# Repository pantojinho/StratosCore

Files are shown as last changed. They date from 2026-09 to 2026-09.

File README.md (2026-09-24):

# StratosCore

StratosCore is an open-source portable field, aviation, meteorological, navigation and radio computer based on the **ESP32-S3-WROOM-1-N16R8**.

## Current status

**Astra has assumed full technical leadership of Rev A (2026-09-24).** Astra owns engineering closure, candidate refinement, review and integration; Claude, Hermes, Sol and other AI agents execute bounded delegated tasks. See [Astra project control and agent handover](docs/ASTRA_PROJECT_CONTROL.md) for current responsibilities, received evidence and next actions. Final baseline implementation and manufacturing remain gated.

| Complete | In progress | Externally blocked |
| --- | --- | --- |
| Product baseline and licensing | Validate prepared three-line display support and GNSS passive RF proposals | Display controlled power/FPC drawing, C1 samples and connector confirmation |
| MAX-M10S decision and independently reviewed footprint geometry | Close complete 2S charger/protection/VBUS application | Qualified electrical/battery review and fault tests |
| Two removable 21700 cells in 2S decision | Accept exact cells/holder and state estimation; prove the 8 h primary-use target | RF performance and runtime measurements need prototypes |
| ESP32 compute sheet and GPIO allocation | Sensor CAD, LoRa/ADS-B RF, stackup and mechanical dummy | Final factory stack confirmation |
| Exact candidates for RP2040 support, microSD, audio, USB-C, expansion, buttons, rails and RF interconnects | Assembler approvals, mechanical fit, off-state review and application tests | Independent final schematic/layout and bring-up review |
| Manufacturer-derived dimensions for W25Q, TPD, ICM/MMC/BMP, ABM8, U.FL and DM3 electrical/mechanical envelope | RF return paths, enclosure access and prototype qualification | PCBA assembler stencil/mask confirmation |
| KiCad hierarchy; latest ERC: zero violations | Orderable BOM and manufacturing inputs | |
| ADS-B host models: 24 tests passing | UART/PIO/DMA implementation and sustained-link bench proof | |

The **reviewed baseline** (`hardware/`) has no finished schematic, PCB layout, prototype or manufacturing package yet. A complete **comparison candidate** (schematic + routed PCB + 3D with the display) now exists in [`candidates/claude-oneshot-revA/`](candidates/claude-oneshot-revA/README.md) — see [below](#claude-one-shot-candidate-schematic--pcb--3d). It is **not for manufacture** and does not close any gate. Do not order boards from the current repository. See [project status](docs/PROJECT_STATUS.md) for the complete gate list.

## Claude one-shot candidate (schematic + PCB + 3D)

Generated 2026-09-23 at the owner's request, for side-by-side comparison with the Astra pass. Status at a glance:

| Item | Status |
| --- | --- |
| Schematic | Complete: root + 11 sheets, every Rev A block; unverified values are literally `TBD` |
| PCB | 60 x 84 mm, 4 layers, 277 parts, routed; **11 connections left for manual finish** (2 LoRa RF stubs, SHT40 SDA/3V3, 1 decoupling cap, 6 GND pour fragments) |
| Checks (KiCad 10.0.6) | ERC 1 reviewed error; DRC 1 reviewed error (ESP32 antenna-clearance courtyard); schematic <-> PCB parity 0 |
| 3D | Board with display, 2S 21700 cells and holder; printed two-part enclosure concept |
| Blocking gates | O05 battery safety (qualified human review), display controlled drawing/samples, LoRa matching values, ADS-B threshold, assembler approvals |
| Findings for the baseline | 2 footprint blockers (MMC5983MA, BMP581 pad centres), 2 wrong packages (TXU0202, TPS259474L), connector orientation and GPIO gaps — see [ISSUES.md](candidates/claude-oneshot-revA/docs/ISSUES.md) |

| Front (display) | Back (2S 21700 cells) | Printed enclosure concept |
| --- | --- | --- |
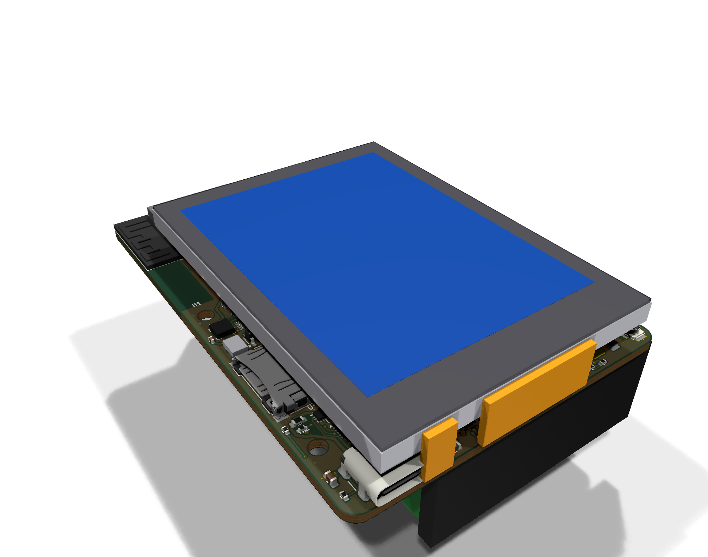
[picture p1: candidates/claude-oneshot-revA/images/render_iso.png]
3D front
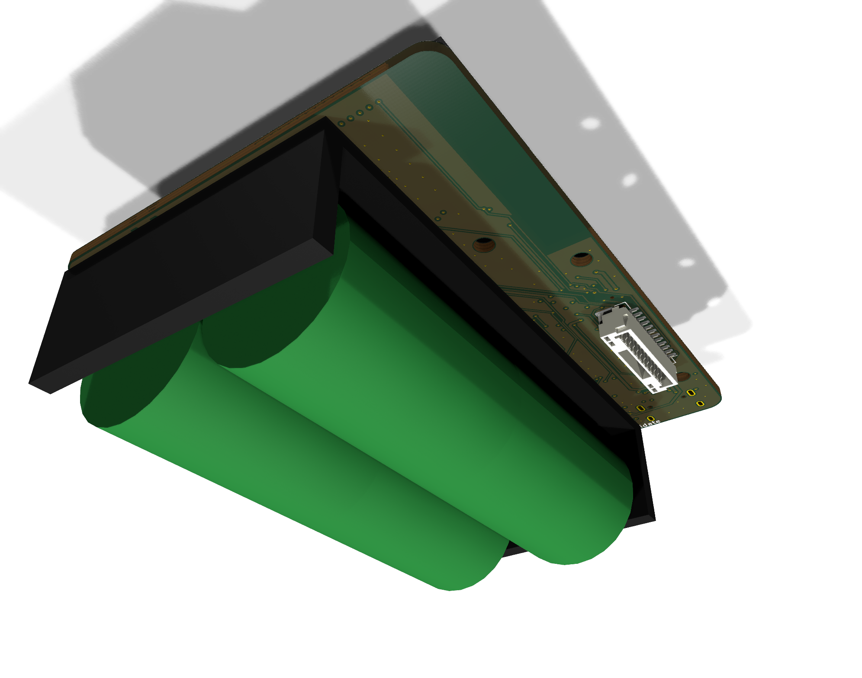
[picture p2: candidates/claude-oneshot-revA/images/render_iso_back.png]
3D back
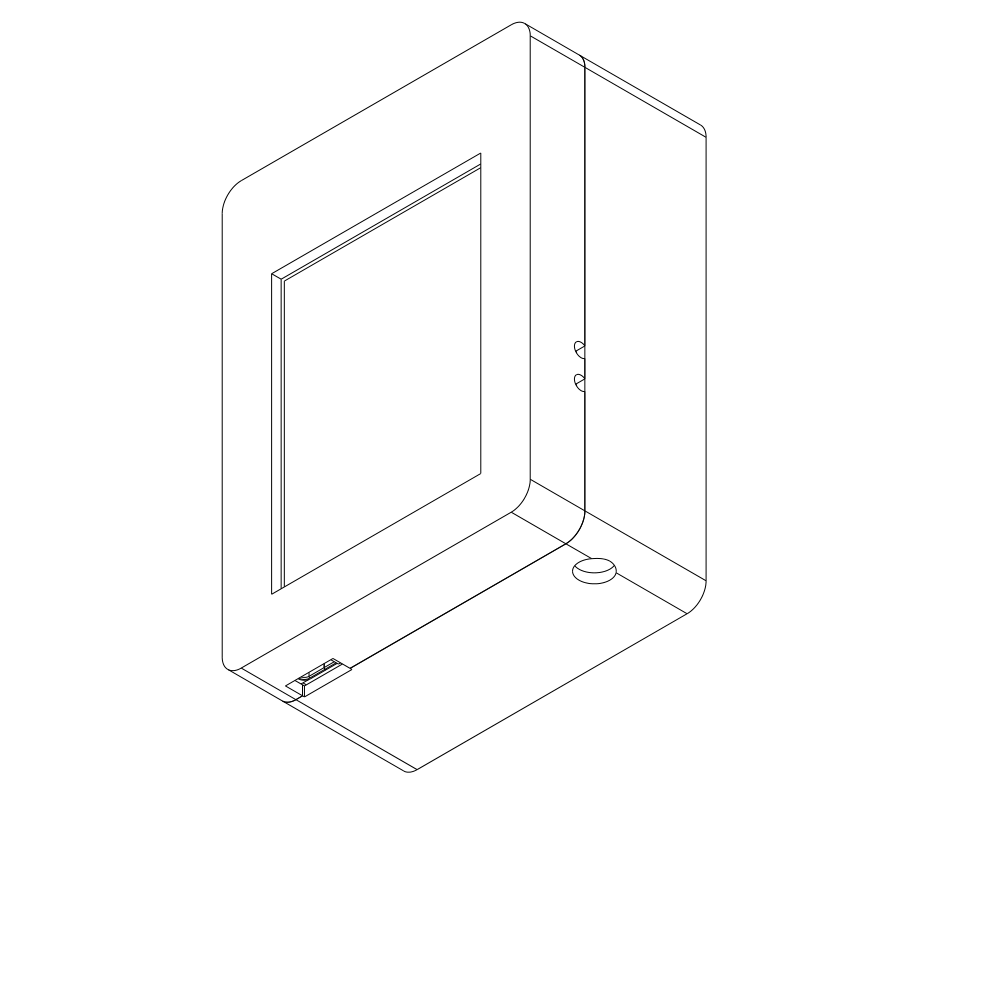
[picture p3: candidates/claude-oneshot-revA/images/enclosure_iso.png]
Enclosure
|  |  |  |

| PCB top (display removed) | PCB bottom | Copper (F/In2/B) |
| --- | --- | --- |
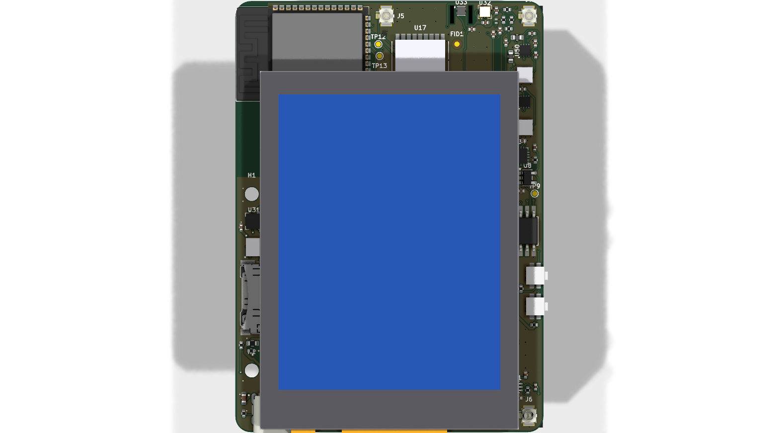
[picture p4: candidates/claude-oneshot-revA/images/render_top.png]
Top
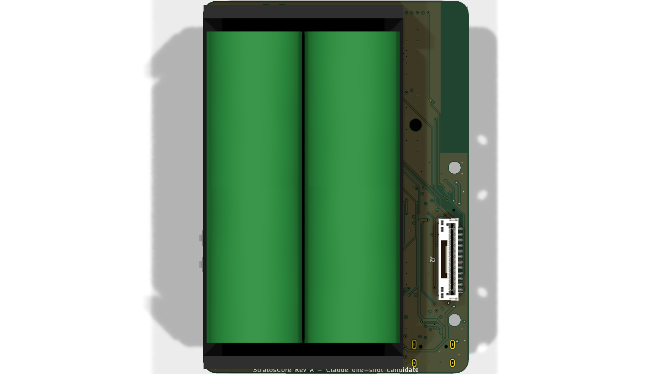
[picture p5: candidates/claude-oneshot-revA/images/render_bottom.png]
Bottom
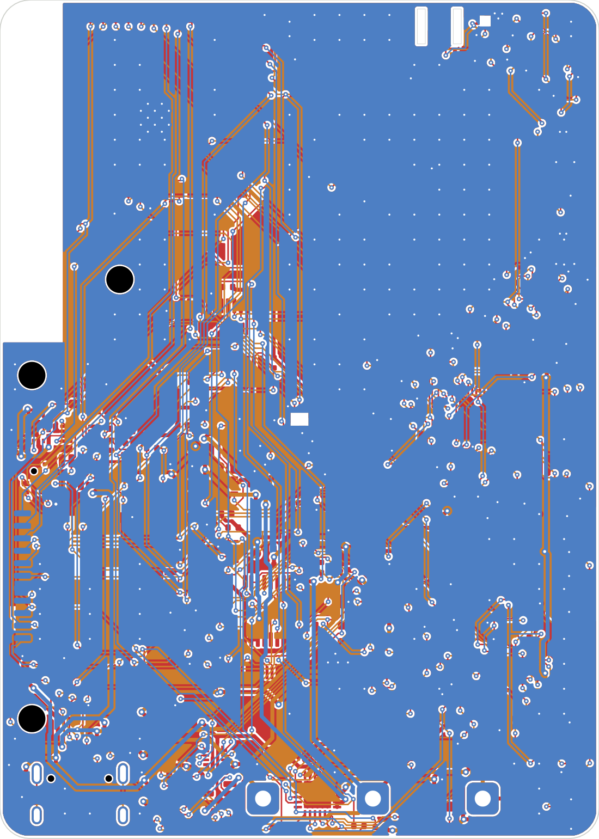
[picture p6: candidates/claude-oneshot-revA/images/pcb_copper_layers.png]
Copper
|  |  |  |

Schematic sheets (click to enlarge; full vector PDF: [schematic.pdf](candidates/claude-oneshot-revA/docs/schematic.pdf)):

| | | |
| --- | --- | --- |
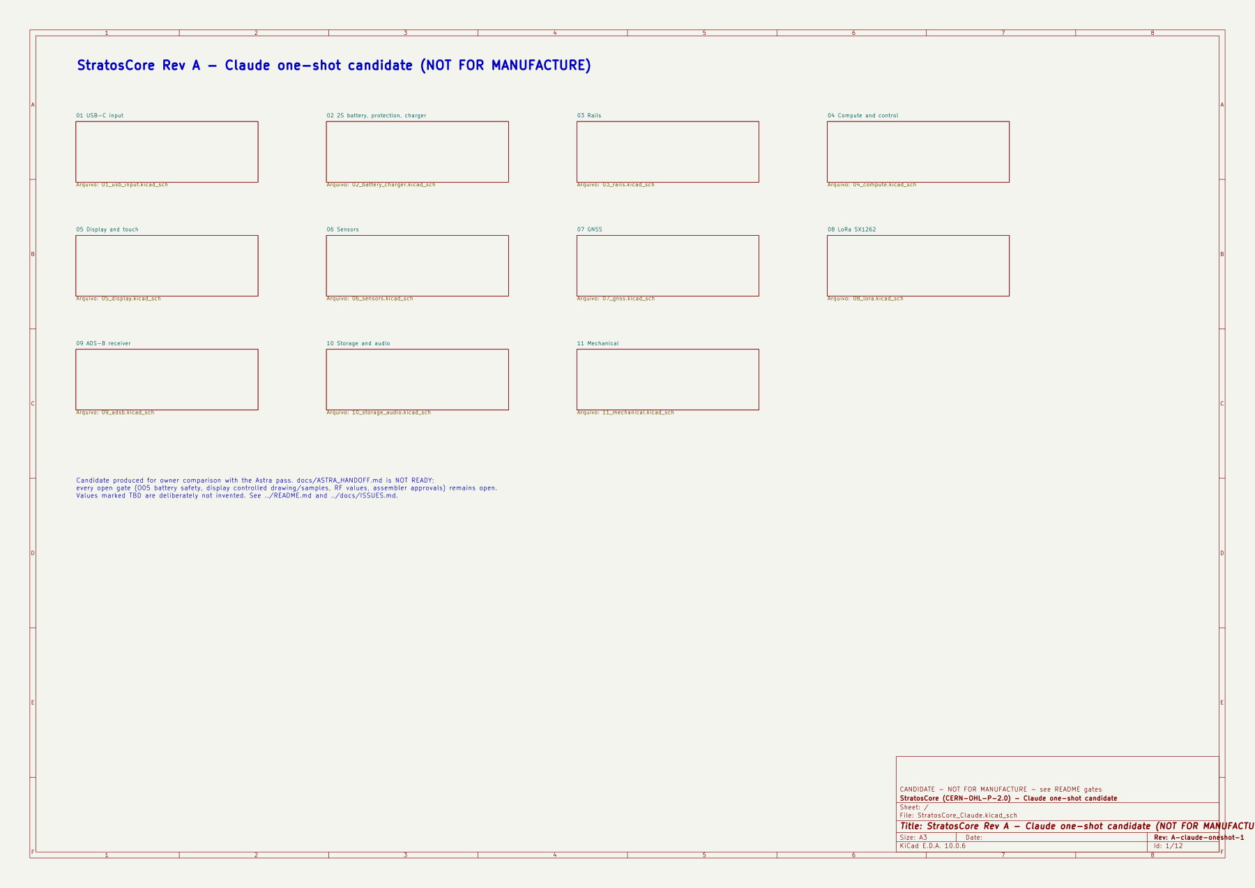
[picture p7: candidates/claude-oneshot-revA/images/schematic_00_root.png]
Root
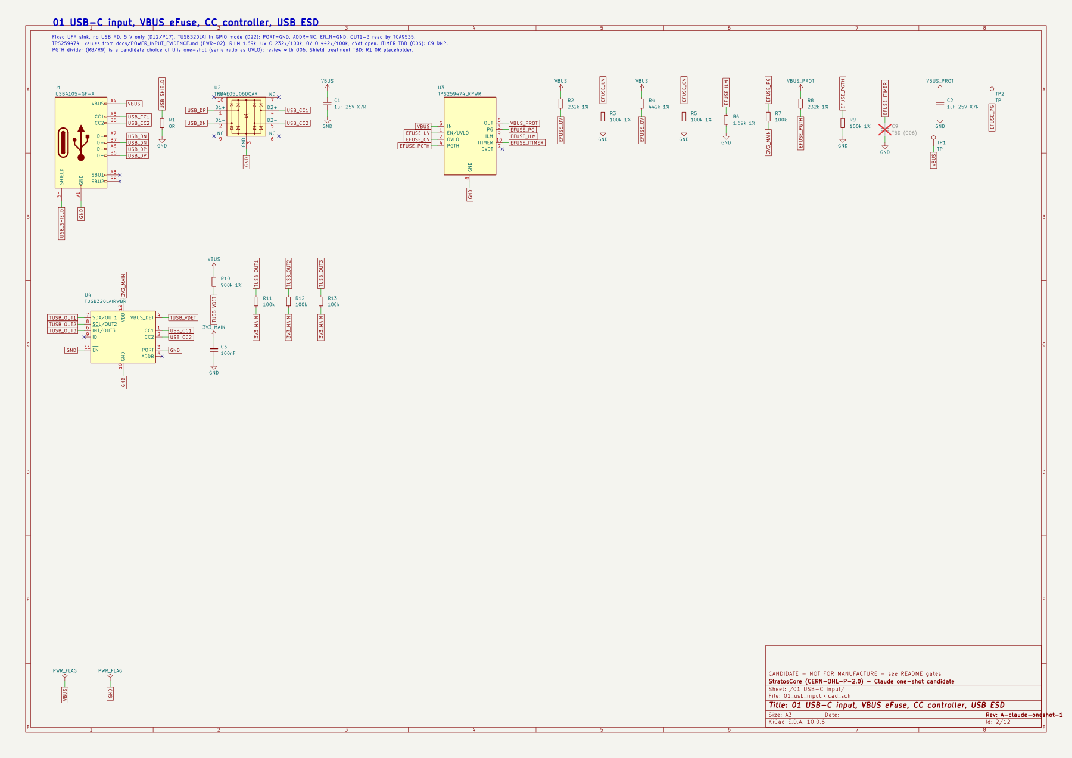
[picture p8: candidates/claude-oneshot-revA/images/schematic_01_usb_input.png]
USB-C
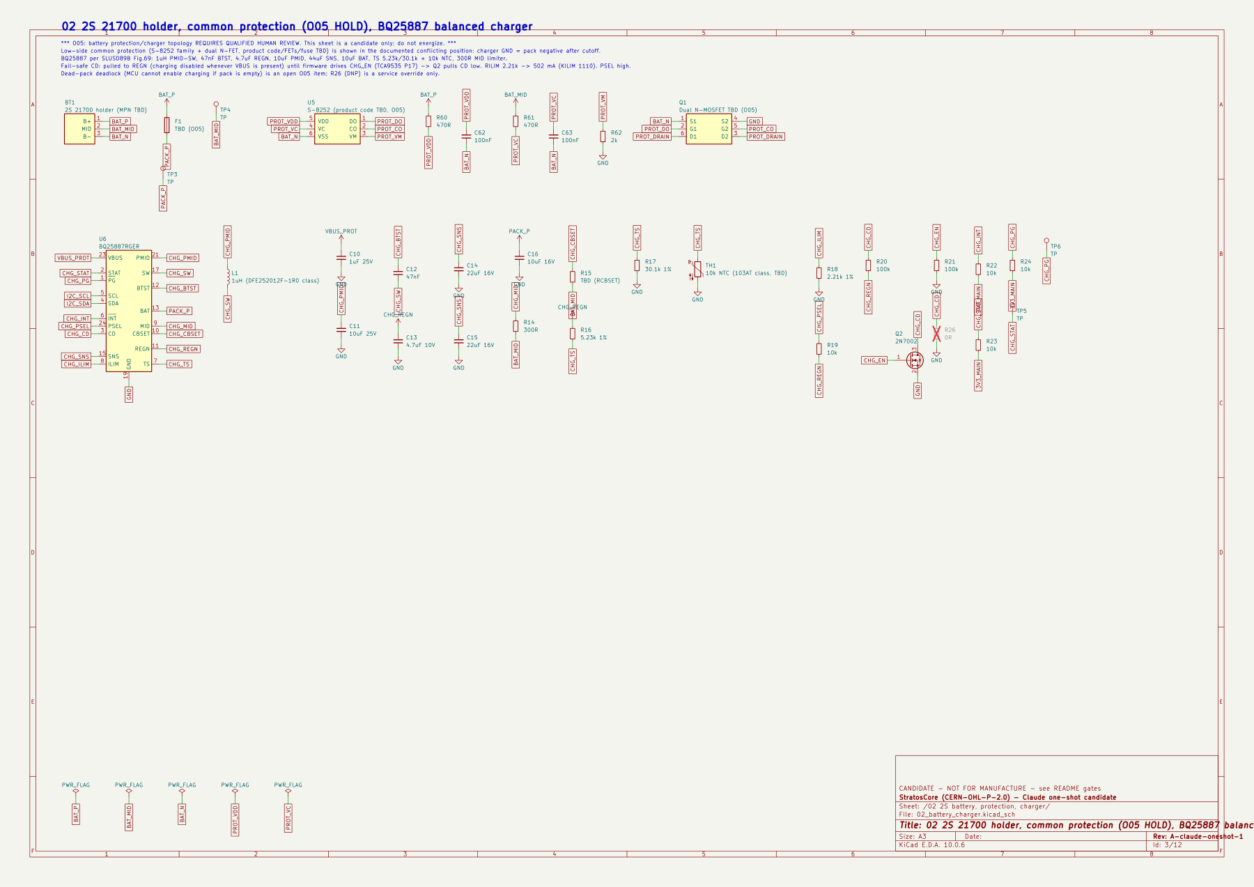
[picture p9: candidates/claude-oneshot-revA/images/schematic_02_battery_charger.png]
Battery
|  Root |  01 USB-C input |  02 2S battery/charger |
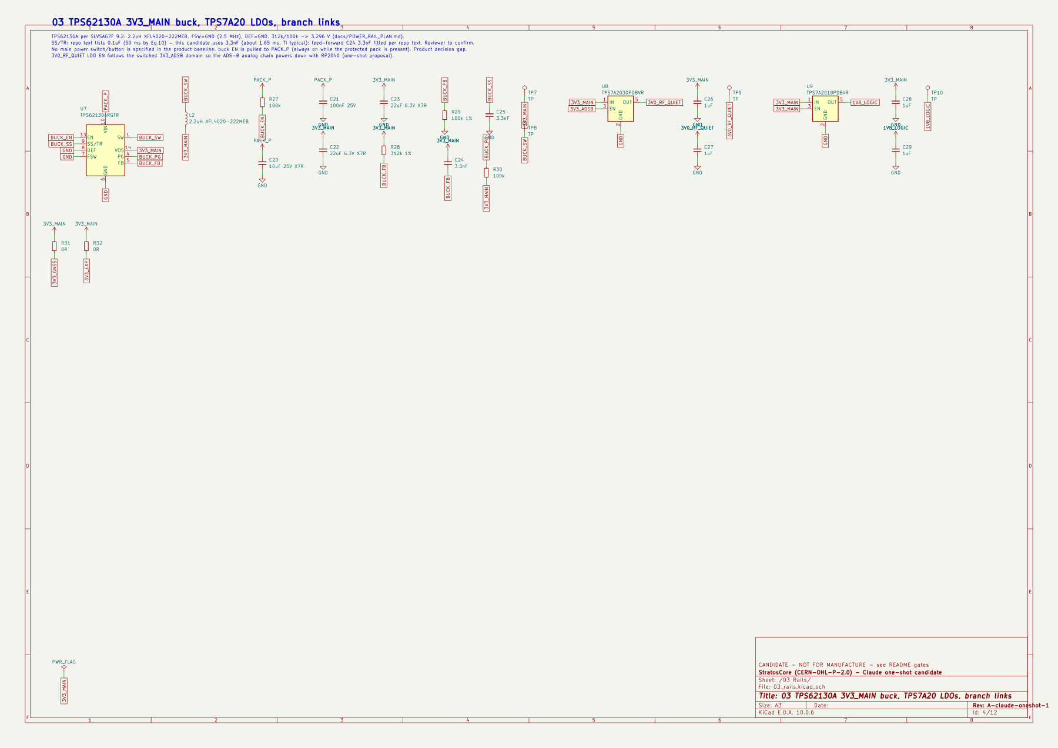
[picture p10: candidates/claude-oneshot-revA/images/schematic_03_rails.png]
Rails
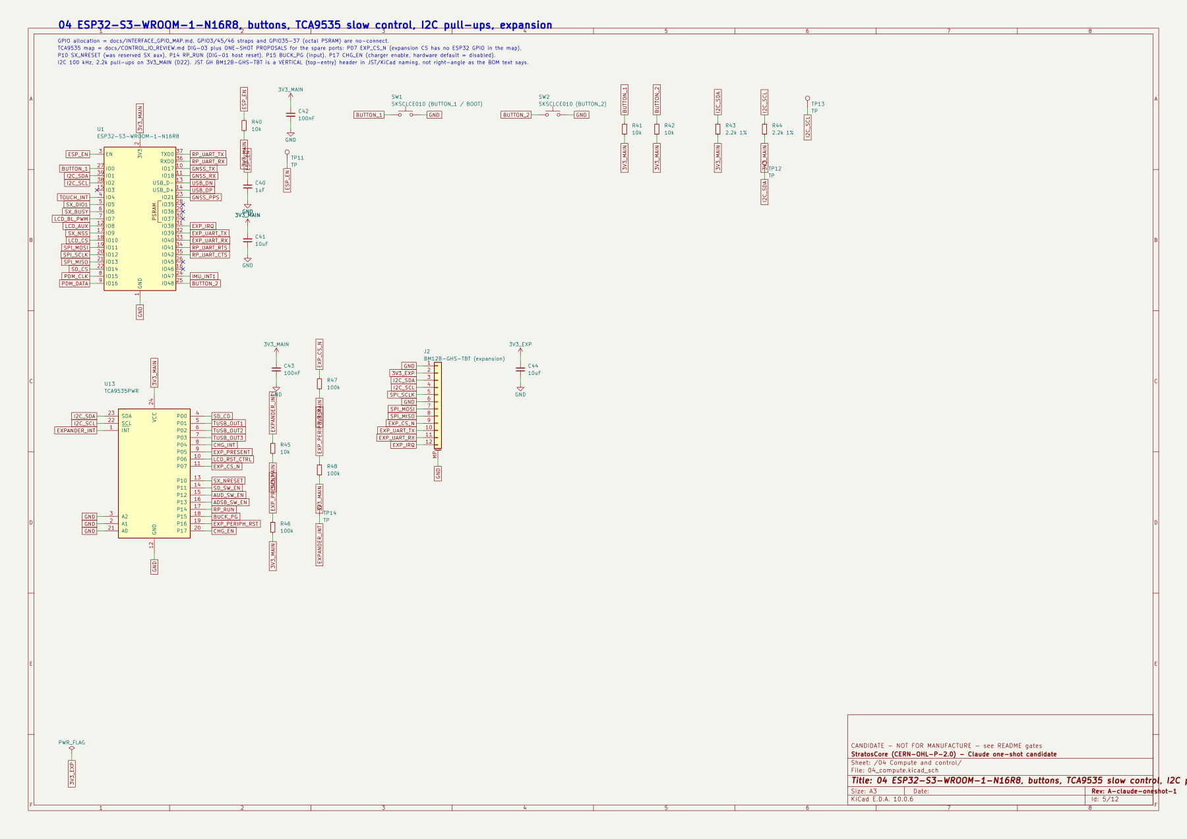
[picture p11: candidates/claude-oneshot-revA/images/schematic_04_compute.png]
Compute
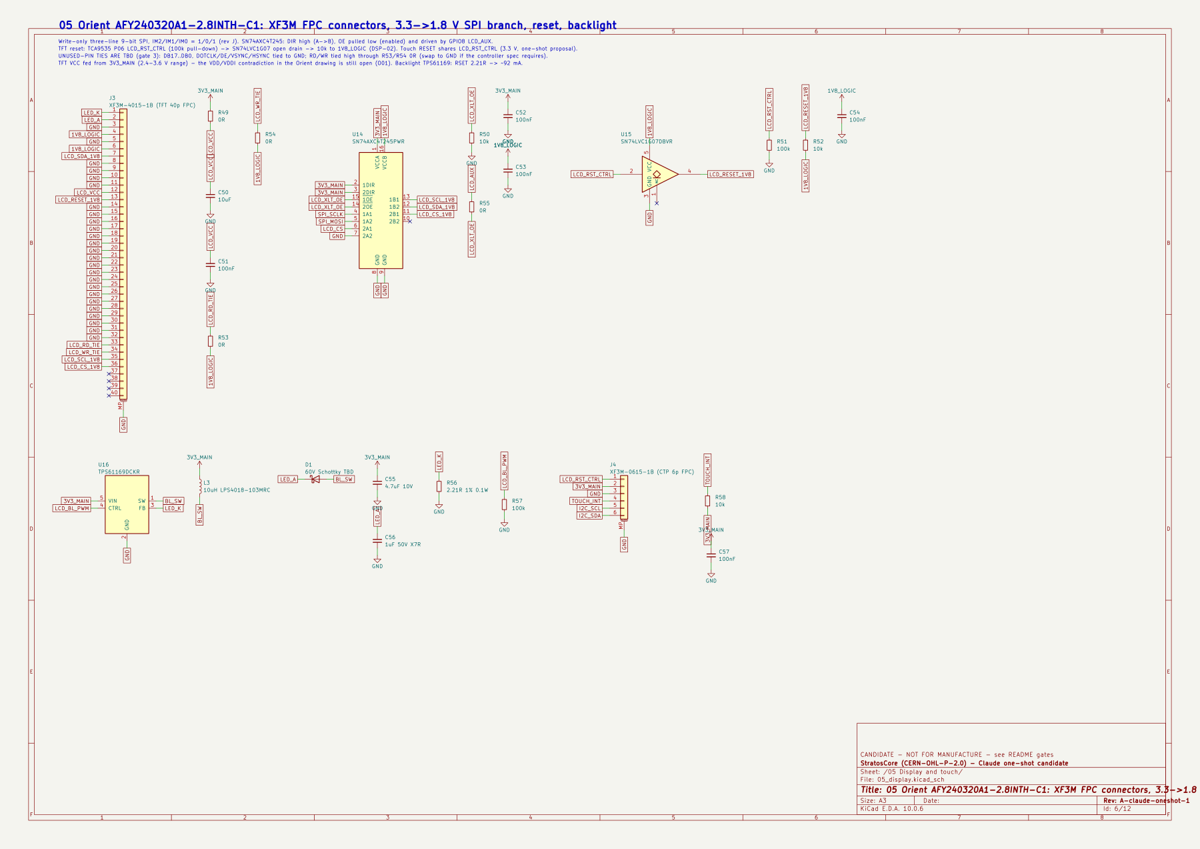
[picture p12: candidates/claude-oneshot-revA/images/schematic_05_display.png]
Display
|  03 Rails |  04 ESP32 / control |  05 Display / touch |
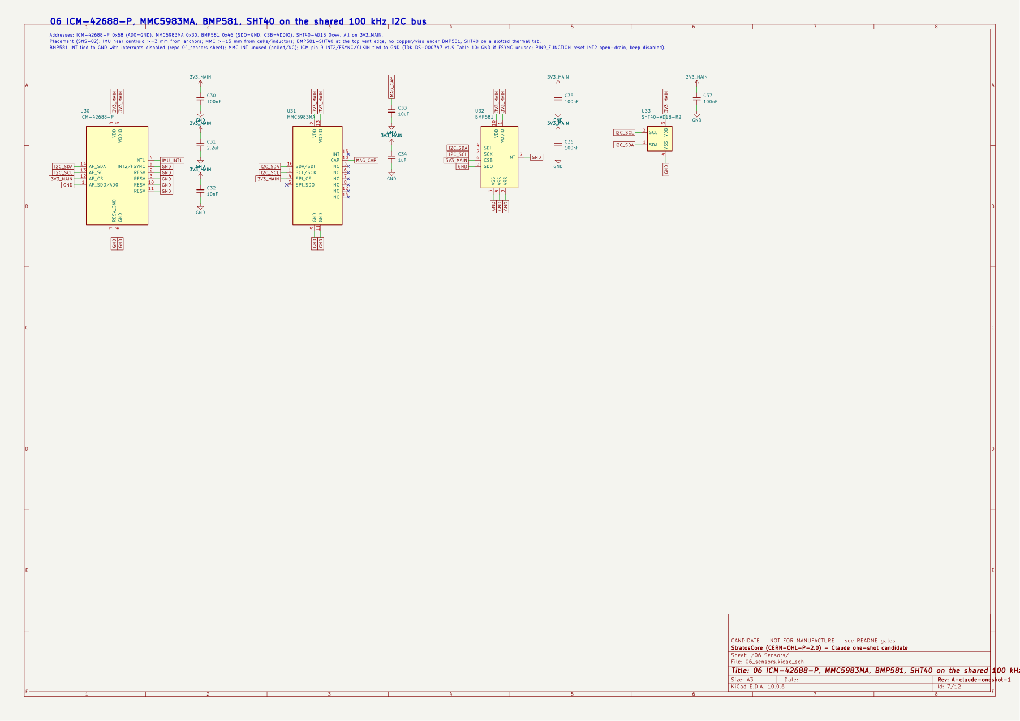
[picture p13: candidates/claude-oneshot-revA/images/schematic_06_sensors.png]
Sensors
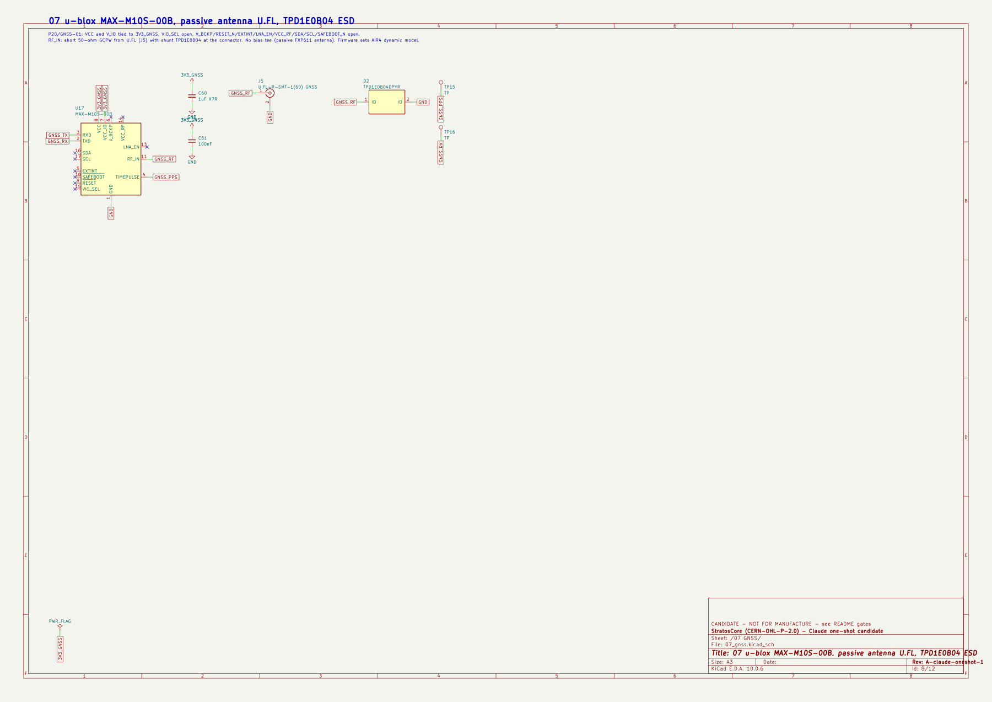
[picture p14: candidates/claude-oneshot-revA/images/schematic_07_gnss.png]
GNSS
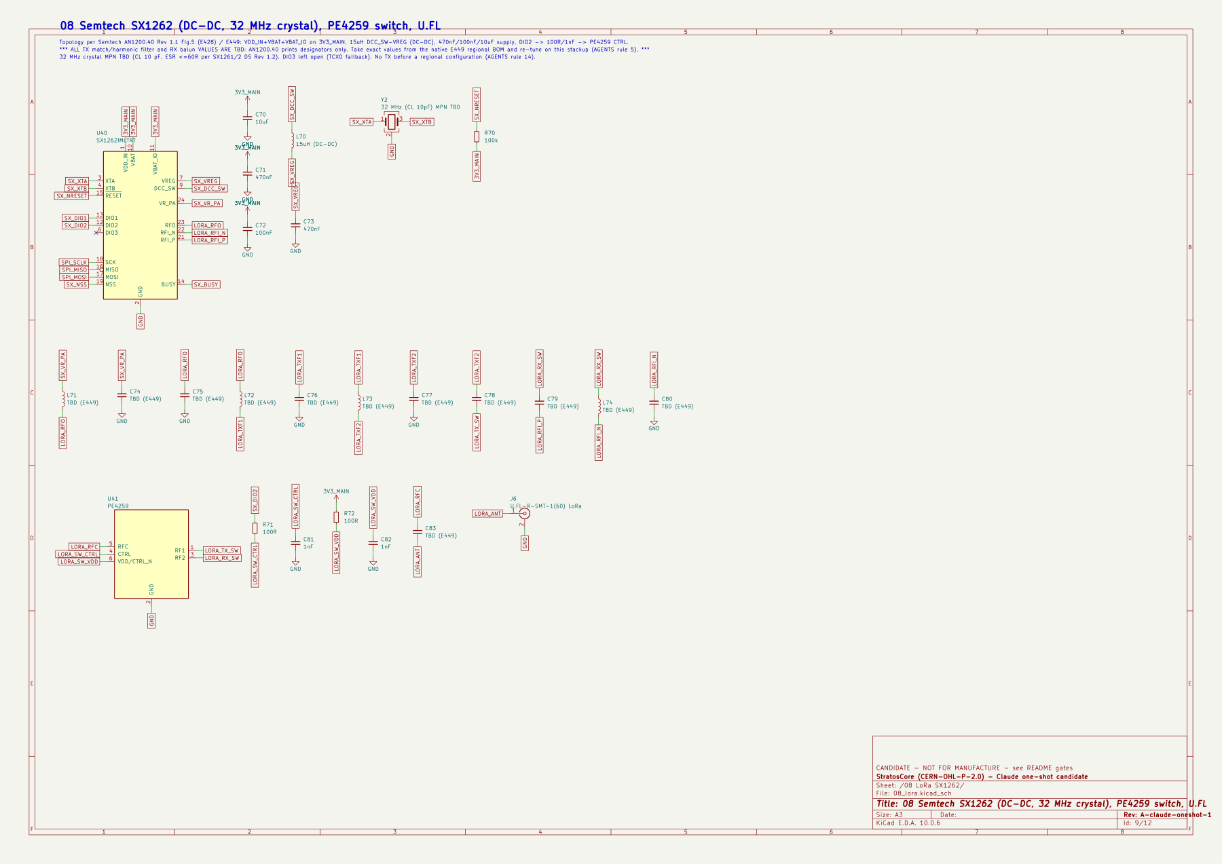
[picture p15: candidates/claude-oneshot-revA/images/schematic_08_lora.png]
LoRa
|  06 Sensors |  07 GNSS |  08 LoRa |
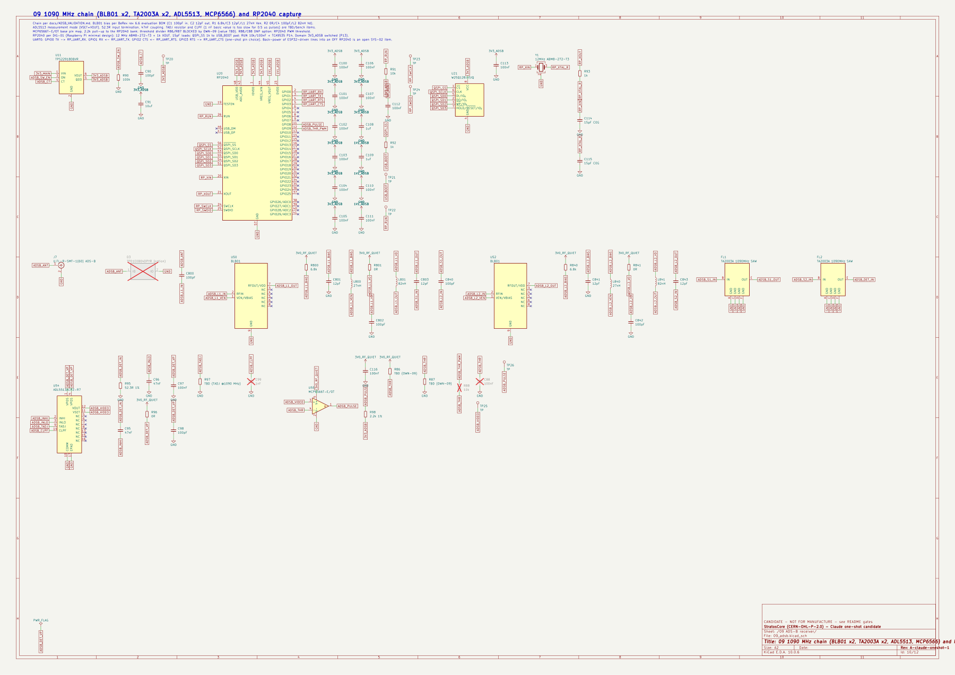
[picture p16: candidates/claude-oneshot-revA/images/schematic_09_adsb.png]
ADS-B
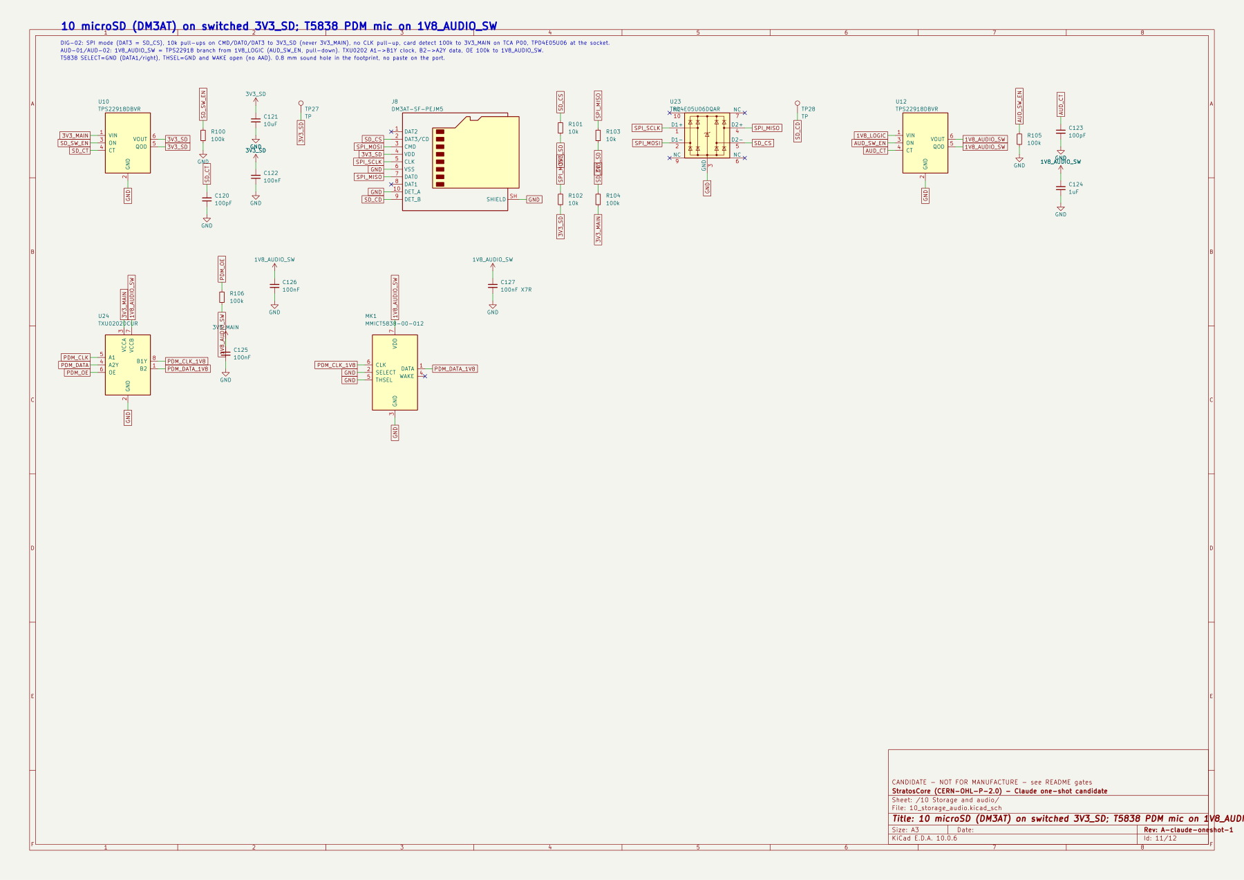
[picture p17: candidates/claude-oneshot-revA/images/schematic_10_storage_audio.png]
Storage
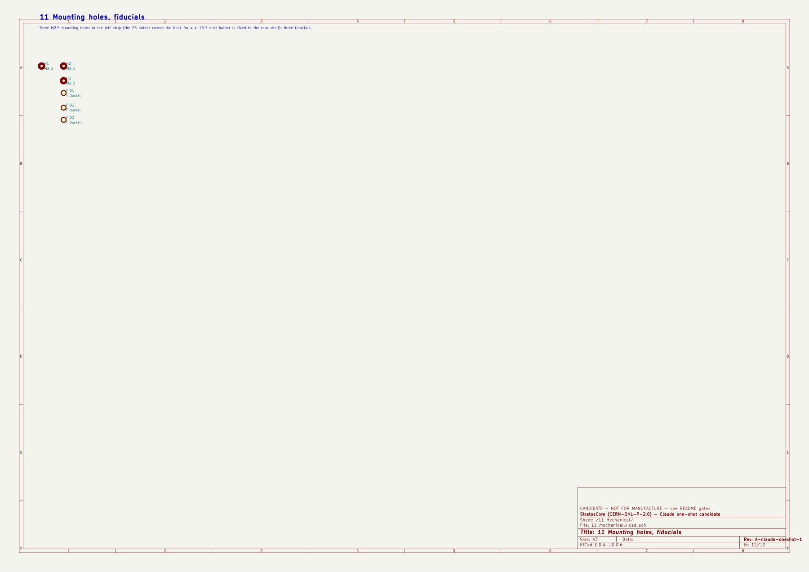
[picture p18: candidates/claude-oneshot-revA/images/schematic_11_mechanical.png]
Mech
|  09 ADS-B / RP2040 |  10 microSD / audio |  11 Mechanical |

### Open it in KiCad

1. Download the repository (GitHub **Code -> Download ZIP**, or `git clone`) and install **KiCad 10** (the project uses the KiCad 10 library variables).
2. Open [`candidates/claude-oneshot-revA/kicad/StratosCore_Claude.kicad_pro`](candidates/claude-oneshot-revA/kicad/). Project symbols, footprints and 3D models are local to that folder (`libs/`), so no library setup is needed.
3. Schematic: open the root sheet and double-click a sheet box. PCB: open the board and press **Alt+3** for the 3D viewer (the display and the cells appear in 3D).
4. STEP files for FreeCAD, Fusion or any other CAD are in [`candidates/claude-oneshot-revA/outputs/StratosCore_Claude_3D_STEP.zip`](candidates/claude-oneshot-revA/outputs/StratosCore_Claude_3D_STEP.zip): the board with its display and cells, the full assembly with the enclosure, and the two enclosure parts.

| Folder | What to open |
| --- | --- |
| `candidates/claude-oneshot-revA/kicad/` | KiCad project (`.kicad_pro`, root and sheet `.kicad_sch`, `.kicad_pcb`, local libraries) |
| `candidates/claude-oneshot-revA/docs/` | `schematic.pdf`, `ISSUES.md` (findings and open gates) |
| `candidates/claude-oneshot-revA/outputs/` | STEP zip, renders, layer PDF, BOM, DRC summary, netlist |
| `candidates/claude-oneshot-revA/mech/` | Enclosure STEP parts |
| `candidates/claude-oneshot-revA/images/` | The images above |
| `candidates/claude-oneshot-revA/tools/` | Scripts that regenerate everything |

The owner set a five-unit target of at most BRL 200 per assembled PCB **including display/touch**, excluding locally bought cells and enclosure, freight and taxes. This is a hobby prototype for desk, car and protected but unpressurized aircraft-cabin use, with experimental drone, model-aircraft, balloon, ultralight, hang-glider and paramotor applications to assess separately. About 10,000 ft is the realistic altitude case; 30,000 ft is exploratory, not a guaranteed barometric limit. The BMP581 remains an indicative backup sensor, and the 8 h minimum target on two 21700 cells remains. The five boards will be programmed and tested locally through USB-C. Cost, runtime and flight performance are not yet verified.

## Rev A baseline

| Block | Baseline |
| --- | --- |
| Compute | ESP32-S3-WROOM-1-N16R8; 16 MB Flash, 8 MB PSRAM; Wi-Fi/BLE and module PCB antenna |
| User interface | 2.8-inch IPS 320 x 240 with capacitive touch; portrait/landscape; two physical buttons |
| GNSS | u-blox MAX-M10S-00B, selected for documented airborne modes to 80 km |
| Motion/environment | ICM-42688-P, MMC5983MA, BMP581 and SHT40-AD1B-R2 |
| LoRa | SX1262 directly integrated, 915 MHz class hardware, SPI and PCB U.FL; regional TX configuration required |
| ADS-B | Independent 1090 MHz receive chain with RP2040 timing processor |
| Logging/audio | Mandatory microSD and provision for an optional digital MEMS microphone |
| Power | USB-C target; two removable matched 21700 cells in 2S; one balanced charger and common protection direction |
| Expansion | 3V3, GND, I2C, SPI with separate CS, UART and GPIO/IRQ |
| Construction | Four-layer PCB; 84 x 60 mm planning outline; approximately 88 x 64 x 37 mm printed enclosure starting envelope |

Potential uses include flight/vario instruments, traffic visualization, balloon experiments, weather stations, trackers, LoRa/MeshCore experiments and portable logging. This experimental platform is not a certified aviation instrument, collision-avoidance system or cockpit voice recorder.

## Start here

1. [Project status: completed work and remaining gates](docs/PROJECT_STATUS.md)
2. [Astra-led engineering workboard](docs/PRE_ASTRA_WORKBOARD.md)
3. [Multi-agent swarm protocol and master prompt](docs/SWARM_PROTOCOL.md)
4. [Engineering documentation index](docs/README.md)
5. [Locked decisions and accepted proposals](docs/DECISIONS.md)
6. [Open engineering questions](docs/OPEN_QUESTIONS.md)

[Astra final KiCad handoff](docs/ASTRA_HANDOFF.md) is intentionally marked **NOT READY**. It is not the current work queue.

## Repository layout

```text
StratosCore/
|-- AGENTS.md          Engineering and review rules
|-- README.md          Public project status and entry points
|-- docs/              Status, decisions and subsystem specifications
|-- bom/               Preliminary planning BOM; not orderable yet
|-- hardware/          KiCad project and primary-source index
|-- candidates/        Out-of-baseline design candidates (Claude one-shot: schematic, PCB, 3D)
|-- mechanical/        Enclosure and fit-study workspace
|-- manufacturing/     Release and production-test placeholders
|-- firmware/          Hardware-interface fixtures and future firmware
|-- references/        Read-only research and reuse/license records
`-- LICENSES/          Official license texts and scope
```

## Manufacturing path

The target is four-layer PCB fabrication and automated assembly at JLCPCB or a comparable Chinese PCBA supplier. Release requires an independently reviewed schematic and layout, clean ERC/DRC, confirmed stackup, exact orderable BOM, CPL, Gerbers/drill files, assembly drawings and a programming/production-test procedure. The owner must explicitly accept the manufacturing release before ordering.

## Licensing

Original hardware, mechanical designs and hardware engineering documentation use **CERN-OHL-P-2.0**. Original firmware and its software documentation use **MIT**. See [license scope and provenance](LICENSES/README.md). Third-party work retains its own terms.

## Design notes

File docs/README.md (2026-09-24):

# Engineering documentation index

Start with [project status](PROJECT_STATUS.md). It is the concise source for what is complete, what remains and who owns each next action. [Astra project control](ASTRA_PROJECT_CONTROL.md) records Astra's active leadership, delegated agent roles and the received handover. [Decisions](DECISIONS.md) is the change-controlled baseline. [Astra handoff](ASTRA_HANDOFF.md) is reserved for final frozen-baseline KiCad execution and must not be executed while it says **NOT READY**.

Latest independent evidence: [Astra's September 24 agent review](ASTRA_AGENT_REVIEW_2026_09_24.md), including fresh ERC/DRC and corrections to unsupported handover claims.

## Control and current status

| Document | Purpose |
| --- | --- |
| [Footprint corrections](FOOTPRINT_CORRECTIONS_2026_09_23.md) | Corrected sensor/DCU geometry, rejected local drafts and reproducible clearance checks |
| [Claude candidate independent review](CLAUDE_CANDIDATE_INDEPENDENT_REVIEW.md) | Fresh KiCad triage, original findings and correction context |
| [Astra candidate refinement prompt](ASTRA_CANDIDATE_REFINEMENT_PROMPT.md) | Guide Astra's ongoing Claude PCB candidate refinement; fix evidenced issues and return unresolved engineering gates |
| [Project status](PROJECT_STATUS.md) | Current phase, completed work, remaining gates and ordered next work |
| [Astra-led engineering workboard](PRE_ASTRA_WORKBOARD.md) | Task IDs, dependencies, owners, parallel waves and objective closure evidence |
| [Swarm protocol](SWARM_PROTOCOL.md) | Multi-agent branches, file ownership, status, review, integration and master prompt |
| [Decision register](DECISIONS.md) | Locked requirements, accepted/rejected proposals and owner decisions |
| [Open questions](OPEN_QUESTIONS.md) | Closure evidence for every unresolved engineering item |
| [Historical 30,000 ft barometer comparison](BAROMETER_30K_PROPOSAL.md) | Rejected P27 replacement and dated alternative comparison; BMP581 remains locked |
| [BMP581 validation plan](BMP581_VALIDATION_PLAN.md) | Indicative pressure/vario data contract and pre-/post-PCBA test boundary |
| [BOM baseline gap audit](BOM_BASELINE_GAP_AUDIT.md) | Exact MPN, quantity, footprint, fit/DNP and sourcing gaps before Astra |
| [Product requirements](PRODUCT_REQUIREMENTS.md) | Verifiable Rev A behavior and operating profiles |
| [Astra final handoff](ASTRA_HANDOFF.md) | Final KiCad execution checklist; currently gated |
| [Astra execution prompt](ASTRA_EXECUTION_PROMPT.md) | Frozen-manifest template and final KiCad execution prompt; currently NOT READY |
| [CAD tooling review](CAD_TOOLING_REVIEW.md) | Optional Hermes/KiCad automation, verification limits and reproducibility |
| [Validation record](FOUNDATION_CHECKS.md) | Checks already run and their limited meaning |
| [Readiness audit log](AUDIT_LOG.md) | Audit-loop baseline, rounds, active blockers and the vigil procedure |

## System and interfaces

| Document | Purpose |
| --- | --- |
| [System architecture](SYSTEM_ARCHITECTURE.md) | MCU ownership, buses, timing, storage and power domains |
| [Block diagram](BLOCK_DIAGRAM.md) | Visual functional interconnect |
| [GPIO and interface map](INTERFACE_GPIO_MAP.md) | ESP32 allocation, I2C addresses and shared-SPI contract |
| [Electrical compatibility matrix](ELECTRICAL_COMPATIBILITY_MATRIX.md) | Rail, voltage, address, boot-state and back-power closure map |
| [I2C bus budget](I2C_BUS_BUDGET.md) | Shared-bus capacitance, pull-up window and per-device transcription worksheet |
| [Concurrency contract](CONCURRENCY_CONTRACT.md) | Shared SPI, UART, PDM and interrupt resource arithmetic and remaining timing gates |
| [Audio-domain review](AUDIO_DOMAIN_REVIEW.md) | Preferred separate switched-audio rail and exact application work still needed |
| [Power input evidence](POWER_INPUT_EVIDENCE.md) | USB eFuse and 2S charger datasheet facts feeding O05/O06 |
| [Expansion interface](EXPANSION_INTERFACE.md) | External I2C/SPI/UART/GPIO requirements |

## Hardware subsystems

| Area | Primary documents |
| --- | --- |
| Components and sourcing | [Component evidence](COMPONENT_EVIDENCE.md), [datasheet index](../hardware/datasheets/README.md), [preliminary BOM](../bom/preliminary_bom.csv) |
| Digital support | [RP2040 flash/clock and microSD review](DIGITAL_SUPPORT_REVIEW.md), [digital footprint review](FOOTPRINT_REVIEWS_DIGITAL.md), [buttons and slow-control I/O](CONTROL_IO_REVIEW.md) |
| Display | [Display requirements](DISPLAY_REQUIREMENTS.md) |
| GNSS | [GNSS architecture](GNSS_ARCHITECTURE.md) |
| Sensors and GNSS CAD | [Sensor architecture](SENSOR_ARCHITECTURE.md), [sensor/GNSS/RF footprint review](FOOTPRINT_REVIEWS_SENSORS_GNSS.md) |
| Audio | [Digital microphone architecture](AUDIO_ARCHITECTURE.md) |
| Power and wired connectors | [Accepted options](POWER_ARCHITECTURE_OPTIONS.md), [2S review](POWER_ARCHITECTURE_REVIEW.md), [rail plan](POWER_RAIL_PLAN.md), [USB-C/expansion connectors](CONNECTOR_ARCHITECTURE.md), [power budget](POWER_BUDGET.md) |
| RF | [RF architecture](RF_ARCHITECTURE.md), [RF connector selection](RF_CONNECTOR_SELECTION.md), [ADS-B architecture](ADSB_ARCHITECTURE.md), [ADS-B validation](ADSB_VALIDATION.md) |
| PCB and mechanics | [Stackup](PCB_STACKUP.md), [mechanical requirements](MECHANICAL_REQUIREMENTS.md), [mechanical/RF floorplan](MECHANICAL_RF_FLOORPLAN.md) |

## Production

| Document | Purpose |
| --- | --- |
| [Manufacturing strategy](MANUFACTURING_STRATEGY.md) | Chinese PCBA target, sourcing rules and release gates |
| [Production-test plan](../manufacturing/test/README.md) | Qualification and factory screening plan |
| [KiCad workspace](../hardware/kicad/README.md) | Current hierarchy, holds and ERC command |
| [Reuse register](../references/REUSE_REGISTER.md) | Source, license and modification tracking |

The documents are separated by engineering responsibility so evidence is reviewable without turning the root README into a design specification. Do not duplicate changing pinouts, thresholds or part status in several summaries; link to the subsystem source and update [project status](PROJECT_STATUS.md).

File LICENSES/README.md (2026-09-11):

# License scope and provenance

Copyright (c) 2026 StratosCore contributors, for their original contributions. Each contributor retains ownership of their work.

| Material | License |
| --- | --- |
| Original hardware, mechanical designs, hardware BOM and manufacturing/engineering documents, including `docs/` | [CERN-OHL-P-2.0](CERN-OHL-P-2.0.txt) |
| Original firmware, bring-up software and software documentation under `firmware/` | [MIT](MIT.txt) |
| Original repository guidance and research notes (`README.md`, `AGENTS.md`, `references/`, configuration files) | MIT, except quoted/external material under its own terms |
| External datasheets, code, CAD, artwork or reused circuits | Their own documented licenses; never overridden by this table |

Hardware source location: [StratosCore repository](https://github.com/pantojinho/StratosCore). The current KiCad files contain architecture partitions only, and the current Python code is a host-side ADS-B timing fixture rather than target firmware. New source files should carry the relevant SPDX identifier and applicable contributor/third-party notices.

## Official text retrieval

Retrieved 2026-09-11 UTC:

- CERN-OHL-P-2.0 text downloaded unchanged from the [official OHWR-hosted CERN text](https://gitlab.com/ohwr/project/cernohl/-/wikis/uploads/3eff4154d05e7a0459f3ddbf0674cae4/cern_ohl_p_v2.txt), linked through [CERN's license site](https://cern-ohl.web.cern.ch/). SHA-256 of included file: `6e471d647db50527d0c75ee5f1a55a74012ab177c73282bef0bdc7f6562b7ded`.
- MIT text retrieved from [SPDX license-list-data](https://raw.githubusercontent.com/spdx/license-list-data/main/text/MIT.txt), checked against the [Open Source Initiative MIT text](https://opensource.org/license/mit). Only the year and copyright-holder placeholders were replaced with `2026` and `StratosCore contributors`. SHA-256 of included file: `8555f6ab52774220736620fbbb887768b7720de2048a4706d8619f41dadfaa8d`.

No license prose was invented or combined into a new license. This scope document explains project organization; it does not modify the official texts. See [reuse register](../references/REUSE_REGISTER.md) for unapproved/conditional reuse, notably ADSBee GPL and avBadge hardware.

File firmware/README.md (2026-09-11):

# Firmware foundation

Original firmware will use MIT. No code has been imported and no build/toolchain is configured. ESP-IDF/FreeRTOS is a proposal; MeshCore port and dependency compatibility require review before selection.

- [ESP32 responsibilities](esp32/README.md)
- [RP2040 ADS-B responsibilities](rp2040_adsb/README.md)
- [Bring-up sequence](bringup/README.md)

Keep drivers, board configuration, time/data model and services separate. Do not copy legacy pins. Use bounded queues, validity/age, explicit errors and independent watchdog recovery. Avoid embedding regional RF assumptions in universal defaults.

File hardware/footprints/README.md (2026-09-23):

# Project footprint candidates

These KiCad footprint files are review candidates, not a manufacturing release.

Each file must have an exact ordering code, controlling manufacturer drawing, recorded source lineage and independent pad-by-pad review before it is used in the final PCB. See [digital/storage reviews](../../docs/FOOTPRINT_REVIEWS_DIGITAL.md) and [sensor/GNSS/RF reviews](../../docs/FOOTPRINT_REVIEWS_SENSORS_GNSS.md).

The MAX-M10S-00B, ICM-42688-P, W25Q128JVSIQ and TPD1E0B04DPYR candidates retain their dated dimensional reviews. MMC5983MA and BMP581 were corrected on 2026-09-23 after real land-spacing defects invalidated the earlier review claims; see [corrections and rejected drafts](../../docs/FOOTPRINT_CORRECTIONS_2026_09_23.md). The corrected U.FL-R-SMT-1(60) copper/paste/board-cut-out rule and Abracon ABM8-272-T3 land geometry also completed independent dimensional reviews. Every mask/paste strategy remains subject to its recorded assembler gate. The BMP581 also carries Bosch's full no-mask opening and a conservative central no-trace/no-via rule area; final layout review must keep unnecessary routing out from under the complete body.

**2026-09-22 (DIG-04):** eight support-part candidates added from the official KiCad 10 standard library (SOT-23-5/-6, SC-70-5, VSSOP-8, TSSOP-24, X2QFN-12, VQFN-HR-10, VQFN-16 EP) covering TPS7A20, TPS22918, TPS61169, TXU0202, TCA9535, TUSB320LAI, TPS259474L and TPS62130A. All 17 project footprints parse and export in KiCad 10.0.6. Provenance and the remaining exact-MPN comparison gate are recorded in [FOOTPRINT_REVIEWS_DIGITAL.md](../../docs/FOOTPRINT_REVIEWS_DIGITAL.md). USB4105, BM12B, SKSCLCE010, ST1633I connector and T5838 acoustic land remain footprint-open with their controlling documents recorded.

**2026-09-23:** use the new exact-DCU TXU0202 candidate only after its recorded review/process gates. The old DGS TXU0202 and RPU TPS259474L files are rejected for those MPNs. Do not integrate the uncommitted 6.4 mm-body TCA9535, swapped-axis DCU or straight-pad RPW drafts; the linked correction note explains each error. Run [the critical-land check](../validation/check_critical_lands.py) to verify source coordinates and detect pairwise copper overlap.

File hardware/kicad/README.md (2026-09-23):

# KiCad engineering workspace

`StratosCore.kicad_sch` is the top-level architecture sheet. Its eight child sheets partition reviewed work and keep unresolved gates visible. `01_compute.kicad_sch` contains the reviewed ESP32-S3-WROOM-1-N16R8 entry, EN pull-up/reset capacitor, local 3V3 decoupling and the global nets defined in `INTERFACE_GPIO_MAP.md`. `04_sensors.kicad_sch` contains a reviewed subset: MMC5983MA and BMP581 pin maps use clearly marked logical carriers with no assigned footprints, while SHT40-AD1B-R2 uses the exact KiCad symbol and manufacturer-derived footprint. Manufacturer-derived sensor candidates exist outside the project library. The MMC5983MA/BMP581 spacing errors invalidated their historical dimensional-pass claims and were corrected on 2026-09-23; see [correction evidence](../../docs/FOOTPRINT_CORRECTIONS_2026_09_23.md). Assembler mask/paste and final layout reviews remain. Other sheets still contain architecture notes rather than finished circuits. Add symbols and connections only when exact manufacturer documents and accepted decisions support them.

Current holds:

- display connector/footprint: P21 support candidates are documented; controlled Orient drawing/SPI evidence, independent CAD, samples and translated-interface/backlight tests remain;
- GNSS: MAX-M10S-00B accepted and P20 provides a preferred passive application; a manufacturer-derived footprint candidate now includes the u-blox T-paste recommendation, while independent CAD/assembler review, RF/PDN review, fit, calculated RF path and tests remain;
- power: owner accepted two removable 21700 cells in 2S with one balanced charger; regulator candidates are documented, while qualified battery/electrical review, exact holder, common protection, VBUS/power path and complete application remain;
- ICM-42688-P physical CAD: dimensional second pass complete; obtain assembler mask/paste approval and verify the under-body no-copper rule in final layout;
- MMC5983MA/BMP581 physical CAD: corrected land centers and source pin maps checked; independent review of the revised candidates remains open; obtain assembler mask/paste approval and final magnetic/pressure-port/full under-body routing review before assignment;
- ADS-B: S-parameter simulation and conducted prototype measurements.

Use KiCad 10 for new edits. Run ERC from the repository root after every schematic change:

```powershell
& 'C:\Program Files\KiCad\10.0\bin\kicad-cli.exe' sch erc --exit-code-violations --output hardware\kicad\reports\erc-architecture.rpt hardware\kicad\StratosCore.kicad_sch
```

KiCad 10.0.6 reported zero errors and zero warnings on 2026-09-11 for the hierarchy, compute sheet and reviewed sensor subset. The two project-stage changes from the standard ERC profile are `isolated_pin_label` and `single_global_label`: both remain temporarily ignored because several architecture nets still have one endpoint. Restore both diagnostics to `warning` as peer sheets gain their matching endpoints; the standard KiCad ignores remain listed in the report. The result proves connectivity consistency within the present scope; it does not qualify the circuits that remain gated. Retain reviewed reports under `hardware/kicad/reports/`. No baseline PCB exists yet; the separate Claude comparison candidate is described in the project status. Current preparation should leave Astra an evidence-complete execution list so its work is concentrated on KiCad entry, placement/routing and ERC/DRC rather than component research.

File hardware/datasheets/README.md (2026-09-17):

# Primary technical source index

Research last updated: 2026-09-17. This folder contains an index only, not redistributed manufacturer PDFs. Product pages identify primary resources but do not replace a verified exact-part pinout/package drawing before CAD. Recheck revisions at design freeze.

| Part or preferred candidate | Primary source / reviewed evidence | Remaining verification |
| --- | --- | --- |
| ESP32-S3-WROOM-1-N16R8 | [Espressif module datasheet](https://documentation.espressif.com/esp32-s3-wroom-1_wroom-1u_datasheet_en.html), v1.8 page | Exact module drawing, antenna keepout, N16R8 memory/GPIO restrictions |
| SX1262 | [Semtech device and reference library](https://www.semtech.com/products/wireless-rf/lora-connect/sx1262) | Download/review current full datasheet and selected 915 MHz RF reference revision before schematic |
| ATGM332D-5NR32 | [Full user manual](https://datasheet.lcsc.com/lcsc/2206231830_ZHONGKEWEI-ATGM332D-5NR32_C3037611.pdf), 18 pages | Historical comparison; 18 km altitude limit caused the accepted MAX-M10S replacement |
| ICM-42688-P | [TDK DS-000347 v1.9](https://d17t6iyxenbwp1.cloudfront.net/s3fs-public/2026-06/DS-000347%20ICM-42688-P%20v1.9.pdf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) and [AN-000393 v2.4](https://d17t6iyxenbwp1.cloudfront.net/s3fs-public/2026-06/AN-000393%20TDK%20InvenSense%20IMU%20PCB%20Design%20and%20MEMS%20Assembly%20Guidelines%20v2.4.pdf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) | Current pin table, application circuit, package and LGA land/mask/stencil guidance reviewed; manufacturer-derived candidate passed an independent dimensional second pass; obtain assembler mask/paste approval, complete final layout review and recheck supply risk |
| MMC5983MA | [MEMSIC Rev A, formal release 2019-04-03](https://www.memsic.com/Public/Uploads/uploadfile/files/20220119/MMC5983MADatasheetRevA.pdf), page 20 visually reviewed 2026-09-15 | I2C/supply/package and manufacturer-land footprint reviewed; parse/audit/independent dimensional pass complete; assembler process, SET/RESET, placement and calibrated-heading checks remain |
| BMP581 | [Bosch BST-BMP581-DS004-13 Rev 1.13, April 2025](https://www.bosch-sensortec.com/media/boschsensortec/downloads/datasheets/bst-bmp581-ds004.pdf), Figures 29/30/32 visually reviewed 2026-09-15 | I2C ties, supplies, pressure range, fast-ramp resistors and manufacturer-land footprint reviewed; parse/audit/independent dimensional pass complete; assembler process, full under-body routing, vent/reflow and settings remain |
| SHT40-AD1B-R2 | [Sensirion SHT4x v7.3, June 2026](https://sensirion.com/media/documents/33FD6951/6A7C10A0/HT_DS_Datasheet_SHT4x_V7.3.pdf) | Exact 0x44 suffix selected; preserve no-copper center area and validate edge/vent thermal behavior |
| RP2040 | [Raspberry Pi datasheet](https://datasheets.raspberrypi.com/rp2040/rp2040-datasheet.pdf), build 2025-02-20 | Boot flash/clock/support, PIO budget, supply and SWD/programming design |
| W25Q128JVSIQ | [Winbond W25Q128JV Rev M](https://www.winbond.com/resource-files/W25Q128JV%20RevM%2012242024%20Plus.pdf), [Winbond AN0000009 Rev 2.1](https://www.winbond.com/resource-files/AN0000009%20SpiFlash%20PCB%20Layout%20Guideline%20v2.1%2006122020.pdf), and [Raspberry Pi hardware design guide](https://datasheets.raspberrypi.com/rp2040/hardware-design-with-rp2040.pdf), reviewed through 2026-09-17 | Exact SOIC-8 208-mil copper/stencil candidate corrected from manufacturer data; assembler mask/courtyard approval, status-register defaults and boot behavior remain |
| ABM8-272-T3 | [Abracon exact drawing 456603 Rev B](https://abracon.com/datasheets/ABM8-272-T3.pdf), [official ABM8 series land drawing](https://abracon.com/Resonators/ABM8.pdf) revised 2020-07-29, and [Raspberry Pi hardware design guide](https://datasheets.raspberrypi.com/rp2040/hardware-design-with-rp2040.pdf), reviewed through 2026-09-15 | Exact manufacturer land independently reviewed and corrected; assembler mask/paste approval plus startup, drive and timebase tests remain |
| DM3AT-SF-PEJM5 | [Hirose exact product page](https://www.hirose.com/product/p/CL0609-0031-0-00), drawing `0000947170 / EDC-325165-00-00` Rev 4 (2026-08-01), and [DM3 catalog](https://www.hirose.com/en/product/document?documentid=D49662_en&documenttype=Catalog&lang=en&series=DM3), reviewed through 2026-09-15 | Electrical lands/pin map and operational card envelope reviewed; rectangular shell land confirmed; validate assembler paste, enclosure access, ESD and power-fail behavior |
| Display candidate AFY240320A1-2.8INTH-C1 | [Exact Orient specification revision J, 2021-07-20](https://www.orientdisplay.com/wp-content/uploads/2021/11/AFY240320A1-2.8INTH-C1.pdf) and [exact product page](https://orientdisplay.com/products/2-8-sunlight-readable-ips-240x320-900-nits-with-capacitive-touch-panel-rgb-mcu-spi-interface-new-ctp-ic/); reviewed through 2026-09-17 | Three-line `101`/four-line `110` straps and <=15.15 MHz serial write verified. TFT logic is 1.8 V; touch publishes ambiguous `0x70`; backlight is 5.8-6.4 V/100 mA. Controlled TFT-power/FPC/address clarification, CAD and two samples still gate release |
| XF3M-4015-1B / XF3M-0615-1B | [Omron XF3M/XF2M catalog G146-E1-05](https://components.omron.com/us-en/system/files/2025-03/datasheet_pdf/G146-E1.pdf), reviewed 2026-09-17 | Exact 0.30 x 1.30 mm signal and 1.50 x 2.20 mm hold-down lands documented. Controlled Orient tail tolerances, sample engagement/retention and independent footprints remain |
| SN74AXC4T245PWR / SN74LVC1G07DBVR | [TI SN74AXC4T245 Rev B](https://www.ti.com/lit/ds/symlink/sn74axc4t245.pdf) and [SN74LVC1G07 Rev AG](https://www.ti.com/lit/ds/symlink/sn74lvc1g07.pdf), reviewed 2026-09-17 | Preferred fixed A-to-B three-line TFT branch and open-drain reset translators; exact pulls, sequence, off-state and sample behavior remain |
| TPS61169DCKR | [TI TPS61169 Rev B](https://www.ti.com/lit/ds/symlink/tps61169.pdf) and [EVM guide SNVU455](https://www.ti.com/lit/pdf/snvu455), reviewed 2026-09-17 | Preferred backlight boost from 3V3_MAIN; LPS4018-103MRC/passive starting point documented. Exact 60 V-class Schottky plus sample fault/EMI/thermal tests remain |
| MAX-M10S-00B | [Data sheet UBX-20035208 R08, 2026-01-30](https://content.u-blox.com/sites/default/files/MAX-M10S_DataSheet_UBX-20035208.pdf), [integration manual UBX-20053088 R05, 2026-04-28](https://content.u-blox.com/sites/default/files/MAX-M10S_IntegrationManual_UBX-20053088.pdf), and [SPG 5.10 interface description UBX-21035062 R03](https://content.u-blox.com/sites/default/files/u-blox-M10-SPG-5.10_InterfaceDescription_UBX-21035062.pdf); reviewed 2026-09-13: data-sheet sections 3-6/9, manual sections 3.2-3.4/4.1-4.4/appendices B-C | Ordering code/type, 18-pin map, supply/backup/reset, UART/PPS, RF input, package and manufacturer land/paste pattern reviewed. P20 proposes tied always-on 3.3 V, no backup/reset/EXTINT and a passive no-bias RF path; RF/PDN review, 50-ohm calculation, assembler paste approval and AIR4 verification remain |
| FXP611.07.0092C | [Taoglas exact specification SPE-13-8-010-G](https://www.taoglas.com/datasheets/FXP611.07.0092C.pdf), reviewed 2026-09-14 | P20 passive GNSS L1 antenna candidate: 1559-1610 MHz, 38 x 37 x 0.15 mm, 92 mm cable, I-PEX MHF I/U.FL-compatible plug. Reserve 40 x 40 mm plus at least 10 mm to metal/main ground; verify the actual 3D-printed enclosure and coexistence |
| U.FL-R-SMT-1(60) | Hirose exact drawing `0001257918 / EDC-302540-60-80` and [exact-product U.FL catalog](https://www.hirose.com/en/product/document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), reviewed 2026-09-15 | Exact copper, metal mask and board-cut-out restriction independently reviewed/corrected; assembler process, cable mating/tool access, RF layout and the 30-cycle service limit remain |
| TPD1E0B04DPYR | [TI data sheet Rev C, June 2025](https://www.ti.com/lit/ds/symlink/tpd1e0b04.pdf), package drawing 4224561/C pages 23-25 reviewed 2026-09-17 | P20 GNSS feed ESD candidate; corrected SMD copper/mask/paste geometry completed dimensional comparison and parses/exports in KiCad. Obtain assembler SMD-mask approval, use TI's S-parameter model and VNA-check the full path |
| BQ25185DLHR | [TI data sheet Rev B](https://www.ti.com/lit/ds/symlink/bq25185.pdf) | Historical rejected P08 comparison only |
| LTC4415IDHC#PBF | [ADI data sheet](https://www.analog.com/media/en/technical-documentation/data-sheets/4415fa.pdf) | Historical rejected P08 comparison only |
| BQ25887RGER | [TI product page and Rev B data sheet](https://www.ti.com/product/BQ25887) plus [BQ25887EVM-001 guide SLUUC12](https://www.ti.com/lit/ug/sluuc12/sluuc12.pdf), reviewed through 2026-09-17 | Preferred 2S charger candidate; no power path and autonomous charging after POR. Close fail-safe CD gating, protection-ground/cutoff topology, charge-under-load termination, exact passives/layout and qualified review |
| BQ25792RQMR | [TI Rev C data sheet](https://www.ti.com/lit/ds/symlink/bq25792.pdf) | NVDC power-path comparison only; no integrated per-cell balancing, so not currently preferred |
| BQ77307RGRR | [TI production data](https://www.ti.com/lit/ds/symlink/bq77307.pdf) | Common-protection candidate; prove safe 2S connections, settings at every reset, sense/FET/NTC design and host-independent fault behavior |
| S-8252 family | [ABLIC revision 4.0](https://www.ablic.com/en/doc/datasheet/battery_protection/S8252_E.pdf) | Autonomous 2S protection candidate; exact suffix waits for accepted cell, thresholds, delays and zero-volt-charge policy |
| INR-21700-M50A | [Molicel manufacturer sheet V1-80097](https://www.molicel.com/wp-content/uploads/INR21700M50A-V1-80097.pdf), reviewed 2026-09-17 | First cell sample candidate: 20 A continuous and 25 mOhm typical DC impedance increase holder/fuse fault requirements. Validate sourcing, matched-pair service, cold runtime, fit and reviewer limits before lock |
| TUSB320LAIRWBR / TPS259474LRPWR | [TI TUSB320LAI Rev D](https://www.ti.com/product/TUSB320LAI) and [TI TPS25947](https://www.ti.com/product/TPS25947), reviewed 2026-09-17 | Fixed-UFP CC at 0x47 plus first VBUS eFuse candidate; close USB default-current policy, PSEL fail-safe, ILIM/OVLO/dVdt/ITIMER/discharge, thermal, footprints and sourcing |
| TPS62130ARGTR / TPS7A2030PDBVR / TPS7A2018PDBVR / TPS22918DBVR | [TI TPS62130A](https://www.ti.com/product/TPS62130A), [TPS7A20](https://www.ti.com/product/TPS7A20) and [TPS22918](https://www.ti.com/product/TPS22918), reviewed 2026-09-14 | Preferred main buck, quiet 3.0 V, logic 1.8 V and load-switch candidates; calculate exact loads/passives and verify sequencing, transient, thermal, EMI and back-power behavior |
| MMICT5838-00-012 / TXU0202DCUR | [TDK T5838 DS-000383 v1.1](https://invensense.tdk.com/wp-content/uploads/2023/06/DS-000383-T5838-Datasheet-v1.1.pdf) and [TI TXU0202 Rev A](https://www.ti.com/product/TXU0202), reviewed 2026-09-14 | Preferred 1.8 V PDM microphone and opposite-direction translator; independent CAD, OE sequence, acoustic port and audio/RF tests remain |
| USB4105-GF-A / TPD4E05U06DQARG4 | [GCT USB4105 product page/drawing](https://gct.co/connector/usb4105) and [TI TPD4E05U06 exact part](https://www.ti.com/product/TPD4E05U06/part-details/TPD4E05U06DQARG4), reviewed 2026-09-14 | Preferred USB-C receptacle and four-signal ESD candidate; independent CAD, USB layout/stackup and attach/enumeration tests remain. VBUS protection is still open |
| BM12B-GHS-TBT / GHR-12V-S / SSHL-002T-P0.2 | [JST GH series product index](https://www.jst-mfg.com/product/index.php?lang=2&series=105), reviewed 2026-09-14 | Preferred expansion header, housing and contact candidates; independently review drawings, wire/current limit, cable orientation, ESD/hot-plug/back-power and enclosure fit |
| SKSCLCE010 / TCA9535PWR | [Alps Alpine switch page/drawing](https://tech.alpsalpine.com/e/products/detail/SKSCLCE010/) and [TI TCA9535 Rev E](https://www.ti.com/lit/gpn/tca9535), reviewed 2026-09-14 | Preferred side buttons and slow I/O expander; independent CAD, enclosure actuation, GPIO0 recovery, external safe-state pulls and power-sequence tests remain |
| U.FL-R-SMT-1(60) / CAB.721 | [Hirose exact product](https://www.hirose.com/en/product/p/CL0331-0472-2-60) and [Taoglas CAB.721 Rev E](https://www.taoglas.com/datasheets/CAB.721.pdf), reviewed 2026-09-14 | Preferred internal RF receptacle and ADS-B/optional-LoRa SMA bulkhead cable; RF/CAD review, enclosure fit, stackup/loss/match and VNA/coexistence tests remain |
| ADS-B candidates | [BLB01](https://documents.berex.com/BLB01-V6.6.pdf), [TA2003A](https://www.taisaw.com/assets/PDF/TA2003A%20_Rev.1.0_.pdf), [ADL5513](https://www.analog.com/media/en/technical-documentation/data-sheets/adl5513.pdf), [MCP6566](https://ww1.microchip.com/downloads/aemDocuments/documents/MSLD/ProductDocuments/DataSheets/MCP6566-6R-6U-7-9-1.8V-Low-Power-Open-Drain-Output-Comparator-DS20002143G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) | Exact orderable suffixes, RF simulation and conducted prototype results |

The exact 2S protector/FET/fuse/holder, USB VBUS protection, state estimator, LoRa RF support and several ADS-B/RF suffixes remain open. For each future local download record title, source URL, revision/date, relevant sections, SHA-256 and permission to redistribute. Supplier IDs remain TBD until independently matched to the full MPN.

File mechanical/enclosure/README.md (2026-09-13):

# Enclosure placeholder

Future editable CAD and exports belong here after verified cell/holder, panel and connector drawings are available. Support the accepted display plus two removable 21700 cells, two controls, service access, sensor vents and antenna strain relief. See [mechanical requirements](../../docs/MECHANICAL_REQUIREMENTS.md). No fit-validated geometry exists.

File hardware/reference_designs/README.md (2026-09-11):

# Reference design index

Use [Semtech SX1262 reference designs](https://www.semtech.com/products/wireless-rf/lora-connect/sx1262), [Espressif hardware guidance](https://documentation.espressif.com/esp-hardware-design-guidelines/en/latest/esp32s3/index.html), [RP2040 hardware design guide](https://datasheets.raspberrypi.com/rp2040/hardware-design-with-rp2040.pdf), and the manufacturer resources linked in [power options](../../docs/POWER_ARCHITECTURE_OPTIONS.md).

Links are starting points. Before reuse, record exact revision, matched variant, license/terms, source files and modifications in [reuse register](../../references/REUSE_REGISTER.md). Do not vendor copyrighted reference files without checking redistribution terms. No circuit/layout assets have been copied.

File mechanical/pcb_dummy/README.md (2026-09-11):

# PCB dummy placeholder

Reserve later verified outline/component-envelope models for fit studies. The approximately 80 x 60 mm target is not a finished PCB boundary. Do not invent panel/FPC or cell-holder geometry. No STEP/STL/dummy is generated during the foundation phase.

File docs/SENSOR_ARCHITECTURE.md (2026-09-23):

# Sensor architecture

Locked set: **ICM-42688-P**, **MMC5983MA**, **BMP581**, **SHT40**. BME688 gas/VOC sensing is excluded from baseline. Revised D29 keeps BMP581 for indicative backup pressure/altitude/vario at the realistic ~10,000 ft use case; [P27](BAROMETER_30K_PROPOSAL.md) was rejected and is historical only. Sensor package temperatures are not substitutes for ambient SHT40 measurement.

| Sensor | Function | Interface plan | Primary source |
| --- | --- | --- | --- |
| ICM-42688-P | Accelerometer + gyro | I2C at 0x68 plus INT1; pin/application entry released; manufacturer-derived footprint passed dimensional second pass and awaits assembler/final-layout review | [TDK DS-000347 v1.9](https://d17t6iyxenbwp1.cloudfront.net/s3fs-public/2026-06/DS-000347%20ICM-42688-P%20v1.9.pdf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) |
| MMC5983MA | Three-axis magnetic field and calibrated heading input | I2C at 0x30; polled in Rev A; logical pin carrier entered; land centers corrected 2026-09-23; new independent review plus assembler/magnetic placement gates remain | [MEMSIC datasheet Rev A](https://www.memsic.com/Public/Uploads/uploadfile/files/20220119/MMC5983MADatasheetRevA.pdf) |
| BMP581 | Pressure, barometric altitude and variometer input | I2C at 0x46; polled in Rev A; logical pin carrier entered; manufacturer-derived footprint parses/audits and passed an independent dimensional review; assembler/full under-body routing/vent gates remain | [Bosch BST-BMP581-DS004-13](https://www.bosch-sensortec.com/media/boschsensortec/downloads/datasheets/bst-bmp581-ds004.pdf) |
| SHT40-AD1B-R2 | Ambient temperature/humidity | I2C at 0x44; exact symbol/footprint entered; heater normally disabled during ambient measurements | [Sensirion SHT4x datasheet v7.3](https://sensirion.com/media/documents/33FD6951/6A7C10A0/HT_DS_Datasheet_SHT4x_V7.3.pdf) |

Do not assign final I2C addresses until strap states and exact ordering codes are verified; touch, PMIC, fuel gauge and expansion devices must be included in the address/capacitance audit. Choose bus speed for the slowest participating device and actual loading. Add timeout/recovery for a peripheral holding the bus low. Review IRQ/wake requirements before exhausting GPIOs.

The reviewed schematic subset implements MMC5983MA with its 10 µF CAP capacitor and 1 µF VDD decoupling, BMP581 with 100 nF on each rail, and SHT40-AD1B-R2 with 100 nF decoupling. BMP581 VDD is 1.71–3.6 V and VDDIO is 1.08–3.6 V. Bosch DS004-13 Figure 28 requires 10 Ω in VDD and 100 Ω in VDDIO if either rail rises in less than 10 µs; the schematic keeps selectable positions until the rail ramps are measured. Shared I2C pull-ups remain assigned to the interfaces sheet.

ICM-42688-P DS-000347 v1.9 confirms AD0 low for 0x68, AP_CS tied to VDDIO for I2C, pin 7 tied to ground, and INT2/FSYNC/CLKIN grounded when unused. Its application circuit requires 0.1 µF plus 2.2 µF at VDD and 10 nF at VDDIO. AN-000393 v2.4 says the LGA PCB lands follow the package terminals, recommends clearing solder mask under the body where the board process permits it, gives a 0.1 mm per-pad opening expansion as the fallback, and specifies a 90% stencil-opening-to-land ratio. The project candidate interprets the latter as 90% area while preserving aspect ratio; the assembler must approve the final mask and paste. The similar generic KiCad LGA footprint has larger pads and is not accepted for this device.

The MMC5983MA Rev A page-20 land pattern is now transcribed exactly for copper. Its 1:1 mask/paste is a project process starting point because that datasheet gives no mask, aperture or stencil rule. BMP581 DS004-13 Figure 32 is transcribed with 0.300 x 0.325 mm lands, the 2.200 mm full no-mask opening and a central four-layer routing keepout. Its 1:1 paste is likewise provisional. Both candidates had center-versus-edge dimension errors; these were repaired on 2026-09-23 as recorded in [the correction evidence](FOOTPRINT_CORRECTIONS_2026_09_23.md). Revised-file independent review and assembler/process approval must precede schematic footprint assignment; final BMP routing review must also keep unnecessary traces and all vias out from under the complete body.

## Mechanical and thermal integration

Place SHT40 near an air exchange path and away from charger, regulators, ESP32, display backlight and warm cells. Evaluate slots or a narrow thermal neck around its PCB island while preserving mechanical strength and appropriate electrical return paths. Venting and environmental protection affect response; avoid coating or contaminating sensing openings. Follow manufacturer handling/reflow rules.

Give BMP581 a static-pressure vent protected from direct airflow, moisture and enclosure pressure transients. Do not use a fully sealed box as an assumed atmospheric pressure source. Microphone acoustic vent and pressure vent may have incompatible membrane/response needs.

Place ICM-42688-P on mechanically stable PCB area, not the flexible thermal island. Document body axes and transform to display coordinates in firmware. Keep MMC5983MA away from ferromagnetic fasteners, both cell cans, the 2S charger/buck inductors and current loops; test heading bias across pack state, charging and radio activity.

## Processing and acceptance

Record raw calibrated vectors, sample rates, timestamps, temperature and calibration version. Characterize gyro bias, acceleration scale/alignment, hard/soft-iron magnetic errors and tilt compensation. Distinguish magnetic heading from true heading; magnetic declination requires a defined source and valid position/time. An IMU does not provide reliable absolute yaw alone.

Vario processing needs pressure-noise/filter/group-delay characterization and a documented reference-pressure model. Specify altitude datum and out-of-range policy. **Revised 2026-09-22 mission check:** the [NWS standard-atmosphere table](https://www.weather.gov/media/zhu/ZHU_Training_Page/Met_Tutorials/Meteorological_Techniques.pdf) lists about **696.8 hPa at 10,000 ft**, comfortably inside the [BMP581 DS004-13](https://www.bosch-sensortec.com/media/boschsensortec/downloads/datasheets/bst-bmp581-ds004.pdf) specified 300–1250 hPa pressure range in that reference atmosphere. This is a range comparison, not a demonstrated accuracy, temperature or installation qualification. At 30,000 ft the cited [NWS/WMO example](https://www.weather.gov/media/epz/mesonet/CWOP-WMO8.pdf) is about 300.9 hPa, only 0.9 hPa above the sensor floor; no barometric performance is guaranteed there. D29 now treats BMP581 readings as indicative backup, and P27 is rejected. The vented sensor may track outside pressure in an unpressurized cabin, while board temperature depends on installation. Define pressure-port environment, temperature and invalid/out-of-range display/logging behavior before performance claims. Balloon ascent may exceed the specified range; do not extrapolate altitude. Evaluate SHT40 heating bias in enclosed FLIGHT and USB-charging states against an external reference.

Before board integration: read device IDs/status, verify axes with controlled rotations, check steady pressure and temperature, interrupt timing, sensor-failure recovery and power-cycle behavior. No calibration or performance figures are claimed by this foundation.

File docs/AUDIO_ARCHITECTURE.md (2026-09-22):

# Digital microphone architecture

Status: pre-schematic candidate reviewed 2026-09-14. Audio remains an optional fitted function in Rev A; disabling or later marking it DNP requires a recorded decision.

## Proposed parts and interface

Use TDK InvenSense `MMICT5838-00-012` as the first microphone candidate. Manufacturer data sheet DS-000383 revision 1.1 identifies a bottom-port PDM microphone in a 3.5 x 2.65 x 0.98 mm surface-mount package, with 1.62-1.98 V supply, -40 to 85 °C range, 68 dBA high-quality SNR, 133 dB SPL acoustic overload point and high-quality clock range of 2.0-3.7 MHz. DigiKey displayed 73,381 pieces in stock on 2026-09-14; recheck lifecycle and PCBA supply before freeze.

The ESP32 GPIO map already reserves `PDM_CLK` and `PDM_DATA`, so PDM closes the interface with two signals. Because the microphone is a 1.8 V device, use TI `TXU0202DCUR` as the first translation candidate: one fixed-direction channel carries clock from 3.3 V to 1.8 V and the opposite channel carries PDM data from 1.8 V to 3.3 V. TI specifies independent 1.1-5.5 V rails, opposite channel directions, up to 200 Mbps, partial-power-down isolation and VSSOP-8. Tie output enable to a reviewed rail-valid/reset policy so neither side back-powers an off domain.

The integrator's preferred reconciliation is to feed microphone VDD and the translator's low-voltage side from a distinct `1V8_AUDIO_SW` branch behind the candidate TPS22918 load switch. Its input is the shared, always-on `1V8_LOGIC` LDO output, which continues feeding the display. This is a net/domain proposal, not a frozen switch application: CT, output capacitance, QOD and ramp/voltage-drop review remain open in [the audio-domain review](AUDIO_DOMAIN_REVIEW.md). Place the manufacturer's required local bypass at the microphone and keep digital clock routing away from GNSS/RF inputs and the magnetometer. Confirm that sharing the upstream 1.8 V regulator does not couple visible or acoustic noise.

## Mechanical and validation gates

- The microphone is bottom-port. The PCB needs the exact manufacturer acoustic-hole/land pattern, copper and solder-mask keepout, and no solder paste over the port.
- The enclosure needs a short sealed acoustic path that does not expose the microphone to direct condensation. Gasket/compression details remain mechanical inputs.
- Validate 3.3-to-1.8 V clock and 1.8-to-3.3 V data levels, PDM duty/frequency, startup, sleep, off-state leakage and recovery after rail switching.
- Record a synchronized audio fixture with known tone/SPL, check sample rate, clipping, noise floor, missing blocks and timestamp mapping to system monotonic time.
- Measure RF self-interference during Wi-Fi, LoRa TX and ADS-B operation. Audio may be disabled in low-power profiles.

Primary evidence: [TDK T5838 product family](https://www.invensense.tdk.com/en-us/microphone), [T5838 DS-000383 revision 1.1](https://invensense.tdk.com/wp-content/uploads/2023/06/DS-000383-T5838-Datasheet-v1.1.pdf), [TI TXU0202 product page and revision-A data sheet](https://www.ti.com/product/TXU0202), and [DigiKey MMICT5838-00-012 snapshot](https://www.digikey.com/en/products/detail/tdk-invensense/MMICT5838-00-012/16903860).

## Disposition

The microphone and translator are preferred engineering candidates, not footprint releases. Final acceptance requires exact manufacturer CAD comparison, enclosure/acoustic decision, sourcing and board-level audio/RF tests.

## Audio circuit specification (AUD-01 closure, 2026-09-22)

Facts below were re-verified in the retrieved primary documents this session: TDK `DS-000383` rev 1.1 (retrieved via the Mouser-hosted copy of the identical vendor file after invensense.tdk.com returned HTML) and TI `TXU0202` data sheet (retrieved from ti.com).

### Microphone application (T5838, DS-000383 v1.1)

- **Supply:** VDD 1.62-1.98 V on proposed `1V8_AUDIO_SW` after the load switch; **100 nF local bypass at the mic pad plus 1 uF at the translator low side** (manufacturer bypass requirement class; final capacitance and ramp reviewed before capture).
- **Current inventory (feeds the PWR-04 `1V8_LOGIC` allowance):** high-quality mode supply current **310 uA typical / 340 uA maximum** at 2.4 MHz clock (DS section 6.1); low-power mode 120/140 uA at 768 kHz; sleep states 20-137 uA class. The microphone does **not** threaten the 25 mA `1V8_LOGIC` allowance; translator static is in the uA class (TXU0202 6 uA max control class).
- **Clock:** high-quality mode requires **2.0-3.7 MHz** (DS mode table); `PDM_CLK` (GPIO15) drives it through the translator at a firmware-selectable 2.048/3.072/3.2544 MHz-class rate; low-power 400-800 kHz and turbo 4.2-4.8 MHz windows exist but are not the Rev A default. CLK duty 50% class per DS.
- **PCB acoustic requirement (DS section 9):** land pattern is **1:1 with the package pads**; **no solder paste over the PCB sound hole**; PCB hole **0.5-1.0 mm diameter recommended** (never smaller than the 0.375 mm mic port); align the package port with the PCB hole. These are DIG-04 footprint constraints verbatim.
- **Acoustic path/enclosure (mechanical boundary, MECH-02/03):** short sealed path to an enclosure opening; gasket/compression and condensation exclusion remain the recorded mechanical inputs. No SPL/condensation claim is made here.

### Translator application (TXU0202, VSSOP-8)

- **Pin map (DS section 6, pin functions):** VCCA = port A supply, VCCB = port B supply, GND; A1/A2Y and B1/B2Y are the two fixed-direction channel pairs (one A->B, one B->A; orientation pinned at capture per the signal directions below); **OE pin 6: low = all outputs high-impedance, high (to VCCA or VCCB) = enabled**.
- **Signal assignment:** channel 1 A->B: `PDM_CLK` 3.3 V side -> 1.8 V mic clock; channel 2 B->A: mic PDM data 1.8 V -> `PDM_DATA` 3.3 V side. VCCA = `3V3_MAIN` on the 3.3 V channels' reference, proposed VCCB = `1V8_AUDIO_SW` on the mic side (A/B naming fixed to this assignment at schematic capture; the DS allows either rail on either port within 1.1-5.5 V).
- **OE policy (AUD-01 rail-valid proposal, reconciled):** OE (pin 6) pulled up to proposed `1V8_AUDIO_SW` through 100 kohm, no pulldown: the channels enable only when the switched microphone rail is present. TXU0202 Ioff/partial-power-down isolation makes outputs high-Z when either rail is absent. The actual OE/supply ramps and ESP32 pin behavior still require circuit-level review; do not infer that a host output driving an unpowered input is harmless without checking the exact TXU specification.
- **Off-state/recovery test row (board stage):** toggle the audio load switch so `1V8_AUDIO_SW` falls while upstream `1V8_LOGIC` and the TFT stay powered. Verify translator output isolation, PDM recovery, no latch-up and no `PDM_CLK`/`PDM_DATA` disturbance on the 3.3 V side while off. The historical `AUD_SW_EN_N` name becomes `AUD_SW_EN` for active-high TPS22918 control at capture.
- **Routing constraints:** keep `PDM_CLK`/`PDM_DATA` short and away from GNSS RF_IN, the MMC5983MA magnetometer area and the SX1262 switch node, per the standing architecture note; series termination not required at the short board lengths (translator drive and mic load only); revisit only if post-layout length exceeds ~50 mm.

### AUD-01 closure boundary

Delivered: pin-complete translator application, mic supply/clock/acoustic constraints, OE rail-valid policy, current inputs to PWR-04, routing constraints, and the off-state/recovery test row. **Deliberately open:** DIG-04 footprints (T5838 port-avoidance land, TXU0202 VSSOP-8) from the manufacturer CAD; enclosure acoustic path (MECH-02/03); post-PCBA audio/RF measurements; sourcing recheck at purchase.

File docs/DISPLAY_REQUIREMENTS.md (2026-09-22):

# Display interface specification

Locked product target: **2.8-inch IPS LCD, 320 x 240 in landscape or 240 x 320 in portrait, capacitive touch and both orientations**. Orient Display `AFY240320A1-2.8INTH-C1` remains the selected sample candidate; the exact part is not locked until sample and sourcing review.

Status: the exact manufacturer specification and candidate support circuit are now documented. The revision-J mode table verifies three-line, nine-bit SPI at `IM2/IM1/IM0 = 1/0/1` and four-line, eight-bit SPI at `1/1/0`; Rev A provisionally prefers the unambiguous three-line write-only path. Aratas/Omron `XF3M-4015-1B` and `XF3M-0615-1B`, TI `SN74AXC4T245PWR` plus `SN74LVC1G07DBVR`, and TI `TPS61169DCKR` are preferred candidates, not frozen parts. Connector footprints and schematic entry remain gated by the controlled-drawing power/FPC ambiguities, independent CAD review and labeled samples.

## Controlled sources

Reviewed through 2026-09-17:

- [Orient AFY240320A1-2.8INTH-C1 specification](https://www.orientdisplay.com/wp-content/uploads/2021/11/AFY240320A1-2.8INTH-C1.pdf), revision J dated 2021-07-20; sections 1-10 and drawing page 5.
- [Orient product page](https://orientdisplay.com/products/2-8-sunlight-readable-ips-240x320-900-nits-with-capacitive-touch-panel-rgb-mcu-spi-interface-new-ctp-ic/), exact SKU.
- [Omron XF3M/XF2M catalog](https://components.omron.com/us-en/system/files/2025-03/datasheet_pdf/G146-E1.pdf), catalog G146-E1-05 dated 2025-03; exact 0.5 mm dual-contact connector family and recommended FPC geometry.
- [TI SN74AXC4T245 data sheet](https://www.ti.com/lit/ds/symlink/sn74axc4t245.pdf), SCES877B revised 2024-04; and [TI SN74LVC1G07 data sheet](https://www.ti.com/lit/ds/symlink/sn74lvc1g07.pdf), SCES296AG revised 2025-10.
- [TI TPS61169 data sheet](https://www.ti.com/lit/ds/symlink/tps61169.pdf), SNVSA40B revised 2024-06.
- [TI TPS61169EVM guide](https://www.ti.com/lit/pdf/snvu455), SNVU455, for the manufacturer evaluation topology.
- [DigiKey exact-part listing](https://www.digikey.com/en/products/detail/orient-display/AFY240320A1-2-8INTH-C1/22531939), checked 2026-09-14 for dated price/availability only.
- DigiKey dated sourcing pages: [XF3M-4015-1B](https://www.digikey.com/en/products/detail/omron-electronics-inc-emc-div/XF3M-4015-1B/4331809), [XF3M-0615-1B](https://www.digikey.com/en/products/detail/aratas-formerly-omron-components/XF3M-0615-1B/4840775), [SN74AXC4T245PWR](https://www.digikey.com/en/products/detail/texas-instruments/SN74AXC4T245PWR/10060449), [SN74LVC1G07DBVR](https://www.digikey.com/en/products/detail/texas-instruments/SN74LVC1G07DBVR/377455) and [TPS61169DCKR](https://www.digikey.com/en/products/detail/texas-instruments/TPS61169DCKR/5048578).

The specification identifies ST7789VI or compatible for the TFT and ST1633I for touch. A compatible-controller substitution by the display manufacturer could change initialization or behavior without changing the module MPN; incoming inspection and sample identification remain required.

## Verified module data

| Item | Manufacturer specification |
| --- | --- |
| Module / active area | 50.45 x 69.90 x 4.22 mm; active area 43.20 x 57.60 mm; 28.1 g |
| Optical | IPS, normally black, transmissive, anti-glare, 900 cd/m2 typical, 600 cd/m2 minimum |
| Environment | -20 to +70 °C operation; -30 to +80 °C storage; no condensation |
| TFT supply | 2.4-3.6 V, 2.8 V typical; 9 mA typical in the published condition |
| TFT logic | VDDIO specified at 1.8 V; VIH >= 0.7 x VDDIO |
| Touch supply | 2.8-3.6 V, 3.3 V typical; 16.1 mA typical, 24 mA maximum |
| Touch I/O | 1.6-3.6 V; module specification publishes I2C value `0x70` without stating whether it is seven-bit or an eight-bit write byte; top-left coordinate origin |
| Backlight | Specification states 5.8-6.4 V, 100 mA typical, 125 mA absolute maximum and 0.60 W typical; it describes five LEDs in parallel |
| Power | 0.625 W module figure in the general table; backlight dominates and must be measured at the selected brightness |

The 1.8 V TFT logic requirement is incompatible with direct 3.3 V ESP32 drive. The SPI path needs a reviewed 3.3-to-1.8 V translation strategy and appropriate 1.8 V rail. Touch can use 3.3 V supply/I/O within the published range, subject to the separate ST1633I specification and sample confirmation.

The backlight description combines a 5.8-6.4 V forward range with a five-parallel-LED statement. Treat LEDA/LEDK as one two-terminal 100 mA load; do not infer the number of dies within each published LED element. Measure voltage/current and polarity on each labeled sample before committing the driver current.

## Exact module interfaces

The TFT interface table defines a 40-contact FPC:

| Pins | Names | Verified function / Rev A handling |
| --- | --- | --- |
| 1, 2 | LEDK, LEDA | Backlight cathode/anode; use reviewed current driver |
| 3, 14 | GND | Ground |
| 4-6 | IM0, IM1, IM2 | Revision-J straps: three-line, nine-bit SPI = `IM2/IM1/IM0 1/0/1`; four-line, eight-bit SPI = `1/1/0`. Rev A provisionally uses three-line `101` because its command/data bit is carried in-band |
| 7 | SDA | SPI data input |
| 8-11 | DOTCLK, DE, VSYNC, HSYNC | RGB signals; unused in the selected SPI mode only after the exact mode table defines required ties |
| 12 | VCC | TFT supply |
| 13 | RESET | TFT reset |
| 15-32 | DB17-DB0 | Parallel/RGB data bus; unused-pin treatment follows the exact selected SPI mode and controller specification |
| 33, 34 | RD, WR | Mode-dependent inputs. Four-line timing names `D/CX` without mapping it to an FPC contact; pin 34 is only labeled `WR`, so four-line remains blocked |
| 35 | RS | Serial-interface clock in the module table |
| 36 | CS | Active-low chip select |
| 37-40 | XR, YD, XL, YU | Marked NC for this capacitive-touch variant |

The capacitive-touch interface is a separate six-contact FPC:

| Pin | Name | Function |
| ---: | --- | --- |
| 1 | RESET | Active-low reset |
| 2 | VDD | Touch supply |
| 3 | GND | Ground |
| 4 | INT | State-change interrupt |
| 5 | SCL | I2C clock |
| 6 | SDA | I2C data |

## FPC geometry and connector candidates

The official specification is revision J, but its embedded page-5 external-dimensions title block says revision G and its latest visible internal drawing entry is G dated 2021-01-19. The revision record says J dated 2021-07-20 updated page 5. This mismatch prevents treating the raster drawing as a controlled release; request a current native/controlled drawing from Orient before footprint freeze.

Values transcribed from page 5:

| Tail | Contacts | Pitch/span | Contact / terminal geometry | Thickness | Candidate consequence |
| --- | ---: | --- | --- | --- | --- |
| TFT | 40 | 0.50 mm; `0.5 x (40-1) = 19.50 +/- 0.05 mm` | Contact width `0.35 +/- 0.05 mm`; tail width `20.50 +/- 0.20 mm`; exposed-contact length `3.50 +/- 0.30 mm`; end setback `0.50 +/- 0.10 mm` | `0.30 +/- 0.03 mm` | Pitch, nominal tail width and thickness match `XF3M-4015-1B`; sample insertion and contact engagement still required |
| CTP | 6 | 0.50 mm; `0.5 x (6-1) = 2.50 +/- 0.05 mm` | Contact width `0.35 +/- 0.05 mm`; exposed-contact length `3.50 +/- 0.30 mm`; end setback `0.50 +/- 0.10 mm`; one nearby `4.70 +/- 0.50 mm` callout is not unambiguously attributable to the terminal width in the raster drawing | `0.30 +/- 0.03 mm` | Pitch and thickness match `XF3M-0615-1B`; exact tip width and insertion clearance require Orient confirmation/sample measurement |

The drawing explicitly identifies a contact side for the TFT tail, but the CTP tail contact-side callout is not independently clear. Preferred connector candidates are therefore the dual-sided-contact, 0.5 mm-pitch, 0.30 mm FPC/FFC Aratas/Omron `XF3M-4015-1B` and `XF3M-0615-1B`. The current manufacturer catalog lists both exact pin counts, right-angle rotary backlock construction, 2.0 mm installed height, 0.5 A rating, gold-flash contacts, 20 mating cycles and -30 to +85 degC operation. Dual contacts remove the electrical top/bottom-contact ambiguity, but they do not prove tip width, stiffener, insertion depth, actuator access or strain-relief fit.

The Omron recommended FPC drawing calls for at least 3.5 mm in the terminal region, while the Orient nominal exposed length is 3.50 mm with a -0.30 mm tolerance. Resolve that tolerance boundary with Orient before connector release. Secure both tails against vibration and reserve actuator-operating space as required by the connector manufacturer.

The exact Omron recommended board lands are available for later controlled CAD: signal lands are `0.30 x 1.30 mm` on `0.50 mm` pitch and hold-down lands are `1.50 x 2.20 mm`. For the 40-pin part, catalog dimensions A/B/C/D/E/F/G are `19.50/23.10/24.10/20.55/20.50/21.50/25.10 mm`; for the six-pin part they are `2.50/6.10/7.10/3.55/3.50/4.50/8.10 mm`. These values close manufacturer-land availability, but do not override the unresolved Orient tail tolerance or authorize a footprint yet.

Do not create or assign either connector footprint until the exact manufacturer land pattern is independently overlaid, the controlled Orient drawing is obtained or its ambiguity is dispositioned, and two labeled display samples pass insertion/retention/continuity checks.

## TFT logic translation proposal

Use a display-only branch; the shared 3.3 V SPI trunk to microSD and SX1262 remains unshifted.

- Preferred bus translator: TI `SN74AXC4T245PWR`, TSSOP-16. Connect pin 1 VCCA to `3V3_MAIN`, pin 16 VCCB to `1V8_LOGIC`, and hold both direction inputs (pins 2 and 3) high for A-to-B. Use channels pins 4-to-13, 5-to-12 and 6-to-11 for SCLK, SDA and CS. Give unused A4 pin 7 a defined level if B4 pin 10 is unused.
- The approved DSP-02 application below uses **10 kohm pull-downs on both OE inputs** (OE high tri-states this exact AXC device). The earlier pull-up proposal was superseded. Place one local bypass capacitor at each supply pin pair and keep translated traces short; validate startup and shutdown with the exact display samples.
- Preferred reset translator: TI `SN74LVC1G07DBVR`: pin 2 input from the 3.3 V reset control, pin 3 ground, pin 4 open-drain TFT reset, pin 5 `1V8_LOGIC`, pin 1 NC. An input pull-down holds reset asserted at boot and an output pull-up to `1V8_LOGIC` prevents a 3.3 V high level at the TFT reset pin.
- The AXC device supports either rail from 0.65 to 3.6 V, Ioff partial-power-down protection, VCC isolation and supply sequencing in either order. The LVC buffer supports 1.65-5.5 V operation, overvoltage-tolerant input and Ioff. These properties reduce back-power risk but do not replace a measured rail/reset sequence.

The module labels SDA as I/O. The fixed direction above intentionally provides write-only display traffic. In the preferred three-line mode, the ninth serial bit carries command/data state, so the unexplained four-line `D/CX` contact is avoided. The published 66 ns minimum serial write cycle limits the panel clock to about 15.15 MHz. If register/pixel readback is required, the design must add controlled turnaround and prove there is no bus contention. Four-line SPI remains blocked until Orient maps `D/CX` to an exact FPC contact.

Revision J still contains a supply-domain contradiction: timing/sequencing pages refer to separate `VDDI` and `VDD`, the DC table names `VDDIO = 1.8 V`, and the FPC exposes only one TFT `VCC` contact. Obtain a controlled electrical clarification before freezing TFT power, even though the serial strap table itself is now readable.

`1V8_LOGIC` is supplied by the already proposed `TPS7A2018PDBVR`; this display work does not replace that regulator. The rail load calculation remains open because Orient does not publish a VDDIO current maximum.

## Backlight driver proposal

Preferred candidate: TI `TPS61169DCKR`, an active SC70-5 boost WLED driver with 2.7-5.5 V input, 38 V output capability, 204 mV feedback reference, 1.2 MHz switching, soft start, open-LED protection, UVLO, PWM control and thermal protection. Feed it from `3V3_MAIN`, never directly from the 6.0-8.4 V protected 2S bus.

Application starting point from the TI topology:

1. `3V3_MAIN` through a 10 uH `LPS4018-103MRC` candidate to SW. The older `-103ML` suffix is not the current ordering code. A pessimistic 2.7 V input/6.62 V output calculation gives roughly 0.44-0.46 A peak; final saturation current, DCR, temperature and sourcing remain gated.
2. Use a Schottky from SW to LEDA. The EVM's 40 V `NSR0240V2T1G` leaves only 1 V above the published 39 V maximum OVP corner, so select an exact 60 V-class part with adequate repetitive peak current before freeze.
3. Place at least 1 uF ceramic at VIN; 4.7 uF local bulk is a reasonable prototype start. Use 1-4.7 uF **effective** output capacitance with a 50 V rating because an open LED can raise the node toward the 36-39 V OVP range. Connect LEDK to FB and place RSET from FB to ground at the IC.
4. Start with `RSET = 2.21 ohm, 1%, at least 0.1 W`, which gives about 92.3 mA at the typical 204 mV reference. Using 188-220 mV and resistor tolerance gives approximately 84.2-100.5 mA. Verify sample current, luminance and temperature before freeze.
5. Drive CTRL from `LCD_BL_PWM`; the IC already has a 300 kOhm internal pull-down, while an external pull-down may reinforce reset behavior. TI recommends 5-100 kHz PWM; use 20 kHz as the initial bring-up setting.

At 0.60 W output, estimated input current from 3.3 V is about 202 mA at TI's 90% peak efficiency or 214 mA at an 85% planning efficiency. Reserve at least 250 mA of `3V3_MAIN` peak budget pending measured efficiency and transient data. Because the panel's minimum 5.8 V LED forward voltage exceeds the 3.3 V driver input, the TPS61169 shutdown-path condition for keeping the LEDs off is met on paper; verify leakage on both samples.

Keep the SW/inductor/diode loop short, place CIN/COUT and RSET at the IC, separate signal and power return until the IC ground point, and locate the boost stage away from GNSS, LoRa, ADS-B, the magnetometer and their antennas. Measure conducted/radiated noise at full brightness and PWM corners. Open LED, LED short, CTRL stuck high/low and hot-enclosure tests remain mandatory.

## Host and sequencing plan

SPI remains the selected first interface because it fits the GPIO budget. Rev A provisionally uses write-only three-line, nine-bit SPI with `IM2/IM1/IM0 = 1/0/1` and a panel clock no faster than 15 MHz. Sample validation, unused-pin ties and the TFT supply clarification remain gates. RGB or 8080 MCU mode requires a new documented GPIO/bandwidth decision.

Keep the TFT translator disabled and TFT reset asserted while `3V3_MAIN`, TFT VCC and `1V8_LOGIC` rise; release reset and then enable bus traffic only after the official timing is satisfied. Before shutting down a display rail, stop SPI traffic, disable the translator and assert reset. Touch RESET needs its own 3.3 V-safe implementation: revision J requires it low before power-on/off, held low for at least 5 ms after rails become valid, and asserted at least 100 us before power-off. Do not rely on an undefined expander default.

At RGB565, a full 320 x 240 frame is 153,600 bytes. Thirty full frames/s requires 4.608 MB/s, or 36.864 Mbit/s of payload before command overhead and bus gaps. Prefer partial updates and measure contention with microSD and SX1262 on the shared SPI host.

Firmware must separate panel driver, touch driver, orientation transform, backlight policy and UI. Test all four corners in both orientations, sleep/wake, display-off logging and brightness profiles.

## Display support circuit — exact values (DSP-02, 2026-09-22)

Facts re-verified in the retrieved TI documents this session: `SN74AXC4T245` SCES877B (April 2024) and `SN74LVC1G07` SCES296AG (October 2025). This section completes the DSP-02 engineering deliverable; **final acceptance remains gated by the controlled-drawing clarification (DSP-01/EXT-01) and two-sample validation as recorded in the release-gate list.**

### SN74AXC4T245PWR (TSSOP-16) — 3.3 V-to-1.8 V SPI branch

- **Pin-level assignment (SCES877B pin table):** VCCA pin 1 = `3V3_MAIN`; VCCB pin 16 = `1V8_LOGIC`; 1DIR pin 2 = high (tie to `3V3_MAIN`); 2DIR pin 3 = high (tie to `3V3_MAIN`); 1OE pin 15 = host-controlled enable net (see policy below); 2OE pin 14 = host-controlled enable net; ports: 1A1 pin 4 -> 1B1 pin 13 (SCLK), 1A2 pin 5 -> 1B2 pin 12 (SDA), 2A1 pin 6 -> 2B1 pin 11 (CS); 2A2 pin 7 is the unused A-side input and **must be tied to GND** per the TI rule that all unused inputs sit at VCC or GND (section 5.4 note) — its partner 2B2 pin 10 then idles and stays unconnected.
- **DIR polarity correction:** the previous proposal text said "hold both direction inputs high for A-to-B"; this is confirmed correct (DIR high = A->B, section 7.1) and is now pinned to the datasheet section.
- **OE polarity fact:** **OE high = outputs in tri-state** for this family (section 7.1: "When OE is set to high, both Ax and Bx pins are in the high-impedance state"). The safe power-up policy therefore is **10 kohm pull-downs from both OE pins to GND** — the branch wakes enabled, which is safe here because the display is write-only and reset-held; a host-enable option may raise OE later for a controlled bus release. This supersedes the earlier "pull each active-low OE to VCCA" phrasing in the proposal above (that phrasing belonged to a different device family convention and would have left the branch permanently disabled).
- **Static load:** ICCA <= 12 uA, ICCB <= 16 uA max at 3.6 V, IO = 0 (section 5) — inside the PWR-04 `1V8_LOGIC`/`3V3_MAIN` allowances; no inventory change.
- **Bypass:** 100 nF at VCCA pin 1 and at VCCB pin 16 (device class; already the recorded proposal).

### SN74LVC1G07DBVR (SOT-23-5) — open-drain display reset

- **Pin-level assignment (DBV):** pin 2 = input from the 3.3 V reset control (TCA9535 `LCD_RST_N` through the expander-side network); pin 3 = GND; pin 4 = open-drain output to TFT RESET with **10 kohm pull-up to `1V8_LOGIC`** (not `3V3_MAIN` — the reset pin is a 1.8 V-domain input); pin 5 = VCC = `1V8_LOGIC`; pin 1 = NC.
- **Polarity fact (TI SCES296AG Rev AG, section 7.4 function table):** input **low** makes the open-drain output **low** and asserts active-low TFT RESET; input **high** leaves the output high impedance and its 10 kohm display-side pull-up releases RESET. A **100 kohm input pull-down (3.3 V control domain)** therefore holds the display in reset while the expander is unconfigured. The expander must drive its control output high to release reset; verify its push-pull configuration and the TFT timing on samples.
- **Cross-reference to DIG-03:** expander P06 drives the LVC1G07 **input** in the `3V3_MAIN` domain, with a 100 kohm input pull-down; firmware must configure it push-pull high to release reset. The `1V8_LOGIC` pull-up is on the LVC1G07 **output** at the display connector. No rail-crossing pull exists. TI SCES296AG Rev AG section 7.4 confirms low input = low output, high input = open-drain high impedance.
- **IOL margin:** the LVC1G07 sinks 8 mA at 0.3 V class (section 6) against a 10 kohm/1.8 V pull-up demand of 0.18 mA — non-binding.
- **TFT RESET pin rule retained:** never add a capacitor from TFT RESET to ground (module rule); the reset waveform belongs to the display sample validation.

### Startup/shutdown sequence (values from the standing plan, now resistor-backed)

1. Rails rise: `3V3_MAIN` (buck soft-start) -> `1V8_LOGIC` tracks up. AXC OEs held low by pull-downs = branch **enabled** but the ESP32 has not clocked anything; LVC1G07 input pull-down asserts TFT RESET low through the sink path.
2. ESP32 boots and configures TCA9535 P06 as a push-pull high output; LVC1G07 input rises, its output becomes high impedance and the TFT-side pull-up releases RESET after the module's reset-low requirement is satisfied (>= 1 ms low per the module record; sample validation remains required).
3. SPI traffic begins at <= 15 MHz panel-clock bound; IM straps `101` selected on the FPC (hardware straps, not firmware).
4. Shutdown: stop SPI traffic -> drive P06 low to assert TFT RESET -> rails fall with the input pull-down maintaining RESET while the translator output is enabled. Touch reset timing (5 ms post-rails, 100 us pre-power-off) stays with the touch branch and its expander row.

### DSP-02 closure boundary

Delivered: pin-complete translator and reset applications with datasheet-pinned polarities and resistor values, static-load confirmation against PWR-04, corrected OE/DIR conventions, and the integrated startup/shutdown sequence. **Deliberately open (final acceptance):** controlled-drawing clarification and sample validation (DSP-01/EXT-01/release gates 1-2), unused-pin ties for the wider FPC (gate 3), backlight sample measurements (gate 4), and footprints (gate 6/DIG-04 deferral list).

## Sourcing snapshot and remaining gates

Checked 2026-09-14: the exact Orient store page listed 50 units at USD 35.36 each, USD 31.39 at 25-49 and USD 27.42 at 50+. DigiKey listed zero immediately available, one expected 2026-10-19, USD 31.55 at quantity one and an eight-week manufacturer lead time. DigiKey also listed 9,902 `XF3M-4015-1B` at USD 2.93 each, 975 `XF3M-0615-1B` at USD 1.23 cut-tape, 16,834 `SN74AXC4T245PWR` at USD 1.17, 165,134 `SN74LVC1G07DBVR` at USD 0.14 and 2,019 `TPS61169DCKR` at USD 1.18. These are dated prototype snapshots from an authorized distributor; recheck before purchase and confirm PCBA-factory availability separately.

Before connector or footprint freeze:

1. obtain a controlled/current Orient mechanical drawing that resolves the revision-J/revision-G mismatch and ambiguous CTP terminal width/contact side;
2. obtain at least two labeled C1 samples and confirm controller identification, both tail geometries, contact engagement, retention, continuity and bend/actuator clearances with the proposed XF3M connectors;
3. review the `SN74AXC4T245PWR` plus `SN74LVC1G07DBVR` circuit, exact 1.8 V/TFT/touch rails, resets and back-power behavior; validate the provisional write-only three-line `101` mode on both samples and select unused-pin ties;
4. prototype `TPS61169DCKR` from 3.3 V with the proposed 2.21 ohm limit; measure current, luminance, leakage, efficiency, temperature, PWM behavior, startup and open/short faults;
5. run address, touch, orientation, shared-bus, sleep/wake and RF-coexistence tests;
6. create connector and IC footprints only from exact manufacturer drawings and independently overlay/review them before release.

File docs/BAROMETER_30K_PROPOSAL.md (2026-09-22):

# Historical 30,000 ft barometer comparison (P27 rejected)

Status: **REJECTED BY OWNER 2026-09-22 — historical comparison only. BMP581 remains the locked D08 part. Do not change the KiCad schematic, BOM fitted line, footprint or pin map on the basis of this document.** The owner revised the realistic use altitude to about 10,000 ft, with 30,000 ft exploratory and barometric readings only indicative. The original proposal below is preserved to show why it was considered; its former requirement and approval gate are superseded by D25/D29.

## Trigger and comparison

The [NWS/WMO standard-atmosphere example](https://www.weather.gov/media/epz/mesonet/CWOP-WMO8.pdf) gives **300.9 hPa** at 30,000 ft. The locked [Bosch BMP581 DS004-13](https://www.bosch-sensortec.com/media/boschsensortec/downloads/datasheets/bst-bmp581-ds004.pdf), §2/Table 1, specifies **300–1250 hPa**: only **0.9 hPa (0.09 kPa)** of nominal pressure margin remains in that one reference atmosphere. Weather and static-port errors can consume it. The standard outside-air temperature is about **-44.5 C** ([NWS table](https://www.weather.gov/index.php/ama/conversions)), below BMP581's -40 C operating minimum; the board's actual temperature inside the cabin/enclosure is not yet known. Neither part below is thereby qualified for an unheated -44.5 C board.

| Option | Manufacturer evidence | Pressure margin at standard 30,000 ft | 2026-09-22 sourcing snapshot, five-piece implication |
| --- | --- | ---: | --- |
| Keep locked `BMP581` | Bosch DS004-13 §2/Table 1: 300–1250 hPa, -40 to +85 C operating | 0.9 hPa | [LCSC C5362283](https://www.lcsc.com/product-detail/C5362283.html): page showed USD 3.0604 at quantity 1 and positive indexed stock; five at single-unit price = USD 15.302 before assembly/shipping. [DigiKey](https://www.digikey.com/en/products/detail/bosch-sensortec/BMP581/16036134) showed USD 3.07 at quantity 1. Stock is volatile |
| **Propose `LPS22HBTR`** | [ST product page](https://www.st.com/content/st_com/en/products/mems-and-sensors/pressure-sensors/lps22hb.html): active, 260–1260 hPa, -40 to +85 C, I2C/SPI, 2 x 2 mm HLGA-10; [ST data sheet DocID027083 Rev 6](https://www.st.com/resource/en/datasheet/lps22hb.pdf), reviewed 2026-09-22, §§2–3, 6–7, 10 | 40.9 hPa | [LCSC C94049](https://www.lcsc.com/product-detail/C94049.html): page showed USD 3.1264 at quantity 1 and positive indexed stock; five at single-unit price = USD 15.632 before assembly/shipping. **USD 0.330 more for five sensors** versus the cited BMP581 snapshot. Indexed stock differed across page versions, so live cart/PCBA availability is TBD |
| Consider `LPS22DFTR` if available | [ST product page](https://www.st.com/en/mems-and-sensors/lps22df.html): active, 260–1260 hPa, -40 to +85 C, I2C/SPI; [ST data sheet](https://www.st.com/resource/en/datasheet/lps22df.pdf) | 40.9 hPa | [LCSC C3253714](https://www.lcsc.com/product-detail/pressure-sensors_st-lps22dftr_C3253714.html) and [DigiKey](https://www.digikey.com/en/products/detail/stmicroelectronics/LPS22DFTR/15520532) showed out of stock in reviewed results; five-unit availability is not demonstrated. Do not substitute it silently |

At the time of review, LPS22HBTR appeared to be a practical **alternative**, but the owner rejected the replacement. The cited prices are dated USD component snapshots, not a BRL five-PCBA quote or proof that D24's total target is feasible. Recheck BMP581 stock, assembly eligibility and price when placing the order.

## Historical impact if a future owner decision reopens replacement

- **Electrical:** ST Rev 6 §§3, 6–7 must supply a pin-by-pin application for 3.3 V VDD/VDD_IO, bypass, I2C selection, SA0 strap, reset/default and off-state behavior. The ST data sheet gives seven-bit I2C address `0x5C` (SA0 low) or `0x5D` (high); neither appears in the current [shared-bus map](INTERFACE_GPIO_MAP.md), but touch-address convention and bus-capacitance/off-state reviews remain open. Do not reuse the BMP581 schematic carrier, 0x46 address, fast-ramp resistor option or net names without review.
- **Firmware/interface:** device ID, register map, pressure conversion, ODR/filter/FIFO/interrupt options, pressure/temperature calibration and out-of-range handling change. Existing BMP581 driver assumptions cannot be reused. Keep the 100 kHz D22 bus policy and quantify vario noise/group delay for the accepted operating profile.
- **PCB/mechanical:** both devices are nominally 2 x 2 mm with 10 terminals, **not established as pin- or land-compatible**. Create a fresh ST-package-derived symbol and footprint from Rev 6 §10, independently compare land/pad/pin-1, obtain assembler mask/paste approval, then reassess vent, under-body routing, thermal island, footprint courtyard, placement and enclosure static-port response. The previous BMP581 footprint review cannot certify the replacement.
- **Temperature:** a 260 hPa pressure floor alone does not qualify operation if the board falls below -40 C. Define a guaranteed board temperature inside the aircraft/enclosure at the 30,000 ft pressure reference, or add a reviewed thermal design; review all other fitted components and the cells against the same envelope.

## Closed decision and future reopening gate

P27 is closed as rejected; no replacement task is pending for Astra. A future owner request to restore guaranteed 30,000 ft barometric coverage would require a new explicit decision, a current exact-part cost/availability comparison and the full electrical, firmware, CAD, vent, temperature and independent-review work listed above. No claimed 30,000 ft barometric performance is valid without bench pressure/thermal tests and built-board validation.

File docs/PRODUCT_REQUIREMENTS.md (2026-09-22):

# Product requirements

StratosCore Rev A is a compact experimental field computer. This document expresses targets; none is a measured performance claim. [DECISIONS.md](DECISIONS.md) controls component choices.

| ID | Requirement | Verification / completion evidence |
| --- | --- | --- |
| PR01 | Use ESP32-S3-WROOM-1-N16R8 with integrated PCB antenna | Exact module ordering code, datasheet, flash/PSRAM bring-up |
| PR02 | 2.8-inch IPS, 320 x 240, capacitive touch, both orientations | Vendor drawing, sample test, rotation/touch corner tests |
| PR03 | Two accessible physical buttons | Debounce, boot behavior, enclosure access in both orientations |
| PR04 | Integrated SX1262 SPI, 915 MHz hardware, U.FL | Semtech reference review, conducted RF and regional configuration tests |
| PR05 | MAX-M10S-00B UART multi-GNSS navigation suitable for balloon altitude | Cold/warm-start, airborne-mode, NMEA/UBX, constellation and 80 km boundary review/tests |
| PR06 | ICM-42688-P + MMC5983MA + BMP581 + SHT40 | Device identity, axes, calibration, pressure and thermal tests |
| PR07 | Core 1090 MHz ADS-B with RP2040 and dedicated frontend | Known frames, invalid-frame rejection, RF replay and coexistence tests |
| PR08 | Traffic model with ICAO, callsign, lat/lon, altitude, velocity, track/heading when available | Field validity, per-field age, CPR and ownship-relative display tests |
| PR09 | Mandatory microSD black-box-style data logging | Long-duration writes, removal/full-card errors, bounded queues, power interruption |
| PR10 | Digital MEMS microphone provision, optional synchronized logging | Audio timestamp mapping, throughput, clock drift, dropped-block flags |
| PR11 | USB-C charging, operation while charging, native data target | Source-current limits, role/orientation, brownout, thermal and fault tests |
| PR12 | Two removable matched 21700 cells in 2S with one balanced charger and common protection | Qualified battery review including mismatch, missing/reversed cell, removal, short, thermal and charge/discharge faults |
| PR13 | At least 8 h on the required two-cell 21700 pair in the primary portable operating profile | Profile, brightness, battery, temperature and radios documented in discharge test; engineering allowance is not measured runtime |
| PR14 | 3V3/GND + I2C + SPI/CS + UART + GPIO/IRQ expansion | Pin budget, voltage/current limits, connector and recovery tests |
| PR15 | Four-layer PCB, approximately 80 x 60 mm target footprint | Manufacturer stackup and mechanical fit review; final dimensions open |
| PR16 | Printed enclosure for display and two 21700 cells, approximately 37 mm starting thickness | Exact holder/panel/cable tolerances, printed dummy and sample fit |
| PR17 | Thermal and RF isolation | Temperature bias tests and receiver degradation during each aggressor state |
| PR18 | Open-source provenance and manufacturing readiness | License register; BOM/footprint audits; later ERC/DRC and assembly review |
| PR19 | Personal, non-commercial, open-community hobby prototype | Repository/license review and applicable operating-rule plan; no product-certification claim |
| PR20 | Initial five-unit batch targets an average cost no higher than BRL 200 per Chinese PCBA including display/touch; local cells/enclosure, freight and taxes excluded | Dated five-unit assembly and display quotes plus BOM reconciliation; do not delete locked features to meet the target without owner acceptance |
| PR21 | Hobby use on a desk, in a car or protected but unpressurized aircraft cabin; experimental drone, model-aircraft, balloon, ultralight, hang-glider and paramotor use needs an installation-specific review. Approximately 10,000 ft is the realistic operating case; 30,000 ft is exploratory. BMP581 barometric altitude/vario are indicative backup data | Bench-check pressure/vario and sensor validity at the realistic pressure case; retain the BMP581 specified operating limits and flag out-of-range readings. No 30,000 ft barometric guarantee or primary flight-instrument claim |
| PR22 | No mass target, rain/ingress qualification, conformal coating or special environmental protection for Rev A | Mechanical/process documents record the exclusion while preserving sensor, pressure, humidity and acoustic openings |
| PR23 | Program and test the initial five PCBAs locally through USB-C, with SWD recovery access | USB-C flash/recovery and local test procedure; factory does not inject firmware or credentials |

## Use profiles

| Profile | Display / wireless | Navigation and sensors | ADS-B / logging |
| --- | --- | --- | --- |
| BALLOON | Display mostly off; Wi-Fi off; BLE optional; periodic LoRa | GNSS and sensors active at profile-selected rates | ADS-B optional/off; periodic telemetry log; audio normally off |
| FLIGHT | Display active; Wi-Fi normally off; BLE/LoRa optional | GNSS, pressure/vario and motion active | ADS-B active; continuous event/telemetry logs; audio optional |
| DESKTOP | USB powered; display and Wi-Fi active | All sensors available | ADS-B optional; all logging services available |

The 8 h minimum runtime on two 21700 cells remains a target. About 10,000 ft is the realistic altitude case for protected, unpressurized use; 30,000 ft is an exploratory scenario without an altitude/vario guarantee. BMP581 remains fitted as an indicative secondary sensor. The pressure port must see representative static pressure, and firmware must flag out-of-range or uncalibrated readings. Actual board temperature, dynamics and the separate balloon/exposed-installation envelopes remain unspecified and require review before any corresponding performance claim. Mass and rain/ingress resistance are not design targets for Rev A. Sunlight brightness, ADS-B sensitivity/range and acceptable log loss remain open. [P27](BAROMETER_30K_PROPOSAL.md) is rejected historical comparison, not a part-selection gate.

## Data and behavior

Logs must be able to represent UTC/time validity, monotonic timestamp, GNSS fix/position/altitude, barometric altitude with reference pressure, pressure, ambient temperature/humidity, accelerometer, gyroscope, magnetic vector/derived heading, LoRa RX/TX, ADS-B contacts, battery state and system events. Include units, schema/firmware version, calibration ID and data validity. Do not replace missing readings with plausible zeroes.

Microphone logging is optional and experimental; it is not a certified cockpit voice recorder. ADS-B is receive-only, incomplete traffic information; no certified navigation or collision-avoidance claim. MeshCore companion, messaging, tracker and repeater are firmware objectives subject to porting and licensing, not working features.

## Current architecture acceptance

All requested paths exist, locked parts and proposals are explicit in the preliminary BOM, unknown supplier IDs remain TBD, diagrams are conceptual, references have license assessments and official license texts are present. [Project status](PROJECT_STATUS.md) lists ordered work; [Astra handoff](ASTRA_HANDOFF.md) is reserved for final KiCad execution. A valid gated KiCad hierarchy and host ADS-B timing fixture exist. No completed circuit, PCB routing or manufacturing release is included.

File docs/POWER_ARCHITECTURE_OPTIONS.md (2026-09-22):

# Power architecture options

**Status: option D was accepted by the owner on 2026-09-13 as the engineering direction.** The exact circuit is not frozen and may not be energized until a qualified electrical/battery reviewer accepts the schematic, protection thresholds and fault-test limits. See the concrete [power architecture review](POWER_ARCHITECTURE_REVIEW.md).

## Compared options

| Option | Energy/charge paths | Advantages | Issues and disposition |
| --- | --- | --- | --- |
| A: one managed 1S bay | Cell protection and reverse-insertion stage; 1S charger with separate system power path | Lowest part count | Does not meet the owner's two-cell requirement; rejected for Rev A |
| B: two independently managed 1S bays | Each bay has protection, temperature monitoring and a charger; reverse-blocked outputs feed an OR stage | Either bay can operate alone; prevents cell equalization | Rejected by owner as excessive complexity on 2026-09-13; retained as comparison evidence |
| C: two bays with mutually exclusive selection | Hardware interlocked battery selection; charger connects only to the selected bay | Potentially one 1S charger | Selection, charging and removal fault behavior remain complicated; rejected for Rev A |
| **D: managed 2S removable pair** | Two series cells with midpoint sensing, balancing, one 2S charger, common 2S protection and buck regulation | Meets two-cell/removable-holder requirement with one charger; lower system current for equal power | **Owner accepted direction.** Both cells are required; qualified safety review and fault tests remain mandatory |
| E: fixed matched 1S2P pack | Factory-assembled matched parallel pack, protection and pack connector | Simple 1S charging | Conflicts with the owner's removable-cell holder requirement; rejected for Rev A |

## Accepted 2S constraints

- Use two cells of the same approved model, capacity class, age and verified state; service them as a pair.
- The holder must expose pack negative, series midpoint and pack positive with a documented 2S connection. A marketplace photo or title does not establish its wiring or rating.
- A single charger must measure both cells and actively balance them, either internally or through a separately reviewed balancing function. TI `BQ25887` remains the preferred first candidate because it integrates both; it does not integrate a system power path.
- A common 2S discharge-protection path must cover pack overvoltage, per-cell undervoltage, overcurrent/short and temperature. The charger alone is not assumed to provide all discharge protection.
- Missing-cell, reversed-cell, mixed-state, hot insertion/removal and USB transitions require hardware-safe behavior. Firmware is monitoring and policy, not the only safety layer.
- The system must regulate from the approximately 6.0-8.4 V 2S pack range. Operation while charging is required by D21; safe charge-under-load termination, exact rails and shutdown thresholds remain engineering gates.

## Candidate references

| Function | Candidate / source | Relevance and limitation |
| --- | --- | --- |
| Balanced 2S USB-input charger | [TI BQ25887](https://www.ti.com/product/BQ25887), Rev B data sheet | 2S boost charger, I2C, per-cell ADC and integrated balancing; TI table 5 confirms no power path; it does not provide common discharge protection |
| NVDC charger alternative | [TI BQ25792](https://www.ti.com/product/BQ25792), Rev C data sheet | Adds batteryless/system power path but has no per-cell balancing; retain only if that product requirement is added |
| Common protection candidate | [TI BQ77307](https://www.ti.com/product/BQ77307), production data | Full 2S protection feature set, but low-volume host configuration and safe startup defaults require review |
| Autonomous protection family | [ABLIC S-8252](https://www.ablic.com/en/semicon/datasheets/power-management-ic/lithium-ion-battery-protection-ic/s-8252/) | Firmware-independent protection candidate, but its typical low-side cutoff conflicts with BQ25887 ground-referenced sensing/balancing; topology and exact suffix require qualified review |
| USB Type-C CC candidate | [TI TUSB320LAI](https://www.ti.com/product/TUSB320LAI), Rev D data sheet | Fixed UFP/sink current-class detection in GPIO mode per D22; no USB PD. The accepted default-current-only policy and remaining charge-enable gates are in [power input evidence](POWER_INPUT_EVIDENCE.md) |
| Previous independent 1S charger | [TI BQ25185](https://www.ti.com/product/BQ25185) | Historical P08 comparison only; no longer the Rev A direction |
| Previous source OR | [ADI LTC4415](https://www.analog.com/en/products/ltc4415.html) | Historical P08 comparison only; removed by the accepted 2S direction |

No exact 2S protection IC/FETs, fuse, holder, thermistor, fuel gauge, buck regulator, USB-C receptacle or input-protection circuit is assigned here. The TUSB320LAI is a CC-policy candidate only. Those parts and values require the selected cells, exact holder evidence, power-path choice and accepted fault-test limits.

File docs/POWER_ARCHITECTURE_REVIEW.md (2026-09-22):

# Power architecture engineering review

Status: **2S direction accepted by owner 2026-09-13; qualified electrical/battery review pending; circuit not frozen**.

## Accepted architecture direction

Use two removable, matched 21700 cells in series. Treat them as one service pair. One balanced 2S charger manages charging, while a separate common 2S protection path guards discharge and fault states. Downstream buck regulators power the system from the 2S pack.

```mermaid
flowchart LR
  USB[USB-C 5 V input and protection] --> CHG[Balanced 2S boost charger candidate]
  H[Documented 2S holder: B- / MID / B+] --> PROT[Common 2S protection and current cutoff]
  H --> CHG
  CHG --> H
  H --> SENSE[Per-cell voltage and NTC sensing]
  PROT --> PACK[Protected 2S bus, approximately 6.0-8.4 V]
  PACK --> BUCK[Reviewed buck rails]
  BUCK --> LOADS[Digital, sensors and switched RF domains]
```

This meets the owner's requirement for two removable cells and one charger/control solution. It does not permit direct parallel connection. Both cells are required for operation; removing either opens the series pack. Use cells of the same qualified model, capacity class, age and verified state, and replace them as a pair.

The [low-cost marketplace holder shown by the owner](https://pt.aliexpress.com/item/1005005491570611.html) is a mechanical sample candidate only. Its listing does not establish a manufacturer, ordering code, current rating, contact material, series wiring or midpoint terminal. Verify continuity with no cells installed, obtain dimensions, inspect polarity markings and contact retention, and reject any two-terminal parallel version. The PCB needs all three 2S nodes: pack negative, midpoint and pack positive.

## First charger candidate

TI `BQ25887RGER` is the first candidate for engineering review. TI data sheet SLUSD89B, revised November 2019 and reviewed 2026-09-13, documents a 2-cell boost-mode Li-ion charger for 3.9-6.2 V USB input, up to 2 A charge current, I2C control at the default seven-bit address `0x6B`, a 16-bit ADC, per-cell measurement, NTC input and automatic balancing up to 400 mA. It is a 24-pin 4 x 4 mm VQFN.

TI's device-comparison table explicitly marks the BQ25887 as **no power path**. The load therefore remains on the protected battery bus; USB does not create an independently regulated system rail and the design does not promise batteryless operation. This is compatible with the accepted requirement that both cells be installed, but charging while the system is operating, termination under load, cold-start with a deeply discharged pack and every USB transition require review and measurement. Do not assume the charger replaces common discharge protection.

### Mandatory charger/protection contradictions found 2026-09-17

These findings prevent schematic capture of Gate 2 until the exact topology is accepted by a qualified electrical/battery reviewer:

1. `BQ25887` can start autonomous charging after power-on. Its `CD` input has an internal 900 kOhm pull-down and the reset configuration includes 4.2 V/cell regulation, 1.5 A charge current, 150 mA termination, JEITA control and a 12 h safety timer. Firmware therefore cannot truthfully promise to inspect missing, reversed or mismatched removable cells *before* any charging unless fail-safe hardware holds `CD` high until validation. The exact gate, default state and recovery path remain open.
2. A conventional low-side `S-8252` cutoff does not combine trivially with the charger's ground-referenced BAT/MID sensing and balancing. Referencing the charger before the cutoff can bypass charge protection; referencing it after the cutoff adds switch-path voltage to cell sensing and can leave BAT/MID paths attached when pack negative opens. The reviewer must choose and prove a high-side or low-side architecture, FET placement, grounds, cutoff recovery and every charger connection before an S-8252 suffix is selected.
3. Charge termination while the system is operating is not proven. The conservative 1.935 W FLIGHT allowance draws about 0.23 A from an 8.4 V pack before conversion details, already above the charger's default 150 mA termination threshold. At a 500 mA USB input limit, little or no net charging may remain after system load. The product must explicitly decide whether charging while operating is required; the circuit and firmware must then prove termination or enforce an accepted charge-only state.

For planning only, 5 V at 3 A can provide at most about 1.67 A at 8.4 V using the BQ25887 data-sheet 93.4% efficiency example and before subtracting system load. This is an upper arithmetic bound, not a selected charge rate.

### 3.3 V I2C evidence

The BQ25887 data-sheet threshold table characterizes SDA/SCL with a 1.8 V pull-up rail, which previously left the proposed 3.3 V shared bus open. TI's own `BQ25887EVM-001` user guide `SLUUC12`, February 2019, closes the voltage-level question: Table 3 identifies an onboard 3.3 V LDO as the pull-up source for SDA, SCL, INT and the other open-drain/status pins, and JP12/JP13 use 10 kOhm pull-ups for SDA/SCL. The 3.3 V bus level is therefore supported by a manufacturer evaluation implementation and remains below the device's 6 V absolute maximum.

This evidence does not select the StratosCore pull-up resistance. The final shared-bus value must be calculated from the total device, trace, connector and expansion capacitance, the slowest permitted rise time and every participant's low-level sink limit. BQ25887 keeps its documented seven-bit address `0x6B`.

### Charger topology comparison refreshed 2026-09-14

| Candidate | What it resolves | Added consequence | Current disposition |
| --- | --- | --- | --- |
| `BQ25887RGER` | 5 V USB boost charging, per-cell ADC and automatic 2S balancing in one 4 x 4 mm device | No integrated power path or batteryless operation; system load can affect charge behavior; separate protection and downstream bucks remain | **Preferred engineering candidate** for the owner's simpler two-cell direction, pending the complete review |
| `BQ25792RQMR` | 3.6-24 V buck-boost charging and an NVDC power path that can run the system from USB with depleted/removed cells | No per-cell balancing; needs separate cell monitor/balancer/protection; 5 A capability and 29-pin 4 x 4 mm implementation add unnecessary scope if batteryless operation is not required | Keep only as an alternative if batteryless USB operation becomes a requirement |

On 2026-09-14 DigiKey displayed 848 `BQ25792RQMR` in stock at EUR 5.18 quantity one with a 12-week standard lead time. The earlier BQ25887 snapshot remains below. Prices use different regional storefronts and are comparison evidence only.

### Common-protection candidates

The charger is not the pack protector. Two candidate families were reviewed without selecting an exact protection circuit:

| Candidate | Evidence | Blocking issue before selection |
| --- | --- | --- |
| TI `BQ77307RGRR` | Active 2S-7S protector; per-cell over/undervoltage, charge/discharge overcurrent, short-circuit, external-NTC limits, open-wire detection and low-side charge/discharge FET drivers; 20-pin 3.5 x 3.5 mm VQFN | Low-volume parts require host-loaded settings after reset/shutdown unless TI supplies a production OTP configuration. A reviewer must prove safe startup defaults, 2S unused-pin connections, FET/sense design and behavior when the host is unavailable |
| ABLIC `S-8252` family | Autonomous six-pin 2S overcharge, overdischarge, discharge/charge overcurrent and short-circuit protection with external FETs | Low-side cutoff conflicts above must be resolved first. `S-8252AAO-M6T1U` is only a comparison point: its full-temperature undervoltage corner can fall below the M50A 2.5 V endpoint and its overvoltage corner approaches the BQ25887 4.2 V regulation. Exact suffix/FETs remain unselected |

DigiKey displayed 2,296 `BQ77307RGRR` at USD 1.95 quantity one on 2026-09-14. ABLIC lists S-8252 as a family with multiple factory configurations; exact authorized stock remains TBD. No S-8252 implementation is preferred until the charger-ground/cutoff conflict, cell limits and reviewer requirements are resolved.

Primary evidence: [BQ25887 Rev B](https://www.ti.com/lit/ds/symlink/bq25887.pdf), especially device comparison table 5 and sections 8.3/9/11; [BQ25887EVM-001 user guide SLUUC12](https://www.ti.com/lit/ug/sluuc12/sluuc12.pdf), especially Table 3 and the schematic; [BQ25792 Rev C](https://www.ti.com/lit/ds/symlink/bq25792.pdf), especially section 9.3.8; [BQ77307 production data](https://www.ti.com/lit/ds/symlink/bq77307.pdf), especially sections 7.3-7.5 and 8; and [ABLIC S-8252 revision 4.0](https://www.ablic.com/en/doc/datasheet/battery_protection/S8252_E.pdf). Distributor snapshots: [DigiKey BQ25792RQMR](https://www.digikey.com/en/products/detail/texas-instruments/BQ25792RQMR/13577777) and [DigiKey BQ77307RGRR](https://www.digikey.com/en/products/detail/texas-instruments/BQ77307RGRR/22119518).

## USB-C input policy candidate (historical I2C proposal, superseded by D22)

`TUSB320LAIRWBR` is the Type-C CC controller candidate for a fixed upstream-facing-port/sink implementation. TI data sheet SLLSEQ8D revision D, reviewed 2026-09-14, documents attach and source-current class without USB Power Delivery. The earlier I2C/`0x47` proposal below is historical: D22 selects GPIO mode, and [power input evidence](POWER_INPUT_EVIDENCE.md) plus the [GPIO map](INTERFACE_GPIO_MAP.md) own the current wiring and conservative default-current policy. The 12-pin RWB X2QFN is 1.6 x 1.6 mm.

The 500 mA BQ25887 hardware default is **not yet an approved USB policy**. The fail-safe design must hold charger `CD` high after reset and keep charging disabled until both the removable-cell validation and the applicable USB attach/enumeration/current rules permit charging. `PSEL` high provides the charger's lower input-current class after enable; firmware may raise `IINDPM` only to a reviewed value no greater than a valid detected advertisement and must disable charging again on detach, reset, invalid state or I2C failure. This controller manages CC only; USB D+/D- remain on the ESP32 native USB path through separately selected ESD protection. No USB PD or input above 5 V is proposed.

Candidate wiring is now bounded: `PORT` to ground fixes UFP mode, `ADDR` to ground selects `0x47`, VDD uses `3V3_MAIN` with 100 nF local bypass, and `VBUS_DET` senses VBUS through 900 kOhm. The controller must remain powered whenever the 3.3 V I2C pull-ups are active. Hardware must default `CD` high and `PSEL` high; only after valid cell checks and an accepted USB current state may software enable the charger, then lower `PSEL` and program `IINDPM` no higher than an accepted 1.5 A or 3 A advertisement. Whether USB 2.0 enumeration is required before any default-current charging remains an explicit review item.

The historical candidate added one I2C address and interrupt/status path; D22 removes that bus connection. `TPS259474LRPWR` is the VBUS eFuse candidate. The current input-path calculations, default-current-only policy and unresolved ITIMER/fault limits are recorded in [power input evidence](POWER_INPUT_EVIDENCE.md); do not implement the historical values in this section as a schematic instruction.

Primary evidence: [TI TUSB320LAI product page](https://www.ti.com/product/TUSB320LAI) and [revision-D data sheet](https://www.ti.com/lit/ds/symlink/tusb320lai.pdf), especially sections 7.2.1.2, 8.2.3 and the RWB package drawing; and [TI TPS25947 product page/data sheet](https://www.ti.com/product/TPS25947). TI lists `TUSB320LAIRWBR` as active; distributor price and factory-assembly availability must be rechecked when the connector and PCBA supplier are selected.

## Cell candidate for review

The exact 21700 model is still open. `Molicel INR-21700-M50A` is the first sample candidate because its official manufacturer sheet matches the 5.0 Ah, 3.6 V planning basis already used in the runtime calculation. The reviewed sheet `INR21700M50A-V1-80097` specifies 5,000 mAh typical/4,800 mAh minimum, 4.2 V charge, 2.5 V discharge limit, 2.5 A standard charge, **20 A continuous discharge**, 25 mOhm typical DC impedance, 0 to 45 °C charging, -30 to 45 °C discharging, 21.7 x 70.2 mm maximum and 68 g typical. It is an unprotected flat-top cell; board protection remains mandatory. Holder contacts, fuse, conductors and reverse-insertion controls must be sized for a deliberately much lower system limit while safely interrupting the cell's available fault energy.

An authorized US specialty distributor displayed the M50A at USD 2.80 sale price and USD 7.99 regular price per cell on 2026-09-14. Brazilian availability, dangerous-goods shipping and authenticity controls remain open. Source: [Molicel M50A manufacturer sheet](https://www.molicel.com/wp-content/uploads/INR21700M50A-V1-80097.pdf) and [authorized-distributor listing](https://liionwholesalecorp.shop/products/molicel-npe-inr-21700-m50a-15a-5000mah-flat-top-21700-battery-authorized-distributor).

This candidate does not set the charge rate or protection thresholds. Mission temperature, runtime at cold soak, holder contact geometry and cell provenance must be accepted before the cell becomes locked.

### Cost and availability comparison checked 2026-09-13

| Architecture/candidate | Prototype parts | Snapshot | Disposition |
| --- | --- | --- | --- |
| Rejected independent 1S P08 | 2x BQ25185 + LTC4415 before gauges/protection | Earlier review: about USD 4.56 for two chargers plus USD 10.89 ORing at quantity one | Rejected by owner as excessive complexity |
| Accepted 2S direction, first charger candidate | 1x BQ25887RGER/RGET before common protection/regulators | Mouser listed 7,531 RGER at USD 5.01; DigiKey listed 235 RGET at USD 6.62; LCSC listed no stock | Candidate is cheaper and smaller than P08; recheck at purchase |

Historical BQ25887 supply sources: [TI BQ25887 product page](https://www.ti.com/product/BQ25887), [Mouser BQ25887 search](https://www.mouser.com/c/ds/?q=BQ25887RGER), [DigiKey BQ25887RGET](https://www.digikey.com/en/products/detail/texas-instruments/BQ25887RGET/10270194), and [LCSC BQ25887RGET](https://www.lcsc.com/product-detail/Battery-Management_Texas-Instruments-BQ25887RGET_C2862617.html).
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

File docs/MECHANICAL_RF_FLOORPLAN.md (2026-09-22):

# Mechanical and RF floorplan study

Status: dimensional feasibility study, not production CAD. Review date: 2026-09-11 UTC.

## Envelope result

The exact 80 x 60 x 32 mm target is not feasible for the accepted two-cell unit with the reviewed dimensional-reference holder and all electronics.

| Item | Verified/planning envelope | Consequence |
| --- | --- | --- |
| Orient display candidate | 50.45 x 69.90 x 4.22 mm | Fits the front of an 84 x 60 mm board in portrait orientation |
| Molicel M50A cell | 21.7 mm diameter x 70.2 mm max | Two bare cells consume 43.4 mm width before separation and contacts |
| Keystone 1123 holder | approximately 82.2 x 45.1 mm; 17.27 mm holder height above PCB listed by distributor | Requires at least about 84 mm board/enclosure length |
| PCB | 1.6 mm candidate | Four-layer stackup; final tolerance open |
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

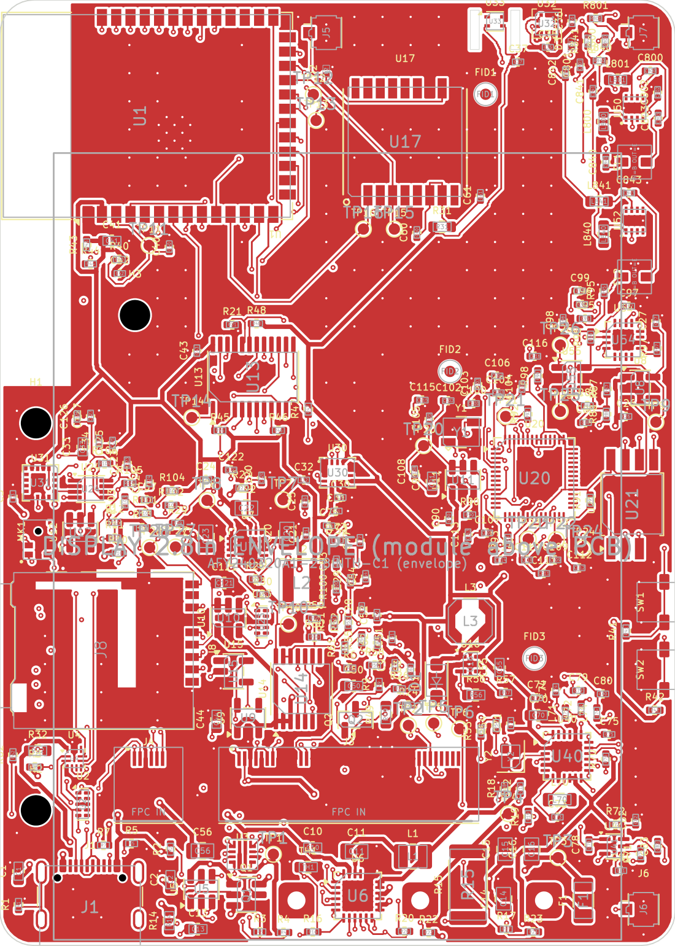
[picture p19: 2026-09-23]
candidates/claude-oneshot-revA/images/pcb_top_copper_silk.png

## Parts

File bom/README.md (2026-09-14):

# Preliminary BOM conventions

[preliminary_bom.csv](preliminary_bom.csv) is a functional planning list with the owner's exact 13 columns. Each locked component or mandatory generic block is represented; open selections are explicit. This is not an orderable or quantity-complete assembly BOM.

`Reference` values are logical block labels, **not assigned schematic reference designators**. `LOCKED` identifies the selected device; `PREFERRED CANDIDATE` identifies an engineering selection with explicit review/test gates; `REQUIRED - MPN TBD` identifies mandatory hardware without a chosen device; `OPEN` identifies a remaining architecture/support choice. The microphone remains required as a provision with optional operation; a later DNP needs a documented decision.

Manufacturer names for selected parts follow the primary source index. Supply ranges and packages remain TBD where a full electrical/package audit has not been completed. Dated distributor evidence populates selected supplier fields, but it is not an approved vendor list or a purchasing commitment. Assembly entries are targets, not a confirmation that a particular factory accepts the part.

Sources: [locked decisions](../docs/DECISIONS.md), [component evidence](../docs/COMPONENT_EVIDENCE.md), [manufacturer index](../hardware/datasheets/README.md), [documentation index](../docs/README.md), and [power candidates](../docs/POWER_ARCHITECTURE_OPTIONS.md). Future complete BOMs need quantities, actual reference designators and sourced ordering suffixes, without modifying this requested preliminary CSV schema casually.

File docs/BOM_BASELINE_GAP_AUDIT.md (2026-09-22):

# Pre-Astra engineering BOM gap audit

Audit date: 2026-09-22  
Scope: `bom/preliminary_bom.csv`, `bom/SOURCING_EVIDENCE.md`, `docs/ASTRA_HANDOFF.md`, and the exact-part/footprint records they cite. This is an audit and closure plan only. It does not select parts, declare DNPs, approve footprints, or change the planning BOM.

## Finding

The current CSV is a functional planning list, not an Astra-ready engineering parts baseline. It has 58 rows and no quantity column. Seven rows have `MPN=TBD`; `CELL_PROTECTION` also contains only competing families rather than an exact orderable code. Thirty-seven rows currently have `JLCPCB/LCSC Part Number=TBD` (recounted by CSV parser and corrected in O27; an older audit-log snapshot said 36). Packages are explicitly TBD for `MCU_MAIN`, `ADSB_MCU`, and the seven MPN-TBD rows; `CELL_HOLDER` has only an approximate envelope and `CELL_PROTECTION` has family-level package alternatives. `PASSIVES_DEBUG` is explicitly incomplete.

Sourcing evidence identifies six dated snapshot groups and 19 authorized-channel-only groups, but does not establish current five-unit PCBA pricing or assembler acceptance. A `TBD` supplier part-number field is a sourcing lookup gap; it is not evidence that the MPN itself is unresolved. Conversely, an exact MPN does not close package, footprint, factory-process, or assembly-status review.

## Exact-part and disposition gaps

| BOM reference(s) | Gap affecting the baseline | Owner and dependency for closure |
| --- | --- | --- |
| `LORA_RF_SUPPORT` | MPN, package, values/topology, quantity, footprint, and sourcing are open. The SX1262 manufacturer reference/revision and the chosen matching/filter/switch/clock support must be fixed from that evidence. | RF owner; depends on selected Semtech reference, accepted stackup inputs, and RF review. |
| `LORA_ANTENNA` | Required antenna has no MPN, package/mechanical definition, sourcing, or quantity. D06 locks U.FL but not the antenna. Regional transmit configuration remains a separate enablement requirement. | RF + mechanical owner; depends on radio topology, enclosure/keepout, and intended regional configuration. |
| `ADSB_ANTENNA` | Required receive antenna and connector/placement have no MPN, package/mechanical definition, sourcing, or quantity. | ADS-B RF + mechanical owner; depends on the independent 1090 MHz RF path, stackup, enclosure, and conducted-test plan. |
| `MICROSD_MEDIA` | Mandatory removable card has no exact MPN, capacity/endurance/qualification, package, sourcing, or quantity. | Storage/test owner; define supported card class and qualification, then source an orderable example. |
| `CELL_HOLDER` | Exact holder MPN/drawing and fit are open. The approximate 82 x 45 mm envelope does not establish cell polarity, B-/MID/B+ continuity, retention, removal behavior, or footprint/mechanical dimensions. | Power + mechanical owner and qualified battery reviewer; depends on D13/D26, cell evidence, protection/charger topology, fault cases, and fit dummy. |
| `CELL_PROTECTION` | “S-8252 family or BQ77307RGRR” is not a selected orderable device or resolved architecture. Package, exact configured suffix, FET/fuse/NTC implementation, quantity, CAD, and sourcing remain open; charger/protector ground and cutoff compatibility is explicitly unresolved. | Power owner + qualified electrical/battery reviewer; must close complete 2S protection and fault review before schematic commitment or prototype energizing. |
| `FUEL_GAUGE` | No MPN, package, measurement/interface plan, footprint, quantity, or sourcing. | Power/firmware interface owner; depends on selected protection topology, cell measurement needs, and documented state-estimation error limits. |
| `PASSIVES_DEBUG` | This aggregate row cannot serve as a baseline line item: exact values, packages, MPNs, references, quantities, footprints, sourcing, and test-pad/probe details are unspecified. It must be decomposed into circuit-derived BOM items after application circuits/networks and DFT are reconciled. | BOM integrator with each circuit owner; depends on reviewed schematic-block applications and O28/DFT access constraints. |
| `MCU_MAIN` | ESP32-S3-WROOM-1-N16R8 is locked, but package/land-pattern identity is `TBD`; the engineering baseline still needs its exact manufacturer package drawing/footprint assignment, planned quantity, and sourcing status. | Compute/CAD owner; use exact Espressif module drawing and independent footprint review. |
| `ADSB_MCU` | RP2040 is locked as the ADS-B baseline, but the CSV leaves package, supplier/source status, and footprint unspecified. The intended bare-device ordering code/package must be made explicit and matched to the boot/clock implementation. | ADS-B digital/CAD owner; depends on DIG-01 circuit and exact Raspberry Pi-supported package/orderable source evidence. |
| `LORA_RF_SUPPORT`, `CELL_PROTECTION`, `FUEL_GAUGE` | These are additional non-exact MPN cases even though only the first and last are literally `TBD`; do not count `CELL_PROTECTION` as resolved based on family alternatives. | Respective RF and power owners above. |

The baseline also lacks an explicit assembly disposition for all optional or conditional hardware. D11 is a microphone provision with optional synchronized audio; `MICROPHONE` and `AUDIO_LEVEL_TRANSLATOR` need an owner-approved FIT/DNP policy and quantity treatment, with O07's switched-domain conflict, acoustic land/port, and footprint gates resolved first. `LORA_SMA_PIGTAIL` and `ADSB_SMA_PIGTAIL` are optional enclosure alternatives and need explicit per-configuration quantities/DNP treatment. The display and touch rows describe two sample-dependent modules and should state whether the baseline quantities are prototype samples, one installed module each, or both. Any other deliberately unpopulated footprints need a recorded DNP reason and assembly/test impact; do not infer DNP from “optional,” “provision,” or a candidate status.

## Footprint and package review gaps

The 17 files under `hardware/footprints` are candidates; parse/export success is not approval. The footprint README identifies independent dimensional second passes for MAX-M10S-00B, ICM-42688-P, MMC5983MA, BMP581, W25Q128JVSIQ, TPD1E0B04DPYR, U.FL-R-SMT-1(60), and ABM8-272-T3. It records assembler/process gates for these candidates. DIG-04 added eight support footprints from the KiCad 10 library; their exact-MPN second pass is still open. Thus no listed candidate should be treated as generally released merely because a file exists.

The footprint README explicitly leaves `USB4105-GF-A`, `BM12B-GHS-TBT`, `SKSCLCE010`, `ST1633I`, and the `MMICT5838-00-012` acoustic land open. Additional exact-package/footprint work remains for the locked ESP32 module and RP2040, SX1262, display/FPC connector pair, display translators, display reset device, LoRa/ADS-B RF candidates and both antennas, microSD socket, ADS-B SAW/LNA/detector/comparator, USB signal ESD and microSD ESD, holder/protection/gauge/charger and the unenumerated passives/test pads. For each block, the baseline needs a specific footprint identity and provenance, exact-MPN-to-pad/package comparison, independent review, and any required assembler mask/paste/courtyard approval. Cable housings, antennas, cells, display modules, and enclosure parts need mechanical/source definitions and quantity/disposition even where they do not receive PCB footprints.

The 37 supplier-ID `TBD` rows are the exact CSV lines to reconcile against the register before the engineering baseline is frozen: `MCU_MAIN`, `DISPLAY_FPC`, `TOUCH_FPC`, `DISPLAY_LEVEL_TRANSLATOR`, `DISPLAY_RESET_TRANSLATOR`, `DISPLAY_BACKLIGHT_DRIVER`, `BUTTON_1`, `BUTTON_2`, `RADIO_LORA`, `LORA_RF_SUPPORT`, `LORA_UFL`, `LORA_ANTENNA`, `GNSS_UFL`, `ADSB_MCU`, `ADSB_BOOT_FLASH`, `ADSB_CLOCK`, `ADSB_ANTENNA`, `ADSB_UFL`, `MICROSD_SOCKET`, `MICROSD_MEDIA`, `MICROPHONE`, `AUDIO_LEVEL_TRANSLATOR`, `USB_C`, `USB_CC_CONTROLLER`, `USB_SIGNAL_ESD`, `MICROSD_SIGNAL_ESD`, `USB_VBUS_PROTECTION`, `CELL_PROTECTION`, `FUEL_GAUGE`, `MAIN_3V3_BUCK`, `QUIET_3V0_LDO`, `LOGIC_1V8_LDO`, `LOAD_SWITCHES`, `EXPANSION_CONNECTOR`, `EXPANSION_HOUSING`, `PASSIVES_DEBUG`, and `GPIO_EXPANDER`. The 19 channel-only groups in `SOURCING_EVIDENCE.md` may cover several rows or repeated instances; check every exact MPN and quantity, and do not treat a group-level channel pointer as a supplier SKU, live stock, quote, factory-library match, or order authorization. `N/A` is appropriate for manual/final-assembly parts but still requires an identified authorized/local procurement path and quantity.

## Quantity, fit/DNP, and costing gaps

There is no planned quantity field or normalized count in the 13-column CSV. Before Astra, each functional block needs an explicit planned quantity or range and configuration basis; after capture, the integrator reconciles those plans to annotated references and final captured quantities. Known multiplicities that must be carried into that reconciliation include two `CELL_PAIR` cells; two `SKSCLCE010` buttons; three `U.FL-R-SMT-1(60)` locations (`LORA_UFL`, `GNSS_UFL`, `ADSB_UFL`); two separate `TPD4E05U06DQARG4` arrays (`USB_SIGNAL_ESD`, `MICROSD_SIGNAL_ESD`); three `TPS22918DBVR` load switches per PWR-04; two `BLB01` and two `TA2003A` instances per ADS-B candidate topology; and two labeled display samples for the sample gate. These are stated in source notes/status and are planning counts, not a released order quantity. RF antenna and pigtail options, microSD media, battery holder/protection/gauge, and passives need their quantities/configurations resolved rather than guessed.

Cost closure must use a dated, named-channel comparison for the initial five-unit target and account for the owner's D24 scope: Chinese assembled PCB plus display/touch, excluding local cells, local enclosure, freight, and taxes. Current sourcing evidence has no complete five-unit quote or verified assembly allocation, and several expensive/risk items lack an LCSC/assembler match. Keep price and stock TBD until a dated quote or displayed listing is recorded; use the 30-day freshness policy in the sourcing register and recheck at purchase. Cost feasibility is an input to baseline review, not a reason to silently substitute a component.

## Closure sequence

1. **Disposition and system inputs — product owner/integrator.** Set the intended baseline configuration and FIT/DNP/optional rules, especially audio, both optional SMA pigtails, display samples versus installed modules, cards, and prototype quantity. Preserve locked requirements. Any proposed baseline change goes through the decision register and owner acceptance.
2. **Close exact MPN and topology — subsystem owners.** Resolve the seven TBD rows and the family-level `CELL_PROTECTION`; explicitly state packages for ESP32-S3 module and RP2040. Power work follows the qualified-review gate; ADS-B/LoRa antenna and support decisions follow their independent RF references and stackup; microSD follows the storage qualification; passives are derived from closed application circuits. Capture exact manufacturer documents and revisions, source URLs, dated review, package drawing and relevant sections.
3. **Build package/footprint evidence — CAD plus independent reviewers.** Assign or create a footprint from the exact ordering code's manufacturer drawing for every fitted PCB component. Complete the DIG-04 exact-MPN second pass, deferred connector/custom lands, all non-candidate packages, and documented assembler process approvals. Record passives and test pads from reviewed blocks/DFT. Keep non-PCB items in the parts baseline with mechanical definition instead of inventing footprints.
4. **Define planned quantities and factory disposition — BOM integrator with block owners.** Expand aggregate rows, count repeated instances, identify alternates as mutually exclusive configurations, and record planned quantity/range plus FIT/DNP and reason. Astra can then assign schematic references; after capture, reconcile annotated references and quantities back to this frozen plan.
5. **Close sourcing and cost evidence — sourcing/manufacturing owner.** Reconcile every exact MPN to authorized channel, exact supplier SKU when applicable, dated stock/price or explicit channel-only status, assembly type, factory library/machine/process acceptance, and five-unit quote/allocation. Record unknowns as TBD; the current supplier-ID count of 37 was verified and reconciled in O27.
6. **Freeze the engineering baseline — integrator and required reviewers.** Produce the reviewed parts baseline with exact fitted/DNP items, passive values/packages, planned quantities, footprint/provenance/review status and sourcing status. Verify that every BOM and handoff entry gate is backed by evidence; only then update the shared workboard/status/handoff and permit Astra entry. The final orderable BOM still follows schematic capture and independent review.

Dependencies: the sequencing intentionally puts product disposition before count freeze, exact parts before footprint approval, and circuit/DFT closure before passives and quantities. The 2S qualified safety review, display controlled drawings/samples, RF review, enclosure fit, assembler process approvals, and unresolved system-interface/OQ work remain upstream blockers where they affect part choice, connectivity, or routing. Astra must not be used to decide those items.

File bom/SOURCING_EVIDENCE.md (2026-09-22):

# Sourcing evidence register (BOM-02, 2026-09-22)

Purpose: consolidate the **dated** sourcing evidence already recorded in this repository per exact MPN, with the authorized-channel pointer for the purchase-time recheck. **No stock or price figure may be entered without a dated, named-channel snapshot; nothing here authorizes an order.** Automated live stock checks were attempted 2026-09-22 and are not reliable for this workflow: LCSC's public search is JavaScript-rendered (no data without a browser session), and the DigiKey/Mouser APIs require project API keys. The owner's purchase-time check therefore remains the authoritative step, per the standing repo rule that supplier IDs, prices and stock are never fabricated.

Evidence classes used below:

- **SNAPSHOT** — a dated stock/price observation already recorded in a repository document (channel and date named).
- **CHANNEL-ONLY** — authorized channel identified; no dated snapshot exists yet; check at purchase.
- **LOCAL** — owner purchases locally by project decision (cells, D26).

## Locked / preferred MPNs with recorded snapshots

| MPN | Role | Class | Last recorded snapshot (channel, date, source doc) | Purchase recheck |
| --- | --- | --- | --- | --- |
| `MAX-M10S-00B` | GNSS | SNAPSHOT | DigiKey/Mouser comparison reviewed 2026-09-11 in `COMPONENT_EVIDENCE.md`; about USD 9.60 above the rejected ATGM at prototype quantity but broader authorized stock | DigiKey/Mouser/u-blox distributor |
| `SX1262IMLTRT` | LoRa radio | CHANNEL-ONLY (ordering code confirmed 2026-09-14, D05) | none recorded | Mouser/DigiKey/LCSC |
| `BQ25887RGER` | 2S charger | SNAPSHOT | Mouser 7,531 @ USD 5.01; DigiKey 235 @ USD 6.62 (2026-09-13, `DECISIONS.md` P14 record); LCSC no stock same date | Mouser/DigiKey; LCSC was empty |
| `TPS62130ARGTR` | Main buck | CHANNEL-ONLY | none recorded | DigiKey/Mouser/LCSC |
| `TPS7A2030PDBVR` / `TPS7A2018PDBVR` | Quiet 3.0 V / 1.8 V LDOs | CHANNEL-ONLY | none recorded | DigiKey/Mouser/LCSC |
| `TPS22918DBVR` (x3) | Load switches | CHANNEL-ONLY | none recorded | DigiKey/Mouser/LCSC |
| `TPS61169DCKR` | Backlight boost | CHANNEL-ONLY | none recorded | DigiKey/Mouser/LCSC |
| `TPS259474LRPWR` | VBUS eFuse | CHANNEL-ONLY | none recorded (PWR-02 closed its application 2026-09-22) | DigiKey/Mouser/LCSC |
| `TUSB320LAIRWBR` | USB-C CC controller | CHANNEL-ONLY | none recorded (D22 GPIO-mode wiring closed 2026-09-22) | DigiKey/Mouser/LCSC |
| `TPD4E05U06DQARG4` | USB signal ESD | CHANNEL-ONLY | none recorded | DigiKey/Mouser/LCSC |
| `W25Q128JVSIQ` | RP2040 flash | SNAPSHOT | DigiKey 57,555 @ USD 4.21 qty 1 (2026-09-14, `DIGITAL_SUPPORT_REVIEW.md`) | DigiKey/Mouser |
| `ABM8-272-T3` | 12 MHz crystal | SNAPSHOT | DigiKey 29,393 @ USD 0.71 qty 1 (2026-09-14, `DIGITAL_SUPPORT_REVIEW.md`) | DigiKey/Mouser |
| `DM3AT-SF-PEJM5` | microSD socket | SNAPSHOT | DigiKey regional ~29,700 @ ~USD 5.20 qty 1 (2026-09-14, `DIGITAL_SUPPORT_REVIEW.md`) | DigiKey/Mouser |
| `MCP6566T-E/OT` | ADS-B comparator | CHANNEL-ONLY | none recorded (pin map frozen 2026-09-22, PR #142; /LT and R/U alternates share stock pools) | DigiKey/Mouser/LCSC |
| `BLB01` (x2) / `TA2003A` (x2) / `ADL5513ACPZ-R7` | ADS-B RF chain | CHANNEL-ONLY | none recorded (BeRex/TAI-SAW are narrower channels; ADI via DigiKey/Mouser) | BeRex/TAI-SAW distribution; ADI franchised distributors |
| `MMICT5838-00-012` | PDM microphone | SNAPSHOT | DigiKey 73,381 in stock (2026-09-14, `AUDIO_ARCHITECTURE.md`) | DigiKey |
| `TXU0202DCUR` | Level translator | CHANNEL-ONLY | none recorded | DigiKey/Mouser/LCSC |
| `USB4105-GF-A` | USB-C receptacle | CHANNEL-ONLY | none recorded (GCT direct + distis) | GCT/DigiKey/Mouser |
| `BM12B-GHS-TBT` / `GHR-12V-S` / `SSHL-002T-P0.2` | Expansion connector set | CHANNEL-ONLY | none recorded (JST direct + distis) | JST/DigiKey/Mouser |
| `SKSCLCE010` (x2) | Buttons | CHANNEL-ONLY | none recorded (Alps direct + distis; guide-boss `SKSCLDE010` alternate needs its own check) | Alps/DigiKey/Mouser |
| `TCA9535PWR` | I2C expander | CHANNEL-ONLY | none recorded | DigiKey/Mouser/LCSC |
| `TPD1E0B04DPYR` (GNSS feed; + SD/USB ESD arrays) | ESD | CHANNEL-ONLY | none recorded | DigiKey/Mouser/LCSC |
| `FXP611.07.0092C` + `U.FL-R-SMT-1(60)` | GNSS antenna + receptacle | CHANNEL-ONLY | none recorded (Taoglas/Hirose direct + distis) | Taoglas/Hirose/DigiKey |
| `CAB.721` | ADS-B/LoRa SMA pigtail | CHANNEL-ONLY | none recorded | Taoglas |
| `INR-21700-M50A` (matched pair) | Cells | **LOCAL** | Owner purchases locally (D26); Brazilian sourcing evidence remains an engineering input to PWR-01/O05 | local purchase + holder fit check |
| Display `AFY240320A1-2.8INTH-C1` + samples | Display | CHANNEL-ONLY | DigiKey exact-part listing checked 2026-09-14 for price/availability context (`DISPLAY_REQUIREMENTS.md`); two traceable samples are EXT-01 | DigiKey/Orient direct |

## Known TBD-MPN rows (BOM-01 territory, listed for completeness)

The seven `MPN=TBD` planning-BOM rows and the passives baseline remain BOM-01/BOM-03 work after subsystem closure; no sourcing claim is made for them here.

## Rules reaffirmed

1. Every purchase uses the exact ordering code above — suffixes are engineering choices (see MCP6566 pin-map record).
2. Stock/price figures older than 30 days are context, not availability promises; recheck at purchase.
3. New snapshots must carry channel, date and quantity/price exactly as displayed; screenshots or copied numbers without a channel/date do not enter the register.
4. LCSC (assembly house) sourcing is desirable for PCBA pricing but requires a browser-session check or the assembler's own BOM tool at order time.

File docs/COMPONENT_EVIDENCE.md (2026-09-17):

# Component evidence and sourcing review

Last updated: 2026-09-17. Prices and stock retain their dated snapshots and are not purchase commitments. Manufacturer documents control electrical and mechanical data; distributor pages are used only for orderability and dated availability.

## Display selection for validation

**Selected sample candidate:** Orient Display `AFY240320A1-2.8INTH-C1`.

The exact [Orient AFY240320A1-2.8INTH-C1 specification](https://www.orientdisplay.com/wp-content/uploads/2021/11/AFY240320A1-2.8INTH-C1.pdf), revision J dated 2021-07-20, was reviewed on 2026-09-14. It satisfies the locked 2.8-inch, 240 x 320 IPS and capacitive-touch requirement and identifies ST7789VI or compatible display control, ST1633I touch, RGB/MCU/SPI interfaces, 900 cd/m2 typical luminance and a 50.45 x 69.90 x 4.22 mm module envelope.

The exact document specifies a 40-contact TFT interface and a separate six-contact CTP interface. TFT VDDIO is 1.8 V, so ESP32 3.3 V signals cannot drive the display directly. P21 now proposes `XF3M-4015-1B`/`XF3M-0615-1B` connectors, `SN74AXC4T245PWR` plus `SN74LVC1G07DBVR` translation and `TPS61169DCKR` backlight drive from `3V3_MAIN`. Touch accepts a 3.3 V supply/I/O. Orient publishes I2C value `0x70` but does not state whether that is a seven-bit address or an eight-bit write byte; the convention remains sample/controller gated. All support parts remain candidates until the drawing, samples, independent CAD and prototype tests close.

Availability checked 2026-09-14: the Orient store page displayed 50 units at USD 35.36 each, USD 31.39 at 25-49 and USD 27.42 at 50+. The [DigiKey exact-part listing](https://www.digikey.com/en/products/detail/orient-display/AFY240320A1-2-8INTH-C1/22531939) displayed zero immediately available, one expected 2026-10-19, USD 31.55 at quantity one and an eight-week manufacturer lead time. Recheck before purchase.

Remaining gate before connector/footprint release:

1. Obtain a controlled Orient drawing that resolves the revision-J document/revision-G embedded drawing and terminal ambiguities.
2. Buy two labeled C1 samples and verify controller identity, FPC geometry, XF3M insertion/retention and continuity.
3. Independently review the proposed connectors, 1.8 V rail, AXC/LVC translators, reset sequence and TPS61169 circuit/footprints.
4. Confirm write-only three-line or four-line SPI, exact straps and unused-pin handling with Orient/sample evidence.
5. Measure backlight voltage/current, faults, PWM/EMI/temperature, sleep leakage, touch address, sunlight readability, orientation and shared-bus behavior.

See [display interface specification](DISPLAY_REQUIREMENTS.md) for the controlled pin tables and acceptance plan. The exact module document releases electrical planning but does not yet authorize connector footprints.

## GNSS finding and replacement proposal

The locked `ATGM332D-5NR32` is orderable as LCSC `C3037611`. LCSC listed 1,454 units and USD 1.8239 at quantity one, USD 1.5071 at quantity 100 and USD 1.4386 at quantity 1,000 on the review date.

The full 18-page manufacturer manual resolves the earlier constellation discrepancy: its technical table lists BDS, GPS, GLONASS, Galileo, QZSS and SBAS, 1 Hz default with 10 Hz maximum, NMEA0183, 2.7-3.6 V supply, less than 26 mA at 3.3 V, 15.9 x 12.1 x 2.4 mm and a maximum altitude of **18,000 m**. That altitude ceiling is below ordinary high-altitude balloon missions and conflicts with StratosCore's balloon use case. The exact part can remain suitable for ground, handheld and normal flight profiles, but cannot be the only Rev A navigation source if operation above 18 km is required.

### Accepted replacement: u-blox `MAX-M10S-00B`

| Required comparison | ATGM332D-5NR32 | MAX-M10S-00B | Impact |
| --- | --- | --- | --- |
| Reason | Locked low-cost choice; 18 km ceiling | Airborne modes rated to 80 km | Removes a mission-stopping balloon limitation |
| Supply, 2026-09-11 UTC | LCSC: 1,454 | DigiKey: 6,600; Mouser pages showed over 22,000 | Both available; u-blox has broader authorized distribution evidence |
| Unit price | LCSC USD 1.8239 at 1 | DigiKey USD 11.42 at 1, USD 9.32826 at 500 | About USD 9.60 higher at prototype quantity |
| Constellations/rate | Six systems listed; 1 Hz default, 10 Hz maximum | GPS, Galileo, GLONASS, BeiDou/QZSS; 3-10 Hz default and 10-20 Hz high-performance depending on constellation set | Firmware configuration changes; desired Galileo is explicit |
| Electrical | 2.7-3.6 V, under 26 mA at 3.3 V | 1.76-3.6 V, about 25 mW continuous tracking; UART and I2C | Lower typical GNSS power; new backup/antenna and startup review |
| PCB/mechanical | 15.9 x 12.1 x 2.4 mm | 9.7 x 10.1 x 2.5 mm, 18-pad LCC | New verified symbol/footprint; saves board area; not pin-compatible |
| Firmware | NMEA/commands for CASIC module | UBX configuration plus NMEA/UBX parsing | New driver and airborne dynamic-model configuration |

Primary sources for the accepted module were refreshed on 2026-09-13: [u-blox MAX-M10S data sheet UBX-20035208 R08, 2026-01-30](https://content.u-blox.com/sites/default/files/MAX-M10S_DataSheet_UBX-20035208.pdf), [u-blox integration manual UBX-20053088 R05, 2026-04-28](https://content.u-blox.com/sites/default/files/MAX-M10S_IntegrationManual_UBX-20053088.pdf), and [u-blox M10 SPG 5.10 interface description UBX-21035062 R03](https://content.u-blox.com/sites/default/files/u-blox-M10-SPG-5.10_InterfaceDescription_UBX-21035062.pdf). Historical ATGM evidence remains the [ATGM332D-5NR32 manual](https://datasheet.lcsc.com/lcsc/2206231830_ZHONGKEWEI-ATGM332D-5NR32_C3037611.pdf). Supply sources for the dated comparison were [LCSC C3037611](https://www.lcsc.com/product-detail/Satellite-Positioning-Modules_ZHONGKEWEI-ATGM332D-5NR32_C3037611.html) and [DigiKey MAX-M10S-00B](https://www.digikey.com/en/products/detail/u-blox/MAX-M10S-00B/15712906).

The project owner accepted this replacement on 2026-09-13. D07 is now locked to MAX-M10S-00B.

### MAX-M10S-00B application evidence reviewed 2026-09-13

- **Exact identity verified:** the ordering code is global professional-grade `MAX-M10S-00B`; data-sheet R08 applies to mass-production type number `MAX-M10S-00B-01` with ROM SPG 5.10 firmware. The `-01` type suffix is not a replacement ordering code.
- **Pin map verified:** 18 LCC contacts are GND, TXD, RXD, TIMEPULSE, EXTINT, V_BCKP, V_IO, VCC, RESET_N, GND, RF_IN, GND, LNA_EN, VCC_RF, VIO_SEL, SDA, SCL, and SAFEBOOT_N in pins 1 through 18 respectively. TIMEPULSE and SAFEBOOT_N are internally linked through 1 kOhm.
- **Supply facts verified:** VCC is 1.76-3.6 V; V_IO is 1.76-1.98 V with VIO_SEL grounded or 2.7-3.6 V with it open; V_BCKP is 1.65-3.6 V. Startup inrush can reach 100 mA, VCC series resistance must not exceed 0.2 ohm, and PIOs must not be driven when VCC/V_IO are off in hardware backup.
- **Interface facts verified:** UART has no hardware flow control and defaults to 9600 baud 8N1; Rev A maps module TXD to ESP32 GPIO18, RXD from GPIO17, and TIMEPULSE to GPIO21. I2C remains unused; if reconsidered, its default seven-bit address is 0x42 and it is Fast-mode peripheral-only with up to 20 ms clock stretching.
- **Reset/enable facts verified:** RESET_N has an internal pull-up, needs at least 1 ms low, must not have a capacitor to ground, and clears BBR/RTC/orbit data. There is no dedicated enable pin. EXTINT is a configurable wake/power-save input, not a supply enable.
- **RF facts verified:** RF_IN is internally DC blocked and 50 ohms. The module includes a Band 13 notch, LNA and SAW filter. Passive antennas need no additional RF front-end in the typical u-blox design; an active antenna requires a selected bias/supervisor implementation.
- **Footprint source verified:** data-sheet R08 Figure 4 controls the module package; integration-manual R05 Figure 30/Table 44 controls copper and solder-mask openings and Figure 31/Table 45 the recommended T-shaped paste. The recommended stencil is 150 micrometers. No generic KiCad footprint has been accepted.
- **Firmware constraint verified:** the module defaults to the portable dynamic model. Balloon operation must set and verify `CFG-NAVSPG-DYNMODEL=AIR4` (value 8) after cold start; fitting the module alone does not select its 80 km Airborne 4 g envelope.

The exact symbol map and manufacturer CAD source are released for project symbol/footprint construction. Circuit entry remains gated by acceptance of P20, the system 3.3 V PDN, calculated production-stackup impedance, and independent footprint review. See [GNSS architecture](GNSS_ARCHITECTURE.md).

### Proposed MAX-M10S application and passive RF package, P20

The simplest compatible Rev A arrangement is now the preferred P20 application for RF/PDN review: tie VCC and V_IO to the always-on-during-system-operation 3.3 V rail, leave VIO_SEL open, and leave V_BCKP, RESET_N, EXTINT, LNA_EN and VCC_RF open. The host UART starts at 9600 8N1, identifies the receiver, changes to 115200, verifies the configuration and sets `AIR4` on every cold start. TIMEPULSE remains the 1 PPS input on ESP32 GPIO21, which must be high-impedance during receiver startup. This choice avoids an independent GNSS load switch, unpowered-UART backfeed case, backup-source lifetime path and destructive hardware-reset side effects. It accepts cold-start TTFF and continuous GNSS rail power whenever the product is on.

The proposed RF chain is passive Taoglas `FXP611.07.0092C` to Hirose `U.FL-R-SMT-1(60)`, then a short calculated 50-ohm trace with a shunt TI `TPD1E0B04DPYR` adjacent to the connector, ending at RF_IN. No DC bias, external LNA or external SAW filter is included. The antenna covers 1559-1610 MHz, is 38 x 37 x 0.15 mm with a 92 mm factory cable and I-PEX MHF I/U.FL-compatible plug, weighs 0.9 g and requires a 40 x 40 mm area plus at least 10 mm clearance from metal or the main device ground plane. Taoglas' 80% efficiency result used a 30 x 30 cm ABS test fixture; it is evidence of the part, not a predicted StratosCore result.

| Item | Dated availability/cost snapshot, 2026-09-14 | Electrical impact | Firmware impact | PCB/mechanical impact |
| --- | --- | --- | --- | --- |
| `MAX-M10S-00B` | [DigiKey/Findchips](https://www.findchips.com/search/MAX-m10S) showed about 6,431 units at USD 11.42 each | Tied 3.3 V VCC/V_IO; source must tolerate 100 mA startup and <=0.2 ohm series path | Replay/verify UART configuration and `AIR4`; qualify PPS validity | Independent 18-LCC footprint review remains |
| `FXP611.07.0092C` | [DigiKey](https://www.digikey.com/en/products/detail/taoglas-limited/FXP611-07-0092C/3945623) showed 2,666 units at USD 8.59 each; [Mouser](https://www.mouser.com/es/ProductDetail/Taoglas/FXP611.07.0092C) showed 919 at USD 9.16 | Passive 50-ohm load; no antenna supply or supervisor | No active-antenna control; monitor C/N0 and fix quality | Manual enclosure assembly; reserve 40 x 40 mm, 10 mm clearance, 92 mm cable and strain relief |
| `U.FL-R-SMT-1(60)` | [Mouser](https://www.mouser.com/en/ProductDetail/Hirose-Connector/U.FL-R-SMT-160) showed 35,073 units at USD 1.55 each; [DigiKey search](https://componentsearchengine.com/prices/U.FL-R-SMT-1%2860%29?manufacturer=Hirose) showed 24,719 at USD 1.22 | 50-ohm internal interconnect; no DC bias; 30 mating-cycle rating | None | Exact Hirose PCB/mask/no-trace geometry and cable-tool access require independent review |
| `TPD1E0B04DPYR` | [LCSC C1975594](https://www.lcsc.com/product-detail/ESD-and-Surge-Protection-TVS-ESD_Texas-Instruments-TPD1E0B04DPYR_C1975594.html) showed 5,105 units at USD 0.1895 each at quantity five; [Mouser](https://www.mouser.it/it/ProductDetail/Texas-Instruments/TPD1E0B04DPYR) showed 31,687 at EUR 0.525 each | 0.18 pF maximum shunt capacitance; +/-8 kV IEC contact rating; insertion/return loss must be modeled/measured | None | Corrected DPY SMD land parses/exports; obtain assembler mask-web approval, place beside U.FL with a very short ground and independently VNA-check the path |

The antenna alternative explicitly rejected for this proposal is a board-mounted ceramic patch such as u-blox manual R05's Taoglas `CGGBP.18.4.A.02` example. Its controlled Taoglas data uses a centered 70 x 70 mm symmetric ground plane, which does not fit the current 84 x 60 mm PCB plan without a new tuned integration. Active antennas add bias, short/open supervision and LNA-mode configuration; their added complexity is not justified until the passive flex candidate fails measured enclosure/coexistence tests.

P20 does not release schematic or footprint capture. Owner/RF acceptance, antenna fit, system-PDN review, calculated 50-ohm geometry, TI S-parameter analysis, VNA verification, independent CAD comparison and coexistence tests remain mandatory. Prices and stock are volatile and must be rechecked at purchase.

## Locked sensor audit

The four locked sensor families were checked against primary documents and current distributor listings. MMC5983MA, BMP581 and SHT40 have document evidence sufficient for gated schematic entry. TDK DS-000347 v1.9, dated 2024-11-12 and published by TDK on 2026-06-01, now directly confirms the ICM-42688-P pin table, application circuit and package dimensions. Its revision history records a pin-out figure update in v1.7, notch-filter/CLKDIV changes in v1.8 and removal of Raise to Wake/Sleep plus a reference update in v1.9; use the v1.9 axes drawing in firmware and CAD. The proposed common implementation is 3.3 V I2C at an initial 400 kHz bus rate, with a direct ESP32 interrupt only for the ICM-42688-P. BMP581 and MMC5983MA are scheduled/polled; SHT40 is sampled slowly at the board edge. This is proposal P13 and still requires thermal, magnetic, pressure-port and bus-loading measurements.

| Device | Exact electrical/package evidence | Supply snapshot, 2026-09-11 UTC | CAD consequence |
| --- | --- | --- | --- |
| `ICM-42688-P` | 1.71-3.6 V VDD/VDDIO; 14-LGA 2.5 x 3.0 x 0.91 mm; 0.5 mm pitch; I2C address 0x68 with AD0 low; WHO_AM_I 0x47; 1 MHz I2C maximum | DigiKey: zero stock, USD 4.91 at one and 45-week standard lead; recent LCSC `C1850418`: 336 and USD 19.2845 at one | Pin map/application entry released from v1.9. Use 0.1 µF + 2.2 µF on VDD and 10 nF on VDDIO; route INT1 directly. Manufacturer-derived footprint candidate uses the 0.475 x 0.25 mm nominal terminals and current AN-000393 mask/stencil rules and passed an independent dimensional second pass; obtain assembler mask/paste approval and complete final layout review; do not reuse the larger generic KiCad LGA pads. |
| `MMC5983MA` | 2.8-3.6 V; 16-LGA 3 x 3 x 1 mm; I2C/SPI; ±8 G and 18-bit output; I2C up to 400 kHz | DigiKey: 39,571 and USD 3.32 at one | Use I2C address 0x30 and keep the device away from cells, inductors and high-current loops. Verify SET/RESET behavior and calibration on hardware. |
| `BMP581` | VDD 1.71-3.6 V, VDDIO 1.08-3.6 V; 10-LGA 2 x 2 x 0.75 mm; 300-1250 hPa; I2C/SPI/I3C | DigiKey: 27,077 and USD 3.07 at one | Use I2C, tie CSB to VDDIO and all VSS pads to ground. If either rail ramps in under 10 µs, Bosch Figure 28 requires 10 Ω in series with VDD and 100 Ω with VDDIO. Ground unused INT only with the matching register configuration. |
| `SHT40-AD1B-R2` | Exact selected suffix; 1.08-3.6 V; four-pad DFN 1.5 x 1.5 x 0.5 mm; I2C address 0x44; ±1.8 %RH and ±0.2 °C typical accuracy class | DigiKey: 28,262 and USD 1.88 at one | Do not place copper or solder beneath the center die area. Put it at the vented board edge and use the heater only for controlled condensation recovery; data sheet maximum heater duty is below 10%. |

Primary sources: [TDK ICM-42688-P DS-000347 v1.9](https://d17t6iyxenbwp1.cloudfront.net/s3fs-public/2026-06/DS-000347%20ICM-42688-P%20v1.9.pdf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), dated 2024-11-12, and [AN-000393 v2.4](https://d17t6iyxenbwp1.cloudfront.net/s3fs-public/2026-06/AN-000393%20TDK%20InvenSense%20IMU%20PCB%20Design%20and%20MEMS%20Assembly%20Guidelines%20v2.4.pdf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), dated 2026-02-09, visually reviewed 2026-09-14; [MEMSIC MMC5983MA Rev A](https://www.memsic.com/Public/Uploads/uploadfile/files/20220119/MMC5983MADatasheetRevA.pdf); [Bosch BMP581](https://www.bosch-sensortec.com/media/boschsensortec/downloads/datasheets/bst-bmp581-ds004.pdf); and [Sensirion SHT4x v7.3](https://sensirion.com/media/documents/33FD6951/6A7C10A0/HT_DS_Datasheet_SHT4x_V7.3.pdf). Supply sources: [DigiKey ICM-42688-P](https://www.digikey.com/en/products/detail/tdk-invensense/ICM-42688-P/11679713), [LCSC C1850418](https://www.lcsc.com/product-detail/C1850418.html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), [DigiKey MMC5983MA](https://www.digikey.com/en/products/detail/memsic-inc/MMC5983MA/10452801), [DigiKey BMP581](https://www.digikey.com/en/products/detail/bosch-sensortec/BMP581/16036134), and [DigiKey SHT40-AD1B-R2](https://www.digikey.com/en/products/detail/sensirion-ag/SHT40-AD1B-R2/13532084).

ICM-42688-P availability is volatile and the two distributor snapshots disagree materially with older cached listings. No silent substitute is authorized. Recheck authorized stock immediately before prototype ordering; any alternate IMU requires the full replacement record defined in `AGENTS.md`.

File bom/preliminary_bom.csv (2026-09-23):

Functional Block | Reference | Manufacturer | MPN | Function | Interface | Voltage | Package | Preferred Supplier | JLCPCB/LCSC Part Number | Assembly Type | Status | Notes
Compute | MCU_MAIN | Espressif Systems | ESP32-S3-WROOM-1-N16R8 | Main processor; integrated Wi-Fi/BLE | USB; SPI; I2C; UART; I2S | TBD | TBD | TBD | TBD | SMT/PCBA target - verify | LOCKED | Includes 16 MB Flash; 8 MB PSRAM and PCB antenna. No bare SoC substitution.
User interface | DISPLAY | Orient Display | AFY240320A1-2.8INTH-C1 | 2.8-inch IPS LCD; 320 x 240 | Write-only 3-line 9-bit SPI candidate; RGB/MCU also supported | TFT 2.4-3.6 V typ 2.8 V; VDDIO 1.8 V; backlight 5.8-6.4 V at 100 mA typ | 50.45 x 69.90 x 4.22 mm module; 40-contact 0.5 mm FPC; XF3M-4015-1B candidate | DigiKey / Orient Display | N/A | Manual/final assembly target | SELECTED FOR SAMPLE - 3-LINE STRAPS VERIFIED / FOOTPRINT HOLD | ST7789VI or compatible; Rev-J 3-line strap IM2/IM1/IM0=101 and <=15 MHz provisional clock. Controlled TFT-power/FPC clarification, samples and independent CAD/test remain.
User interface | TOUCH | Orient Display / Sitronix | Integrated in AFY240320A1-2.8INTH-C1; ST1633I | Capacitive touchscreen/controller | I2C | Supply 2.8-3.6 V typ 3.3 V; I/O 1.6-3.6 V | Integrated CTP; separate 6-contact 0.5 mm FPC; XF3M-0615-1B candidate | DigiKey / Orient Display | N/A | Manual/final assembly target | SELECTED FOR SAMPLE - ELECTRICAL REVIEWED / FOOTPRINT HOLD | Orient publishes I2C value 0x70 without identifying seven-bit versus eight-bit-write convention; active-low reset/interrupt. Confirm controller, address and geometry on two samples.
User interface | DISPLAY_FPC | Aratas / Omron | XF3M-4015-1B | 40-contact TFT FPC connector | TFT parallel/serial contacts | Display-side signals up to 3.3 V; logic translation required | 0.5 mm pitch dual-contact right-angle backlock; 40 positions | DigiKey / authorized source | TBD | SMT/PCBA target - verify | PREFERRED CANDIDATE - LAND DOCUMENTED / SAMPLE HOLD | Omron lands documented; Orient tail tolerance, controlled drawing, sample insertion/retention and independent footprint remain.
User interface | TOUCH_FPC | Aratas / Omron | XF3M-0615-1B | 6-contact touch FPC connector | I2C; reset; interrupt; power | 3.3 V touch domain | 0.5 mm pitch dual-contact right-angle backlock; 6 positions | DigiKey / authorized source | TBD | SMT/PCBA target - verify | PREFERRED CANDIDATE - LAND DOCUMENTED / SAMPLE HOLD | Omron lands documented; ambiguous Orient CTP tip width/contact geometry, sample insertion/retention and independent footprint remain.
User interface | DISPLAY_LEVEL_TRANSLATOR | Texas Instruments | SN74AXC4T245PWR | Four-channel 3.3-to-1.8 V write-only TFT branch translation | SPI SCLK/MOSI/CS; one spare channel | 0.65-3.6 V dual supply; proposed 3.3 V to 1.8 V | TSSOP-16 PW | Authorized TI source | TBD | SMT/PCBA target - verify | PREFERRED CANDIDATE - THREE-LINE MODE / SEQUENCE REVIEW | Fixed A-to-B three-line proposal; both OE inputs default disabled. Validate <=15 MHz mode, rail sequence and samples.
User interface | DISPLAY_RESET_TRANSLATOR | Texas Instruments | SN74LVC1G07DBVR | Open-drain 3.3-to-1.8 V TFT reset translation | GPIO/reset | 1.65-5.5 V supply; 5.5 V tolerant input | SOT-23-5 DBV | Authorized TI source | TBD | SMT/PCBA target - verify | PREFERRED CANDIDATE - RESET REVIEW | Powered from 1V8_LOGIC with output pull-up; verify reset assertion through every rail state.
User interface | DISPLAY_BACKLIGHT_DRIVER | Texas Instruments | TPS61169DCKR | Boost constant-current LCD backlight driver | PWM enable/dimming | 2.7-5.5 V input from 3V3_MAIN; up to 38 V output | SC70-5 DCK | Authorized TI source | TBD | SMT/PCBA target - verify | PREFERRED CANDIDATE - PROTOTYPE REQUIRED | Initial 2.21 ohm >=0.1 W gives about 92.3 mA typical. Start with LPS4018-103MRC and 50 V output capacitor; PWR-04 (PR #157) confirmed the RSET value by TPS61169 Rev B (SNVSA40B) Eq. 2 arithmetic; exact 60 V-class Schottky and sample/fault tests remain.
User interface | BUTTON_1 | Alps Alpine | SKSCLCE010 | First physical side-push button; ESP32 recovery dual use | GPIO0 active low | 3.3 V logic | Side-push SMT; 3.5 x 3.55 x 1.25 mm | Authorized Alps Alpine source | TBD | SMT/PCBA target - verify | PREFERRED CANDIDATE - MECHANICAL / FOOTPRINT REVIEW | 1.6 N; 100,000 cycles. Verify enclosure plunger, debounce/ESD and intentional ROM-boot behavior.
User interface | BUTTON_2 | Alps Alpine | SKSCLCE010 | Second physical side-push button | GPIO48 active low | 3.3 V logic | Side-push SMT; 3.5 x 3.55 x 1.25 mm | Authorized Alps Alpine source | TBD | SMT/PCBA target - verify | PREFERRED CANDIDATE - MECHANICAL / FOOTPRINT REVIEW | Same part as button 1; verify enclosure actuation and no accidental loading.
LoRa | RADIO_LORA | Semtech | SX1262IMLTRT | 915 MHz class LoRa transceiver | SPI | 1.8-3.6 V; PA fed from VBAT per Rev 1.2 Section 5.1 | QFN-24; 4 x 4 mm | DigiKey / authorized Semtech source | TBD | SMT/PCBA target - verify | LOCKED - ORDERING CODE CONFIRMED 2026-09-14 | Direct PCB integration; no E220/E32; use Semtech RF reference; regional settings configurable. TX current per Rev 1.2 Table 3-6: 118 mA typical at +22 dBm (915 MHz), 90 mA at +20 dBm, 63 mA at +14 dBm; RX 4.2 mA DC-DC. DigiKey snapshot 2026-09-14: 37,715 units at USD 9.04, 8-week lead. Exact suffix for PCBA reel supply to be rechecked at order.
LoRa | LORA_RF_SUPPORT | TBD | TBD | Matching/filter/switch and RF clock support | RF; control | TBD | TBD | TBD | TBD | SMT/PCBA target - verify | OPEN | Select exact Semtech 915 MHz reference revision; values and topology TBD.
LoRa | LORA_UFL | Hirose Electric | U.FL-R-SMT-1(60) | Internal PCB RF receptacle | 50-ohm RF | Passive RF path | SMT U.FL; HRS CL0331-0472-2-60 | Mouser / authorized Hirose source | TBD | SMT/PCBA target - verify | PREFERRED CANDIDATE - CAD DIMENSIONS REVIEWED / RF-PROCESS GATED | Locked U.FL family. Exact drawing 0001257918 copper/metal-mask and board-cut-out rule reviewed; 30 mating cycles; assembler process, RF and tool access remain.
LoRa | LORA_SMA_PIGTAIL | Taoglas | CAB.721 | Optional U.FL to enclosure SMA female bulkhead cable | 50-ohm RF | Passive RF path | 100 mm 1.32 mm coax; right-angle U.FL to SMA female bulkhead | DigiKey / Mouser | N/A | Manual/final assembly target | PREFERRED OPTIONAL CANDIDATE - MECHANICAL / RF REVIEW | Use only when an external LoRa SMA is required; validate loss, bend, wall stack, torque and labeling.
LoRa | LORA_ANTENNA | TBD | TBD | 915 MHz class antenna | RF | TBD | TBD | TBD | TBD | Manual/final assembly target | REQUIRED - MPN TBD | Mechanical selection and regional operating configuration TBD.
GNSS | GNSS_PREVIOUS | Hangzhou Zhongke Microelectronics | ATGM332D-5NR32 | Superseded GNSS reference | UART; I2C listed | 2.7-3.6 V | 15.9 x 12.1 x 2.4 mm module | LCSC | C3037611 | Do not fit | REJECTED / SUPERSEDED | Owner accepted MAX-M10S-00B on 2026-09-13 because this module's 18,000 m limit conflicts with balloon use.
GNSS | GNSS_RX | u-blox | MAX-M10S-00B | Rev A high-altitude GNSS receiver | UART; 1 PPS | 1.76-3.6 V; P20 proposes tied always-on 3.3 V VCC/V_IO | 18-pad LCC; 9.7 x 10.1 x 2.5 mm | DigiKey / Mouser | N/A | SMT/PCBA target - verify | LOCKED - OWNER ACCEPTED / CAD DIMENSIONS REVIEWED | 80,000 m airborne modes. Manufacturer-derived copper/mask/T-paste footprint passed geometry audit and independent dimensional review; assembler paste approval remains. P20 proposes VIO_SEL open; V_BCKP/RESET_N/EXTINT/LNA_EN/VCC_RF open; UART GPIO17/18 and PPS GPIO21; RF/PDN review remains.
GNSS | GNSS_ANTENNA | Taoglas | FXP611.07.0092C | Passive internal GNSS L1 flex antenna with factory coax/plug | RF; passive; I-PEX MHF I / U.FL compatible | No DC bias | 38 x 37 x 0.15 mm flex; 40 x 40 x 0.2 mm required area; 92 mm cable | DigiKey / Mouser | N/A | Manual/final assembly target | PREFERRED CANDIDATE P20 - RF / FIT TEST | 1559-1610 MHz GPS/Galileo/GLONASS/BeiDou; at least 10 mm from metal/main ground. Published performance used a 30 x 30 cm ABS fixture; verify actual enclosure, cable relief and coexistence.
GNSS | GNSS_UFL | Hirose Electric | U.FL-R-SMT-1(60) | Internal board receptacle for the GNSS antenna cable | 50-ohm RF | No DC bias in P20 | SMT U.FL receptacle; HRS CL0331-0472-2-60 | DigiKey / Mouser | TBD | SMT/PCBA target - verify | PREFERRED CANDIDATE P20 - CAD DIMENSIONS REVIEWED / RF-PROCESS GATED | Exact drawing 0001257918 copper/metal-mask and board-cut-out rule independently reviewed; 30 mating cycles; validate assembler process, RF layout and tool/cable access.
GNSS | GNSS_ESD | Texas Instruments | TPD1E0B04DPYR | Shunt ESD protection at GNSS U.FL feed | RF to GND | 3.6 V working; passive RF line | DPY X1SON-2; 1.0 x 0.6 mm | LCSC / DigiKey / Mouser | C1975594 | SMT/PCBA target - verify | PREFERRED CANDIDATE P20 - MANUFACTURER FOOTPRINT CORRECTED / ASSEMBLER GATE | 0.18 pF maximum. TI SMD copper/mask/paste geometry corrected 2026-09-17; obtain assembler mask-web approval, place at connector, simulate and VNA-check 1559-1610 MHz.
Motion | IMU | TDK InvenSense | ICM-42688-P | Accelerometer and gyroscope | I2C; INT1 | 1.71-3.6 V VDD/VDDIO | 14-LGA; 2.5 x 3.0 x 0.91 mm; 0.5 mm pitch | LCSC / DigiKey | C1850418 | SMT/PCBA target - verify | LOCKED - CAD CANDIDATE / SUPPLY RISK | DS-000347 v1.9 and AN-000393 v2.4 reviewed. Manufacturer-derived candidate parses, audits and passed an independent dimensional second pass. Assembler mask/paste approval and stock recheck pending.
Motion | MAGNETOMETER | MEMSIC | MMC5983MA | Three-axis magnetic field | I2C | 2.8-3.6 V | 16-LGA; 3 x 3 x 1 mm | DigiKey | N/A | SMT/PCBA target - verify | LOCKED - LAND CENTERS CORRECTED; REVIEW / PROCESS OPEN | 2026-09-23: corrected mistaken center-versus-edge dimension; source top-view numbering rechecked and pairwise copper gaps pass at 0.200 mm. Previous dimensional-pass claims superseded. See FOOTPRINT_CORRECTIONS_2026_09_23.md; independent corrected-file and assembler/placement reviews remain open.
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

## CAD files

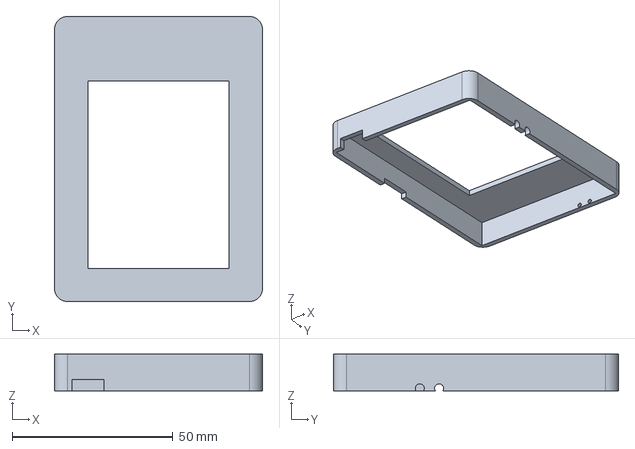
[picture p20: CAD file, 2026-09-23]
candidates/claude-oneshot-revA/mech/Enclosure_Front_Bezel.step
64.8 x 88.8 x 11.5 mm

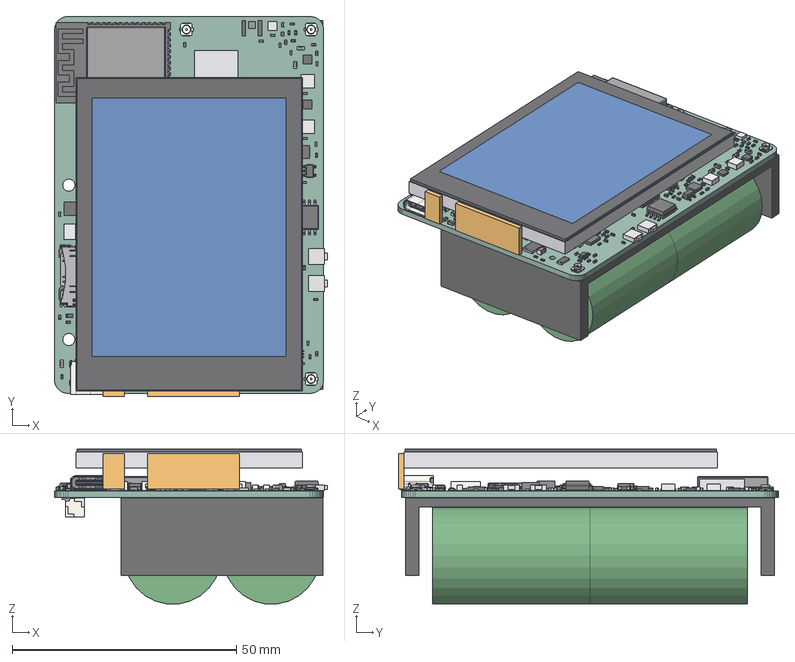
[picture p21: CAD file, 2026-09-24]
candidates/claude-oneshot-revA/outputs/StratosCore_Claude_board_2026-09-23.step
60.9 x 84.7 x 34.5 mm
C_0402_1005Metric x 81
C_0603_1608Metric x 12
R_0402_1005Metric x 72
SOT-23-6 x 5
SOT-23-5 x 4
C_0805_2012Metric x 8
L_0402_1005Metric x 4
VSSOP-8_2.3x2mm_P0.5mm
Crystal_SMD_3225-4Pin_3.2x2.5mm
L_1008_2520Metric
USON_10_25x10mm_Pitch05mm x 2
SOT-23
U.FL_Hirose_U.FL-R-SMT-1_Vertical x 3
L_0603_1608Metric x 4
WQFN-16-1EP_3x3mm_P0.5mm_EP1.68x1.68mm
L_0805_2012Metric
R_0603_1608Metric x 6
TSSOP-16_4.4x5mm_P0.65mm
QFN-24-1EP_4x4mm_Pitch0.5mm
ESP32-S3-WROOM-1
TSSOP-24_4.4x7.8mm_P0.65mm
housing x 2
lock x 2
LFCSP-16-1EP_3x3mm_P0.5mm_EP1.7x1.7mm
Crystal_SMD_2016-4Pin_2.0x1.6mm
SOIC-8_5.3x5.3mm_P1.27mm
R_2512_6332Metric
QFN-56-1EP_7x7mm_P0.4mm_EP3.2x3.2mm
SOT-363_SC-70-6
USB_C_Receptacle_16P_TopMnt_Horizontal_GCT_USB4105-xx-A
Texas_RGE0024H_VQFN-24-1EP_4x4mm_P0.5mm_EP2.7x2.7mm
microSD_HC_Hirose_DM3AT-SF-PEJM5
D_SOD_123F
frame
cover_glass
active_area
fpc40
fpc6
SOT-353_SC-70-5
Fuse_1206_3216Metric
holder
cells_M50A_envelope
JST_BM12B_GHS_TBT
StratosCore_Claude_PCB

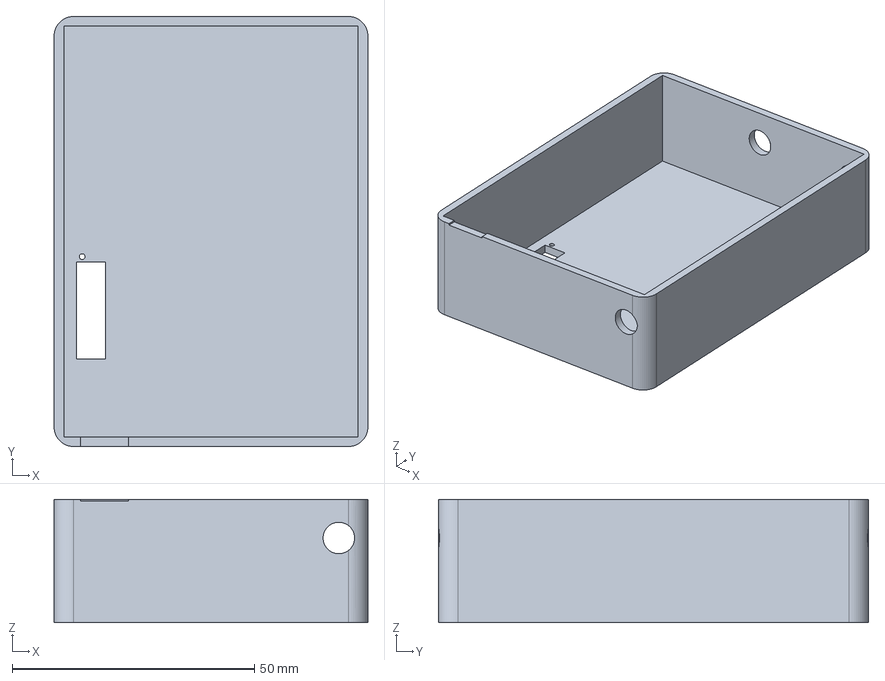
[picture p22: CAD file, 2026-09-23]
candidates/claude-oneshot-revA/mech/Enclosure_Back_Shell.step
64.8 x 88.8 x 25.5 mm

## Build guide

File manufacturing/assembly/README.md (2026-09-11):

# Assembly release placeholder

Future top/bottom assembly drawings, variant/DNP lists, panel requirements, sensor/microphone handling, cell/contact assembly and programming steps. No assembly release exists. Keep mechanical and RF antenna constraints visible in manufacturing documentation.

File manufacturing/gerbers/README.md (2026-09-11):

# Gerber release placeholder

No fabrication outputs. Populate only after approved schematic/layout, ERC/DRC, independent release review and visual inspection of all layers/drills. Include stackup, fabrication notes, revision and hashes. Current documents are not sufficient to order a board.

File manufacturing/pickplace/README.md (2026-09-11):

# Pick-and-place release placeholder

No centroid/CPL output. Later reconcile actual designators, population, side, coordinates, units, origin and rotations against assembly drawings and BOM. Confirm orientation of every polarized/asymmetric part with the assembler.

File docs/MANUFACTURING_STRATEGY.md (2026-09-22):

# Manufacturing strategy

Target four-layer PCB and automated assembly at JLCPCB or a comparable Chinese PCBA supplier, followed by shipment of assembled prototypes. The requested stack is conceptual: L1 components/signals, L2 ground, L3 power/signals, L4 signals/components. Manufacturer-approved dielectric/copper stack, board thickness, impedance tolerances and return paths must be established before layout.

The current priority is hardware readiness. Sol should close exact component evidence, compatibility, voltage/current domains, pin maps, application circuits, footprints, constraints and review gates. Astra should then execute the prepared work in KiCad: complete schematic entry, ERC, placement, routing and DRC. Manufacturing files are generated only after those reviews pass and the owner explicitly accepts the release.

## Sourcing

Use the exact locked MPNs and validated manufacturer package drawings. SHT40-AD1B-R2 is selected; generic names that still lack an ordering suffix remain explicitly TBD. Record supplier, region/currency, quantity, quotation date, stock, lead time, package/reel and assembly fees. No price, stock or LCSC ID is guessed. Multiple suppliers are preferable, but substitute MPNs require a decision proposal.

The [preliminary BOM](../bom/preliminary_bom.csv) is a functional planning list, not a purchasing or pick-and-place file. Before Astra, convert it into a frozen engineering parts baseline with every fitted/DNP item, passive value and rating, exact MPN/package, approved footprint, planned quantity range and sourcing status. Astra then creates the annotated reference-designator BOM and captured quantities. Reconcile that output into the final orderable BOM only after independent schematic review.

Validate PCBA handling of WROOM modules, small MEMS, microphone port, sensor contamination controls, SD socket and USB mechanical tabs. Do not blanket-clean, coat or apply paste over acoustic/pressure/humidity openings. Reserve board fiducials, tooling/panel features and test access after assembly-provider review. Ask the chosen manufacturer for current design/assembly rules rather than copying stale minimum dimensions.

## Release gates

1. Approved requirements, safe power topology and mechanical/RF floorplan; manufacturer datasheets and reuse terms recorded.
2. Schematic review: pinouts, voltage domains, boot/recovery, no unpowered backfeed, protection and complete BOM.
3. Placement/route review against approved stackup, RF references, sensor thermal/mechanical rules and enclosure fit.
4. ERC and DRC with tool version, settings, reports and signed exceptions; independent electrical/RF/power review.
5. Gerber/drill review, fabrication drawing, stackup/impedance note, orderable BOM, CPL consistency and rotations, assembly drawings, programming/test procedure, revision/hash and explicit release acceptance.

`manufacturing/gerbers`, `pickplace` and `assembly` are reserved areas, not ready-to-order deliverables. No manufacturing output is generated in this phase. See [test plan](../manufacturing/test/README.md).

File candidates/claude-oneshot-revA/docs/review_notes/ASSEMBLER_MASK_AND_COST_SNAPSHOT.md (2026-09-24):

# Assembler mask strategy and five-unit cost snapshot (evidence package)

**Astra review annotation, 2026-09-24:** [independent review](../../../../docs/ASTRA_AGENT_REVIEW_2026_09_24.md) reproduced the price arithmetic, not current prices/stock. The "absolute lower bound" and infeasibility wording below apply only to the listed channel-price scenarios, not every available supplier. PCB/assembly tariffs here are service charges, not import taxes. Mask and stencil acceptance remain open; later proxy decisions do not prove factory feasibility.

Status: **research evidence for human decisions only.** The assembler (JLCPCB or another house) and the project owner decide. This note does not change any footprint, KiCad file, root document, BOM or locked decision, and it authorizes no order.
Retrieval date for every web figure below: **2026-09-23** (web retrieval about 22:20 UTC unless stated). Prices, stock and fees change. Treat anything older than 30 days as context only (`bom/SOURCING_EVIDENCE.md` rule 2).
Scope: the Claude one-shot candidate (`candidates/claude-oneshot-revA`), 4 layers, 60 x 84 mm, 1.6 mm, candidate stack `JLC04161H-3313` (`docs/PCB_STACKUP.md`).

---

## A. LGA solder-mask strategy for U30 ICM-42688-P and U32 BMP581

### A.1 Manufacturer requirements (primary sources, re-read 2026-09-23)

| Part | Source | Requirement (paraphrased; section cited) |
| --- | --- | --- |
| ICM-42688-P | TDK AN-000393 **Revision 2.4, dated 2/9/2026**, [PDF](https://d17t6iyxenbwp1.cloudfront.net/s3fs-public/2026-06/AN-000393%20TDK%20InvenSense%20IMU%20PCB%20Design%20and%20MEMS%20Assembly%20Guidelines%20v2.4.pdf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) | §2.2: solder mask under the MEMS part is not recommended. If the board process cannot avoid it, mask under the part "will still work". Figure 1 gives the LGA land pattern. The repo transcription of Figure 1 (`FOOTPRINT_REVIEWS_SENSORS_GNSS.md`) is: land = terminal size, and the fallback per-pad mask adds 0.1 mm to each land dimension. §2.3: stencil opening-to-land ratio 90 %, stencil at least 100 µm, aspect ratio ≥ 1.5, area ratio ≥ 0.66. §3 (Figure 7): no traces, vias or copper pour directly under the IMU, and no via inside a pad outline. |
| BMP581 | Bosch **BST-BMP581-DS004-13, document revision 1.13**, [PDF](https://www.bosch-sensortec.com/media/boschsensortec/downloads/datasheets/bst-bmp581-ds004.pdf), §8.2 "Landing pattern" (p. 69) and Figure 32 | Land = footprint + 25 µm on each side. At least 200 µm between pads. No vias or traces under the BMP581. No solder mask under the sensor. Recommended horizontal mask clearance 20 µm on each side. §8.2 warns that mask or other material touching the sensor can degrade performance. |

Candidate geometry, read-only from `kicad/libs/SC.pretty`:
- **U30:** lands 0.475 x 0.25 mm at 0.5 mm pitch. The copper gap is 0.25 mm between row neighbours and 0.30 mm at the corners. Paste pads are 0.4506 x 0.2372 mm (90 % area). A 3.0 x 2.5 mm body-sized F.Mask opening is used, plus a pad margin of 0.05.
- **U32:** lands 0.325 x 0.30 mm at ±0.7625 mm. The copper gap is 0.20 mm. Paste is 1:1. A 2.2 x 2.2 mm body-sized F.Mask opening is used.

The candidate DRC currently reports **199+ `solder_mask_bridge`** items (`docs/REFINEMENT_2026_09_23.md` D1). Tracks for 3V3_MAIN, I2C and IMU_INT1, GND/I2C vias and GND pour lie inside those common openings. **This violates the no-trace/no-via rule of both manufacturers, independent of the mask choice.**

### A.2 JLCPCB published capabilities (retrieved 2026-09-23)

| Item | Published value / statement | Source |
| --- | --- | --- |
| Solder-mask expansion | "1:1". LDI equipment upgraded June 2025, so pad size and mask opening can be 1:1. Keep ≥ 0.09 mm between mask openings and neighbouring traces | [PCB capabilities](https://jlcpcb.com/capabilities/pcb-capabilities) (no page date shown) |
| Solder-mask bridge (dam) | 0.10 mm. With 1 oz copper, minimum pad spacing is 0.10 mm for green, red, yellow, blue and purple mask and 0.13 mm for black and white. With 2 oz it is 0.20 mm | same page |
| Mask ink | LPI. Dielectric constant 3.8, thickness ≥ 10 µm | same page |
| Pad-to-track clearance | 0.1 mm (0.09 mm locally for BGA pads). SMD pad-to-pad on different nets: 0.15 mm | same page |
| Plugged vias (mask-filled) | Must have no mask opening on either side and **≥ 0.35 mm clearance from other mask openings (e.g. pads)**. Diameter ≤ 0.5 mm | same page |
| Via covering options | Tented, Untented, Plugged, Epoxy-filled & capped, Copper-filled & capped. A tented via is covered with soldermask and gets no surface finish | [Via covering article](https://jlcpcb.com/help/article/pcb-via-covering) (last updated 2026-09-09). The instant quote defaulted a 4-layer board to **Plugged** (observed 2026-09-23) |
| SMD/SMSD mask handling | Without a remark, JLCPCB enlarges the mask clearance of SMD pads to NSMD style. To keep mask as drawn, add a PCB remark naming the parts and select "Confirm Production File" to inspect the processed Gerber | [How to order boards with solder-mask-defined pads](https://jlcpcb.com/help/article/how-to-order-boards-with-solder-mask-defined-pads) (last updated 2025-04-24) |
| PCBA stencil | Generated by JLCPCB SMT engineers from the pad layout, packages and industry guidelines. It is not shipped | [PCBA price guide](https://jlcpcb.com/help/article/pcb-assembly-price) (last updated 2026-09-09) |
| Stencil thickness (standalone stencil product) | Standard thicknesses at no extra cost: 0.10, 0.12, 0.15, 0.18 and 0.20 mm. Special thicknesses from 0.03 to 0.50 mm cost extra. Minimum aperture > 0.08 mm. Step stencil only with framework. By default, apertures for IC packages are adjusted to JLCPCB's "Opening Process Standard". A remark makes them follow the paste layer 1:1 | [Stencil capabilities](https://jlcpcb.com/capabilities/pcb-stencil-manufacturing) |
| PCBA service limits | **Economic:** single-sided placement, 0402 minimum, 0.4 mm minimum IC pitch, "standard stack-up only", reflow 255 ± 5 °C (not adjustable), X-ray only for certain parts. **Standard:** single or double-sided placement, **single-PCB size 70 x 70 mm minimum** (panel 70 x 70 to 250 x 250 mm), 0.35 mm pitch, reflow 240 ± 5 °C. LGA/QFN/BGA get X-ray automatically | [PCBA capabilities](https://jlcpcb.com/capabilities/pcb-assembly-capabilities) |
| Common no-mask opening under an LGA | **No published statement found** accepting or refusing a multi-pad mask window under a component. **TBD, ask the assembler.** | searched jlcpcb.com help and capabilities pages, 2026-09-23 |

### A.3 Compatibility check (arithmetic from the numbers above)

| Strategy | U30 ICM-42688-P | U32 BMP581 | Versus JLCPCB published limits |
| --- | --- | --- | --- |
| **S1: per-pad NSMD openings.** TDK fallback: +0.1 mm per land dimension (+0.05 mm per side). Bosch: 20 µm per side | Openings 0.575 x 0.35 mm. Dam 0.15 mm between row neighbours and 0.20 mm at the corners | Openings 0.365 x 0.34 mm. Dam 0.16 mm | Every dam is ≥ 0.10 mm (green/1 oz), and ≥ 0.13 mm for black or white mask. **Within the published capability.** Mask then lies under the body between lands. TDK accepts this. For Bosch it departs from the "no mask under the sensor" text, so it needs an owner/assembler decision. |
| **S1b: 1:1 openings (LDI)** | Dam 0.25 / 0.30 mm | Dam 0.20 mm | Within capability. It conflicts with TDK's +0.1 mm fallback and Bosch's 20 µm clearance, so it is not recommended. |
| **S2: common body-sized opening** (current candidate) | Allowed by TDK where the process permits | Matches Bosch "no mask under sensor" | JLCPCB has published no acceptance, so this is **undetermined**. It is only viable with **zero other-net copper, tracks, vias or pour inside the window**, and each window edge must be ≥ 0.09 mm from neighbouring traces. Any via within 0.35 mm of the window cannot be mask-plugged (tented or epoxy-filled instead). The window also defeats JLCPCB's default NSMD enlargement logic, so a remark and "Confirm Production File" are needed. |

Stencil check (AN-000393 area/aspect rules, computed from the candidate paste pads):
- **U30** (0.4506 x 0.2372 mm): at t = 0.10 mm the area ratio is 0.777 and the aspect ratio 2.37, which passes. At 0.12 mm the area ratio is 0.648 (**fails** ≥ 0.66). At 0.15 mm it is 0.518 (fails).
- **U32** (0.325 x 0.30 mm): at 0.10 mm the area ratio is 0.78, which passes. At 0.12 mm it is 0.65 (fails narrowly). At 0.15 mm it is 0.52 (fails).
- **Both LGAs therefore need 0.10 mm (or a step-down) at these apertures.** JLCPCB chooses the PCBA stencil thickness and does not publish it per order: **TBD, ask**.

### A.4 Recommendation (for owner/assembler decision)

1. **Primary candidate: S1 per-pad NSMD openings.**
   - U30: TDK fallback +0.1 mm.
   - U32: Bosch 20 µm per side.
   - Both give dams ≥ 0.15 mm, above JLCPCB's published 0.10 mm minimum. This is the only strategy whose feasibility rests on published JLCPCB numbers.
2. **S2 (common opening) needs written assembler acceptance before use.** Even then it requires escape routing that clears the whole body window: no tracks, vias or pour inside it, and vias ≥ 0.35 mm away if plugged. The candidate violates the no-trace/no-via requirement of both manufacturers today in any case (D1). That rework is needed under S1 too.
3. **Whichever mask option is chosen:**
   - Ask for a 0.10 mm stencil (or a step-down) at the LGAs.
   - Keep the paste layer 1:1 as drawn (remark).
   - Choose "Confirm Production File" to verify the processed mask and paste.
   - Prefer ENIG over HASL for the 0.25 mm lands. This is a process preference to confirm with the assembler, not a datasheet requirement.
4. **Service-tier constraint found:**
   - The candidate has SMD part J2 (and holder BT1) on the bottom. Economic PCBA is single-sided only.
   - The 60 mm board side is below Standard PCBA's 70 x 70 mm single-board minimum. Standard PCBA would need a panel or a design change.
   - The owner decides: move J2 to the top, hand-fit it, or panelize.

### A.5 Questions to send to the assembler (copy-ready)

1. Do you accept a **single solder-mask opening covering the whole body** of an LGA (ICM-42688-P 3.0 x 2.5 mm; BMP581 2.2 x 2.2 mm) with no mask between lands? Or will CAM restore per-pad dams? If you accept it, what minimum clearance do you require from the window edge to other-net copper and to vias?
2. If we use **per-pad NSMD openings** (ICM: land +0.05 mm per side; BMP581: land +0.02 mm per side, giving 0.15–0.16 mm dams), will you keep the openings exactly as drawn? Or does your CAM change them (1:1 LDI, NSMD enlargement)? What remark do you need?
3. Which **via covering** do you apply by default on 4-layer PCBA orders? Is a tented or epoxy-filled via acceptable 0.1–0.35 mm from an LGA mask opening?
4. What **stencil thickness** will your SMT engineers use for this board? Can you use 0.10 mm, or a local step-down at U30/U32? Will you keep our paste apertures (ICM 90 % area, 0.4506 x 0.2372 mm; BMP581 1:1, 0.325 x 0.30 mm) or apply your Opening Process Standard?
5. Is the **JLC04161H-3313** stack (with ±10 % impedance control) accepted under **Economic PCBA** ("standard stack-up only")? Or does it force Standard PCBA?
6. Board is 60 x 84 mm with one SMD connector (J2) and a battery holder (BT1) on the bottom. Which service applies: Economic with J2 hand-soldered, or Standard with a panel? What is the minimum panel you would accept?
7. For ICM-42688-P, MMC5983MA, BMP581, SHT40 and T5838 LGA/DFN parts: is Economic PCBA's fixed **255 ± 5 °C** reflow compatible with each part's J-STD-020 limit? (Owner checks each datasheet; assembler states the actual peak and time above liquidus.)
8. Do you recommend **ENIG** over lead-free HASL for 0.25 mm-wide LGA lands on this order?
9. Is X-ray automatically applied to all LGA/QFN/DFN/LFCSP parts here, and to the ESP32-S3-WROOM-1 bottom pad? What is the counted component quantity?

---

## B. Five-unit cost-feasibility snapshot (2026-09-23)

Target (D24): **≤ BRL 200 average per unit** for five units. The target includes the Chinese assembled PCB plus display/touch. It excludes local cells, the enclosure, freight and taxes.
Exchange rate: **BCB PTAX USD/BRL sell 5.1414 BRL per USD** (bid 5.1408), bulletin 2026-09-23 13:04 BRT. Source: [BCB Olinda PTAX API](https://olinda.bcb.gov.br/olinda/servico/PTAX/versao/v1/odata/CotacaoDolarDia(dataCotacao=@dataCotacao)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'09-23-2026'&$format=json). The target therefore equals **USD 38.90 per unit**.

### B.1 Bare PCB, JLCPCB instant quote (no Gerber uploaded; coupons, shipping and tax excluded)

Source: [cart.jlcpcb.com/quote](https://cart.jlcpcb.com/quote), observed 2026-09-23. Site currency is USD ("payments must be made in US dollars").

Base configuration: FR-4, 4 layers, 60 x 84 mm, qty 5, single PCB, 1.6 mm, green, 1 oz outer / 0.5 oz inner, flying-probe test.
- The candidate uses 0.2 mm drill / 0.40–0.45 mm vias (605 of 656), so the "0.2mm/(0.3/0.35mm)" via option is required. That option automatically adds FR-4 TG155 and 4-wire Kelvin test.

| Configuration observed | Line items (USD) | Total USD / 5 pcs |
| --- | --- | --- |
| HASL (leaded), plugged, no stack spec, 0.3 mm via default (not valid for this board) | "Special Offer" 8.00 | 8.00 |
| + 0.2 mm via option (required) | + TG155 3.43 + min-via 17.17 + 4-wire Kelvin 16.87 | 45.47 |
| + ENIG | + surface finish 17.20 | 62.67 |
| + stack `JLC04161H-3313` specified (stack table shown: 0.035 / 3313 0.0994 / 1.265 core / 3313 0.0994 / 0.035) | no change | 62.67 |
| + impedance control ±10 % | + 33.08, + Confirm Production File 1.05 | **96.80** |
| same, lead-free HASL instead of ENIG | surface finish 5.10 | **84.70** |

"Special Offer" is a promotional label. Whether it stays available for this order is **TBD**. Build time 3–4 days at USD 0.

### B.2 PCBA fees (JLCPCB published price guide, last updated 2026-09-09)

Source: [PCB Assembly price guide](https://jlcpcb.com/help/article/pcb-assembly-price). The PCBA quote itself requires Gerber/BOM/CPL upload, so the real quote is **TBD**. No manufacturing files exist and the candidate is not released.

| Fee | Economic | Standard | Basis used here |
| --- | --- | --- | --- |
| Setup | 8.18 | 25.56 single / 51.12 double | Economic |
| Stencil | 1.53 | 8.21 single / 16.42 double | Economic |
| Extended-part feeder loading | 3.07 per extended part | 1.53 per basic/extended part | ≥ 16 extended major lines (all B.3 ICs except W25Q C97521 "base", plus BLB01, TA2003A, ADL5513, display excluded). Full count **TBD** (passives not mapped): ≥ 49.12 |
| SMT joints | 0.0016/joint | same (≤ 50k) | 958 SMD pads/board from the candidate PCB x 5 = 4 790, so 7.66 |
| X-ray | 51–200 pcs: 0.49/pc | same | about 20 leadless parts per board: D2, U2, U23, U3, U4, U6, U7, U17, U20, U30–U33, U40, U50, U52, U54, MK1, FL1, FL2. x 5 = 100, so 49.00 (ESP32 module inclusion TBD) |
| Hand-soldering labor | 3.58/order + 0.0164/joint | same | J1 shell (4 THT) x 5, so 3.91. BT1 holder TBD |
| Fixtures, handling | n/a | fixtures 16.42 (1–29 pcs); handling ≥ 14.93 if applicable | not in Economic estimate |
| **Economic estimate** | | | **≥ USD 119.40 per order (≥ 23.88 per unit)**, derived from published tariffs. Not a quote |

### B.3 Major-IC and display prices (per-unit price at the break covering 5 boards)

JLCPCB column = JLCPCB parts-library assembly price. It was retrieved through the public library search endpoint that the parts page uses (`jlcpcb.com/api/overseas-pcb-order/v1/shoppingCart/smtGood/selectSmtComponentList`), with the part page at `https://jlcpcb.com/partdetail/<urlSuffix>`. LCSC column = [LCSC product page](https://www.lcsc.com/product-detail/C2040.html) pattern `https://www.lcsc.com/product-detail/<C#>.html`, values from LCSC's product-detail JSON with `currencySymbol "$"`. All USD.

| MPN (qty/board) | LCSC/JLC # | JLCPCB USD @1–9 (stock, library) | LCSC USD @1 (stock) | Other channel | Price used |
| --- | --- | --- | --- | --- | --- |
| ESP32-S3-WROOM-1-N16R8 (1) | C2913202 | 5.1407 (27 292, extended) | 5.1937 (6 615) | — | 5.1407 |
| RP2040 (1) | C2040 | 0.9891 (74 207, ext) | 0.9968 (68 558) | — | 0.9891 |
| SX1262IMLTRT (1) | C191341 | 3.1983 (2 454, ext) | 3.2219 (2 454) | — | 3.1983 |
| MAX-M10S-00B (1) | C4153167 | 10.7808 (775, ext) | 10.8604 (715) | — | 10.7808 |
| BQ25887RGER (1) | C2761614 | 5.0431 (779, ext) | 5.0804 (779) | — | 5.0431 |
| ICM-42688-P (1) | C1850418 | 19.45 (410, ext) | 19.6358 (**2**) | [DigiKey 11679713](https://www.digikey.com/en/products/detail/tdk-invensense/ICM-42688-P/11679713): 4.91 @1, **4.402 @5**, **stock 0**, 5 000 expected 2027-08-03 | 19.45 (in stock) / 4.402 (lower bound, not available) |
| MMC5983MA (1) | C404329 | 2.2629 (18 548, ext) | 2.2838 (18 548) | — | 2.2629 |
| BMP581 (1) | C5362283 | 2.7998 (1 876, ext) | 2.8286 (1 875) | — | 2.7998 |
| SHT40-AD1B-R2 (1) | C2909890 | 1.905 (22 013, ext) | LCSC detail returned no record | — | 1.905 |
| TPS62130ARGTR (1) | C337502 | 0.9241 (6 884, ext) | 0.9325 (6 884) | — | 0.9241 |
| TPS259474LRPWR (1) | C2864845 | 1.3438 (1 102, ext) | 1.3541 (1 102) | — | 1.3438 |
| TUSB320LAIRWBR (1) | C132554 | 1.3861 (3 812, ext) | 1.4004 (3 751) | — | 1.3861 |
| W25Q128JVSIQ (1) | C97521 | 2.5541 (45 948, **basic**) | 2.5782 (1 465) | alt C113767 ext 2.5086 | 2.5541 |
| TCA9535PWR (1) | C130204 | 1.3243 (14 671, ext) | 1.3365 (14 184) | — | 1.3243 |
| BLB01 (2) | C38893678 | 3.6961 (**0**) | no LCSC record | [DigiKey 17126531](https://www.digikey.com/en/products/detail/berex-corp/BLB01/17126531): **1.772 @10**, stock 3 389, CT | 2 x 1.772 = 3.544 (would need consignment/global sourcing, fee TBD) |
| TA2003A (2) | C5357397 (brand "TST") | placeholder, **stock 0** | no LCSC record | DigiKey: no result. Mouser: bot-protected, not retrieved | **TBD** |
| ADL5513ACPZ-R7 (1) | C579160 | 19.5297 (**0**) | 19.731 (**0**) | [DigiKey 2180444](https://www.digikey.com/en/products/detail/analog-devices-inc/ADL5513ACPZ-R7/2180444): 18.85 @1, **stock 0**, 1 500 expected 2026-12-30 | 18.85 (lower bound, not available) |
| Display AFY240320A1-2.8INTH-C1 (1, with CTP) | not in JLC/LCSC library | — | — | [DigiKey 22531939](https://www.digikey.com/en/products/detail/orient-display/AFY240320A1-2-8INTH-C1/22531939): **31.55 @1** (next break 10 @ 25.489), stock 46, 8-week lead. Orient direct price TBD | 31.55 |

Not researched (**TBD**, cost only adds):
- all passives;
- TPS7A2030/2018, TPS22918 x3, SN74AXC4T245, SN74LVC1G07, TPS61169, TXU0202, TPD4E05U06 x2, TPD1E0B04, PE4259, MCP6566, S-8252 (O05), Q1 (O05), Q2, D1, F1;
- Y1/Y2, L1–L3/L70, all RF passives (E449 values TBD), MK1 T5838;
- USB4105, J2 (plus housing), J3/J4 FPC, three U.FL connectors, DM3AT, 2 x SKSCLCE010;
- BT1 holder (MPN TBD), antennas, pigtails, microSD card;
- consignment/global-sourcing fees for zero-stock lines;
- the real PCBA quote.

### B.4 Arithmetic and verdict

| Line | USD / unit | BRL / unit @ 5.1414 |
| --- | --- | --- |
| 14 in-stock JLCPCB ICs above (ESP32 … TCA9535) | 59.10 | 303.87 |
| + BLB01 x2 (DigiKey) + ADL5513 (DigiKey, 0 stock) + display (DigiKey) = **as-available snapshot (LB1)** | 113.05 | 581.22 |
| **Absolute lower bound (LB2)**: LB1 with ICM-42688-P at DigiKey 4.402 (0 stock) | 98.00 | 503.85 |
| LB2 + PCB (62.67 / 84.70 / 96.80 per 5) + Economic PCBA estimate (≥ 23.88) | 134.41 / 138.82 / 141.24 | **691.07 / 713.72 / 726.16** |
| LB2 without the display and ADL5513 (sensitivity only) | 47.60 | 244.72 |
| D24 target | 38.90 | 200.00 |

**Verdict: INFEASIBLE as of the 2026-09-23 snapshot.**
- The retrieved lines alone come to at least **BRL 504 per unit**, about 2.5x the BRL 200 target. With the published PCB/PCBA tariffs added, the total is about BRL 691–726, about 3.5x.
- Every TBD line (TA2003A, passives, the remaining ICs, connectors, holder, sourcing fees, the real PCBA quote) can only add cost. The verdict therefore does not depend on them.
- It holds even when you:
  - use the cheapest price found in any channel, including channels with zero stock;
  - exclude the display and ADL5513 entirely (BRL 245 > 200).
- The display (BRL 162) plus the in-stock ICM-42688-P (BRL 100) already exceed the target.

What the owner may consider (not proposals, and nothing changed):
- revisit the D24 target or scope;
- request an actual JLCPCB/other-assembler quote to confirm magnitude;
- open AGENTS rule 2 replacement studies (dated cost, availability, electrical, firmware and PCB impact) for the largest contributors: display, ICM-42688-P, MAX-M10S-00B and the ADL5513/ADS-B chain.

**Locked parts must not be substituted without owner acceptance (D-register).**

### B.5 Method notes and limits

- JLCPCB and LCSC values are library list prices. JLCPCB zero-stock rows sometimes show a placeholder price (USD 0.0396). Those rows were ignored, and zero-stock prices are flagged.
- The LCSC search endpoint is blocked (HTTP 403). Only per-C-number detail lookups were used.
- DigiKey values were read from the rendered product pages in a browser on 2026-09-23.
- Mouser was not retrieved: its bot protection was not bypassed.
- The PCBA estimate applies published tariffs to counts derived from the candidate PCB (958 SMD pads per board, about 20 leadless parts, 16+ extended lines). It is an estimate, not a quote.

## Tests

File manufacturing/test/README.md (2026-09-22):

# Verification and production-test planning

No electrical tests have been executed. Before Astra placement, freeze the DFT coverage matrix: required nets, pad family and minimum dimensions, permitted face, fixture pitch, current limits, programming access, RF injection points, instrumentation and planned acceptance values. Astra assigns test-point references and coordinates during CAD execution. After placement/routing, review physical probe access and fixture feasibility; after PCBA, execute and record the electrical tests.

## DFT coverage matrix (DFT-01, frozen 2026-09-22)

Pre-placement freeze required by O28: every access point below exists in an accepted task deliverable (DIG-01/02/03, PWR-02/04, GNSS-01, AUD-01, PWR-02 USB input, P25 RF ports). **Astra assigns reference designators and coordinates; nothing here releases a footprint.** Pad family defaults: signal/test pads 1.0 x 0.6 mm SMD test pad (probe class >= 100 mil pitch fixture access), rail measure points 1.2 mm round pad with 0.3 ohm-class shunt resistor optional where current measurement needs it; all access **top face unless noted**; fixture target pitch 1.27 mm between access points (real fixturing feasibility is reviewed after layout, as O28 requires).

| # | Net / access | Type | Pad / face | Purpose and measured quantity | Acceptance basis |
| --: | --- | --- | --- | --- | --- |
| 1 | SWCLK + SWDIO (RP2040) | Programming/debug pads (Tag-Connect-class footprint, board edge) | per DIG-01 footprint; top | Full-image programming, checksum, reset-reason readback; 24 MHz max clock per datasheet | DIG-01 corner plan step 3 |
| 2 | RUN (RP2040 reset) | Test pad | 1.0 mm pad; top | Controlled reset cycling with flash-write quiesce verified | DIG-01 corner plan step 2 |
| 3 | USB_BOOT (RP2040 QSPI_SS strap) | Test pad | 1.0 mm pad; top | BOOTSEL entry via grounding while toggling RUN | DIG-01 corner plan step 4 |
| 4 | ESP32 UART0 console (GPIO43/44) + 3V3/GND | 4-pad programming strip, board edge | 1.27 mm pitch strip; top | Boot log, recovery without USB, serial/console access | GPIO map recovery contract |
| 5 | ESP32 native USB | Connector (no extra pads) | USB4105 at board edge | Firmware flash, console, enumeration tests | PWR-02 attach policy |
| 6 | GNSS_TX / GNSS_RX / GNSS_PPS | 3 test pads | 1.0 mm pads; top | UBX bring-up at 9600->115200, PPS qualification | GNSS-01 host interface plan |
| 7 | SD_CD + 3V3_SD measure point | 2 pads | 1.0 mm + 1.2 mm round; top | Card-detect state; switched-rail current for PWR-04/O13 | DIG-02 DFT hook |
| 8 | `3V3_MAIN` measure point | Rail pad pair (rail + GND) | 1.2 mm round; top | Simultaneous-peak verification against the PWR-04 envelope; droop scope point | PWR-04 measurement plan |
| 9 | `3V0_RF_QUIET` measure point | Rail pad pair | 1.2 mm round; top | ADS-B analog chain current (85 mA class) and noise supply check | PWR-04 LDO row |
| 10 | `1V8_LOGIC` measure point | Rail pad pair | 1.2 mm round; top | Display/audio 1.8 V load and sequencing check | PWR-04 LDO row |
| 11 | Protected 2S bus B+/B- measure points | Rail pad pair, **near battery holder** | 1.2 mm round; top | Pack voltage under charge/load; cell fault tests | POWER_INPUT_EVIDENCE O05 matrix |
| 12 | MID (2S midpoint via BQ25887 CBSET/MID path) | Test pad | 1.0 mm pad; top | Per-cell voltage split, balance verification | PWR-03/O05 review row |
| 13 | Charger input (eFuse output side) | Rail pad pair | 1.2 mm round; top | USB/charge input current verification vs 500 mA policy floor and 1.97 A breaker | PWR-02 network |
| 14 | RF conducted ports (GNSS U.FL, ADS-B SMA via CAB.721, optional LoRa SMA) | Existing antenna connectors - no added pads | connectors | Conducted TX/RX, sensitivity, spurious, coexistence per the RF validation plans | LORA-03/ADSB-03/GNSS-03 plans |
| 15 | RF injection: GNSS RF_IN and ADS-B input | Injected at the U.FL/SMA ports (no separate pads) | connectors | Blocker/coexistence injection (915 MHz into GNSS per the recorded -17 dBm immunity row) | GNSS-01/GNSS-03 |
| 16 | `AUD_SW_EN_N` domain + PDM_CLK/PDM_DATA | 2 test pads + rail pad | 1.0 mm pads; top | 1V8 domain toggle recovery; PDM levels/duty | AUD-01 recovery row |
| 17 | I2C SDA/SCL (shared bus) | 2 test pads | 1.0 mm pads; top | Rise-time/VOL post-PCBA validation of the 100 kHz window; stuck-bus recovery drill | SYS-01/I2C budget closure criterion 6 |

**Current limits for probing:** rail measure points sized for the PWR-04 envelope (3V3_MAIN worst ~1.4 A class: pad pair supports clamp-probe or shunt method; no measurement method that adds >0.1 ohm in the 3V3_MAIN path at load). Battery/charge paths (11/13) support the O05 fault-test instrumentation; the exact fault-matrix instrumentation remains with the qualified battery review.

**Deliberately not frozen here:** production screening limits (they need measured data), fixture pin-out wiring (post-layout), and any access to the 2S protection FET nodes (PWR-03/O05 territory - not invented here).

| Area | Planned evidence |
| --- | --- |
| Power and battery | Short/leakage, rails under transient load, USB/charge limits, either cell reversed/missing/removed, 2S mismatch/balance and thermal protection |
| Compute | Boot/recovery, exact Flash/PSRAM capacity, RP2040 programming/watchdog |
| Sensors/GNSS | IDs, axes, calibration sanity, pressure/temperature response, GNSS fix/UTC and antenna behavior |
| UI | Pixel/touch tests, orientation mapping, two buttons, dim/sleep/wake |
| Logging/audio | Sustained writes, bounded latency, full/removed card, reset/power-loss behavior, synchronized sample timestamps |
| LoRa | Conducted RF power/frequency and RX, BUSY/IRQ handling, regional configuration gating |
| ADS-B | Known-frame acceptance/rejection, capture timing, analog dynamic range, queue/host saturation and contact validity |
| Complete assembly | RF coexistence, thermal drift, both cell populations, long-duration FLIGHT/BALLOON/DESKTOP and measured runtime |

Separate design qualification from fast production screening. Production records should identify serial/board revision, BOM variant, firmware hash, fixture/instrument calibration and measured pass/fail limits. ERC/DRC are design checks, not substitutes for these measurements.

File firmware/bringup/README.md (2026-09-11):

# Future bring-up sequence

Planning only. No executable test or energization procedure is released. Battery energization depends on accepted safety review.

1. Inspect assembled board and shorts; validate approved power subsystem with current-limited source and defined rails/load limits.
2. Verify ESP32 recovery, flash/PSRAM and RP2040 SWD/boot flash independently.
3. Probe sensor IDs/interfaces and GNSS UART, then verify timestamps, axes and failure recovery.
4. Enable panel/backlight/touch and both buttons only with verified connector and power sequence; test rotations.
5. Exercise microSD bounded writes, full/removed card, reset recovery and synchronized audio if populated.
6. Test SX1262 conducted into suitable RF load under selected regional profile; check reset/BUSY/IRQ behavior.
7. Exercise ADS-B capture with known inputs and host backpressure; then RF coexistence and long-duration complete-profile tests.

Record board revision, BOM population, firmware hash, instruments/settings, expected limits and actual results. Never mark plans as passed tests.

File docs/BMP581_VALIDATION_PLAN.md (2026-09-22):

# BMP581 Indicative Pressure and Vario Validation Plan

Status: **PROPOSED TEST PLAN; no sensor or board measurements are claimed.** The locked BMP581 remains an indicative secondary pressure/altitude/vario sensor under D08, D25 and D29. This document defines the reviewable validation plan and sample validity contract; it does not establish measured performance or qualify the device as a flight instrument.

Reviewed: 2026-09-22.

## Source basis and operating envelope

Primary component source: Bosch Sensortec, [BMP581 datasheet BST-BMP581-DS004-13, revision 1.13, released April 2025](https://www.bosch-sensortec.com/media/boschsensortec/downloads/datasheets/bst-bmp581-ds004.pdf), reviewed 2026-09-22. Use the exact Bosch source for design decisions. Relevant sections are §2/Table 1 (pressure measurement range and pressure accuracy conditions), §2/Table 2 (temperature performance), §4.3 (power modes), §4.4 (measurement enable, oversampling and IIR filtering), §4.5 (data registers and shadowing), §4.7.2 (data-ready and pressure out-of-range interrupt sources), §6.2.5/Figure 28 (fast supply ramp application), and §10 (package drawing). The exact package and board application remain governed by the existing component evidence and CAD review.

For reference only, the U.S. National Weather Service [standard-atmosphere table](https://www.weather.gov/index.php/ama/conversions), reviewed 2026-09-22, lists approximately 697 hPa at 10,000 ft and 301 hPa at 30,000 ft. These are standard-atmosphere examples, not expected field pressure at a given geometric altitude: weather and local pressure reference change the relationship. The 10,000 ft example is within the BMP581 300–1250 hPa measurement range. The 30,000 ft example is only about 1 hPa above the 300 hPa lower limit, so it has essentially no margin for weather, port error or transient pressure excursions and is not a coverage claim.

Bosch specifies pressure measurement across 300–1250 hPa and pressure measurement over -40 to +85 °C. Its Table 1 gives typical absolute pressure accuracy of ±30 Pa across 300–1100 hPa and -5 to +65 °C; that typical figure is not a guaranteed maximum and does not apply outside its stated temperature conditions. The NWS standard-atmosphere temperature at 10,000 ft is about -4.8 °C, near the lower edge of the stated accuracy-temperature interval; this is outside-air reference temperature, not the unknown BMP581 board temperature. Board temperature, thermal gradients and pressure-port response therefore remain measured inputs to any performance claim. At 30,000 ft the standard outside-air temperature is about -44.5 °C, below the sensor operating minimum; exposed operation there is out of range even before considering pressure margin.

## Validation stages

### Before Astra / before PCBA

Close only design and software-contract items that can be established without a physical sensor:

- Confirm the selected sensor remains the locked BMP581, the existing manufacturer-derived application/footprint remains the candidate, and the 100 kHz shared I2C policy is used. Do not revise the part, schematic, footprint or pin map through this plan.
- Review the exact BOM ordering code, rail ramp behavior, bus address, I2C pull-ups, data-ready/status handling, pressure and temperature conversion, unit scaling, pressure validity bounds, stale-data handling, and logged calibration/reference metadata against the current Bosch datasheet and project interface documents.
- Add host-side tests using synthetic samples for range boundaries, startup/not-ready, sensor/status/bus faults, stale samples, missing reference pressure, conversion overflow, and positive/negative vario sign. These tests validate software behavior only; they do not validate the sensor, pressure path, accuracy, temperature response or board layout.
- Record the intended ODR, oversampling, IIR settings and effective vario window as configuration inputs. Select these from noise/response tradeoffs during bench work; do not assert an unmeasured noise floor or response time before PCBA.
- Keep assembler approval for lands/mask/paste, under-body no-route compliance, and the existing mechanical fit/routing reviews as separate release gates.

### After PCBA: pressure and vario bench characterization

Use at least one assembled board and a calibrated pressure reference or pressure controller with documented uncertainty and calibration status. A controlled chamber is needed to exercise the realistic 10,000 ft pressure case; do not infer it from an altitude calculator or a hand pump without a pressure reference. Proposed sequence:

1. Record board revision, sensor lot/marking, firmware/configuration, supply rails, chamber/reference model and calibration, reference uncertainty, ambient and BMP581-reported temperature, setup photographs, test date, and operator. Preserve raw timestamped pressure, temperature, status/validity flags and reference readings.
2. At ambient pressure, verify device identity, stable communication, data-ready behavior, pressure/temperature register handling, and repeatability after power cycles. Confirm timestamps and sample age are monotonic and faults become invalid samples instead of plausible numeric readings.
3. With pressure changed slowly, characterize ascending and descending steps from local ambient down through approximately 697 hPa (the NWS 10,000 ft standard-atmosphere example), then return to ambient. Include intermediate steps sufficient to reveal hysteresis, lag, jumps, or chamber/port leaks. Record actual reference pressure; use the 697 hPa point as a test point, not as a universal 10,000 ft mapping.
4. Compare BMP581 pressure to the calibrated reference over repeated stabilized points. Report error, repeatability, hysteresis, settling behavior, reference uncertainty and board temperature separately. Do not label a typical datasheet value as the acceptance limit. Any numeric project acceptance band remains TBD until reviewed against reference uncertainty, board temperature and intended indicative use.
5. At constant reference pressure, capture baseline noise and vario output at each candidate filter/window configuration. Then apply repeatable pressure ramps or steps in both directions; measure sign, noise, lag, overshoot and settling. Choose a documented configuration only after this data is reviewed. Keep vario marked indicative.
6. Repeat a smaller run after a full power cycle and, if practical, after a representative operating-temperature soak once a board-temperature range has been decided. Keep within the BMP581 specified operating temperature; do not use the chamber to imply qualification outside it.
7. Exercise invalid-data handling by disconnecting or faulting the sensor bus in a controlled bench setup, suppressing data-ready updates, forcing stale timestamps, and using validly obtained samples outside the configured reference/calibration state. Verify display/log status and recovery behavior. No environmental or pressure-limit abuse is needed to test firmware gating.

The optional 30,000 ft exploratory point is not part of the acceptance plan. If later explored, approximately 301 hPa is too close to Bosch's lower measurement limit for a useful operating guarantee; any sensor pressure below 300 hPa or temperature outside -40 to +85 °C must be reported out of range. Do not present a 30,000 ft reading as supported performance.

## Pressure path and temperature caveats

The sensor needs representative static pressure at the enclosure port. Follow the [mechanical/RF floorplan](MECHANICAL_RF_FLOORPLAN.md): the planned enclosure static vent is 1.0–2.0 mm, away from direct airflow; keep the BMP581 body free of routing/vias underneath and maintain the documented separation from switching heat sources. The actual port, board opening and enclosure response still require fit-dummy and assembled-board review. A moving vehicle or aircraft can create local dynamic pressure, suction, blockage and pressure lag; the bench test does not qualify those installations. The acoustic and pressure openings must remain separated per the floorplan.

BMP581 reported temperature is a sensor reading and must not be treated as outside-air temperature or proof of the whole board's temperature. Heat from the backlight, regulators, processor, charging and sunlight can bias the board environment. Measure local board temperature next to the sensor during characterization and describe the test mounting, airflow and nearby heat loads. Temperature-induced pressure shift, enclosure thermal gradients, solder drift, long-term drift and calibration effects must be reported as observed; no correction is assumed until evidenced.

## Proposed validity and data contract

This is a proposed interface contract for review and implementation. It gives downstream display/logging code the context needed to distinguish a usable pressure sample from an unqualified value.

| Field | Contract |
| --- | --- |
| `pressure_pa` | Unrounded absolute sensor pressure in pascals. Preserve the source resolution; display rounding is separate. Never substitute a standard-atmosphere pressure for a missing sensor reading. |
| `temperature_c` | BMP581-reported temperature in degrees Celsius, explicitly labeled as sensor temperature. |
| `sample_time` / `sample_age` | Monotonic acquisition time and derived age. A stale or missing update is invalid; the timeout is a firmware configuration to be set from the selected ODR and verified bench behavior. |
| `sensor_state` | At minimum: `valid`, `not_ready`, `bus_error`, `device_error`, `stale`, `pressure_out_of_range`, `temperature_out_of_range`, or `uncalibrated_reference`. Preserve the reason in logs. |
| `pressure_valid` | True only when communication and device status are healthy, a fresh data-ready sample has been acquired, pressure is within 300–1250 hPa inclusive, and reported sensor temperature is within -40 to +85 °C inclusive. A value at/beyond a boundary should be treated conservatively if rounding or sensor uncertainty makes its status ambiguous. |
| `altitude_m` | Optional calculated, indicative value. Must carry the reference pressure value/source and a mode: reference-calibrated pressure altitude or session-relative change. Without a valid explicit reference, do not label it absolute altitude or silently assume local sea-level pressure. |
| `vario_mps` | Optional indicative rate derived from fresh valid pressure samples using a documented filter/window. Positive means ascent, negative descent. Mark invalid during startup, stale data, pressure faults or filter reset; record filter/window and effective delay. |
| `calibration` | Record the reference pressure, source, timestamp and method used for any altitude zero/reference. A missing or expired reference invalidates absolute altitude, but need not invalidate fresh absolute pressure. |
| `quality` | Distinguish manufacturer-range validity from tested performance. In-range is not a claim of accuracy. Tag all BMP581 pressure/altitude/vario outputs as secondary and indicative; never use them as the sole safety or primary-flight indication. |

## Results record and closure

No tests are recorded as complete in this plan. After PCBA, add a dated result record with board/sensor identity, setup, reference uncertainty, raw-data path, plots or summaries, configuration, deviations, failures, reviewer and disposition. Do not edit this plan to imply a pass until the owner/reviewer has assessed the evidence. Keep any measured project limits clearly labeled as accepted limits, observed results or open TBD values, as appropriate.

Closure evidence for the sensor gate should include the reviewed firmware validity contract, assembler land-pattern approval, fit-dummy and routing/vent conformance, pressure/reference comparison near the 10,000 ft standard pressure, temperature notes, and vario noise/lag/sign results. Balloon or exposed-airframe use remains a separate installation and environment review.

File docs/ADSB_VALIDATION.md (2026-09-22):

# ADS-B frontend and RP2040 validation plan

Status: independent Rev A candidate; no ADSBee circuit or source code copied. Review date: 2026-09-11 UTC. Exact-part and bias evidence updated 2026-09-14.

## Candidate signal chain

`1090 MHz antenna -> ESD/bias option -> BLB01 LNA -> TA2003A SAW -> BLB01 LNA -> TA2003A SAW -> ADL5513 log detector -> MCP6566 comparator -> RP2040 PIO/DMA`

| Part | Evidence and role | Planning contribution |
| --- | --- | --- |
| BeRex `BLB01`, two | 500-1500 MHz internally matched 50-ohm GaAs E-pHEMT LNA in a DFN-8 2 x 2 mm package; datasheet V6.6 documents Id at Vd = 3.0 V as 22/27/32 mA (min/typ/max), gain 21/22.5 dB, NF 0.43/0.63 dB, and a 100 pF/12 pF/12 pF/100 pF 0603 evaluation BOM | About 34 dB gross gain and 0.162 W for two stages at the documented 27 mA typical current. The manufacturer evaluation circuit shows no discrete RF matching network, but bias, decoupling, layout and board-level S-parameter verification remain design work |
| TAI-SAW `TA2003A`, two | 1090 MHz SAW (datasheet Rev 1.0): Fc 1090 MHz, insertion loss 3.2/4.0 dB typical/maximum in 1087-1093 MHz, VSWR 2.4 maximum, stopband 45-62 dB typical across DC-970 MHz, 1046 MHz and 1150-1300 MHz regions | Up to 8 dB cascaded in-band loss; first-stage placement chosen to preserve noise figure while limiting blockers |
| ADI `ADL5513ACPZ-R7` | 1 MHz-4 GHz log detector, -70 dBm sensitivity, 20/21 ns pulse response, 31 mA | Better current product/cost evidence than AD8313; roughly 0.102 W at 3.3 V |
| Microchip `MCP6566` | 1.8-5.5 V open-drain comparator, 56 ns typical high-to-low delay at 1.8 V/100 mV overdrive, 4 MHz maximum toggle at 5.5 V; electrical characteristics table: IQ 60/100/130 uA typical/maximum | Adequate on paper for 0.5 us pulse positions; pull-up RC, delay spread and hysteresis need measurement |

MCP6566 ordering-code closure (DS20002143G Rev G, March 2020, Product Identification System page 47; reviewed 2026-09-17): `LT` = 5-lead SC70 (Microchip package drawing C04-2061-LT Rev E), `OT` = 5-lead SOT-23 (drawing C04-2091-OT Rev F), `E` = -40 to +125 °C; there is no "DBV" suffix (that is TI nomenclature). Preferred candidate **`MCP6566T-E/OT`** (SOT-23-5) for Rev A inspectability/rework, consistent with the flash-package philosophy; **`MCP6566T-E/LT`** (SC70-5) is the smaller alternative, and `MCP6566RT-E/OT` / `MCP6566UT-E/OT` are pin-map routing conveniences (same die, SOT-23 only). Final base-vs-R-vs-U choice is a layout routing input; distributor stock recheck at purchase. The open-drain output may be pulled above VDD (abs max VSS + 10.5 V, section 1.1 note 4), so the comparator can run from the 3.0 V ADS-B quiet rail with its output pulled directly to the RP2040 3.3 V bank — no level translator in the pulse path. Hysteresis is 1.0-5.0 mV internal; the pull-up value (starting point 1-10 kΩ) remains a bench measurement gate.

### Comparator pin-map variant and application network (ADSB-01, closed 2026-09-22)

**Pin-map variant resolution (verified fact, DS20002143G Rev G Table 3-1 page 13 + Product ID page 47; re-extracted from the PDF 2026-09-22):** the three SOT-23-5 variants are **not interchangeable pin maps**:

| Pin function | `MCP6566` base (SC70 and SOT-23 share numbering) | `MCP6566R` (SOT-23 only) | `MCP6566U` (SOT-23 only) |
| --- | --- | --- | --- |
| OUT | 1 | 1 | 4 |
| VIN- | 4 | 4 | 3 |
| VIN+ | 3 | 3 | 1 |
| VDD | 5 | 2 | 5 |
| VSS | 2 | 5 | 2 |

`R` mirrors the power pins relative to base; `U` rotates the analog/output pins as well. Marking codes (section 6.1): base `JYNN`, R `JZNN`, U `WLNN` on 5-lead SOT-23. **Rev A schematic pin assignment is frozen to the base `MCP6566T-E/OT` map: OUT=1, VIN-=4, VIN+=3, VDD=5, VSS=2.** R and U remain documented alternates; switching to one is a layout-time decision that must return through review with the footprint re-derived — it is not a drop-in socket equivalent.

**Application network (proposal, values labeled; ADSB-01 scope, threshold value excluded):**

- **Supply:** VDD (pin 5) on `3V0_RF_QUIET`; 100 nF local decoupling plus the rail's existing bulk (proposal). Rail load contribution: IQ 60/100/130 uA typ/max (DS section 1.0) — flagged to PWR-04.
- **Signal inputs:** VIN+ (pin 3) = ADL5513 VOUT video output; VIN- (pin 4) = threshold node from a resistor divider on `3V0_RF_QUIET` (log video is positive-going; the divider value is **TBD, blocked by OWN-09** — VTH = 3.0 x R2/(R1+R2), with the divider impedance kept <= ~10 kOhm class so the <=5 mV internal hysteresis is not swamped by divider noise; final R1/R2 freeze together with the OWN-09 target and the bench threshold sweep).
- **Output pull-up (calculation + proposal):** OUT (pin 1) pulled to the RP2040 3.3 V bank through **2.2 kOhm +/-1% preferred** (bench sweep window 1-10 kOhm retained). Basis: output node capacitance COUT 8 pF typical (DS section 1.0) + RP2040 GPIO capacitance TBD + ~5 pF trace allowance ~= 13-18 pF; rise to the ~2.31 V (0.7 x VDDIO) threshold is `t = -ln(1-0.7) x Rp x C ~= 1.204 x Rp x C`, giving ~48 ns at 2.2 k/18 pF — well inside a 500 ns half-symbol. Sink at VOL: 3.3 V / 2.2 k = 1.5 mA, within the 3 mA-tested VOL point (DS section 1.0: VOL <= 0.6 V at 3 mA/8 mA). Asserted dissipation 4.95 mW.
- **Delay budget (verified facts + boundary):** tPHL 56/80 ns typ/max at 1.8 V, 100 mV overdrive (DS section 1.0 AC table; a 3.0 V maximum is **not published** — bench-gated), plus ~48 ns rise, plus RP2040 input delay TBD: combined ~130 ns worst-recorded against the 500 ns half-symbol (~26%), before jitter. This is why the pulse-path delay distribution stays in the conducted-test plan below.
- **External hysteresis:** none proposed for Rev A until the bench shows internal 1.0-5.0 mV is insufficient; positive feedback on an open-drain output needs the pull-up node as the sense point and is recorded as an optional design note, not a committed part.

The two-stage arithmetic suggests the detector can see roughly -96 dBm at the antenna after a conservative 26 dB net gain. This is a screening estimate, not a receiver sensitivity claim. The 1090 MHz S-parameter check on the selected production stack remains a design and prototype RF review item, including the BLB01 bias network, decoupling, launches and interstage paths.

Primary sources: [BeRex BLB01 data sheet V6.6](https://documents.berex.com/BLB01-V6.6.pdf), [TAI-SAW TA2003A data sheet Rev 1.0](https://www.taisaw.com/assets/PDF/TA2003A%20_Rev.1.0_.pdf), [ADI ADL5513](https://www.analog.com/en/products/adl5513.html), and [Microchip MCP6566 data sheet DS20002143G](https://ww1.microchip.com/downloads/aemDocuments/documents/MSLD/ProductDocuments/DataSheets/MCP6566-6R-6U-7-9-1.8V-Low-Power-Open-Drain-Output-Comparator-DS20002143G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).

## Capture proof completed in repository

The clean-room host model in `firmware/rp2040_adsb/tools/validate_capture.py` generates an 8 MHz sampled pulse stream from a known valid 112-bit DF17 frame, finds the standard 8 us preamble, decodes pulse-position bits and checks the Mode S CRC polynomial. Its unit tests cover a valid frame, a corrupted frame and sample-level timing jitter.

The RP2040 UART transport behavior is tested on the host side: `firmware/rp2040_adsb/tools/framing.py` implements length-delimited records (SYNC/version/type/sequence/32-bit sample timestamp/length/payload/CRC16-CCITT) with 20 passing framing tests. They cover fixed payload shapes, 64-bit timestamp reconstruction across the sample-clock wrap, declared overflow plus sequence-gap detection, recovery after garbage/corrupt headers/CRC and a fragmented 200-contact stream. They do not model UART timing, PIO, DMA or sustained silicon throughput; those remain bench gates described in [the GPIO map](INTERFACE_GPIO_MAP.md).

RP2040 implementation target:

- sample/edge timing equivalent to at least 8 samples per microsecond, with PIO clock derived from the ABM8-272-T3 12 MHz reference and its PLL configuration;
- DMA ring with monotonic capture timestamps and explicit overrun counters, emitting OVERFLOW records per the framing contract;
- 56/112-bit length classification and parity status before host transfer;
- 921600 baud UART with RTS/CTS emitting the proven record format; resynchronize on any framing error without dropping the stream;
- no dependency on GPL ADSBee source. The pinned ADSBee design remains architectural research only.

## Prototype measurements required

1. Characterize each RF stage with VNA/spectrum analysis and the chosen JLC stack; verify the two BLB01 stages at the ADL5513 input stay below its compression under strong-blocker conditions.
2. Inject legal laboratory Mode S pulse fixtures through attenuation; sweep input level, threshold, temperature and supply.
3. Measure missed/false frames, pulse-width error, comparator delay distribution and recovery after strong blockers.
4. Stress with display refresh, SD writes, Wi-Fi and permitted LoRa transmissions; record blind intervals and RP2040 FIFO/DMA overflow (the host decoder exposes every declared drop).
5. Do not claim range or sensitivity until a conducted sensitivity curve and repeatable radiated comparison exist.

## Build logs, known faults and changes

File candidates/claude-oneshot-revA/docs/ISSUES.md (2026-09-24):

# Issues, findings and open gates — Claude one-shot candidate

Review updated: 2026-09-24. See [Astra's independent review](../../../docs/ASTRA_AGENT_REVIEW_2026_09_24.md) for fresh ERC/DRC, corrected claim dispositions and evidence limits. Scope: everything in `candidates/claude-oneshot-revA/`. Severity: **BLOCKER** (must close before any order or energizing), **MAJOR** (wrong or unverified item that changes copper/nets), **MINOR** (cleanup/verification).

This list is the most useful part of the package for the Astra comparison: an item here is either a defect found in the repository baseline, a choice this candidate had to make where the baseline is silent, or an open gate that no CAD pass can close.

## A. Defects found in the repository baseline (fix in `hardware/` / `docs/` independently of this candidate)

| # | Sev. | Finding | Evidence | Candidate handling |
| --- | --- | --- | --- | --- |
| A1 | MAJOR | `hardware/footprints/TI_DGS0010A_VSSOP-8_3x3mm_P0.65mm_TXU0202.kicad_mod` is the wrong package. `TXU0202DCUR` is the **DCU** VSSOP-8, 2.30 x 2.00 mm body, 0.5 mm pitch — not the 3 x 3 mm / 0.65 mm DGS/MSOP outline. | TI SCES942A (Nov 2021, rev Mar 2022) pin table and package summary | 2026-09-23: the generic KiCad land (1.25 x 0.35 mm at X +/-1.4) did not match TI's DCU0008A example (0.85 x 0.30 mm at X +/-1.55); replaced by `SC:TI_DCU0008A_VSSOP-8_2.3x2mm_P0.5mm_TXU0202` (copy of the corrected baseline). Assembler mask/paste review open |
| A2 | MAJOR | `hardware/footprints/TI_RPU0010A_VQFN-HR-10_2x2mm_TPS259474L.kicad_mod` is the wrong package. `TPS259474LRPWR` ships in **RPW0010A** (0.45 mm side pitch, L-shaped corner pads 1/4/7/10, 0.3 x 2.4 mm IN/OUT pads 5/6), not the RPU0010A (0.5 mm pitch) outline copied from TPS62912. | TI SLVSFC9C rev May 2026, package drawing 4225183/A 08/2019, pages 72-74 | 2026-09-23: copper re-checked against TI's vector drawing and matches; paste changed to TI's p.74 stencil (corner 93 %, centre pads split 82 %), fab body corrected to 2.0 mm. Assembler approval and independent review still required |
| A3 | MAJOR | `BM12B-GHS-TBT` is JST's **vertical (top-entry)** GH header (KiCad: `JST_GH_BM12B-GHS-TBT_1x12-1MP_P1.25mm_Vertical`). The BOM/connector docs call it "right-angle SMT"; the right-angle part is `SM12B-GHS-TB`. The orientation drives enclosure and floorplan. | JST GH naming; KiCad 10.0.6 library | Candidate keeps the documented MPN (vertical) and puts it on the **board back** (left strip beside the holder) so the cable exits the rear shell. Owner must pick MPN + orientation |
| A4 | MINOR | XF3M hold-down land size: the Omron catalog mirror's "PCB Dimensions (TOP VIEW)" gives F (inner) / G (outer) spans whose difference is 2 x 1.8 mm; repo text records 1.50 x 2.20 mm hold-down lands. | Omron G146-E1 (omronfs mirror), table + drawing; `docs/DISPLAY_REQUIREMENTS.md` | Footprint uses 1.8 x 2.2 mm derived from F/G; confirm against controlled G146-E1-05 |
| A5 | MAJOR | `EXP_CS` (expansion SPI chip select, CONNECTOR_ARCHITECTURE pin 9) has **no ESP32 GPIO** in `INTERFACE_GPIO_MAP.md`; every non-strap GPIO is already allocated. | GPIO map vs connector map | Candidate drives `EXP_CS_N` from TCA9535 P07 (slow, I2C-latency CS). Alternative: repurpose GPIO8 `LCD_AUX` |
| A6 | MAJOR | `SX1262 NRESET` is not allocated anywhere (GPIO map or DIG-03 port map). | Same | Candidate uses TCA9535 P10 (reserved "SX aux" port) with the existing 100 k pull-up (released by default) |
| A7 | MINOR | DIG-01 requires RP2040 `RUN` host control through the expander, but the DIG-03 port map has no RUN port. | DIGITAL_SUPPORT_REVIEW vs CONTROL_IO_REVIEW | Candidate uses spare P14 (`RP_RUN`) |
| A8 | MINOR | Touch-controller RESET needs its own 3.3 V-safe control (DISPLAY_REQUIREMENTS) but no port is left after A5-A7. | Same | Touch RESET shares `LCD_RST_CTRL` (P06, 100 k pull-down = reset asserted at power-up). Verify ST1633I timing on samples |
| A9 | MINOR | `TPS62130A` "0.1 uF SS/TR" in POWER_ARCHITECTURE_REVIEW gives ~50 ms soft start by TI Eq.10 (Css = tss x 2.5 uA / 1.25 V). TI 9.2 typical uses 3.3 nF. | TI SLVSAG7F section 9.2.2.2.2.3 | Candidate uses 3.3 nF (~1.65 ms); feed-forward 3.3 nF fitted per repo text; reviewer decides |
| A10 | MAJOR | No main power switch / power button exists in the product baseline. With BQ25887 (no power path) the buck is on whenever the protected pack is present; always-on loads (TUSB320LAI ~70 uA, expander, pull-ups, GNSS, LDOs) drain a stored unit. | PRODUCT_REQUIREMENTS / POWER_RAIL_PLAN | Buck EN pulled to PACK_P. Product decision required (switch, ship mode, protector power-down) |
| A11 | MINOR | T5838 data sheet rev 1.1 (cited in repo) could not be retrieved; rev 1.0 (same DS-000383) was used for the land pattern. | TDK site serves a JS shell to non-browser clients | Reconcile with rev 1.1/1.2 before release |
| A13 | **BLOCKER** | `hardware/footprints/MEMSIC_MMC5983MA_LGA-16_3x3mm_P0.5mm.kicad_mod` places pad centres at +/-1.05 mm. MEMSIC Rev A "LAND PATTERN" dimensions **2.550 mm centre-to-centre** (pad 0.45 x 0.30, pitch 0.5), i.e. +/-1.275 mm. With +/-1.05 the corner pads overlap by 0.075 mm: pin 16 (SDA) shorts pin 1 (SCL), 4 shorts 5, 8 shorts 9, 12 shorts 13. KiCad DRC reports `shorting_items`. The earlier "independent dimensional review" missed it. | MEMSIC MMC5983MA Rev A p.20 land pattern (rendered and measured 2026-09-23) | Candidate uses `SC:MEMSIC_MMC5983MA_LGA-16_3x3mm_P0.5mm_CORRECTED` (same pad numbering, centres +/-1.275); 2026-09-23: embedded copy equals the corrected baseline, pin 1 top-right per p.20 top view |
| A14 | **BLOCKER** | `hardware/footprints/Bosch_BMP581_LGA-10_2x2mm.kicad_mod` places all pad centres at +/-0.6 mm. Bosch Figure 32 dimensions **1.525 mm centre-to-centre** for both the 3-pad rows and the 2-pad sides (+/-0.7625 mm) and asks for >= 200 um between pads. The repo file leaves 0.0375 mm between corner pads 2/3 and 5/6 (DRC clearance error). | Bosch BST-BMP581-DS004-13 section 8.2, Figure 32 (bottom view) | Candidate uses `SC:Bosch_BMP581_LGA-10_2x2mm_CORRECTED` (centres +/-0.7625, 0.2 mm corner gap). Figure 32 is a bottom view; 2026-09-23: embedded copy equals the corrected baseline and its numbering is a 90-degree rotation of the Figure 23 top view (not mirrored) |
| A15 | MAJOR | The accepted 2S holder (82.2 x 45.1 mm) covers the whole board back for x >= 14.7 mm, so no mounting hole can exist on the right side of an 84 x 60 mm board, and any THT part (USB-C shell stakes, holes) in that band conflicts with the holder base. | Floorplan geometry + DRC `pth/npth_inside_courtyard` | Candidate keeps 3 M2.5 holes in the left strip, moves USB-C left (x 8 mm) and assumes the holder is fixed to the rear shell |
| A16 | MAJOR | With the ESP32-S3 antenna at the top edge (earlier plan), the right-aligned cell cans sit directly behind the antenna end. | 3D fit | Candidate rotates the module 90 deg: antenna at the LEFT edge (x 0.3-6.3 mm), >= 8 mm clear of the holder in plan view |
| A12 | MINOR | BMP581 `INT` is an output tied to GND per the repo sensor sheet. KiCad ERC flags output-to-ground (1 remaining ERC error). | `hardware/kicad/04_sensors.kicad_sch`, ERC report | 2026-09-23: confirmed against DS004-13 Table 28 note a / §6.2 (GND allowed and recommended if `INT_CONFIG.int_en` stays disabled; reset value 0). Kept; ERC error left visible, firmware must never enable INT |

## B. Open gates carried from the repository (NOT closed by this candidate)

| Gate | Status in candidate |
| --- | --- |
| **O05 battery safety (BLOCKER)** | Protection is the documented *conflicting* low-side S-8252-family + dual N-FET position; product code, FETs, fuse, NTC coupling, RCBSET, charge-under-load, dead-pack deadlock (fail-safe CD needs firmware to enable charging) all **TBD**. A qualified human reviewer must redesign/approve. Do not energize with cells. |
| O06 USB input | ITIMER capacitor DNP/TBD; PGTH divider is a candidate choice |
| O01/display (BLOCKER for footprint) | Controlled Orient drawing (rev J vs G), FPC tail lengths/exit positions, VCC vs VDDI domain, unused-pin ties (DB0-17, RGB sync, RD/WR) all TBD. FPC connector footprints are candidates from the Omron catalog; two labeled samples required |
| LoRa RF | Every TX match / harmonic filter / RX balun / DC-block value is **TBD** (AN1200.40 prints designators only). 32 MHz crystal MPN TBD. Topology only |
| ADS-B RF | Threshold divider blocked by OWN-09; ADL5513 TADJ value and CLPF (1 nF basic value is too slow for 0.5 us pulses) TBD; ADL5513 exposed-pad land (CP-16-22) unverified — KiCad `EP1.7x1.7` placeholder |
| GNSS | Assembler T-paste approval, RF/PDN review; GCPW geometry not implemented (autorouted 0.15 mm trace) |
| Stackup | JLC04161H-3313 candidate widths (0.133-0.15 mm 50 ohm) not solver-confirmed; RF nets use a 0.15 mm net class only |
| DFT (O28) | Test pads placed for rails, SWD, RUN, USB_BOOT, PPS, I2C, ADS-B video/pulse, charger status; coordinates are Astra/reviewer work |
| Mechanical | Holder MPN and tab positions are placeholders; enclosure is a concept with no tolerance stack; printed fit dummy required |

## C. Layout-level limitations of this one-shot

- **Open connections (2 after the 2026-09-23 GND stitch; was 5 after the refinement, 11 originally; see `outputs/drc_summary.txt`)**: SX1262 `LORA_RFO`/`LORA_RFI_P` (RF blocker, values/layout TBD by design). The GND connections at U2 pads 3/8, U3 pad 8 and U24 pad 2 listed below in D3 were closed the same day by a second pass — evidence and before/after DRC in [GND_STITCH_2026_09_23.md](GND_STITCH_2026_09_23.md). Residual: 10 clearance items at the U3 east rail (chord dips near the EFUSE_ILM via and the TP1 fill island; sub-50 µm margins, queued for the manual KiCad review pass). The SHT40 SDA, both 3V3_MAIN links, C57 and three GND fragments (U7 buck exposed pad, ICM pads 9-11, BMP581 SDO/C35) were connected. The September 24 report lists five disabled DRC check categories; full validation cannot be inferred from enabled checks alone.
- **LoRa RF block**: topology only. The TX match / harmonic filter / RX balun parts are placed as generic 0402 positions around the SX1262 with TBD values; the block must be re-placed and hand-routed from the native E449 layout on this stack before any value or performance statement.
- Placement follows the floorplan zones; ICs have fixed engineering positions, and small parts are placed by an anchor search (engineering anchor map for hot-loop/protection parts: eFuse/ESD/CC controller at USB-C, charger passives and CD FET at the BQ25887, backlight diode at the TPS61169, SD switch/ESD at the socket, ADS-B switch at the RP2040). Decoupling loops, the BQ25887/TPS62130A hot loops and the TPS61169 SW loop are **not** hand-optimised.
- Routing is Freerouting + an A* clean-up router. RF paths (GNSS, ADS-B chain, LoRa) and the USB pair have no dedicated GCPW/differential geometry; RF claims require hand re-routing on the solver-confirmed stack.
- The ESP32-S3 module's antenna rule area (x <= 6.3 mm) holds no copper. Correction 2026-09-23: the former DRC error was a 0.09 mm overlap between J5 and the module-**body** courtyard, not the antenna keepout; J5 moved +0.4 mm. The full 15 mm off-board clearance still depends on the enclosure.
- `In1.Cu` is a continuous GND plane; `In2.Cu` carries signals, a `3V3_MAIN` pour in the core/LoRa area and GND elsewhere; outer layers have GND pours with ~400 automatically placed stitching vias. Shield-can areas are not designed.
- The display is modelled as an envelope 5 mm above the PCB on a printed frame (assumption); FPC tail exits, lengths and fold radius are TBD from the controlled Orient drawing.
- Enclosure: two-part concept (front bezel 11.5 mm incl. display window, back shell 25.5 mm incl. 2S holder) = 37 mm total, matching the planning envelope; no tolerance stack, snap/screw design or battery door mechanism.

## D. Findings from the 2026-09-23 refinement (see [REFINEMENT_2026_09_23.md](REFINEMENT_2026_09_23.md))

| # | Sev. | Finding | Status |
| --- | --- | --- | --- |
| D1 | MAJOR | ICM-42688-P pin 9 INT2/FSYNC/CLKIN was a no-connect; TDK DS-000347 v1.9 Table 10 and `docs/SENSOR_ARCHITECTURE.md` require GND when FSYNC is unused | Fixed in schematic and board |
| D2 | MAJOR | U30/U32 carried an unreviewed `allow_soldermask_bridges` flag that hid 199+ mask-bridge findings, including other-net tracks/vias exposed inside the no-mask openings | Flag removed; findings visible; assembler mask decision and escape routing open |
| D3 | ~~BLOCKER~~ | GND of U2 (USB ESD), U3 pad 8 (eFuse) and U24 pad 2 (TXU0202) was not connected; U7 buck EP had one via | **Fixed 2026-09-23** by local re-layout ([GND_BUCK_RELAYOUT.md](review_notes/GND_BUCK_RELAYOUT.md)): GND vias at U2/U3/U24, In2 VBUS/B.Cu SDA/USB_DP re-routed, 4 EP vias at U7; GND is one copper group |
| D4 | MAJOR | BQ25887 BTST (C12, 17 mm) and REGN (C13, 16 mm) caps far from U6; TPS62130A inductor 5.9 mm with BUCK_SW on In2 and SD_CT on B.Cu under the IC (only one exposed-pad via fits) | Recorded; charger block stays under the O05 gate |
| D5 | MINOR | C57 (touch 3V3 decoupling) cannot sit at J4 because the J8 microSD card envelope covers the area; moved onto the nearest 3V3 feed instead | Placement at the touch connector remains a layout item |
| D6 | MAJOR | TPS62130A footprint was the generic KiCad QFN-16 (lands 0.775 x 0.25 at +/-1.4625, EP 1.75); TI SLVSAG7F p.41 RGT0016C gives 0.6 x 0.24 at +/-1.4, EP 1.68, EP paste 1.55 | **Fixed 2026-09-23** in the candidate (U7 = `SC:TI_RGT0016C_VQFN-16_3x3mm_EP1.68x1.68_TPS62130A`, [note](review_notes/TPS62130A_RGT_FOOTPRINT.md)); the baseline file in `hardware/footprints/` has the same defect and needs an owner-approved correction |
| D7 | MINOR | 274 silk references at 0.6 mm violated the board's 0.8 mm rule; KiCad reports only 199 items per type | 202 passive references moved to the assembly (Fab) layer, 75 kept at 0.8 mm |
| D8 | MAJOR | `08_lora` topology differs from the Semtech E449V01A native design (RX balun wiring, missing 2nd-harmonic trap C4, DC block position, antenna-side pi C9/L5/C10, L2, C2, C16; crystal vs TCXO) | Exact E449 values recorded in [SX1262_E449_REFERENCE_VALUES.md](review_notes/SX1262_E449_REFERENCE_VALUES.md); redraw the sheet to E449 topology, then layout on the chosen stack, simulation/VNA and conducted tests (AGENTS rule 5). Crystal vs TCXO is an owner decision |
| D9 | MAJOR | ESP32 antenna overlaps the display envelope projection (x 4.78-6.3, y 13.6-19.3) — violates `MECHANICAL_RF_FLOORPLAN.md`; FR-4 kept under the antenna against Espressif's "cut off the base board" guidance | Display/mechanical ENGINEERING_RETURN (needs the Orient drawing); see [ESP32 audit](review_notes/ESP32_USB_BUTTONS_AUDIT.md) |
| D10 | MINOR | USB-C J1 sits 0.3 mm inboard of GCT's PCB-edge line; enclosure wall (2.0 mm + 0.4 mm gap) exceeds GCT's 1.85 mm overmold clearance; buttons need printed plungers | Moving J1 was tried and reverted (collides with the D+/D- crossover and a B.Cu VBUS_PROT track); thin the wall locally to <= 1.2 mm and add plungers in the fit dummy |
| D11 | MAJOR | Cost snapshot: five-unit subtotal >= ~BRL 504/unit for priced parts only (BRL 691-726 with PCB+PCBA estimate) vs the BRL 200 target | Owner decision (D24); see [cost snapshot](review_notes/ASSEMBLER_MASK_AND_COST_SNAPSHOT.md) |
| D12 | MINOR | GPIO gaps A5-A8 | Evidence-backed options and recommendation in [GPIO_GAPS_A5_A8_PROPOSAL.md](review_notes/GPIO_GAPS_A5_A8_PROPOSAL.md); candidate choices recorded in [OWNER_DECISIONS_2026_09_24.md](OWNER_DECISIONS_2026_09_24.md); A5/A8 CAD edits and A6/A7 behavior/rail validation remain open |
| D13 | MINOR | Errata found in root docs (not edited here): `docs/RF_ARCHITECTURE.md` (L7 15 nH vs native 15 uH, C1 0.1 uF vs 47 nF, E428 is 4-layer, etc.), `docs/INTERFACE_GPIO_MAP.md` (GPIO46 "input-only"), `docs/CONTROL_IO_REVIEW.md` (TCA9535 has no RESET pin) | For the integrator to correct in the baseline docs |

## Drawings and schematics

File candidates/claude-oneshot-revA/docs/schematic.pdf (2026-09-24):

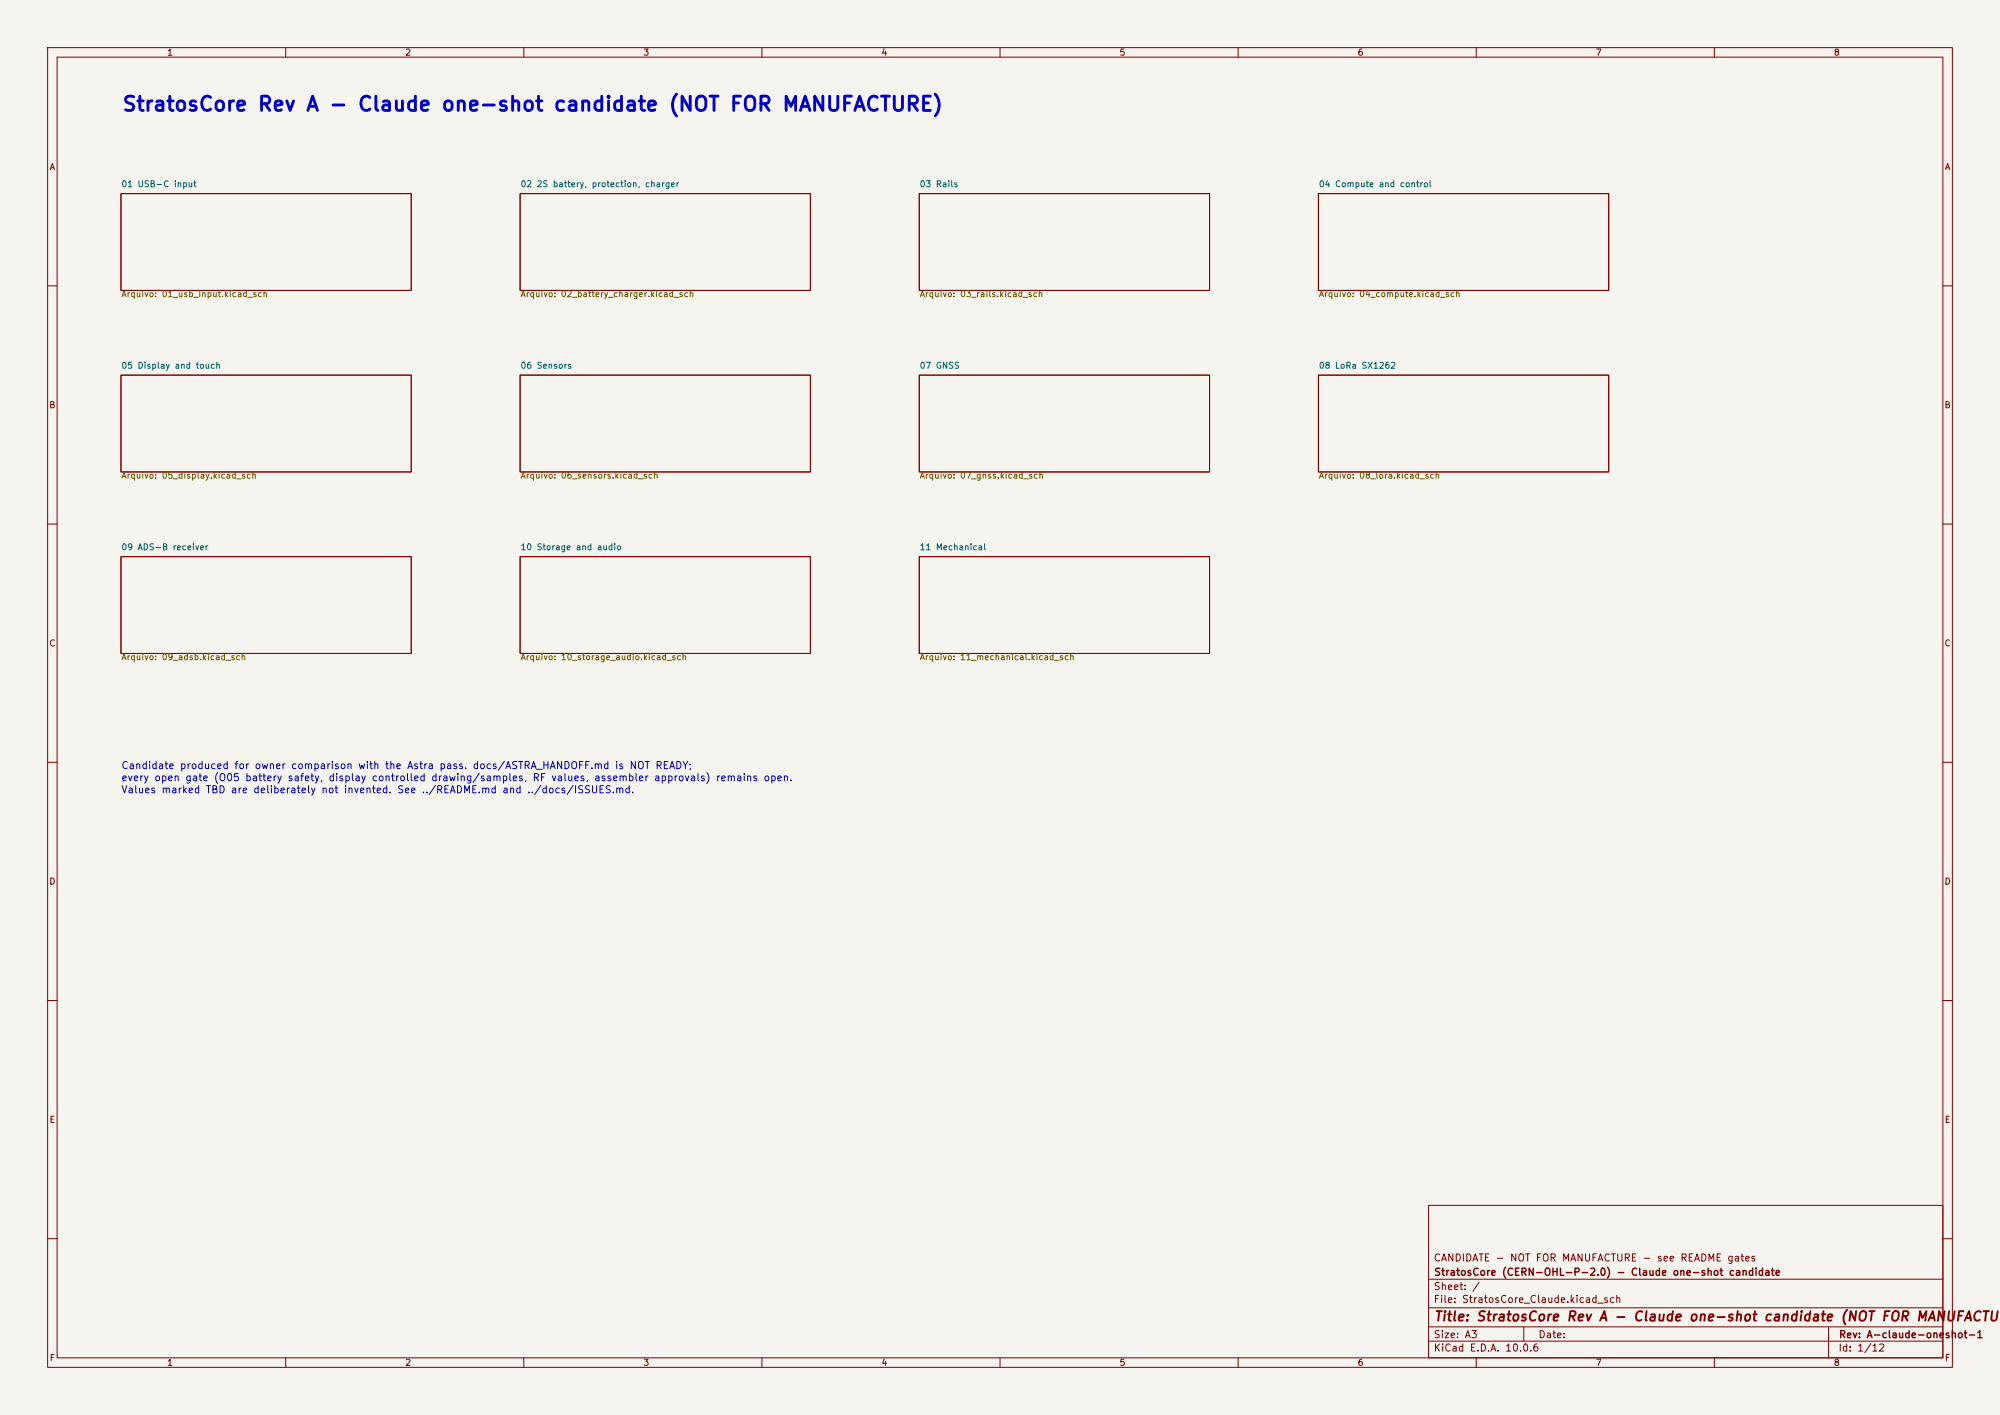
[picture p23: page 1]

StratosCore Rev A - Claude one-shot candidate (NOT FOR MANUFACTURE)

Arquivo: 02_battery_charger.kicad_sch 06 Sensors Arquivo: 06_sensors.kicad_sch 05 Display and touch

Candidate produced for owner comparison with the Astra pass. docs/ASTRA_HANDOFF.md is NOT READY;
every open gate (O05 battery safety, display controlled drawing/samples, RF values, assembler approvals) remains open.
Values marked TBD are deliberately not invented. See ../README.md and ../docs/ISSUES.md.

CANDIDATE - NOT FOR MANUFACTURE - see README gates
StratosCore (CERN-OHL-P-2.0) - Claude one-shot candidate
Sheet: /
File: StratosCore_Claude.kicad_sch
Title: StratosCore Rev A - Claude one-shot candidate (NOT FOR MANUFACTURE)

F Date:

KiCad E.D.A. 10.0.6 | Id: 1/12

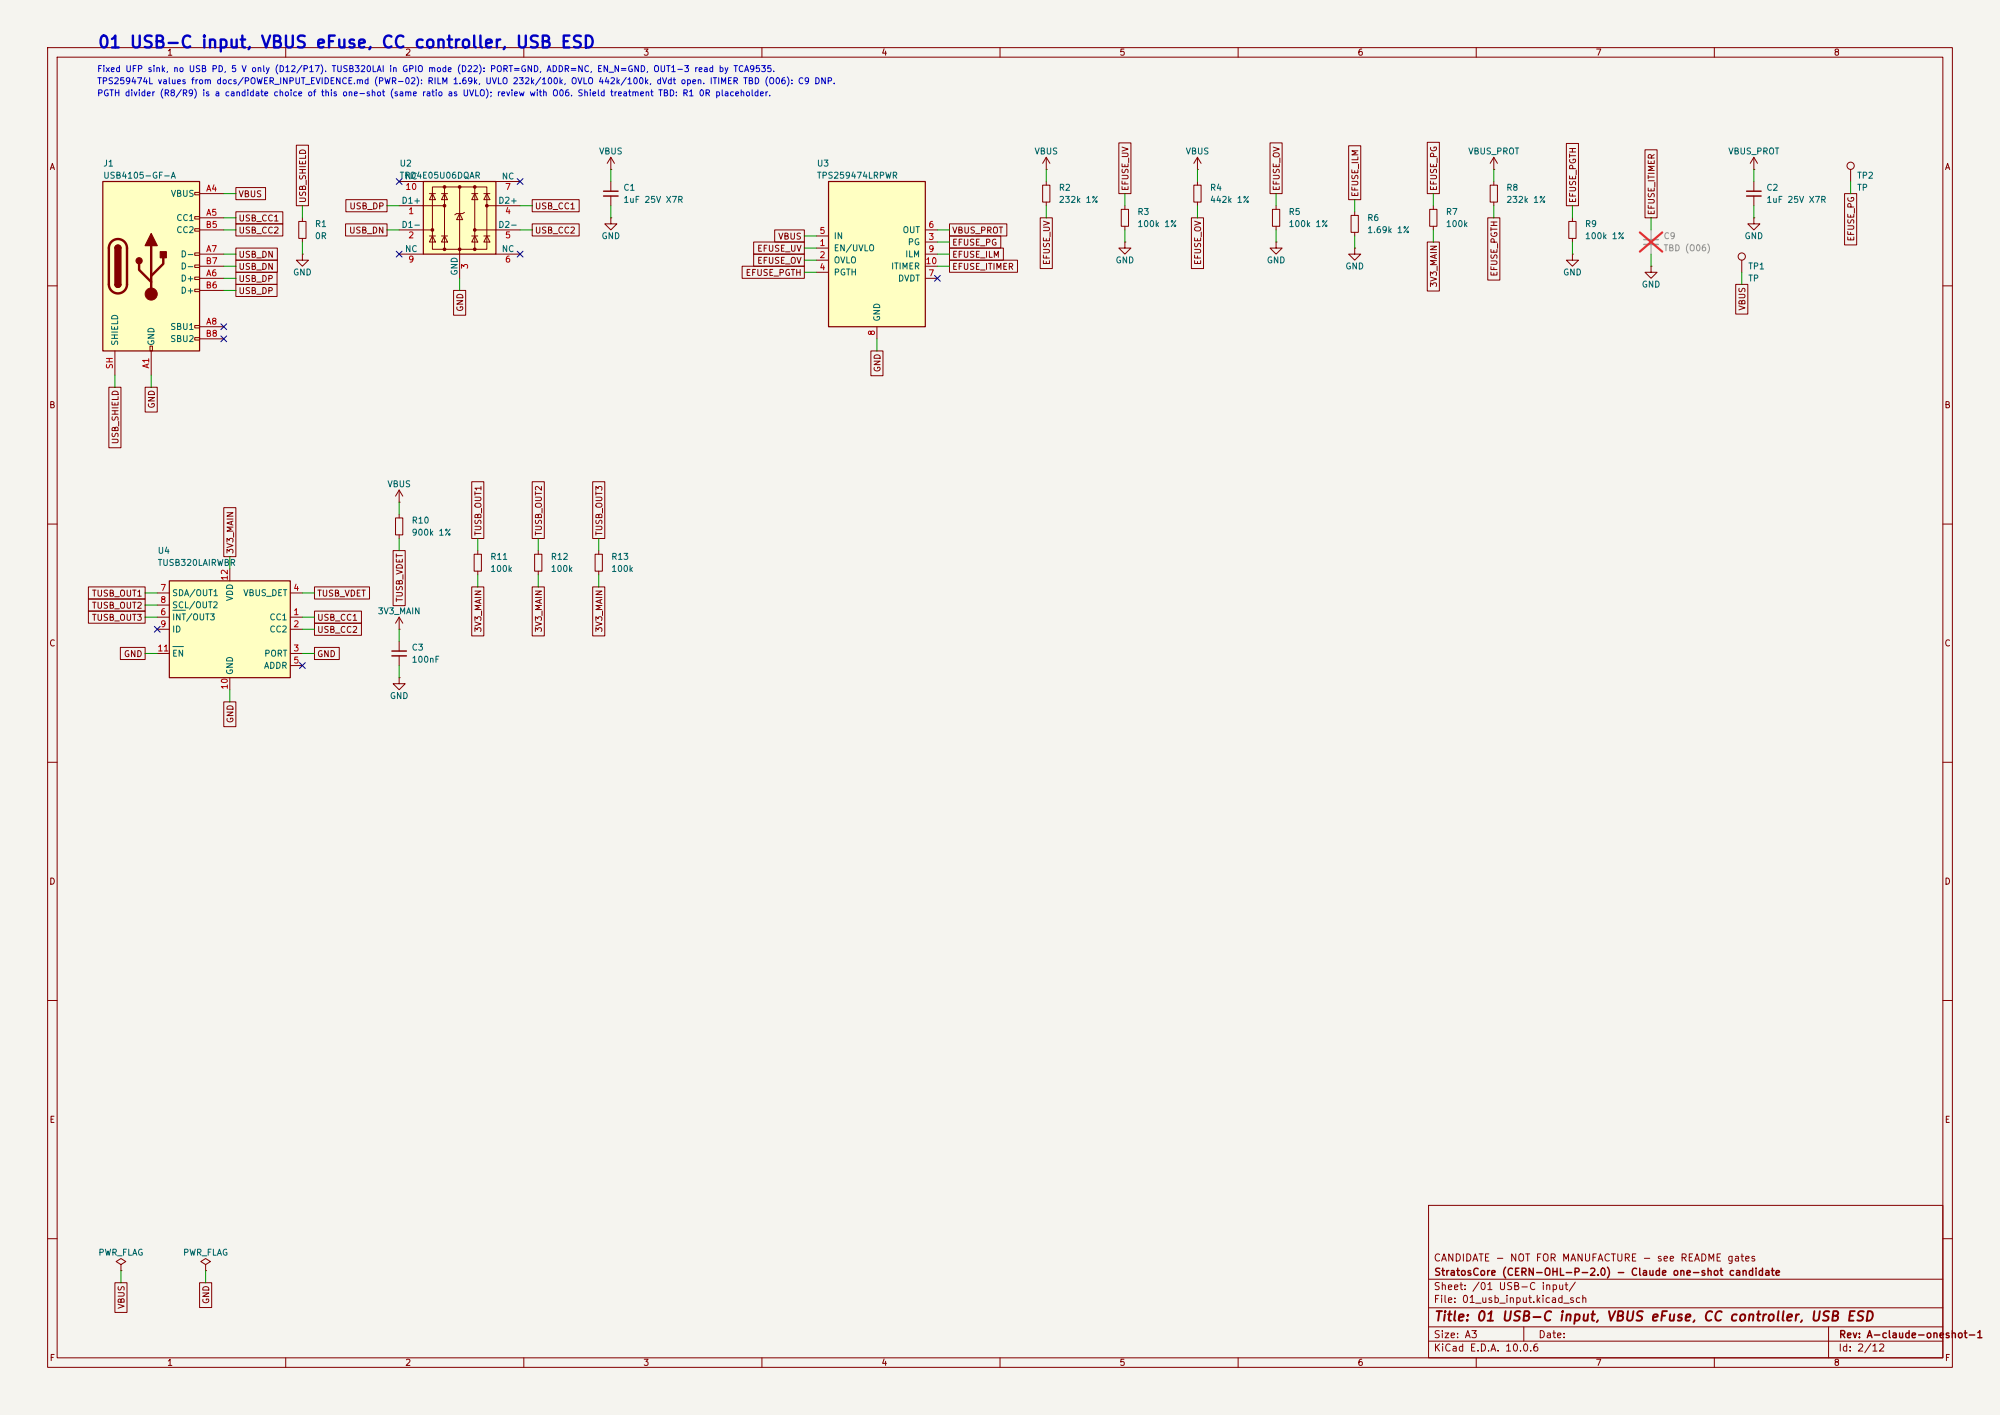
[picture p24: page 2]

01 USB-C input, VBUS eFuse, CC controller, USB ESD
USB_DP USB_CC2 GND USB_DN

Fixed UFP sink, no USB PD, 5 V only (D12/P17). TUSB320LAI in GPIO mode (D22): PORT=GND, ADDR=NC, EN_N=GND, OUT1-3 read by TCA9535. TPS259474L values from docs/POWER_INPUT_EVIDENCE.md (PWR-02): RILM 1.69k, UVLO 232k/100k, OVLO 442k/100k, dVdt open. ITIMER TBD (O06): C9 DNP. PGTH divider (R8/R9) is a candidate choice of this one-shot (same ratio as UVLO); review with O06. Shield treatment TBD: R1 0R placeholder.

CANDIDATE - NOT FOR MANUFACTURE - see README gates
StratosCore (CERN-OHL-P-2.0) - Claude one-shot candidate
Sheet: /01 USB-C input/
File: 01_usb_input.kicad_sch
Title: 01 USB-C input, VBUS eFuse, CC controller, USB ESD

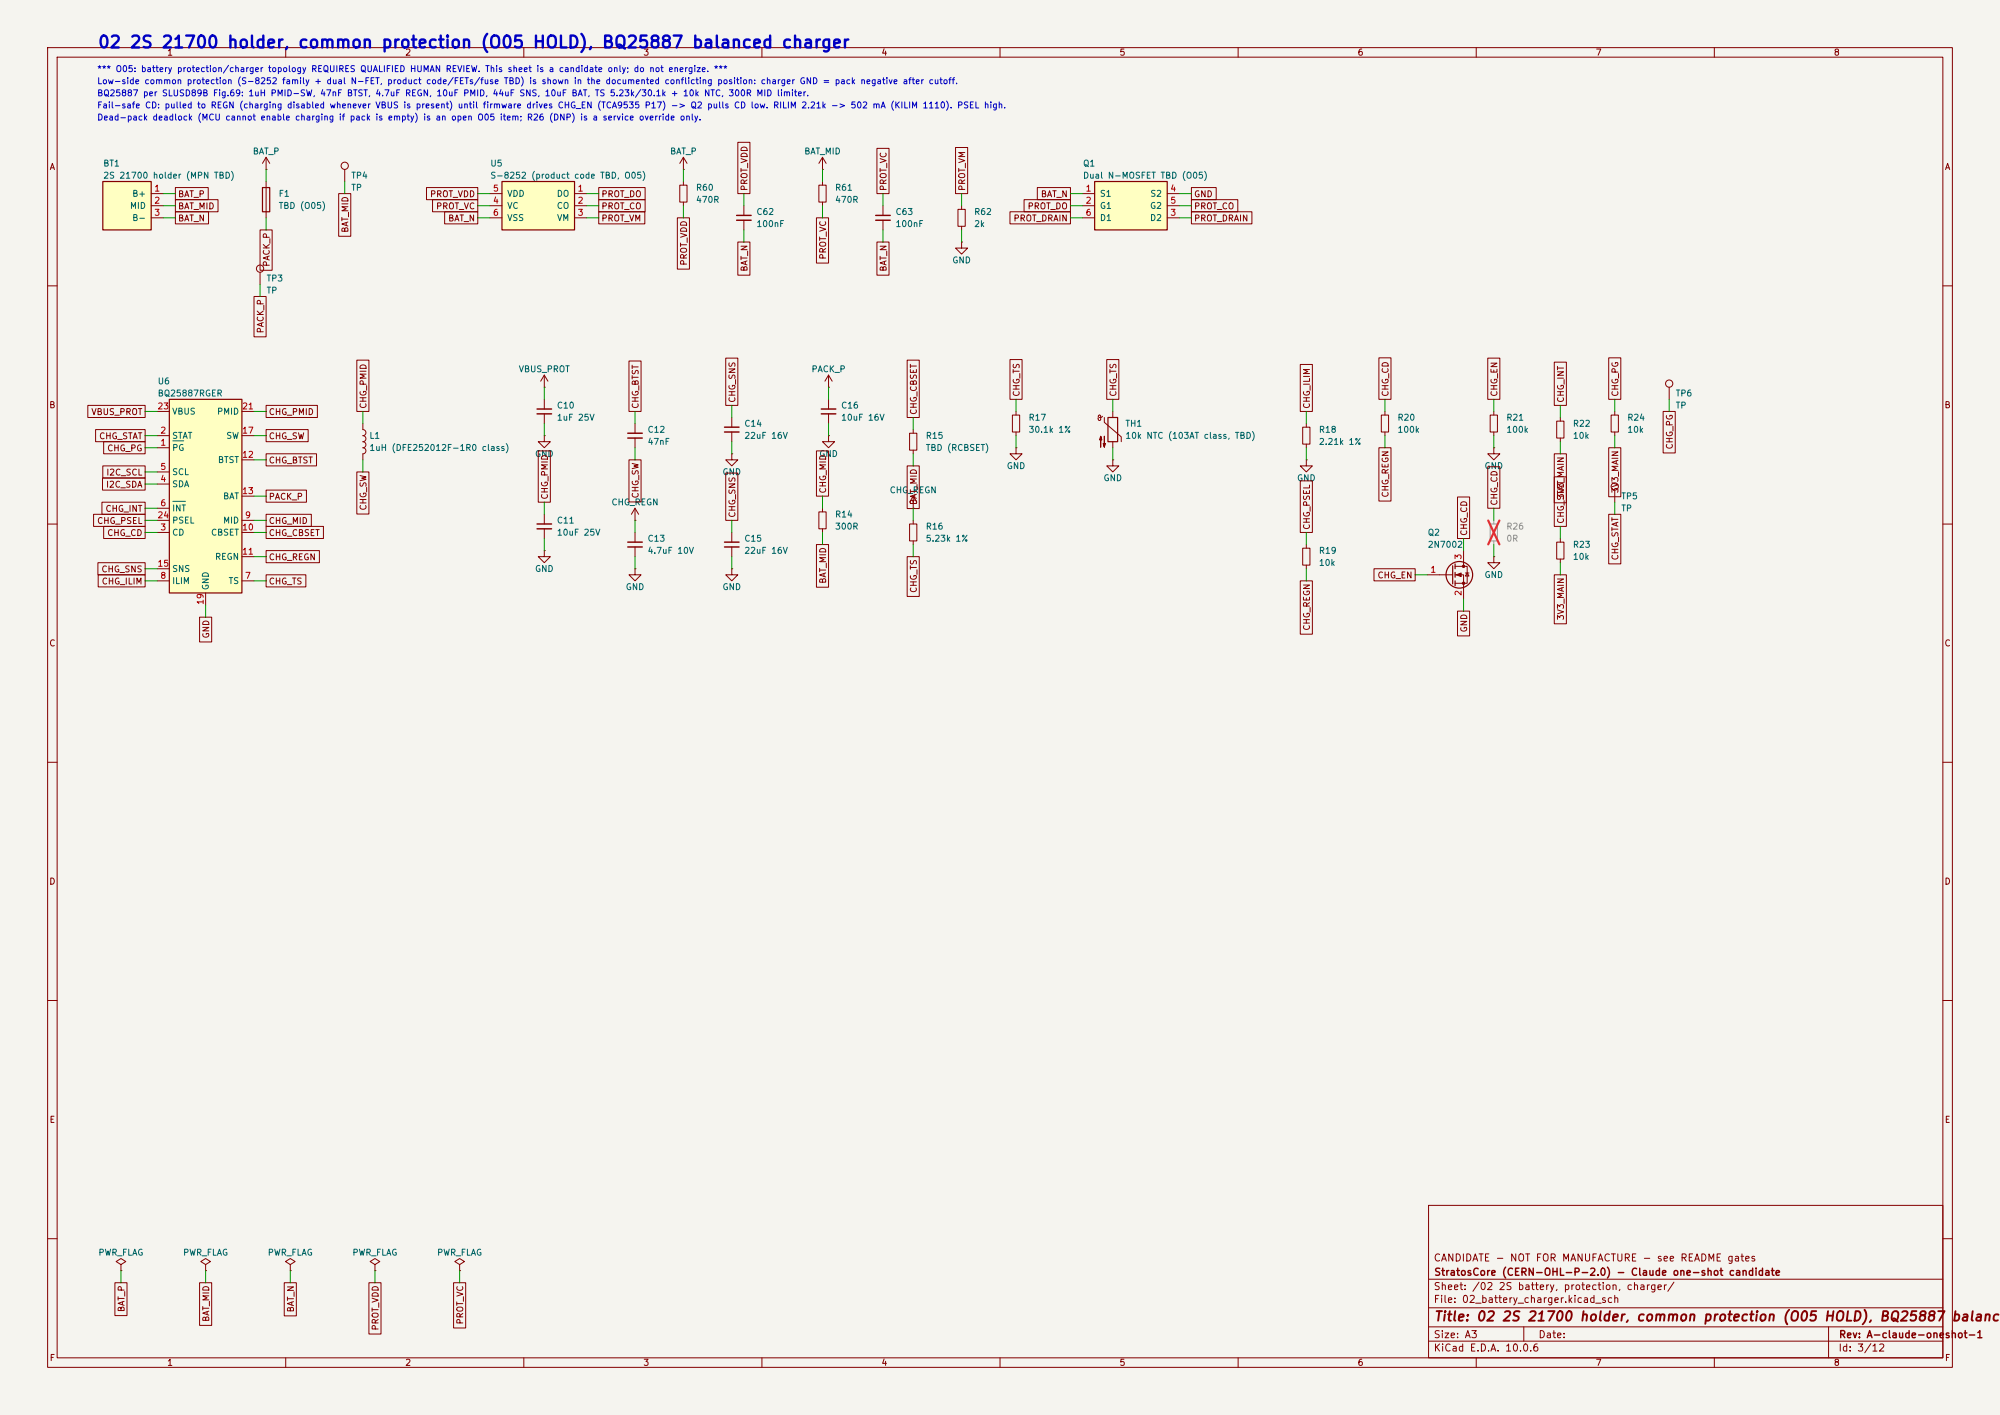
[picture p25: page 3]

Low-side common protection (S-8252 family + dual N-FET, product code/FETs/fuse TBD) is shown in the documented conflicting position: charger GND = pack negative after cutoff. Dead-pack deadlock (MCU cannot enable charging if pack is empty) is an open O05 item; R26 (DNP) is a service override only. Fail-safe CD: pulled to REGN (charging disabled whenever VBUS is present) until firmware drives CHG_EN (TCA9535 P17) -> Q2 pulls CD low. RILIM 2.21k -> 502 mA (KILIM 1110). PSEL high. BQ25887 per SLUSD89B Fig.69: 1uH PMID-SW, 47nF BTST, 4.7uF REGN, 10uF PMID, 44uF SNS, 10uF BAT, TS 5.23k/30.1k + 10k NTC, 300R MID limiter. 02 2S 21700 holder, common protection (O05 HOLD), BQ25887 balanced charger
PROT_VM BAT_P

*** O05: battery protection/charger topology REQUIRES QUALIFIED HUMAN REVIEW. This sheet is a candidate only; do not energize. ***

10k NTC (103AT class, TBD) GND

CANDIDATE - NOT FOR MANUFACTURE - see README gates
StratosCore (CERN-OHL-P-2.0) - Claude one-shot candidate
Sheet: /02 2S battery, protection, charger/
File: 02_battery_charger.kicad_sch
Title: 02 2S 21700 holder, common protection (O05 HOLD), BQ25887 balanced charger

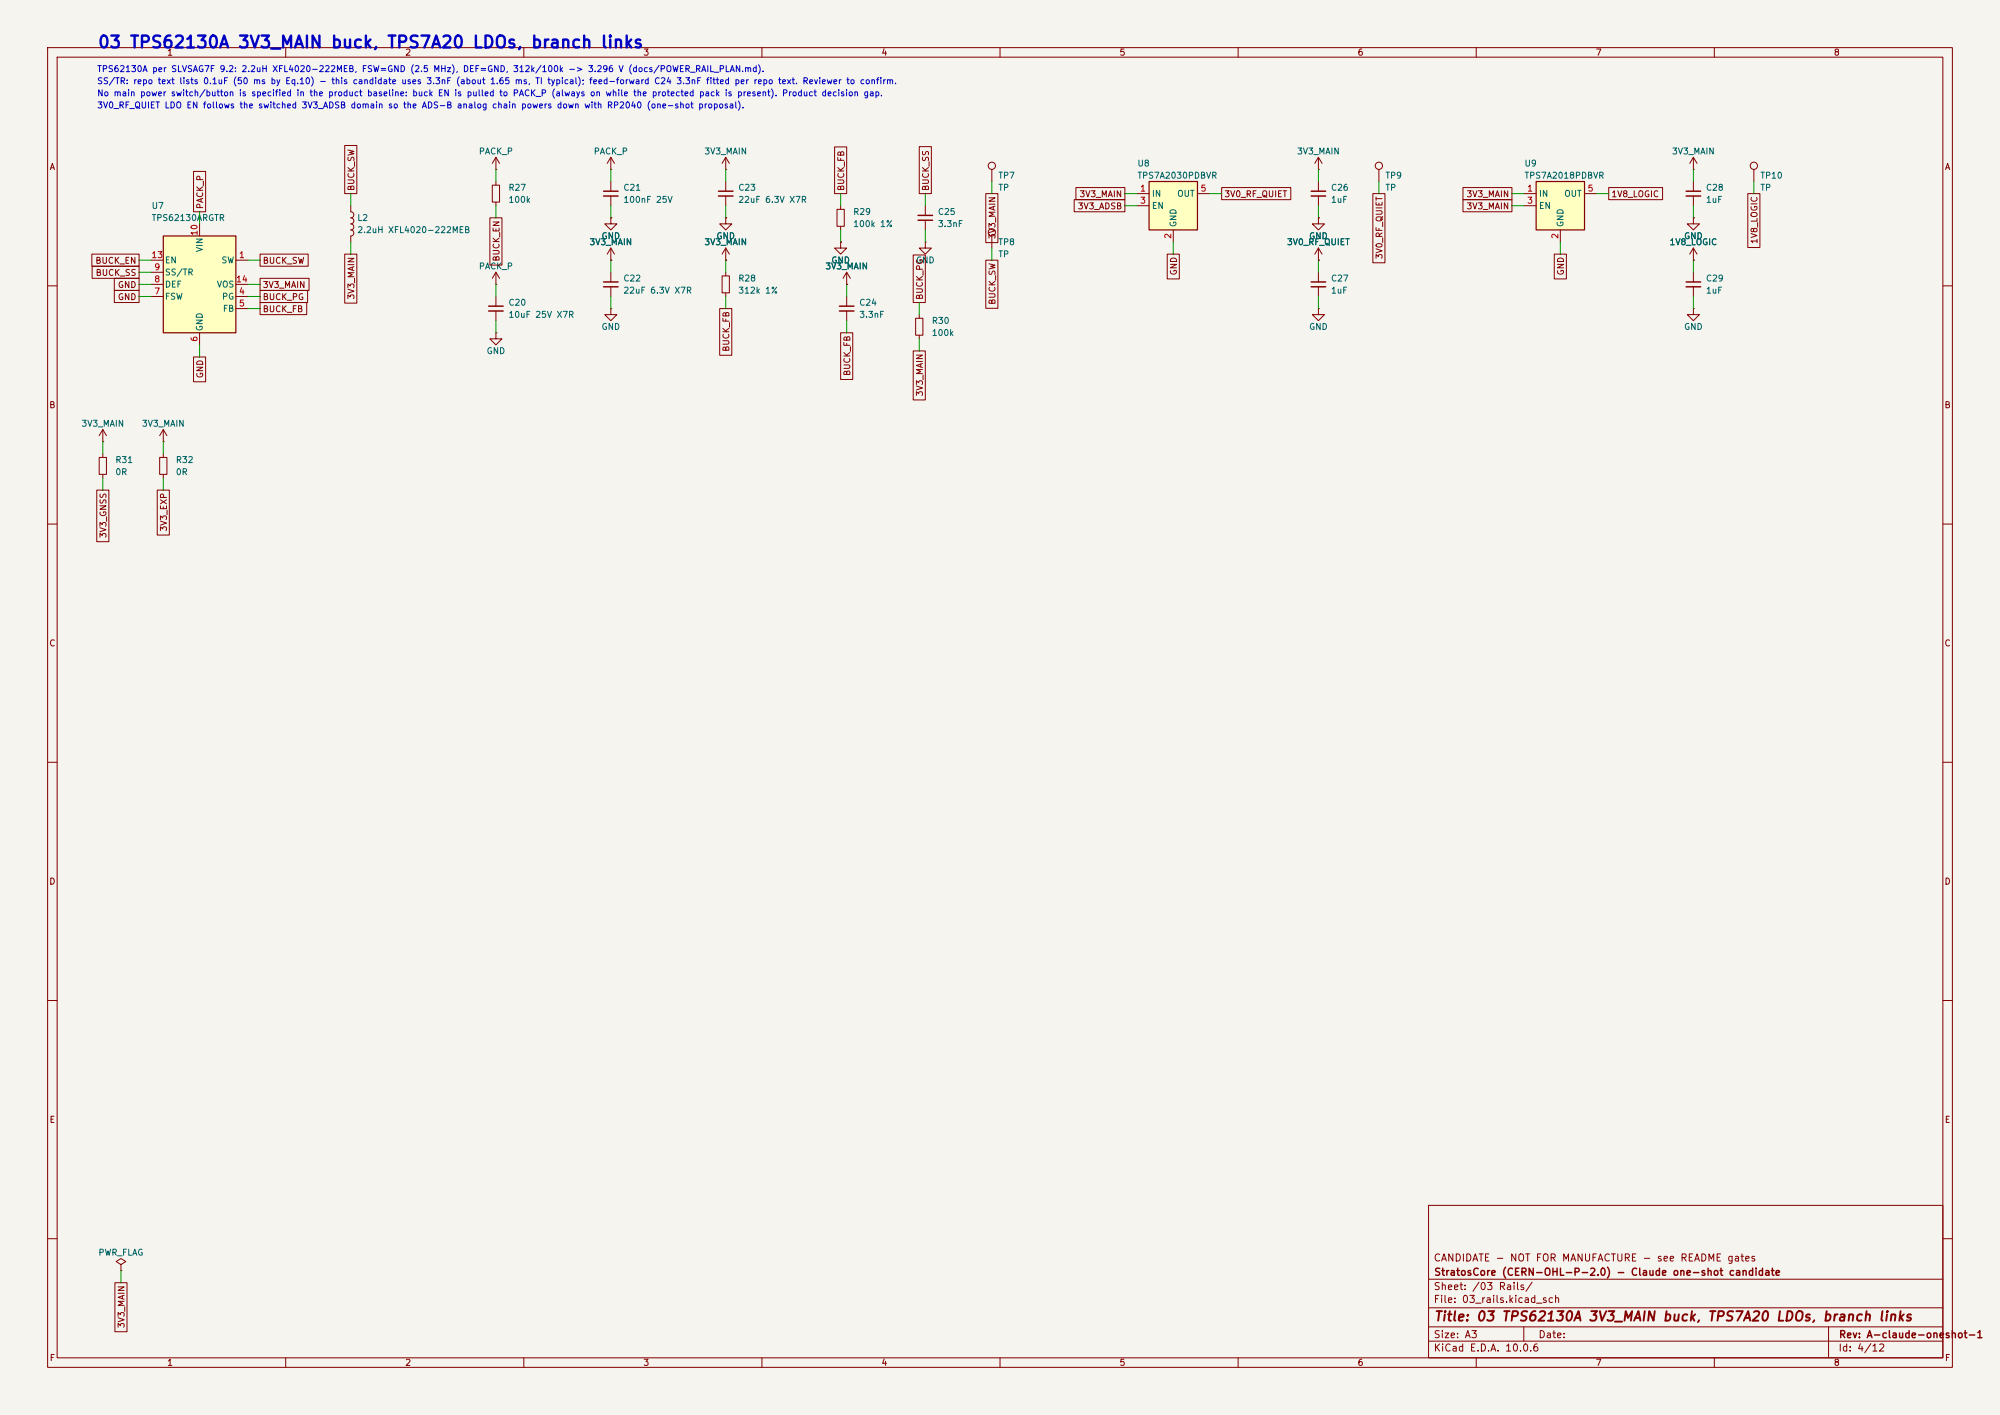
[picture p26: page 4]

03 TPS62130A 3V3_MAIN buck, TPS7A20 LDOs, branch links

3V0_RF_QUIET LDO EN follows the switched 3V3_ADSB domain so the ADS-B analog chain powers down with RP2040 (one-shot proposal). No main power switch/button is specified in the product baseline: buck EN is pulled to PACK_P (always on while the protected pack is present). Product decision gap. SS/TR: repo text lists 0.1uF (50 ms by Eq.10) - this candidate uses 3.3nF (about 1.65 ms, TI typical); feed-forward C24 3.3nF fitted per repo text. Reviewer to confirm. TPS62130A per SLVSAG7F 9.2: 2.2uH XFL4020-222MEB, FSW=GND (2.5 MHz), DEF=GND, 312k/100k -> 3.296 V (docs/POWER_RAIL_PLAN.md).

CANDIDATE - NOT FOR MANUFACTURE - see README gates
StratosCore (CERN-OHL-P-2.0) - Claude one-shot candidate
Sheet: /03 Rails/
File: 03_rails.kicad_sch
Title: 03 TPS62130A 3V3_MAIN buck, TPS7A20 LDOs, branch links

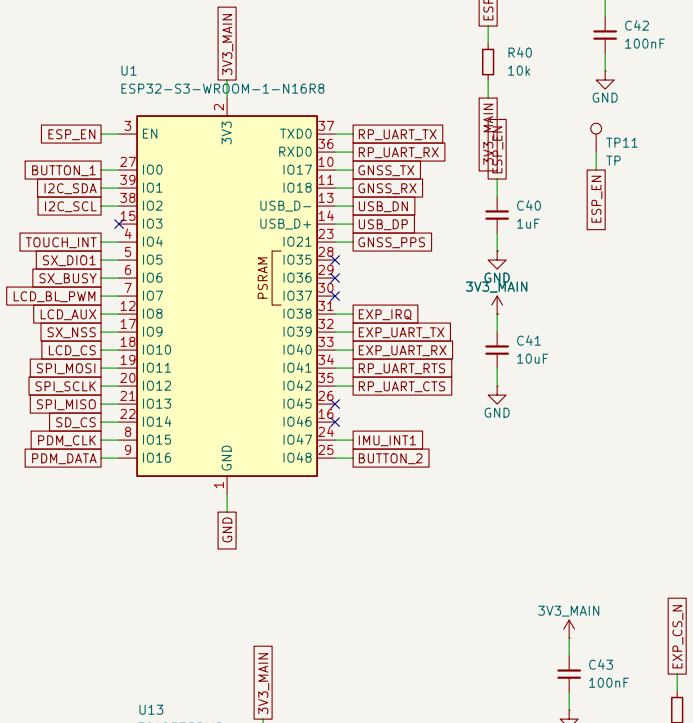
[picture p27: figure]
USB_D- 13 USB_D+ 14 IO3 15; IO42 35 RXD0 36 TXD0 37; GND; TOUCH_INT; GNSS_RX; LCD_CS; GNSS_TX RP_UART_CTS; SX_BUSY SX_DIO1 PDM_CLK; IMU_INT1; SD_CS BUTTON_1; SPI_MISO; EXP_CS_N; ESP_EN; SPI_SCLK; 3V3_MAIN; SPI_MOSI; BUTTON_2; EXP_IRQ; GNSS_PPS; EXP_UART_RX GND; I2C_SCL; EXP_UART_TX; I2C_SDA; RP_UART_RTS; 3V3_MAIN RP_UART_RX; LCD_BL_PWM; RP_UART_TX USB_DP; LCD_AUX; USB_DN

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
## Title: 04 ESP32-S3-WROOM-1-N16R8, buttons, TCA9535 slow control, I2C pull-ups, expansion

### File: 04_compute.kicad_sch

### Sheet: /04 Compute and control/

## StratosCore (CERN-OHL-P-2.0) - Claude one-shot candidate
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

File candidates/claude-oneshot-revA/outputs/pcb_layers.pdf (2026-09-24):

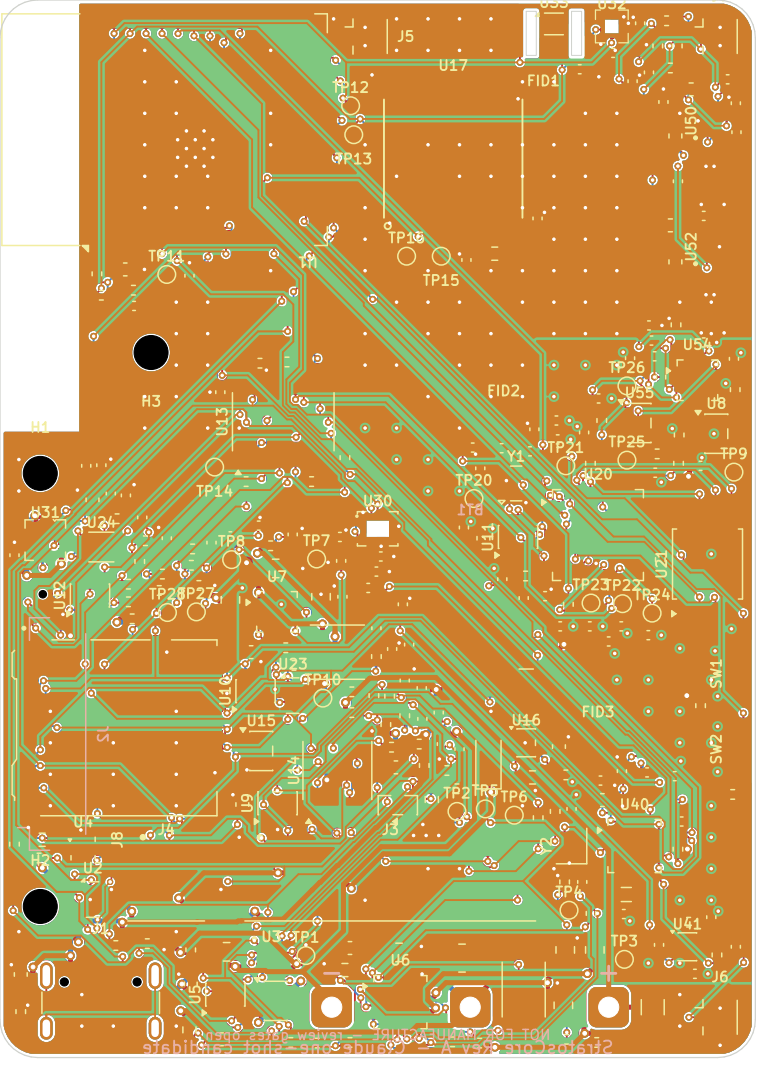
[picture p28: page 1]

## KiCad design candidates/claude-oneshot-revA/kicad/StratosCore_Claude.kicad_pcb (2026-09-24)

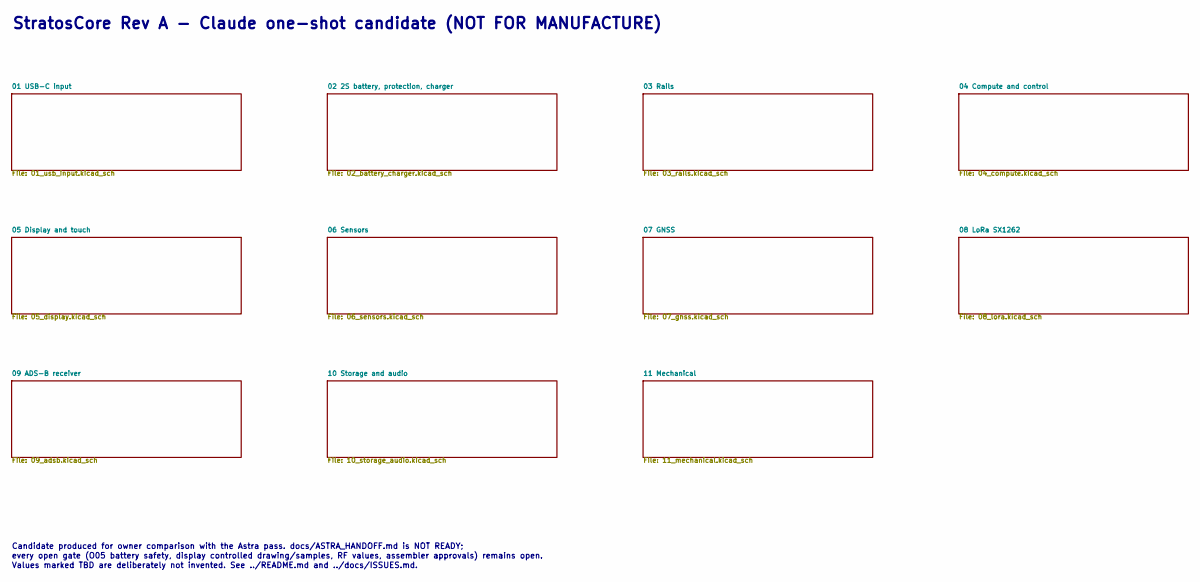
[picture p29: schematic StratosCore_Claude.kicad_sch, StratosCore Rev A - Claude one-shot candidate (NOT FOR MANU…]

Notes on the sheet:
StratosCore Rev A - Claude one-shot candidate (NOT FOR MANUFACTURE)
Candidate produced for owner comparison with the Astra pass. docs/ASTRA_HANDOFF.md is NOT READY;
every open gate (O05 battery safety, display controlled drawing/samples, RF values, assembler approvals) remains open.
Values marked TBD are deliberately not invented. See ../README.md and ../docs/ISSUES.md.

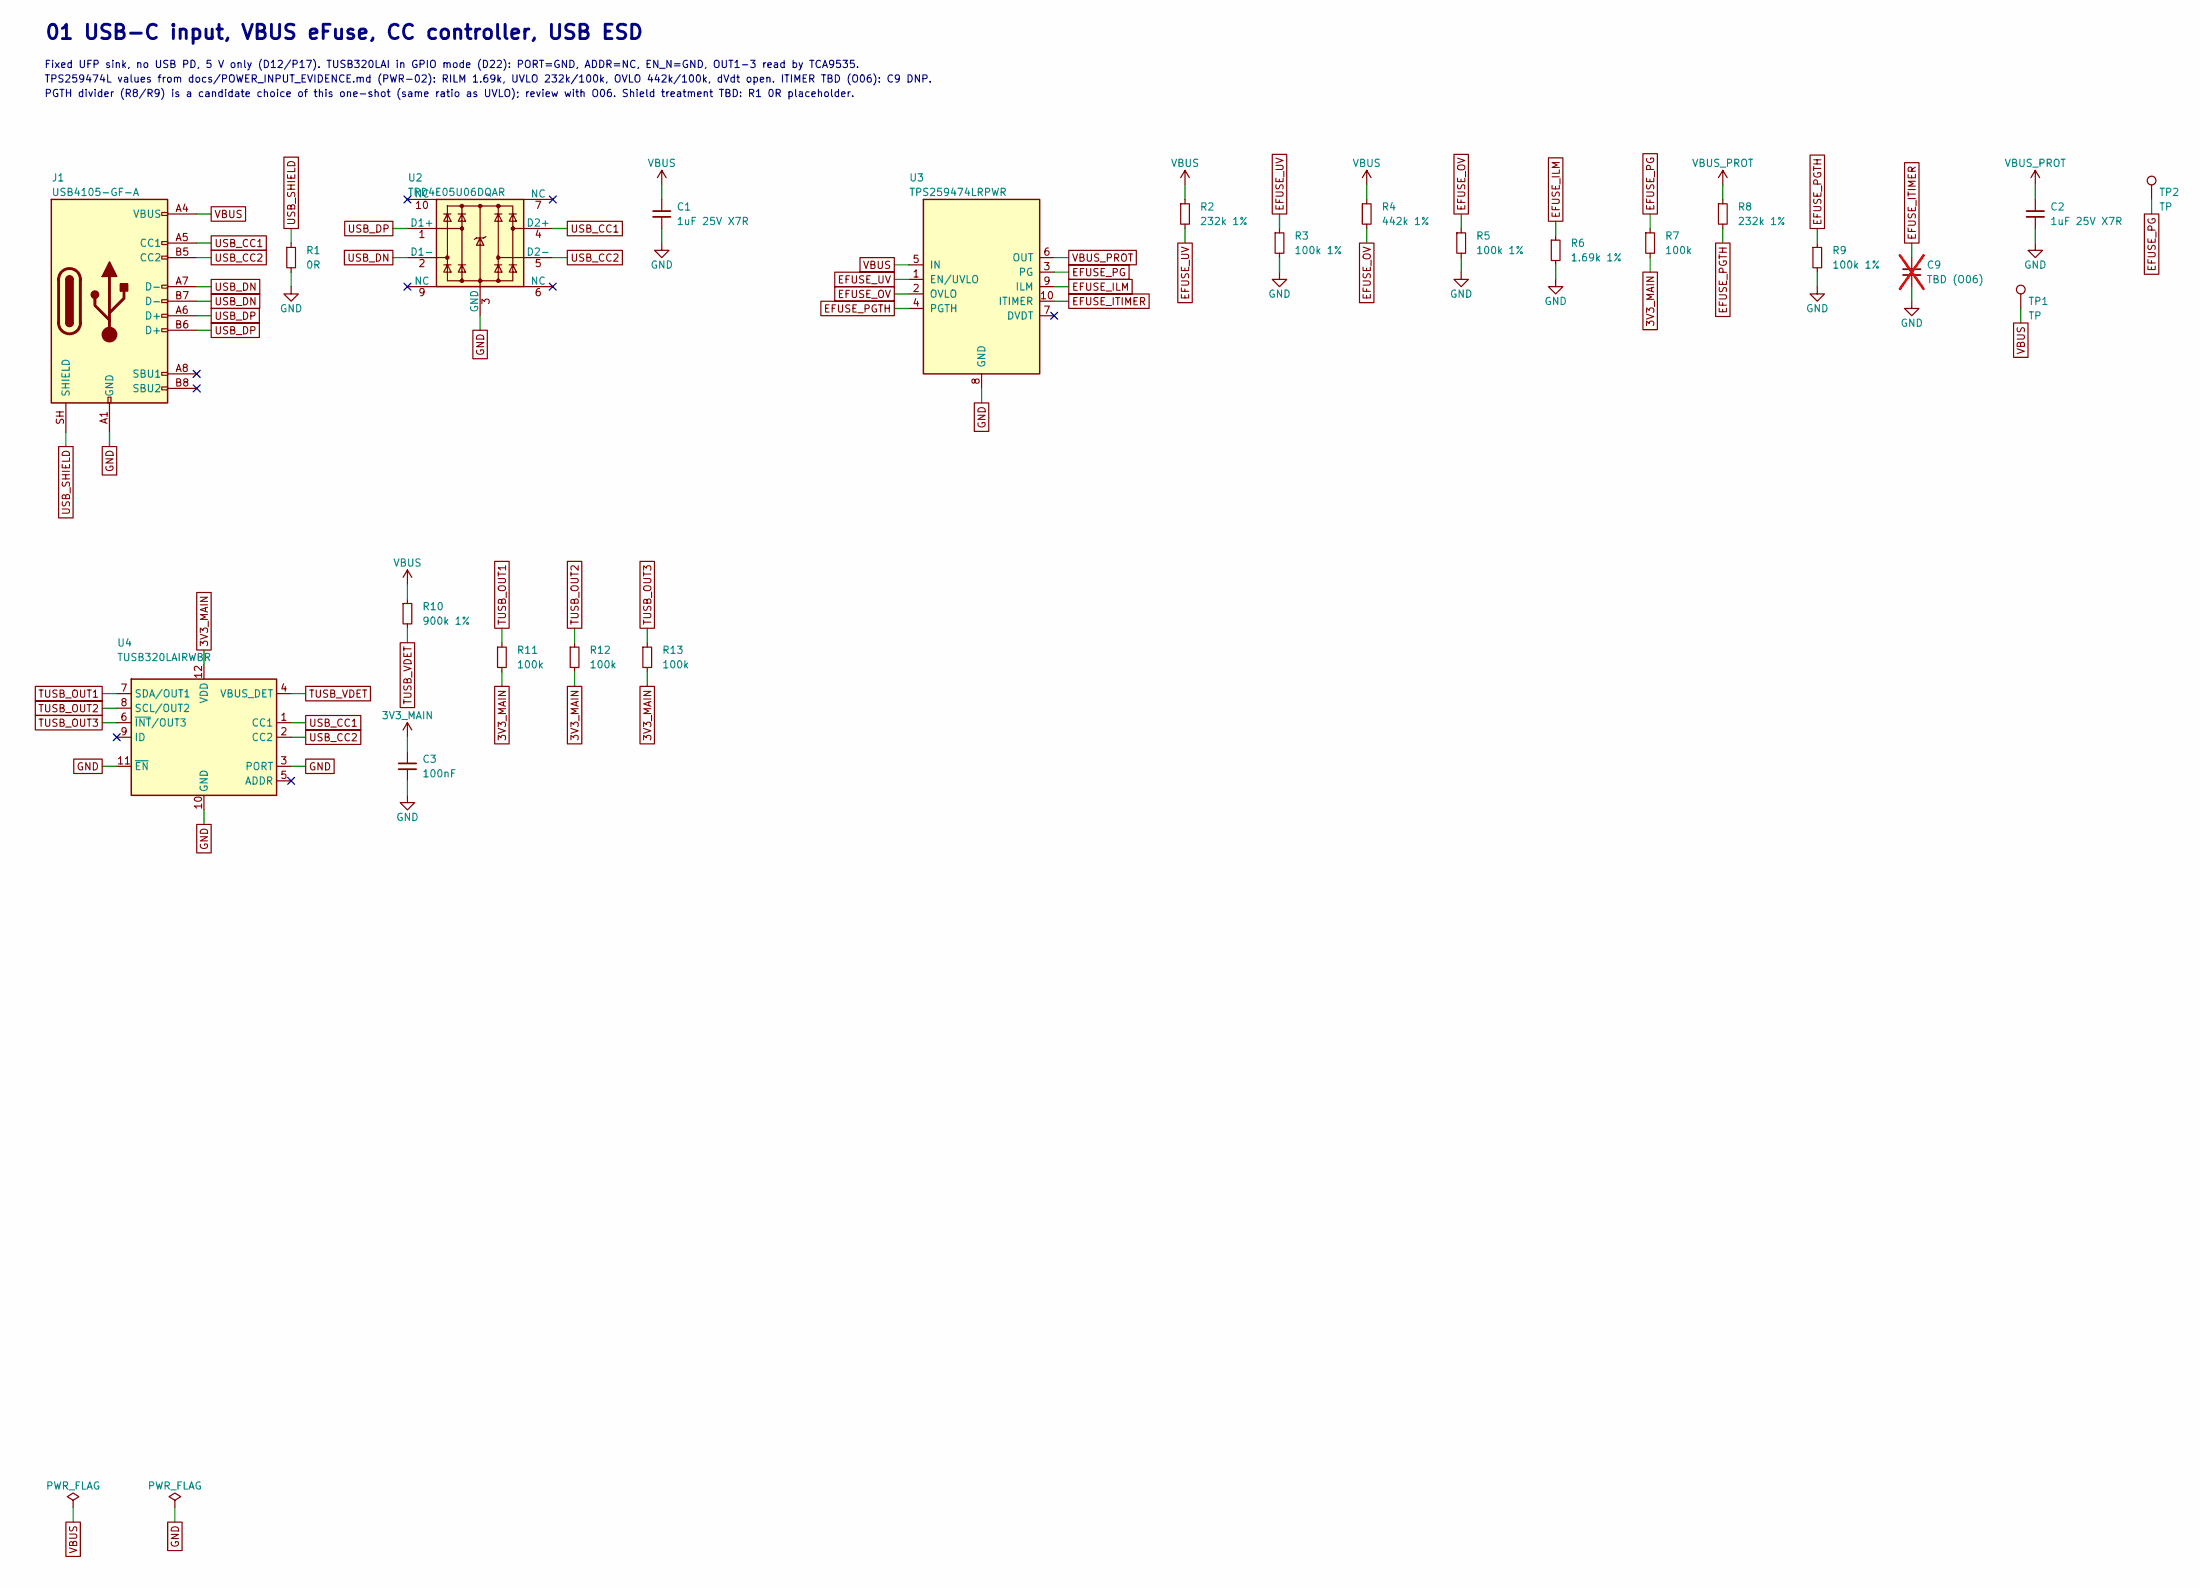
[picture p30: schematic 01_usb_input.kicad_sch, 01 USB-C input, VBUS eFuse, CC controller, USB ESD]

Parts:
C1, C2: 1uF 25V X7R; C_0603_1608Metric
C3: 100nF; C_0402_1005Metric
C9: TBD (O06); C_0402_1005Metric; not fitted
J1: USB4105-GF-A; USB_C_Receptacle_GCT_USB4105-xx-A_16P_TopMnt_Horizontal; MPN USB4105-GF-A
R1: 0R; R_0402_1005Metric
R2, R8: 232k 1%; R_0402_1005Metric
R3, R5, R9: 100k 1%; R_0402_1005Metric
R4: 442k 1%; R_0402_1005Metric
R6: 1.69k 1%; R_0402_1005Metric
R7, R11, R12, R13: 100k; R_0402_1005Metric
R10: 900k 1%; R_0402_1005Metric
TP1, TP2: TP; TestPoint_Pad_D1.0mm
U2: TPD4E05U06DQAR; USON-10_2.5x1.0mm_P0.5mm; MPN TPD4E05U06DQARG4
U3: TPS259474LRPWR; TI_RPW0010A_VQFN-HR-10_2x2mm_P0.45mm; MPN TPS259474LRPWR
U4: TUSB320LAIRWBR; TI_RWB0012B_X2QFN-12_1.6x1.6mm_TUSB320LAI; MPN TUSB320LAIRWBR

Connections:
3V3_MAIN: C3.1, R7.2, R11.2, R12.2, R13.2, U4.12 (VDD); also elsewhere on the board
EFUSE_ILM: R6.1, U3.9 (ILM)
EFUSE_ITIMER: C9.1, U3.10 (ITIMER)
EFUSE_OV: R4.2, R5.1, U3.2 (OVLO)
EFUSE_PG: R7.1, TP2.1, U3.3 (PG)
EFUSE_PGTH: R8.2, R9.1, U3.4 (PGTH)
EFUSE_UV: R2.2, R3.1, U3.1 (EN/UVLO)
GND: C1.2, C2.2, C3.2, C9.2, J1.A1 (GND), J1.A12 (GND), J1.B1 (GND), J1.B12 (GND), R1.2, R3.2, R5.2, R6.2, R9.2, U2.3 (GND), U2.8 (GND), U3.8 (GND), U4.3 (PORT), U4.10 (GND), U4.11 (~EN); also elsewhere on the board
TUSB_OUT1: R11.1, U4.7 (SDA/OUT1); also elsewhere on the board
TUSB_OUT2: R12.1, U4.8 (SCL/OUT2); also elsewhere on the board
TUSB_OUT3: R13.1, U4.6 (~INT/OUT3); also elsewhere on the board
TUSB_VDET: R10.2, U4.4 (VBUS_DET)
USB_CC1: J1.A5 (CC1), U2.4 (D2+), U4.1 (CC1)
USB_CC2: J1.B5 (CC2), U2.5 (D2-), U4.2 (CC2)
USB_DN: J1.A7 (D-), J1.B7 (D-), U2.2 (D1-); also elsewhere on the board
USB_DP: J1.A6 (D+), J1.B6 (D+), U2.1 (D1+); also elsewhere on the board
USB_SHIELD: J1.SH (SHIELD), R1.1
VBUS: C1.1, J1.A4 (VBUS), J1.A9 (VBUS), J1.B4 (VBUS), J1.B9 (VBUS), R2.1, R4.1, R10.1, TP1.1, U3.5 (IN)
VBUS_PROT: C2.1, R8.1, U3.6 (OUT); also elsewhere on the board

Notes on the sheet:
01 USB-C input, VBUS eFuse, CC controller, USB ESD
Fixed UFP sink, no USB PD, 5 V only (D12/P17). TUSB320LAI in GPIO mode (D22): PORT=GND, ADDR=NC, EN_N=GND, OUT1-3 read by TCA9535.
TPS259474L values from docs/POWER_INPUT_EVIDENCE.md (PWR-02): RILM 1.69k, UVLO 232k/100k, OVLO 442k/100k, dVdt open. ITIMER TBD (O06): C9 DNP.
PGTH divider (R8/R9) is a candidate choice of this one-shot (same ratio as UVLO); review with O06. Shield treatment TBD: R1 0R placeholder.

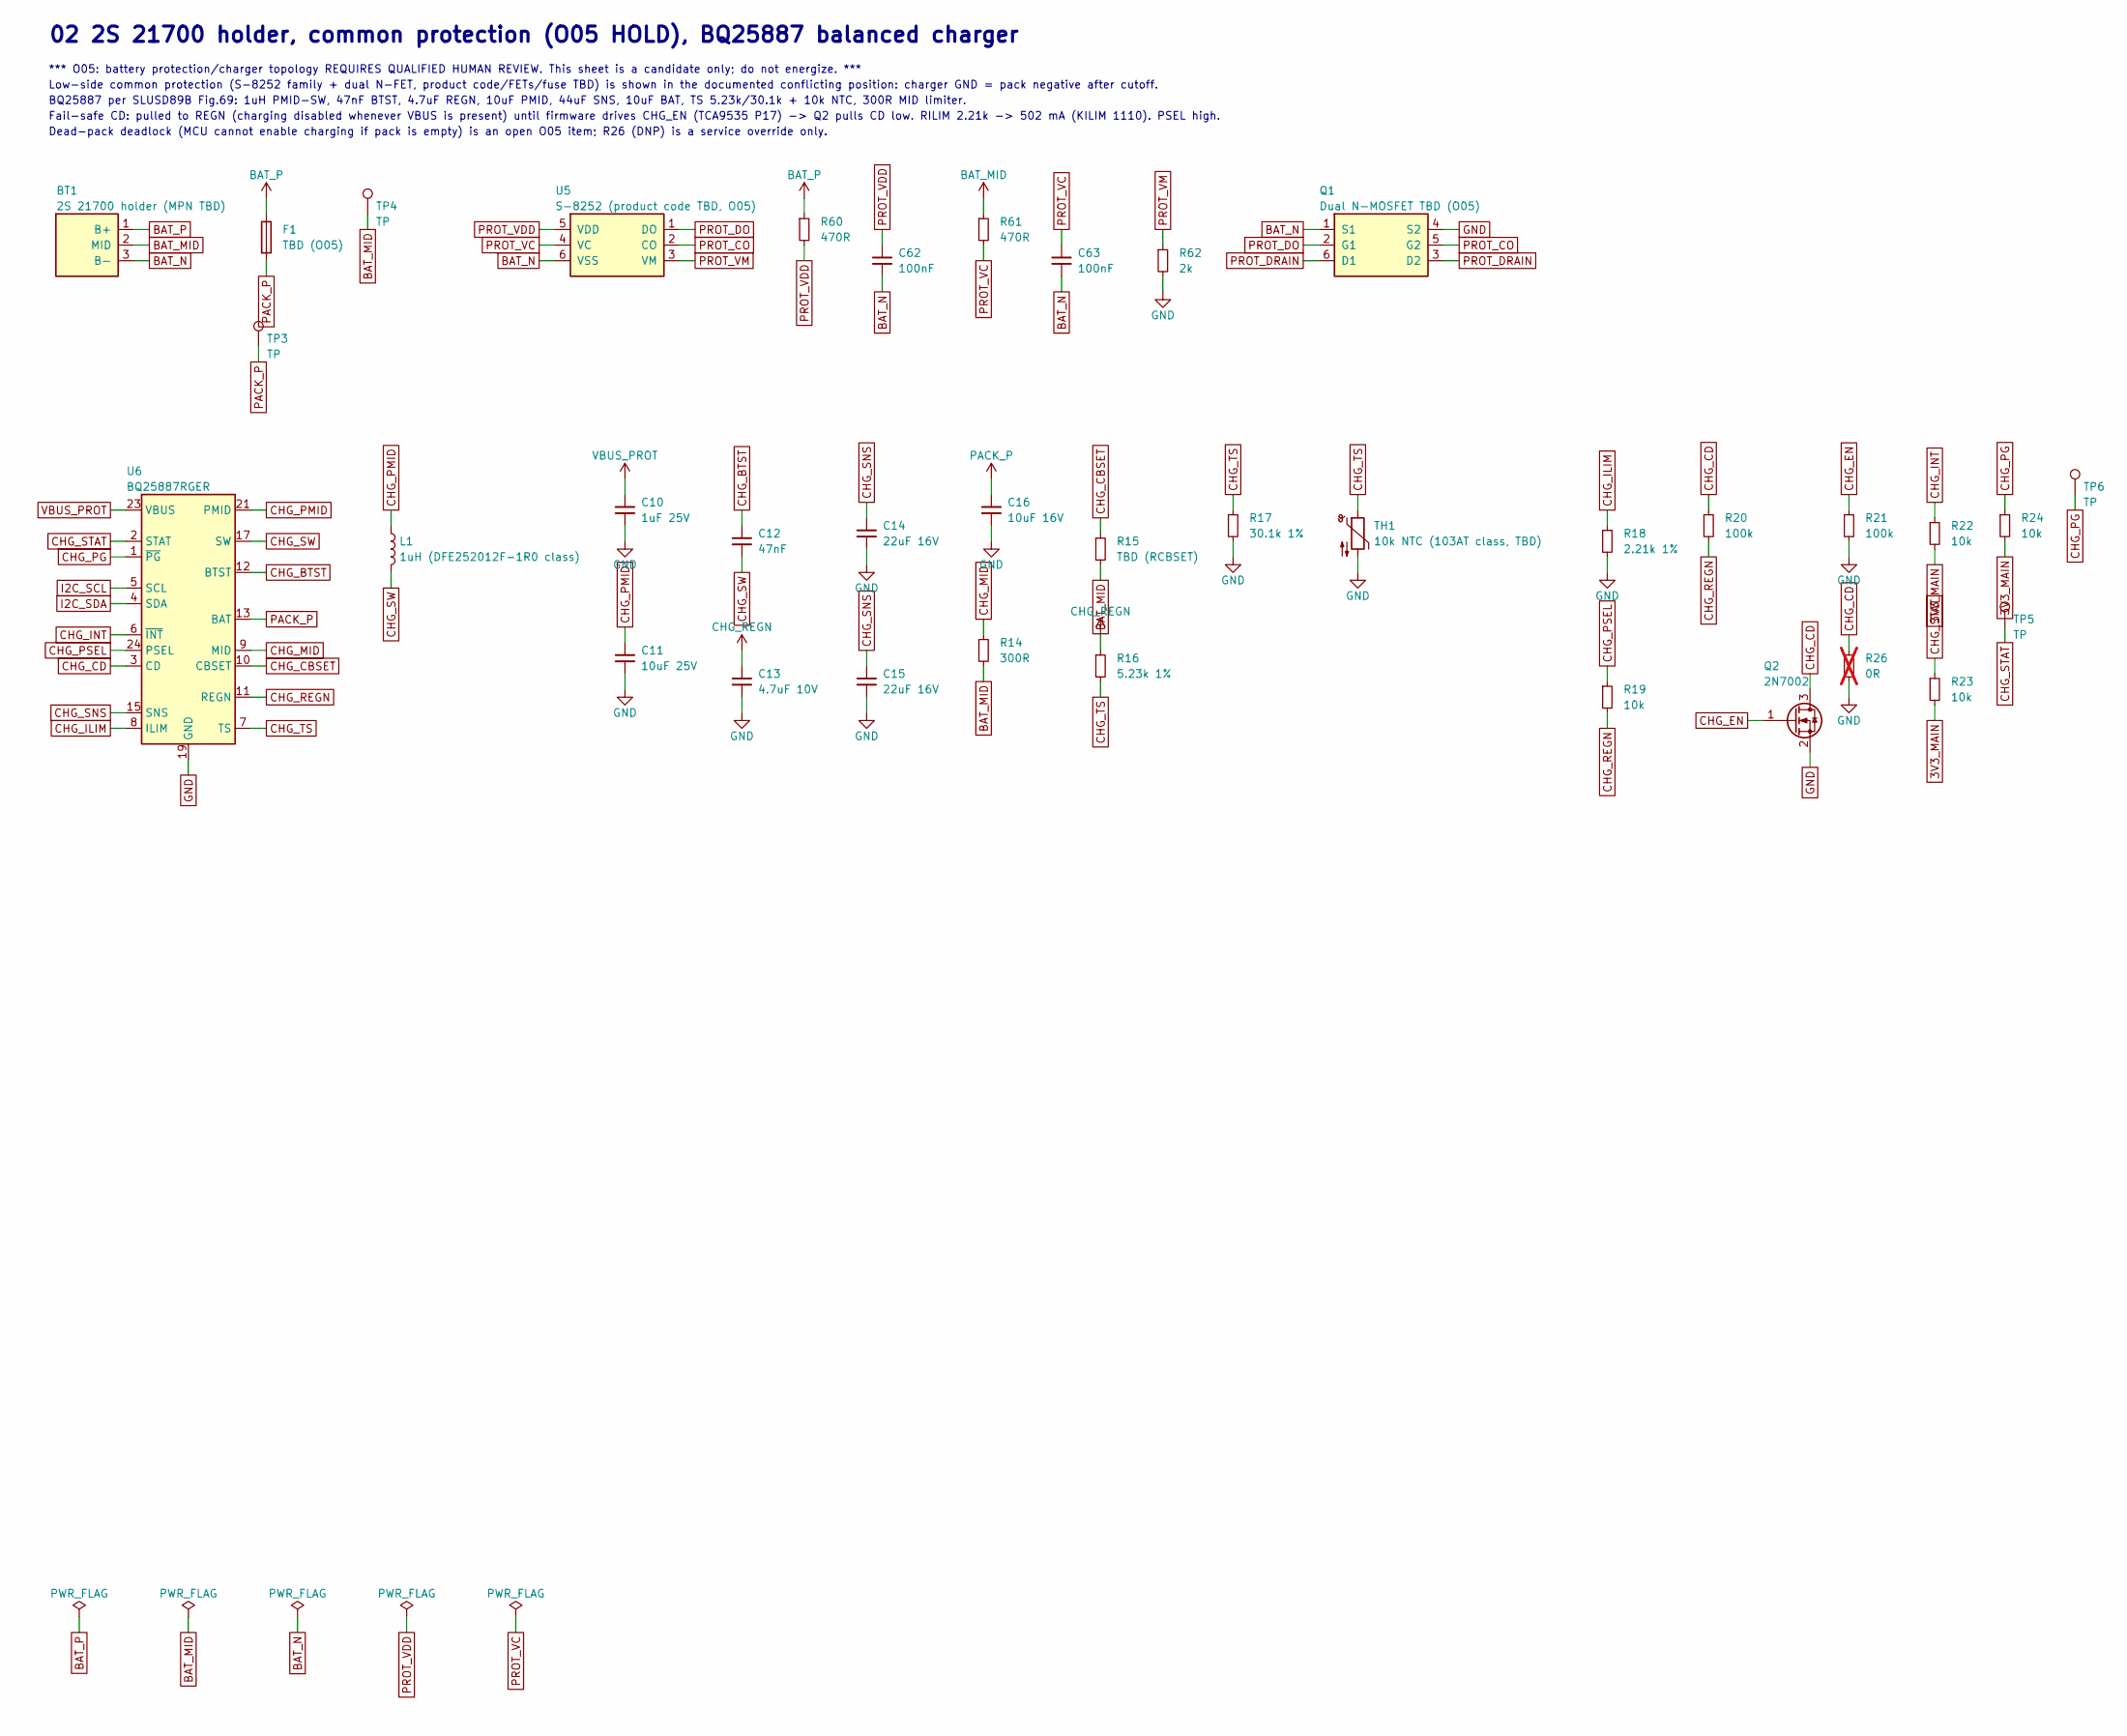
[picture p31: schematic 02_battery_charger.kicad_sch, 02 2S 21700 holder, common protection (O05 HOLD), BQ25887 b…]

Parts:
BT1: 2S 21700 holder (MPN TBD); BatteryHolder_2S_21700_TBD; MPN TBD
C10: 1uF 25V; C_0603_1608Metric
C11: 10uF 25V; C_0805_2012Metric
C12: 47nF; C_0402_1005Metric
C13: 4.7uF 10V; C_0603_1608Metric
C14, C15: 22uF 16V; C_0805_2012Metric
C16: 10uF 16V; C_0805_2012Metric
C62, C63: 100nF; C_0402_1005Metric
F1: TBD (O05); Fuse_1206_3216Metric
L1: 1uH (DFE252012F-1R0 class); L_1008_2520Metric
Q1: Dual N-MOSFET TBD (O05); SOT-23-6
Q2: 2N7002; SOT-23
R14: 300R; R_0603_1608Metric
R15: TBD (RCBSET); R_2512_6332Metric
R16: 5.23k 1%; R_0402_1005Metric
R17: 30.1k 1%; R_0402_1005Metric
R18: 2.21k 1%; R_0402_1005Metric
R19, R22, R23, R24: 10k; R_0402_1005Metric
R20, R21: 100k; R_0402_1005Metric
R26: 0R; R_0402_1005Metric; not fitted
R60, R61: 470R; R_0402_1005Metric
R62: 2k; R_0402_1005Metric
TH1: 10k NTC (103AT class, TBD); R_0603_1608Metric
TP3, TP4, TP5, TP6: TP; TestPoint_Pad_D1.0mm
U5: S-8252 (product code TBD, O05); SOT-23-6
U6: BQ25887RGER; Texas_RGE0024H_VQFN-24-1EP_4x4mm_P0.5mm_EP2.7x2.7mm; MPN BQ25887RGER

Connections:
3V3_MAIN: R22.2, R23.2, R24.2; also elsewhere on the board
BAT_MID: BT1.2 (MID), R14.2, R15.2, R61.1, TP4.1
BAT_N: BT1.3 (B-), C62.2, C63.2, Q1.1 (S1), U5.6 (VSS)
BAT_P: BT1.1 (B+), F1.1, R60.1
CHG_BTST: C12.1, U6.12 (BTST)
CHG_CBSET: R15.1, U6.10 (CBSET)
CHG_CD: Q2.3 (D), R20.1, R26.1, U6.3 (CD)
CHG_EN: Q2.1 (G), R21.1; also elsewhere on the board
CHG_ILIM: R18.1, U6.8 (ILIM)
CHG_INT: R22.1, U6.6 (~INT); also elsewhere on the board
CHG_MID: R14.1, U6.9 (MID)
CHG_PG: R24.1, TP6.1, U6.1 (~PG)
CHG_PMID: C11.1, L1.1, U6.21 (PMID), U6.22 (PMID)
CHG_PSEL: R19.1, U6.24 (PSEL)
CHG_REGN: C13.1, R16.1, R19.2, R20.2, U6.11 (REGN)
CHG_SNS: C14.1, C15.1, U6.15 (SNS), U6.16 (SNS)
CHG_STAT: R23.1, TP5.1, U6.2 (STAT)
CHG_SW: C12.2, L1.2, U6.17 (SW), U6.18 (SW)
CHG_TS: R16.2, R17.1, TH1.1, U6.7 (TS)
GND: C10.2, C11.2, C13.2, C14.2, C15.2, C16.2, Q1.4 (S2), Q2.2 (S), R17.2, R18.2, R21.2, R26.2, R62.2, TH1.2, U6.19 (GND), U6.20 (GND), U6.25 (GND); also elsewhere on the board
I2C_SCL: U6.5 (SCL); also elsewhere on the board
I2C_SDA: U6.4 (SDA); also elsewhere on the board
PACK_P: C16.1, F1.2, TP3.1, U6.13 (BAT), U6.14 (BAT); also elsewhere on the board
PROT_CO: Q1.5 (G2), U5.2 (CO)
PROT_DO: Q1.2 (G1), U5.1 (DO)
PROT_DRAIN: Q1.3 (D2), Q1.6 (D1)
PROT_VC: C63.1, R61.2, U5.4 (VC)
PROT_VDD: C62.1, R60.2, U5.5 (VDD)
PROT_VM: R62.1, U5.3 (VM)
VBUS_PROT: C10.1, U6.23 (VBUS); also elsewhere on the board

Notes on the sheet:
02 2S 21700 holder, common protection (O05 HOLD), BQ25887 balanced charger
*** O05: battery protection/charger topology REQUIRES QUALIFIED HUMAN REVIEW. This sheet is a candidate only; do not energize. ***
Low-side common protection (S-8252 family + dual N-FET, product code/FETs/fuse TBD) is shown in the documented conflicting position: charger GND = pack negative after cutoff.
BQ25887 per SLUSD89B Fig.69: 1uH PMID-SW, 47nF BTST, 4.7uF REGN, 10uF PMID, 44uF SNS, 10uF BAT, TS 5.23k/30.1k + 10k NTC, 300R MID limiter.
Fail-safe CD: pulled to REGN (charging disabled whenever VBUS is present) until firmware drives CHG_EN (TCA9535 P17) -> Q2 pulls CD low. RILIM 2.21k -> 502 mA (KILIM 1110). PSEL high.
Dead-pack deadlock (MCU cannot enable charging if pack is empty) is an open O05 item; R26 (DNP) is a service override only.

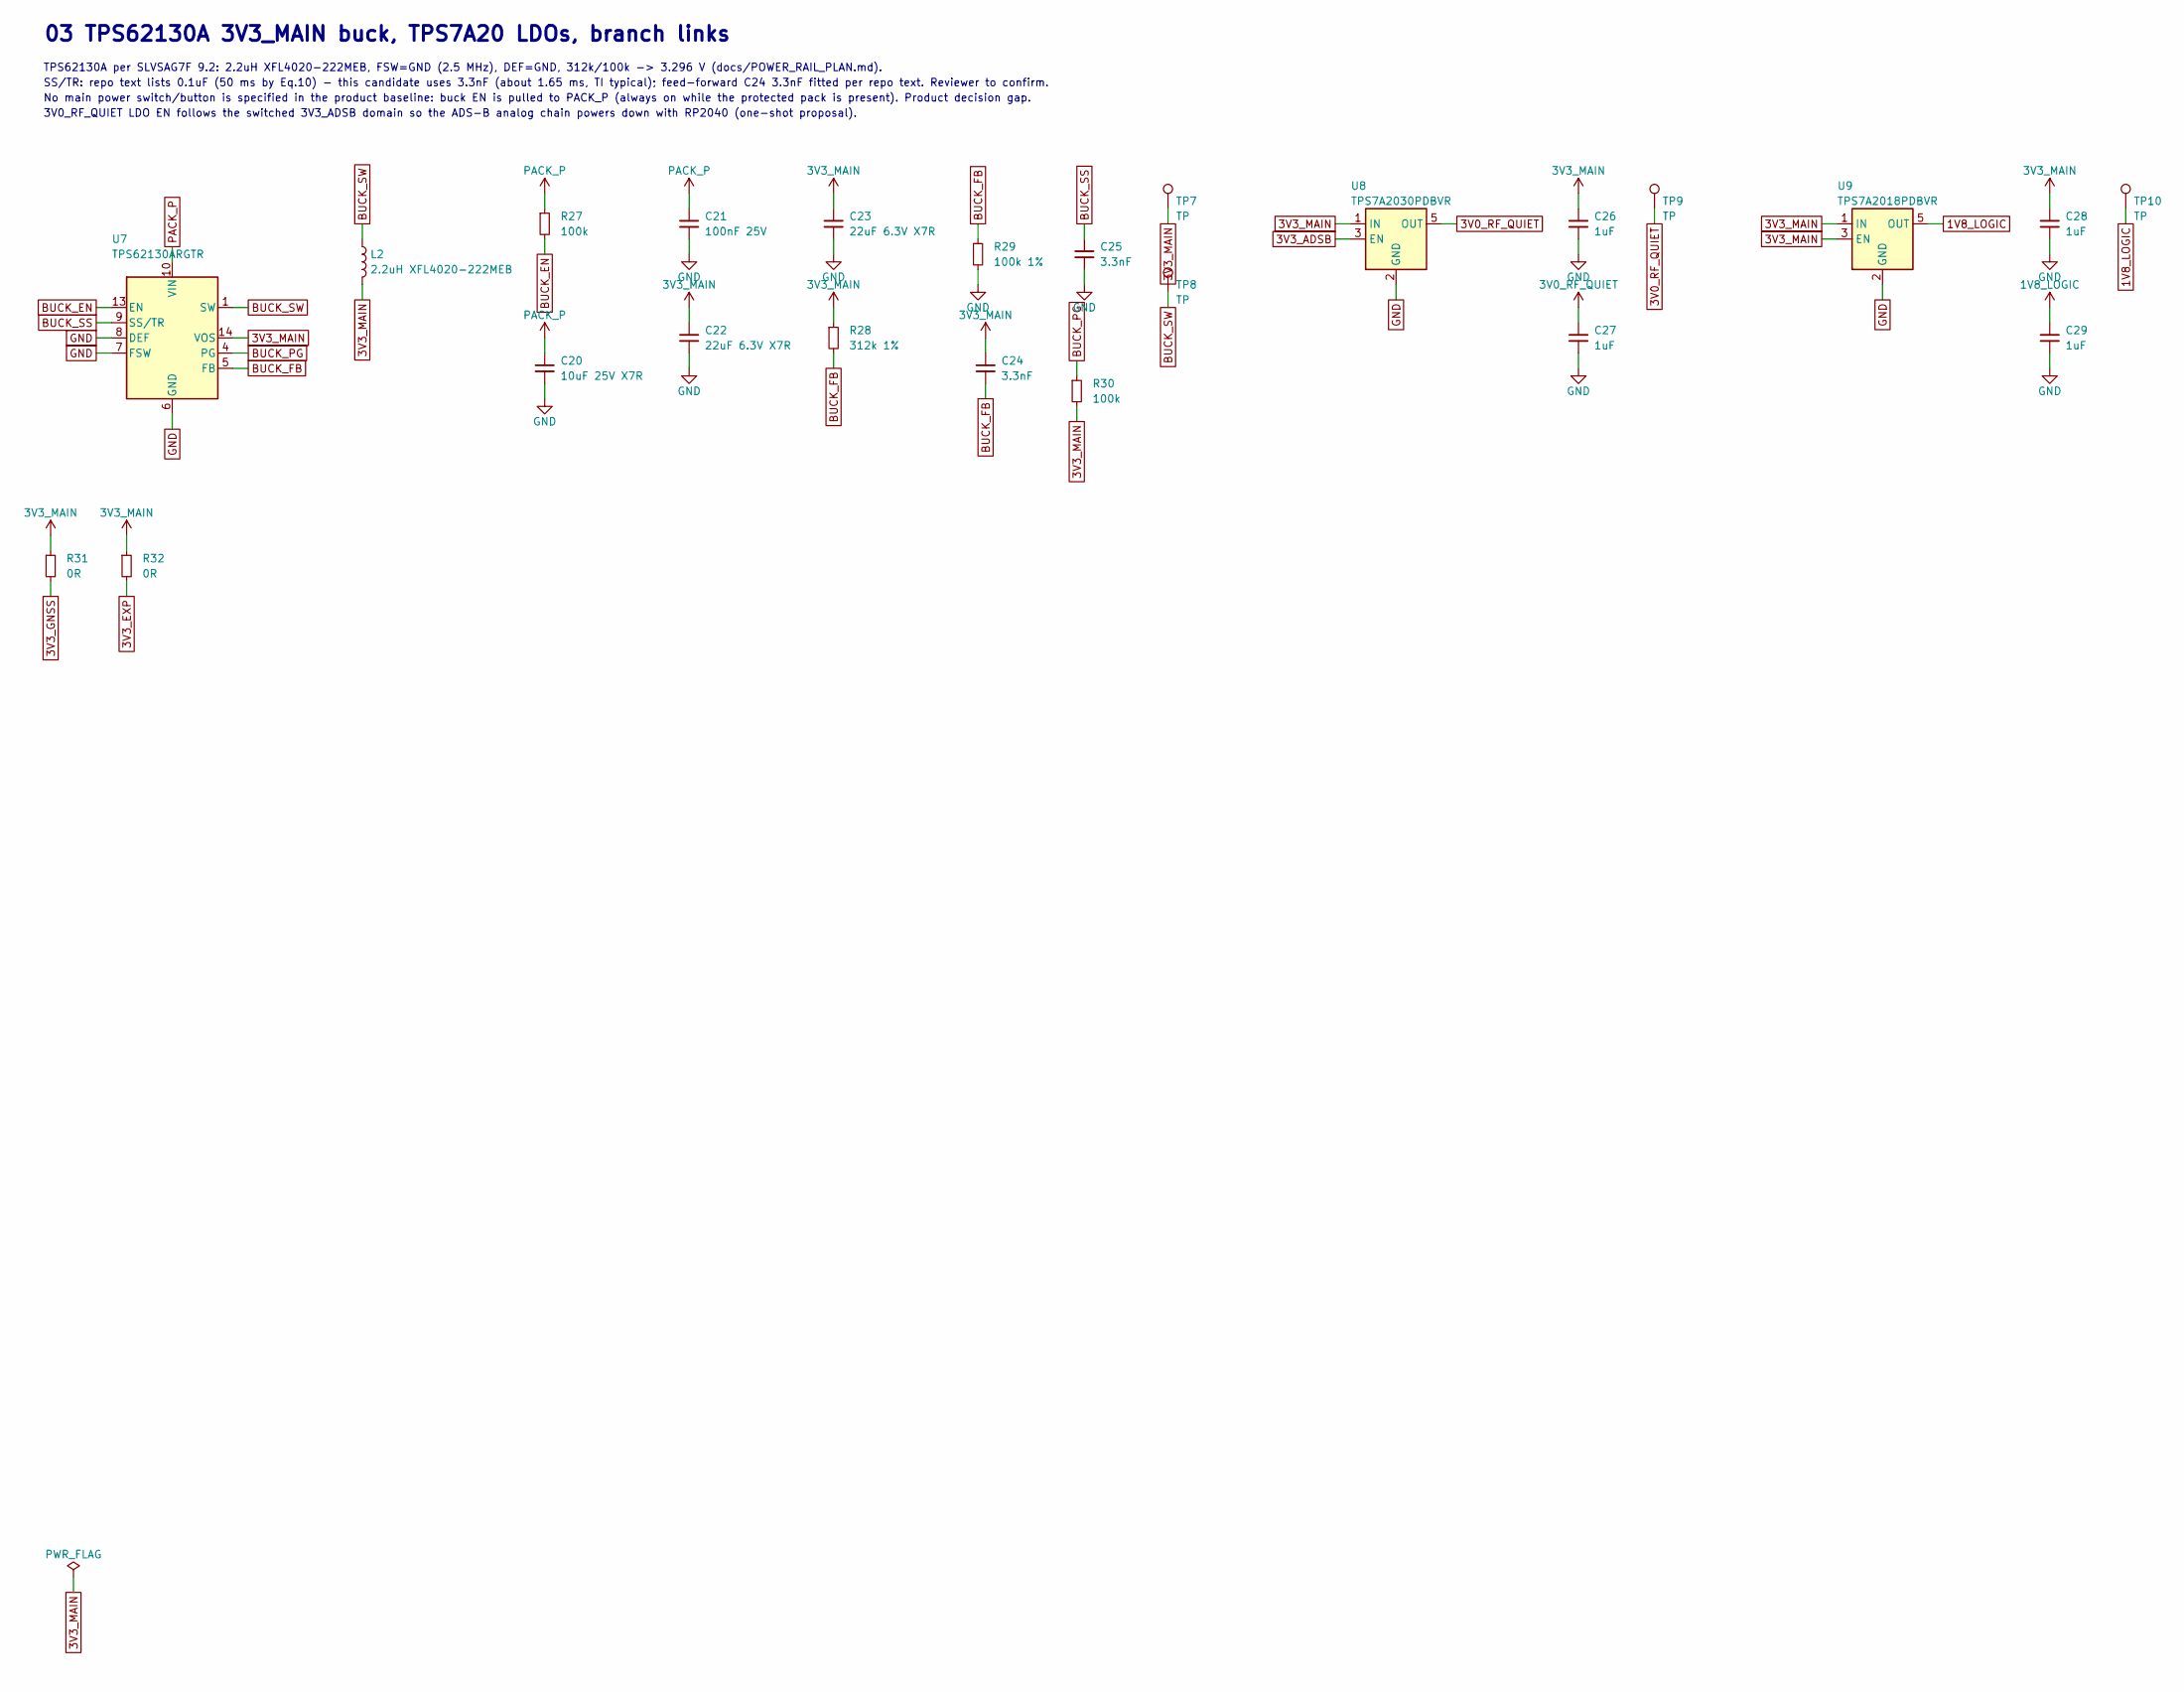
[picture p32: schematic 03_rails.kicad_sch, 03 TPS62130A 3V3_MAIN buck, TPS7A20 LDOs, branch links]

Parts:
C20: 10uF 25V X7R; C_0805_2012Metric
C21: 100nF 25V; C_0402_1005Metric
C22, C23: 22uF 6.3V X7R; C_0805_2012Metric
C24, C25: 3.3nF; C_0402_1005Metric
C26, C27, C28, C29: 1uF; C_0402_1005Metric
L2: 2.2uH XFL4020-222MEB; L_Coilcraft_XxL4020; MPN XFL4020-222MEB
R27, R30: 100k; R_0402_1005Metric
R28: 312k 1%; R_0402_1005Metric
R29: 100k 1%; R_0402_1005Metric
R31, R32: 0R; R_0603_1608Metric
TP7, TP8, TP9, TP10: TP; TestPoint_Pad_D1.0mm
U7: TPS62130ARGTR; TI_RGT0016C_VQFN-16_3x3mm_EP1.68x1.68_TPS62130A; MPN TPS62130ARGTR
U8: TPS7A2030PDBVR; TI_DBV0005A_SOT-23-5_TPS7A20; MPN TPS7A2030PDBVR
U9: TPS7A2018PDBVR; TI_DBV0005A_SOT-23-5_TPS7A20; MPN TPS7A2018PDBVR

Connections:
1V8_LOGIC: C29.1, TP10.1, U9.5 (OUT); also elsewhere on the board
3V0_RF_QUIET: C27.1, TP9.1, U8.5 (OUT); also elsewhere on the board
3V3_ADSB: U8.3 (EN); also elsewhere on the board
3V3_EXP: R32.2; also elsewhere on the board
3V3_GNSS: R31.2; also elsewhere on the board
3V3_MAIN: C22.1, C23.1, C24.1, C26.1, C28.1, L2.2, R28.1, R30.2, R31.1, R32.1, TP7.1, U7.14 (VOS), U8.1 (IN), U9.1 (IN), U9.3 (EN); also elsewhere on the board
BUCK_EN: R27.2, U7.13 (EN)
BUCK_FB: C24.2, R28.2, R29.1, U7.5 (FB)
BUCK_PG: R30.1, U7.4 (PG); also elsewhere on the board
BUCK_SS: C25.1, U7.9 (SS/TR)
BUCK_SW: L2.1, TP8.1, U7.1 (SW), U7.2 (SW), U7.3 (SW)
GND: C20.2, C21.2, C22.2, C23.2, C25.2, C26.2, C27.2, C28.2, C29.2, R29.2, U7.6 (GND), U7.7 (FSW), U7.8 (DEF), U7.15 (GND), U7.16 (GND), U7.17 (GND), U8.2 (GND), U9.2 (GND); also elsewhere on the board
PACK_P: C20.1, C21.1, R27.1, U7.10 (VIN), U7.11 (VIN), U7.12 (VIN); also elsewhere on the board

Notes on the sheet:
03 TPS62130A 3V3_MAIN buck, TPS7A20 LDOs, branch links
TPS62130A per SLVSAG7F 9.2: 2.2uH XFL4020-222MEB, FSW=GND (2.5 MHz), DEF=GND, 312k/100k -> 3.296 V (docs/POWER_RAIL_PLAN.md).
SS/TR: repo text lists 0.1uF (50 ms by Eq.10) - this candidate uses 3.3nF (about 1.65 ms, TI typical); feed-forward C24 3.3nF fitted per repo text. Reviewer to confirm.
No main power switch/button is specified in the product baseline: buck EN is pulled to PACK_P (always on while the protected pack is present). Product decision gap.
3V0_RF_QUIET LDO EN follows the switched 3V3_ADSB domain so the ADS-B analog chain powers down with RP2040 (one-shot proposal).

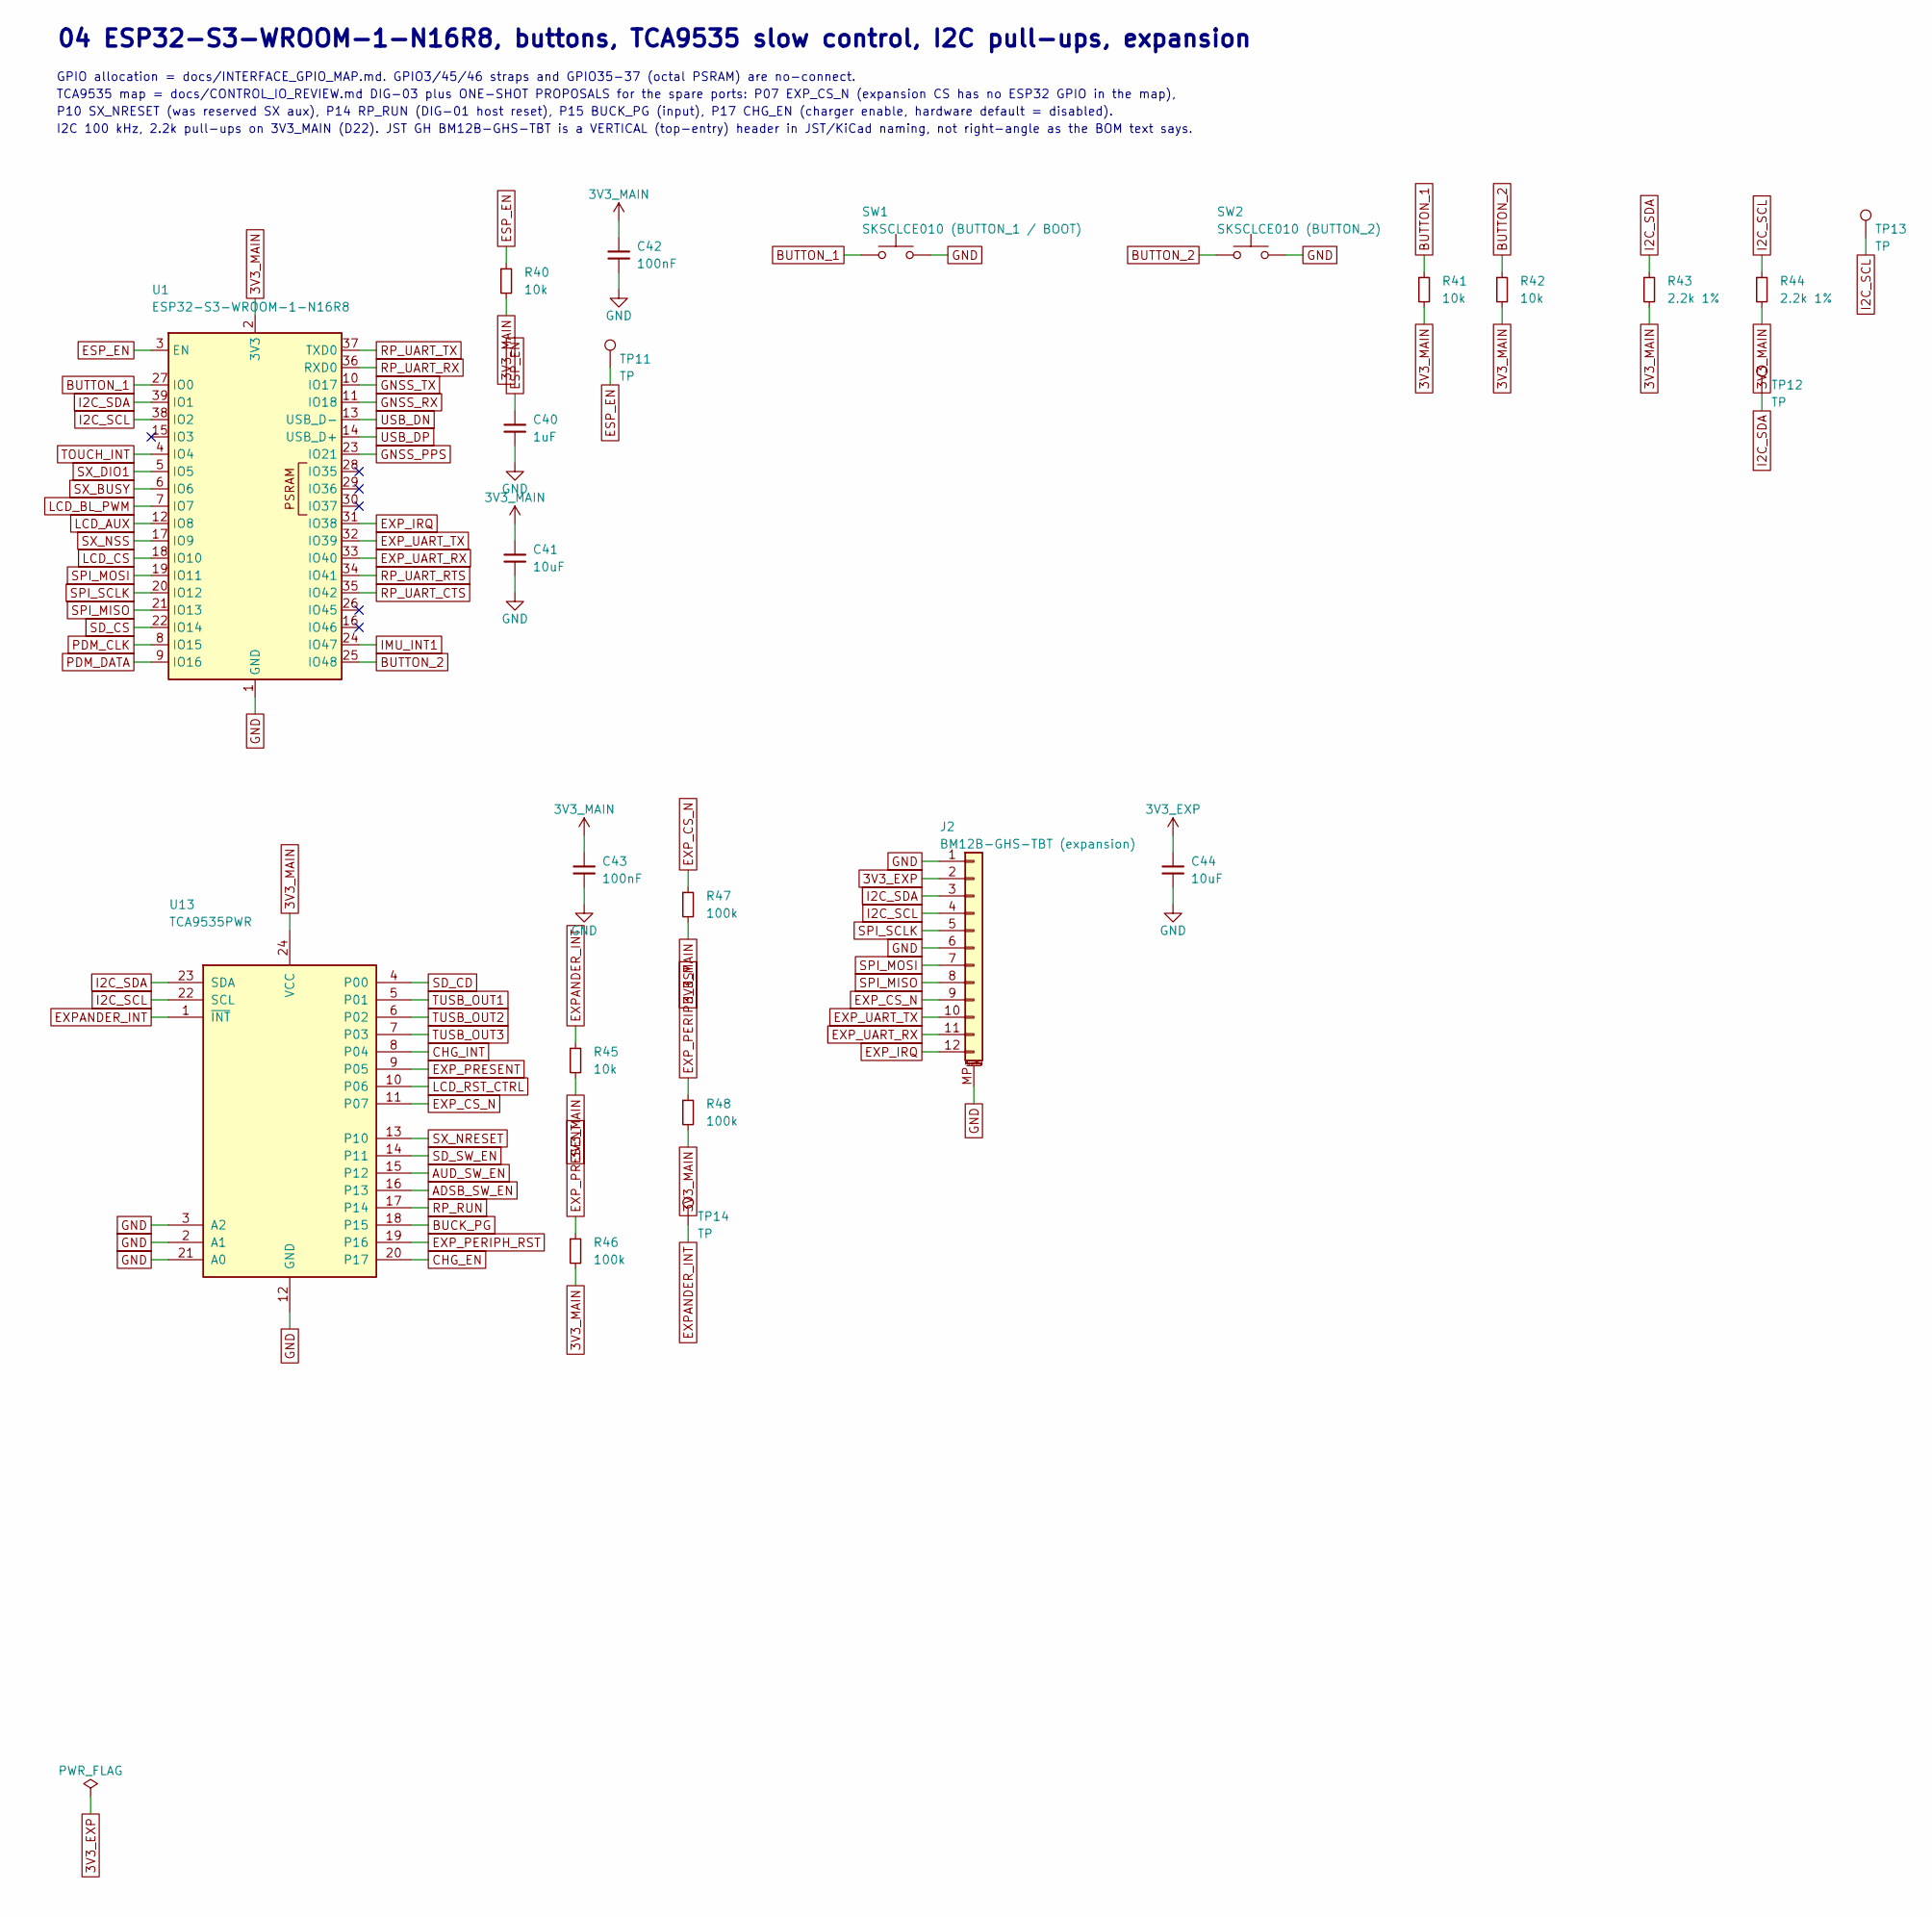
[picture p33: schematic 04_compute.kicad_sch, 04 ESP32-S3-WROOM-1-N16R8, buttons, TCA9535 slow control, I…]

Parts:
C40: 1uF; C_0402_1005Metric
C41, C44: 10uF; C_0603_1608Metric
C42, C43: 100nF; C_0402_1005Metric
J2: BM12B-GHS-TBT (expansion); JST_GH_BM12B-GHS-TBT_1x12-1MP_P1.25mm_Vertical; MPN BM12B-GHS-TBT
R40, R41, R42, R45: 10k; R_0402_1005Metric
R43, R44: 2.2k 1%; R_0402_1005Metric
R46, R47, R48: 100k; R_0402_1005Metric
SW1: SKSCLCE010 (BUTTON_1 / BOOT); SW_Alps_SKSCLCE010_SidePush; MPN SKSCLCE010
SW2: SKSCLCE010 (BUTTON_2); SW_Alps_SKSCLCE010_SidePush; MPN SKSCLCE010
TP11, TP12, TP13, TP14: TP; TestPoint_Pad_D1.0mm
U1: ESP32-S3-WROOM-1-N16R8; ESP32-S3-WROOM-1; MPN ESP32-S3-WROOM-1-N16R8
U13: TCA9535PWR; TI_PW0024A_TSSOP-24_4.4x7.8mm_TCA9535; MPN TCA9535PWR

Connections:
3V3_EXP: C44.1, J2.2; also elsewhere on the board
3V3_MAIN: C41.1, C42.1, C43.1, R40.2, R41.2, R42.2, R43.2, R44.2, R45.2, R46.2, R47.2, R48.2, U1.2 (3V3), U13.24 (VCC); also elsewhere on the board
ADSB_SW_EN: U13.16 (P13); also elsewhere on the board
AUD_SW_EN: U13.15 (P12); also elsewhere on the board
BUCK_PG: U13.18 (P15); also elsewhere on the board
BUTTON_1: R41.1, SW1.1, U1.27 (IO0)
BUTTON_2: R42.1, SW2.1, U1.25 (IO48)
CHG_EN: U13.20 (P17); also elsewhere on the board
CHG_INT: U13.8 (P04); also elsewhere on the board
ESP_EN: C40.1, R40.1, TP11.1, U1.3 (EN)
EXPANDER_INT: R45.1, TP14.1, U13.1 (~INT)
EXP_CS_N: J2.9, R47.1, U13.11 (P07)
EXP_IRQ: J2.12, U1.31 (IO38)
EXP_PERIPH_RST: R48.1, U13.19 (P16)
EXP_PRESENT: R46.1, U13.9 (P05)
EXP_UART_RX: J2.11, U1.33 (IO40)
EXP_UART_TX: J2.10, U1.32 (IO39)
GND: C40.2, C41.2, C42.2, C43.2, C44.2, J2.1, J2.6, J2.MP (MountPin), SW1.2, SW2.2, U1.1 (GND), U1.40 (GND), U1.41 (GND), U13.2 (A1), U13.3 (A2), U13.12 (GND), U13.21 (A0); also elsewhere on the board
GNSS_PPS: U1.23 (IO21); also elsewhere on the board
GNSS_RX: U1.11 (IO18); also elsewhere on the board
GNSS_TX: U1.10 (IO17); also elsewhere on the board
I2C_SCL: J2.4, R44.1, TP13.1, U1.38 (IO2), U13.22 (SCL); also elsewhere on the board
I2C_SDA: J2.3, R43.1, TP12.1, U1.39 (IO1), U13.23 (SDA); also elsewhere on the board
IMU_INT1: U1.24 (IO47); also elsewhere on the board
LCD_AUX: U1.12 (IO8); also elsewhere on the board
LCD_BL_PWM: U1.7 (IO7); also elsewhere on the board
LCD_CS: U1.18 (IO10); also elsewhere on the board
LCD_RST_CTRL: U13.10 (P06); also elsewhere on the board
PDM_CLK: U1.8 (IO15); also elsewhere on the board
PDM_DATA: U1.9 (IO16); also elsewhere on the board
RP_RUN: U13.17 (P14); also elsewhere on the board
RP_UART_CTS: U1.35 (IO42); also elsewhere on the board
RP_UART_RTS: U1.34 (IO41); also elsewhere on the board
RP_UART_RX: U1.36 (RXD0); also elsewhere on the board
RP_UART_TX: U1.37 (TXD0); also elsewhere on the board
SD_CD: U13.4 (P00); also elsewhere on the board
SD_CS: U1.22 (IO14); also elsewhere on the board
SD_SW_EN: U13.14 (P11); also elsewhere on the board
SPI_MISO: J2.8, U1.21 (IO13); also elsewhere on the board
SPI_MOSI: J2.7, U1.19 (IO11); also elsewhere on the board
SPI_SCLK: J2.5, U1.20 (IO12); also elsewhere on the board
SX_BUSY: U1.6 (IO6); also elsewhere on the board
SX_DIO1: U1.5 (IO5); also elsewhere on the board
SX_NRESET: U13.13 (P10); also elsewhere on the board
SX_NSS: U1.17 (IO9); also elsewhere on the board
TOUCH_INT: U1.4 (IO4); also elsewhere on the board
TUSB_OUT1: U13.5 (P01); also elsewhere on the board
TUSB_OUT2: U13.6 (P02); also elsewhere on the board
TUSB_OUT3: U13.7 (P03); also elsewhere on the board
USB_DN: U1.13 (USB_D-); also elsewhere on the board
USB_DP: U1.14 (USB_D+); also elsewhere on the board

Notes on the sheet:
04 ESP32-S3-WROOM-1-N16R8, buttons, TCA9535 slow control, I2C pull-ups, expansion
GPIO allocation = docs/INTERFACE_GPIO_MAP.md. GPIO3/45/46 straps and GPIO35-37 (octal PSRAM) are no-connect.
TCA9535 map = docs/CONTROL_IO_REVIEW.md DIG-03 plus ONE-SHOT PROPOSALS for the spare ports: P07 EXP_CS_N (expansion CS has no ESP32 GPIO in the map),
P10 SX_NRESET (was reserved SX aux), P14 RP_RUN (DIG-01 host reset), P15 BUCK_PG (input), P17 CHG_EN (charger enable, hardware default = disabled).
I2C 100 kHz, 2.2k pull-ups on 3V3_MAIN (D22). JST GH BM12B-GHS-TBT is a VERTICAL (top-entry) header in JST/KiCad naming, not right-angle as the BOM text says.

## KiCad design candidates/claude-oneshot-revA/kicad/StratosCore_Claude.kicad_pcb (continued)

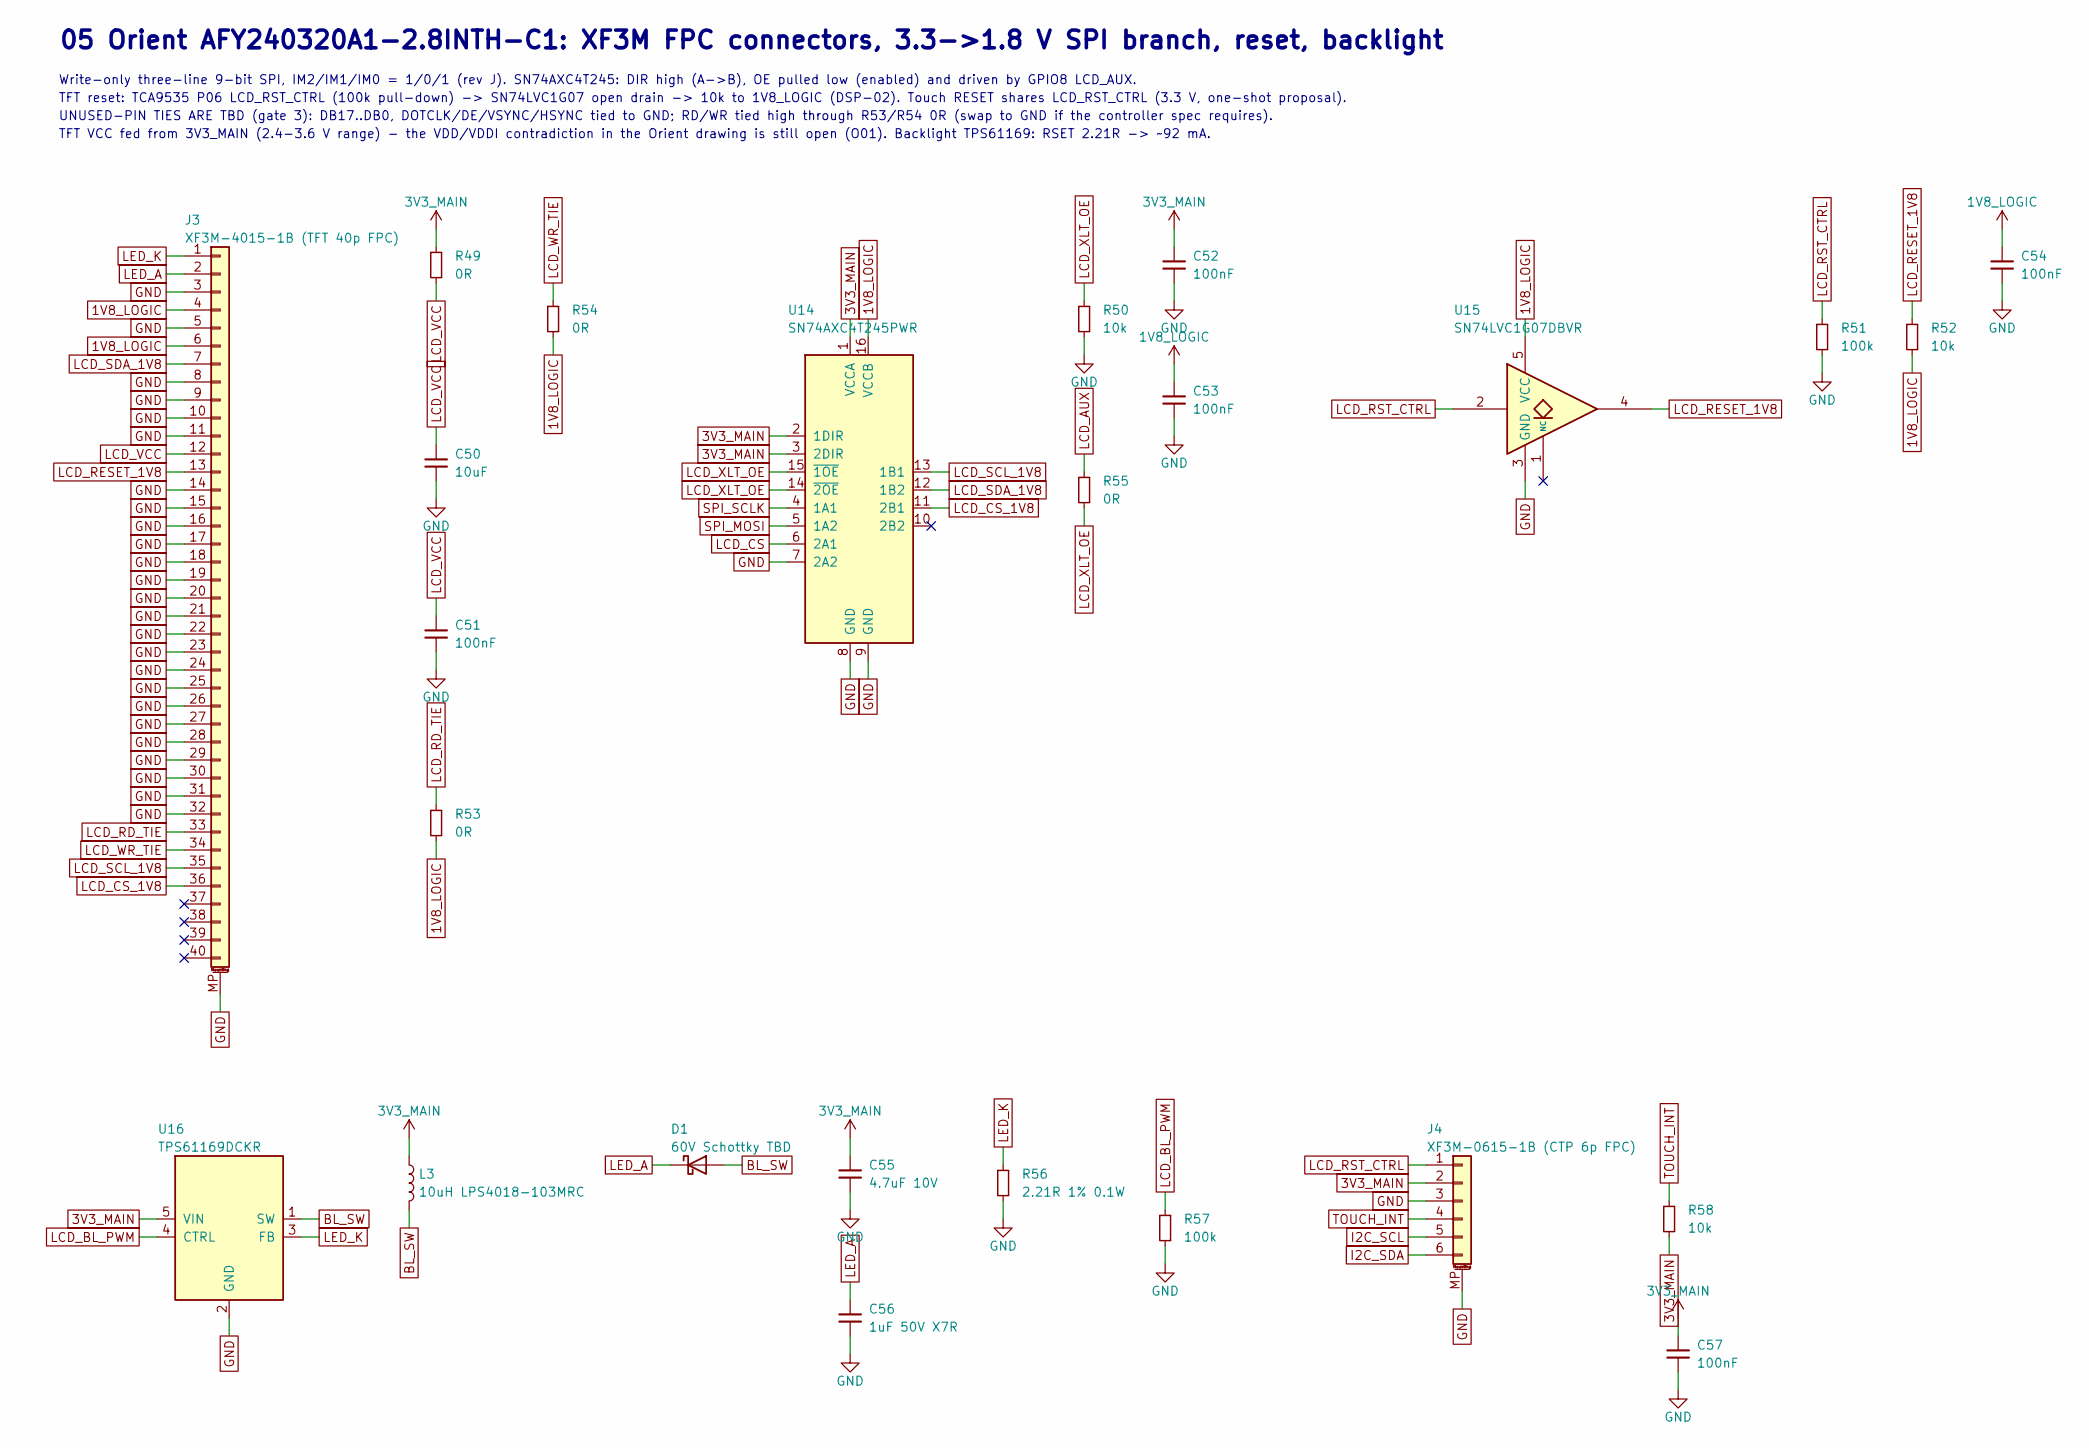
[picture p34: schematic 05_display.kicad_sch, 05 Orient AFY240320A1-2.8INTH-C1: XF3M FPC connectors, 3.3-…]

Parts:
C50: 10uF; C_0603_1608Metric
C51, C52, C53, C54, C57: 100nF; C_0402_1005Metric
C55: 4.7uF 10V; C_0603_1608Metric
C56: 1uF 50V X7R; C_0805_2012Metric
D1: 60V Schottky TBD; D_SOD-123F
J3: XF3M-4015-1B (TFT 40p FPC); Omron_XF3M-4015-1B_1x40-1MP_P0.5mm_Horizontal; MPN XF3M-4015-1B
J4: XF3M-0615-1B (CTP 6p FPC); Omron_XF3M-0615-1B_1x06-1MP_P0.5mm_Horizontal; MPN XF3M-0615-1B
L3: 10uH LPS4018-103MRC; L_Coilcraft_LPS4018; MPN LPS4018-103MRC
R49: 0R; R_0603_1608Metric
R50, R52, R58: 10k; R_0402_1005Metric
R51, R57: 100k; R_0402_1005Metric
R53, R54, R55: 0R; R_0402_1005Metric
R56: 2.21R 1% 0.1W; R_0603_1608Metric
U14: SN74AXC4T245PWR; TSSOP-16_4.4x5mm_P0.65mm; MPN SN74AXC4T245PWR
U15: SN74LVC1G07DBVR; SOT-23-5; MPN SN74LVC1G07DBVR
U16: TPS61169DCKR; TI_DCK0005A_SC-70-5_TPS61169; MPN TPS61169DCKR

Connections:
1V8_LOGIC: C53.1, C54.1, J3.4, J3.6, R52.2, R53.2, R54.2, U14.16 (VCCB), U15.5 (VCC); also elsewhere on the board
3V3_MAIN: C52.1, C55.1, C57.1, J4.2, L3.1, R49.1, R58.2, U14.1 (VCCA), U14.2 (1DIR), U14.3 (2DIR), U16.5 (VIN); also elsewhere on the board
BL_SW: D1.2 (A), L3.2, U16.1 (SW)
GND: C50.2, C51.2, C52.2, C53.2, C54.2, C55.2, C56.2, C57.2, J3.3, J3.5, J3.8, J3.9, J3.10, J3.11, J3.14, J3.15, J3.16, J3.17, J3.18, J3.19, J3.20, J3.21, J3.22, J3.23, J3.24, J3.25, J3.26, J3.27, J3.28, J3.29, J3.30, J3.31, J3.32, J3.MP (MountPin), J4.3, J4.MP (MountPin), R50.2, R51.2, R56.2, R57.2, U14.7 (2A2), U14.8 (GND), U14.9 (GND), U15.3 (GND), U16.2 (GND); also elsewhere on the board
I2C_SCL: J4.5; also elsewhere on the board
I2C_SDA: J4.6; also elsewhere on the board
LCD_AUX: R55.1; also elsewhere on the board
LCD_BL_PWM: R57.1, U16.4 (CTRL); also elsewhere on the board
LCD_CS: U14.6 (2A1); also elsewhere on the board
LCD_CS_1V8: J3.36, U14.11 (2B1)
LCD_RD_TIE: J3.33, R53.1
LCD_RESET_1V8: J3.13, R52.1, U15.4
LCD_RST_CTRL: J4.1, R51.1, U15.2; also elsewhere on the board
LCD_SCL_1V8: J3.35, U14.13 (1B1)
LCD_SDA_1V8: J3.7, U14.12 (1B2)
LCD_VCC: C50.1, C51.1, J3.12, R49.2
LCD_WR_TIE: J3.34, R54.1
LCD_XLT_OE: R50.1, R55.2, U14.14 (~2OE), U14.15 (~1OE)
LED_A: C56.1, D1.1 (K), J3.2
LED_K: J3.1, R56.1, U16.3 (FB)
SPI_MOSI: U14.5 (1A2); also elsewhere on the board
SPI_SCLK: U14.4 (1A1); also elsewhere on the board
TOUCH_INT: J4.4, R58.1; also elsewhere on the board

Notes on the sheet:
05 Orient AFY240320A1-2.8INTH-C1: XF3M FPC connectors, 3.3->1.8 V SPI branch, reset, backlight
Write-only three-line 9-bit SPI, IM2/IM1/IM0 = 1/0/1 (rev J). SN74AXC4T245: DIR high (A->B), OE pulled low (enabled) and driven by GPIO8 LCD_AUX.
TFT reset: TCA9535 P06 LCD_RST_CTRL (100k pull-down) -> SN74LVC1G07 open drain -> 10k to 1V8_LOGIC (DSP-02). Touch RESET shares LCD_RST_CTRL (3.3 V, one-shot proposal).
UNUSED-PIN TIES ARE TBD (gate 3): DB17..DB0, DOTCLK/DE/VSYNC/HSYNC tied to GND; RD/WR tied high through R53/R54 0R (swap to GND if the controller spec requires).
TFT VCC fed from 3V3_MAIN (2.4-3.6 V range) - the VDD/VDDI contradiction in the Orient drawing is still open (O01). Backlight TPS61169: RSET 2.21R -> ~92 mA.

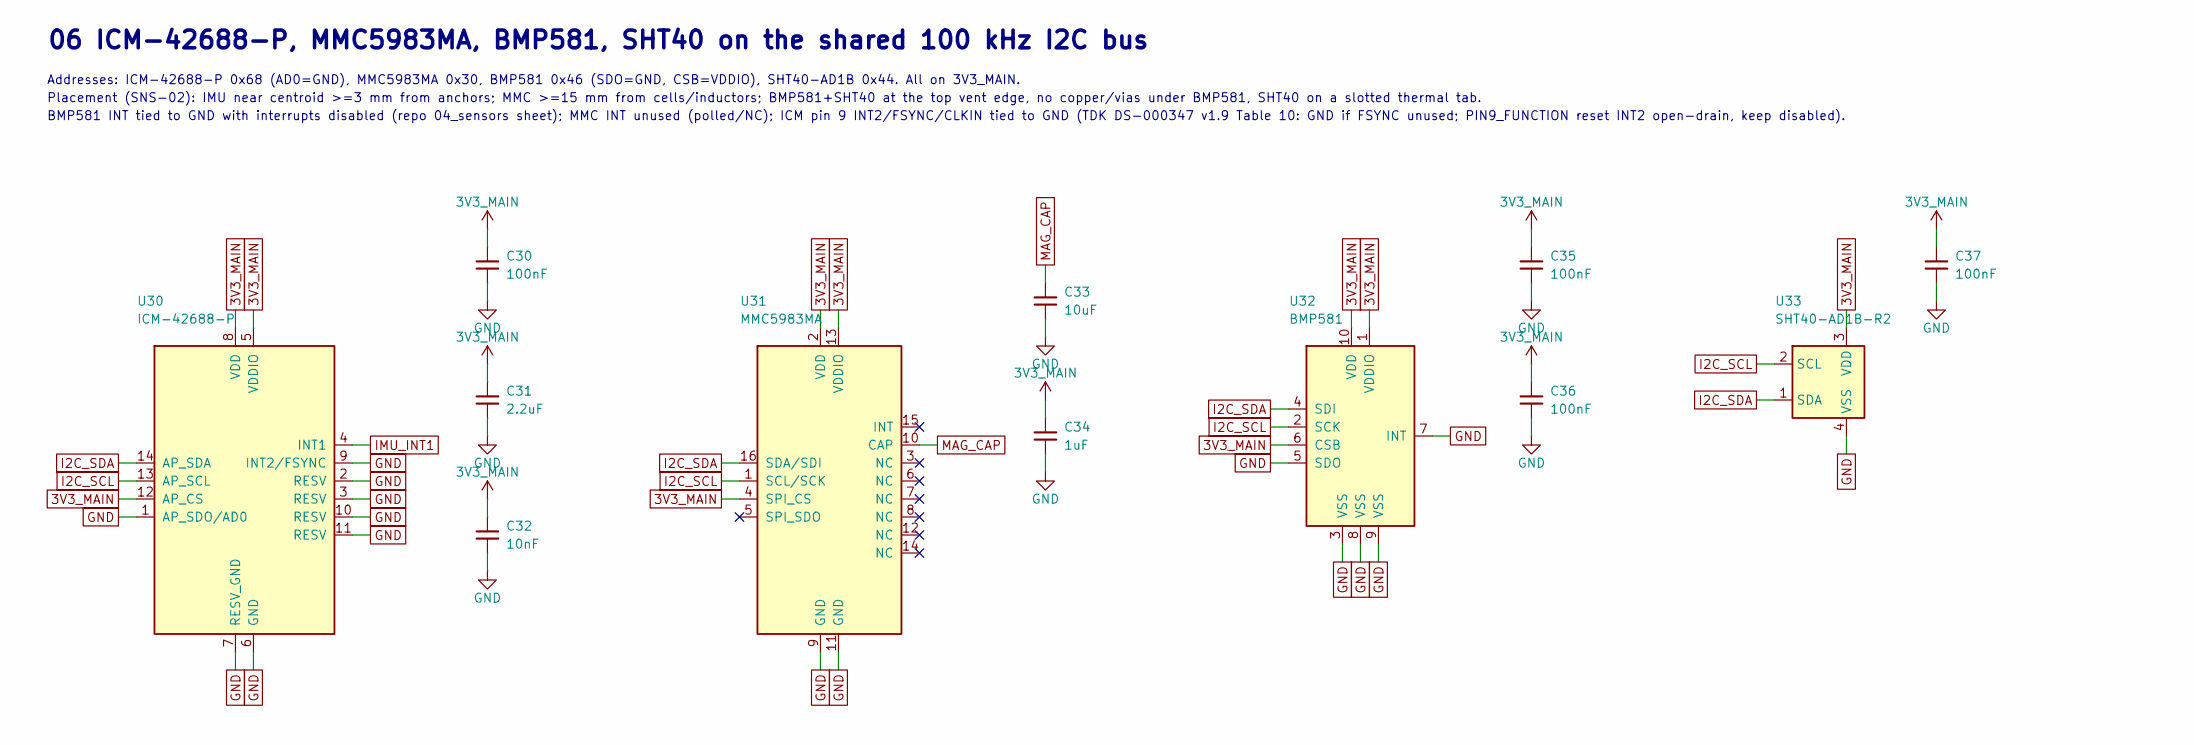
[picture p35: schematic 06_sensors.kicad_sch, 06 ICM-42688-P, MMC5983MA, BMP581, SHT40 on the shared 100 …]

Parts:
C30, C35, C36, C37: 100nF; C_0402_1005Metric
C31: 2.2uF; C_0402_1005Metric
C32: 10nF; C_0402_1005Metric
C33: 10uF; C_0603_1608Metric
C34: 1uF; C_0402_1005Metric
U30: ICM-42688-P; TDK_ICM-42688-P_LGA-14_3x2.5mm_P0.5mm; MPN ICM-42688-P
U31: MMC5983MA; MEMSIC_MMC5983MA_LGA-16_3x3mm_P0.5mm_CORRECTED; MPN MMC5983MA
U32: BMP581; Bosch_BMP581_LGA-10_2x2mm_CORRECTED; MPN BMP581
U33: SHT40-AD1B-R2; Sensirion_DFN-4_1.5x1.5mm_P0.8mm_SHT4x_NoCentralPad; MPN SHT40-AD1B-R2

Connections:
3V3_MAIN: C30.1, C31.1, C32.1, C34.1, C35.1, C36.1, C37.1, U30.5 (VDDIO), U30.8 (VDD), U30.12 (AP_CS), U31.2 (VDD), U31.4 (SPI_CS), U31.13 (VDDIO), U32.1 (VDDIO), U32.6 (CSB), U32.10 (VDD), U33.3 (VDD); also elsewhere on the board
GND: C30.2, C31.2, C32.2, C33.2, C34.2, C35.2, C36.2, C37.2, U30.1 (AP_SDO/AD0), U30.2 (RESV), U30.3 (RESV), U30.6 (GND), U30.7 (RESV_GND), U30.9 (INT2/FSYNC), U30.10 (RESV), U30.11 (RESV), U31.9 (GND), U31.11 (GND), U32.3 (VSS), U32.5 (SDO), U32.7 (INT), U32.8 (VSS), U32.9 (VSS), U33.4 (VSS); also elsewhere on the board
I2C_SCL: U30.13 (AP_SCL), U31.1 (SCL/SCK), U32.2 (SCK), U33.2 (SCL); also elsewhere on the board
I2C_SDA: U30.14 (AP_SDA), U31.16 (SDA/SDI), U32.4 (SDI), U33.1 (SDA); also elsewhere on the board
IMU_INT1: U30.4 (INT1); also elsewhere on the board
MAG_CAP: C33.1, U31.10 (CAP)

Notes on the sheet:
06 ICM-42688-P, MMC5983MA, BMP581, SHT40 on the shared 100 kHz I2C bus
Addresses: ICM-42688-P 0x68 (AD0=GND), MMC5983MA 0x30, BMP581 0x46 (SDO=GND, CSB=VDDIO), SHT40-AD1B 0x44. All on 3V3_MAIN.
Placement (SNS-02): IMU near centroid >=3 mm from anchors; MMC >=15 mm from cells/inductors; BMP581+SHT40 at the top vent edge, no copper/vias under BMP581, SHT40 on a slotted thermal tab.
BMP581 INT tied to GND with interrupts disabled (repo 04_sensors sheet); MMC INT unused (polled/NC); ICM pin 9 INT2/FSYNC/CLKIN tied to GND (TDK DS-000347 v1.9 Table 10: GND if FSYNC unused; PIN9_FUNCTION reset INT2 open-drain, keep disabled).

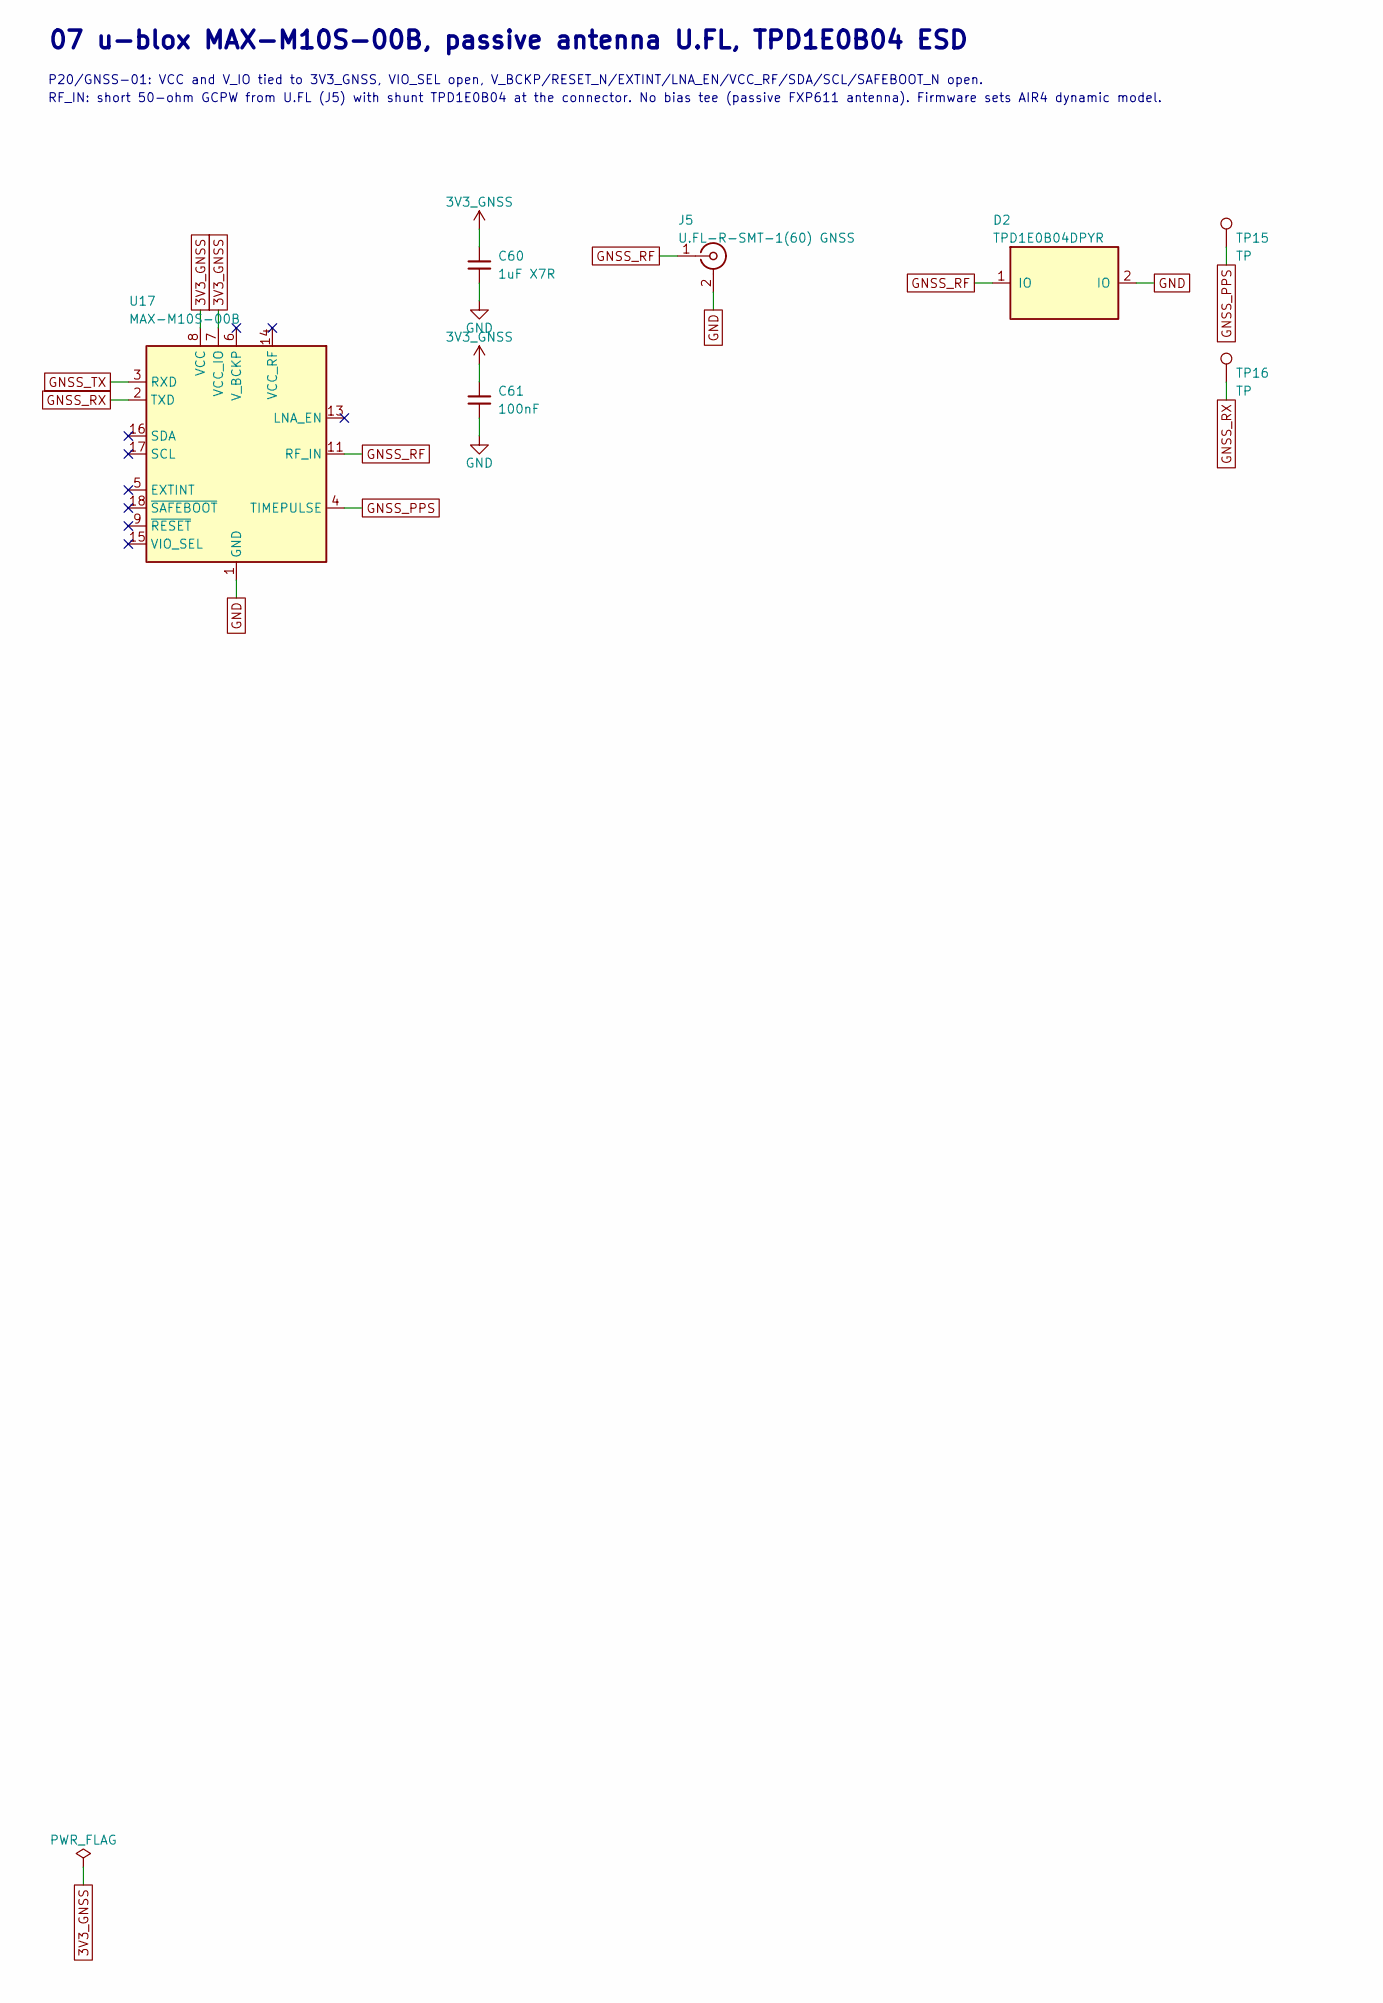
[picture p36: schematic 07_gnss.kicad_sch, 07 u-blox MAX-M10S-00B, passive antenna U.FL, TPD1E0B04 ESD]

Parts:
C60: 1uF X7R; C_0402_1005Metric
C61: 100nF; C_0402_1005Metric
D2: TPD1E0B04DPYR; TI_TPD1E0B04DPYR_X1SON-2_DPY0002A; MPN TPD1E0B04DPYR
J5: U.FL-R-SMT-1(60) GNSS; Hirose_U.FL-R-SMT-1_60_Vertical; MPN U.FL-R-SMT-1(60)
TP15, TP16: TP; TestPoint_Pad_D1.0mm
U17: MAX-M10S-00B; u-blox_MAX-M10S-00B_LCC-18_10.1x9.7mm; MPN MAX-M10S-00B

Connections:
3V3_GNSS: C60.1, C61.1, U17.7 (VCC_IO), U17.8 (VCC); also elsewhere on the board
GND: C60.2, C61.2, D2.2, J5.2 (Ext), U17.1 (GND), U17.10 (GND), U17.12 (GND); also elsewhere on the board
GNSS_PPS: TP15.1, U17.4 (TIMEPULSE); also elsewhere on the board
GNSS_RF: D2.1, J5.1 (In), U17.11 (RF_IN)
GNSS_RX: TP16.1, U17.2 (TXD); also elsewhere on the board
GNSS_TX: U17.3 (RXD); also elsewhere on the board

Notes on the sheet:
07 u-blox MAX-M10S-00B, passive antenna U.FL, TPD1E0B04 ESD
P20/GNSS-01: VCC and V_IO tied to 3V3_GNSS, VIO_SEL open, V_BCKP/RESET_N/EXTINT/LNA_EN/VCC_RF/SDA/SCL/SAFEBOOT_N open.
RF_IN: short 50-ohm GCPW from U.FL (J5) with shunt TPD1E0B04 at the connector. No bias tee (passive FXP611 antenna). Firmware sets AIR4 dynamic model.

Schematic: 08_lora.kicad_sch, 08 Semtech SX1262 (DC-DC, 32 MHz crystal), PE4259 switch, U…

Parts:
C70: 10uF; C_0603_1608Metric
C71, C73: 470nF; C_0402_1005Metric
C72: 100nF; C_0402_1005Metric
C74, C75, C76, C77, C78, C79, C80, C83: TBD (E449); C_0402_1005Metric
C81, C82: 1nF; C_0402_1005Metric
J6: U.FL-R-SMT-1(60) LoRa; Hirose_U.FL-R-SMT-1_60_Vertical; MPN U.FL-R-SMT-1(60)
L70: 15uH (DC-DC); L_0805_2012Metric
L71, L72, L73, L74: TBD (E449); L_0402_1005Metric
R70: 100k; R_0402_1005Metric
R71, R72: 100R; R_0402_1005Metric
U40: SX1262IMLTRT; QFN-24-1EP_4x4mm_P0.5mm_EP2.6x2.6mm; MPN SX1262IMLTRT
U41: PE4259; SOT-363_SC-70-6; MPN PE4259
Y2: 32 MHz (CL 10pF) MPN TBD; Crystal_SMD_2016-4Pin_2.0x1.6mm

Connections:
3V3_MAIN: C70.1, C71.1, C72.1, R70.2, R72.1, U40.1 (VDD_IN), U40.10 (VBAT), U40.11 (VBAT_IO); also elsewhere on the board
GND: C70.2, C71.2, C72.2, C73.2, C74.2, C75.2, C76.2, C77.2, C80.2, C81.2, C82.2, J6.2 (Ext), U40.2 (GND), U40.5 (GND), U40.8 (GND), U40.20 (GND), U40.25 (GND), U41.2 (GND), Y2.2 (G), Y2.4 (G); also elsewhere on the board
LORA_ANT: C83.2, J6.1 (In)
LORA_RFC: C83.1, U41.5 (RFC)
LORA_RFI_N: C80.1, L74.2, U40.22 (RFI_N)
LORA_RFI_P: C79.2, U40.21 (RFI_P)
LORA_RFO: C75.1, L71.2, L72.1, U40.23 (RFO)
LORA_RX_SW: C79.1, L74.1, U41.3 (RF2)
LORA_SW_CTRL: C81.1, R71.2, U41.4 (CTRL)
LORA_SW_VDD: C82.1, R72.2, U41.6 (VDD/CTRL_N)
LORA_TXF1: C76.1, L72.2, L73.1
LORA_TXF2: C77.1, C78.1, L73.2
LORA_TX_SW: C78.2, U41.1 (RF1)
SPI_MISO: U40.16 (MISO); also elsewhere on the board
SPI_MOSI: U40.17 (MOSI); also elsewhere on the board
SPI_SCLK: U40.18 (SCK); also elsewhere on the board
SX_BUSY: U40.14 (BUSY); also elsewhere on the board
SX_DCC_SW: L70.1, U40.9 (DCC_SW)
SX_DIO1: U40.13 (DIO1); also elsewhere on the board
SX_DIO2: R71.1, U40.12 (DIO2)
SX_NRESET: R70.1, U40.15 (~RESET); also elsewhere on the board
SX_NSS: U40.19 (NSS); also elsewhere on the board
SX_VREG: C73.1, L70.2, U40.7 (VREG)
SX_VR_PA: C74.1, L71.1, U40.24 (VR_PA)
SX_XTA: U40.3 (XTA), Y2.1
SX_XTB: U40.4 (XTB), Y2.3

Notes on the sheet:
08 Semtech SX1262 (DC-DC, 32 MHz crystal), PE4259 switch, U.FL
Topology per Semtech AN1200.40 Rev 1.1 Fig.5 (E428) / E449: VDD_IN+VBAT+VBAT_IO on 3V3_MAIN, 15uH DCC_SW-VREG (DC-DC), 470nF/100nF/10uF supply, DIO2 -> 100R/1nF -> PE4259 CTRL.
*** ALL TX match/harmonic filter and RX balun VALUES ARE TBD: AN1200.40 prints designators only. Take exact values from the native E449 regional BOM and re-tune on this stackup (AGENTS rule 5). ***
32 MHz crystal MPN TBD (CL 10 pF, ESR <=60R per SX1261/2 DS Rev 1.2). DIO3 left open (TCXO fallback). No TX before a regional configuration (AGENTS rule 14).

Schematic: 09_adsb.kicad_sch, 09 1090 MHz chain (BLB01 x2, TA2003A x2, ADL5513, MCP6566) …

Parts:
C88: 100nF; C_0402_1005Metric; not fitted
C90, C98, C800, C802, C840, C842: 100pF; C_0402_1005Metric
C91: 10uF; C_0603_1608Metric
C95, C96: 47nF; C_0402_1005Metric
C97, C100, C101, C102, C103, C104, C105, C106, C107, C110, C111, C112, C113, C116: 100nF; C_0402_1005Metric
C99: 1nF; C_0402_1005Metric; not fitted
C108, C109: 1uF; C_0402_1005Metric
C114, C115: 15pF C0G; C_0402_1005Metric
C801, C803, C841, C843: 12pF; C_0402_1005Metric
D3: TPD1E0B04DPYR (option); TI_TPD1E0B04DPYR_X1SON-2_DPY0002A; not fitted
FL1, FL2: TA2003A 1090MHz SAW; TAI-SAW_TA2003A_SMD-6_3.0x3.0mm; MPN TA2003A
J7: U.FL-R-SMT-1(60) ADS-B; Hirose_U.FL-R-SMT-1_60_Vertical; MPN U.FL-R-SMT-1(60)
L800, L840: 27nH; L_0603_1608Metric
L801, L841: 82nH; L_0603_1608Metric
R86, R87: TBD (OWN-09); R_0402_1005Metric
R88: 10k; R_0402_1005Metric; not fitted
R90: 100k; R_0402_1005Metric
R91: 10k; R_0402_1005Metric
R92, R93: 1k; R_0402_1005Metric
R95: 52.3R 1%; R_0402_1005Metric
R96, R801, R841: 0R; R_0402_1005Metric
R97: TBD (TADJ @1090 MHz); R_0402_1005Metric
R98: 2.2k 1%; R_0402_1005Metric
R800, R840: 6.8k; R_0402_1005Metric
TP20, TP21, TP22, TP23, TP24, TP25, TP26: TP; TestPoint_Pad_D1.0mm
U11: TPS22918DBVR; TI_DBV0006A_SOT-23-6_TPS22918; MPN TPS22918DBVR
U20: RP2040; QFN-56-1EP_7x7mm_P0.4mm_EP3.2x3.2mm; MPN RP2040
U21: W25Q128JVSIQ; Winbond_W25Q128JVSIQ_SOIC-8_5.3x5.3mm_P1.27mm; MPN W25Q128JVSIQ
U50, U52: BLB01; BeRex_BLB01_DFN-8-1EP_2x2mm_P0.5mm; MPN BLB01
U54: ADL5513ACPZ-R7; LFCSP-16-1EP_3x3mm_P0.5mm_EP1.7x1.7mm; MPN ADL5513ACPZ-R7
U55: MCP6566T-E/OT; SOT-23-5; MPN MCP6566T-E/OT
Y1: 12MHz ABM8-272-T3; Abracon_ABM8-272-T3_Crystal_SMD_3225-4Pin_3.2x2.5mm; MPN ABM8-272-T3

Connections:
1V1_ADSB: C109.1, C110.1, C111.1, U20.23 (DVDD), U20.45 (VREG_VOUT), U20.50 (DVDD)
3V0_RF_QUIET: C116.1, R86.1, R96.1, R800.1, R801.1, R840.1, R841.1, U55.5 (V+); also elsewhere on the board
3V3_ADSB: C91.1, C100.1, C101.1, C102.1, C103.1, C104.1, C105.1, C106.1, C107.1, C108.1, C113.1, R91.2, R98.2, TP20.1, U11.5 (QOD), U11.6 (VOUT), U20.1 (IOVDD), U20.10 (IOVDD), U20.22 (IOVDD), U20.33 (IOVDD), U20.42 (IOVDD), U20.43 (ADC_AVDD), U20.44 (VREG_VIN), U20.48 (USB_VDD), U20.49 (IOVDD), U21.8 (VCC); also elsewhere on the board
3V3_MAIN: U11.1 (VIN); also elsewhere on the board
ADSB_ANT: C800.1, D3.1, J7.1 (In)
ADSB_CLPF: C99.1, U54.14 (CLPF)
ADSB_CT: C90.1, U11.4 (CT)
ADSB_DET_IN: C95.1, FL2.E (OUT), R95.1
ADSB_DET_VP: C97.1, C98.1, R96.2, U54.1 (VPOS), U54.4 (VPOS)
ADSB_INHI: C95.2, U54.2 (INHI)
ADSB_INLO: C96.1, U54.3 (INLO)
ADSB_L1_BIAS: C801.1, L800.1, R800.2
ADSB_L1_IN: C800.2, U50.2 (RFIN)
ADSB_L1_OUT: C803.1, L801.2, U50.7 (RFOUT/VDD)
ADSB_L1_VD: C802.1, L801.1, R801.2
ADSB_L1_VEN: L800.2, U50.1 (VEN/VBIAS)
ADSB_L2_BIAS: C841.1, L840.1, R840.2
ADSB_L2_IN: C840.2, U52.2 (RFIN)
ADSB_L2_OUT: C843.1, L841.2, U52.7 (RFOUT/VDD)
ADSB_L2_VD: C842.1, L841.1, R841.2
ADSB_L2_VEN: L840.2, U52.1 (VEN/VBIAS)
ADSB_PULSE: R98.1, TP26.1, U20.11 (GPIO8), U55.1
ADSB_S1_IN: C803.2, FL1.B (IN)
ADSB_S1_OUT: C840.1, FL1.E (OUT)
ADSB_S2_IN: C843.2, FL2.B (IN)
ADSB_SW_EN: R90.1, U11.3 (ON); also elsewhere on the board
ADSB_TADJ: R97.1, U54.9 (TADJ)
ADSB_THR: C88.1, R86.2, R87.1, R88.2, U55.4 (-)
ADSB_THR_PWM: R88.1, U20.12 (GPIO9)
ADSB_VIDEO: TP25.1, U54.11 (VSET), U54.12 (VOUT), U55.3 (+)
GND: C88.2, C90.2, C91.2, C96.2, C97.2, C98.2, C99.2, C100.2, C101.2, C102.2, C103.2, C104.2, C105.2, C106.2, C107.2, C108.2, C109.2, C110.2, C111.2, C112.2, C113.2, C114.2, C115.2, C116.2, C801.2, C802.2, C841.2, C842.2, D3.2, FL1.A (GND), FL1.C (GND), FL1.D (GND), FL1.F (GND), FL2.A (GND), FL2.C (GND), FL2.D (GND), FL2.F (GND), J7.2 (Ext), R87.2, R90.2, R95.2, R97.2, U11.2 (GND), U20.19 (TESTEN), U20.57 (GND), U21.4 (GND), U50.9 (GND), U52.9 (GND), U54.10 (COMM), U54.17 (EPAD), U55.2 (V-), Y1.2 (G), Y1.4 (G); also elsewhere on the board
QSPI_SCLK: U20.52 (QSPI_SCLK), U21.6 (CLK)
QSPI_SD0: U20.53 (QSPI_SD0), U21.5 (DI/IO_{0})
QSPI_SD1: U20.55 (QSPI_SD1), U21.2 (DO/IO_{1})
QSPI_SD2: U20.54 (QSPI_SD2), U21.3 (~WP/IO_{2})
QSPI_SD3: U20.51 (QSPI_SD3), U21.7 (~HOLD/~RESET/IO_{3})
QSPI_SS: R92.1, U20.56 (~QSPI_SS), U21.1 (~CS)
RP_RUN: C112.1, R91.1, TP22.1, U20.26 (RUN); also elsewhere on the board
RP_SWCLK: TP23.1, U20.24 (SWCLK)
RP_SWDIO: TP24.1, U20.25 (SWDIO)
RP_UART_CTS: U20.5 (GPIO3); also elsewhere on the board
RP_UART_RTS: U20.4 (GPIO2); also elsewhere on the board
RP_UART_RX: U20.2 (GPIO0); also elsewhere on the board
RP_UART_TX: U20.3 (GPIO1); also elsewhere on the board
RP_XIN: C114.1, U20.20 (XIN), Y1.1
RP_XOUT: R93.1, U20.21 (XOUT)
RP_XTAL_R: C115.1, R93.2, Y1.3
USB_BOOT: R92.2, TP21.1

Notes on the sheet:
09 1090 MHz chain (BLB01 x2, TA2003A x2, ADL5513, MCP6566) and RP2040 capture
Chain per docs/ADSB_VALIDATION.md. BLB01 bias per BeRex rev 6.6 evaluation BOM (C1 100pF in, C2 12pF out, R1 6.8k/C3 12pF/L1 27nH Ven, R2 0R/C4 100pF/L2 82nH Vd).
ADL5513 measurement mode (VSET=VOUT), 52.3R input termination, 47nF coupling. TADJ resistor and CLPF (1 nF basic value is too slow for 0.5 us pulses) are TBD/bench items.
MCP6566T-E/OT base pin map, 2.2k pull-up to the RP2040 bank; threshold divider R86/R87 BLOCKED by OWN-09 (value TBD). R88/C88 DNP option: RP2040 PWM threshold.
RP2040 per DIG-01 (Raspberry Pi minimal design): 12 MHz ABM8-272-T3 + 1k XOUT, 15pF loads; QSPI_SS 1k to USB_BOOT pad; RUN 10k/100nF + TCA9535 P14. Domain 3V3_ADSB switched (P13).
UART0: GPIO0 TX -> RP_UART_RX, GPIO1 RX <- RP_UART_TX, GPIO2 CTS <- RP_UART_RTS, GPIO3 RTS -> RP_UART_CTS (one-shot pin choice). Back-power of ESP32-driven lines into an OFF RP2040 is an open SYS-02 item.

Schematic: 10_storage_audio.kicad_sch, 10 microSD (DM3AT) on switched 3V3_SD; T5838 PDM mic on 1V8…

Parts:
C120, C123: 100pF; C_0402_1005Metric
C121: 10uF; C_0603_1608Metric
C122, C125, C126: 100nF; C_0402_1005Metric
C124: 1uF; C_0402_1005Metric
C127: 100nF X7R; C_0402_1005Metric
J8: DM3AT-SF-PEJM5; Hirose_DM3AT-SF-PEJM5_microSD_HC; MPN DM3AT-SF-PEJM5
MK1: MMICT5838-00-012; TDK_T5838_LGA-7_3.5x2.65mm_BottomPort; MPN MMICT5838-00-012
R100, R104, R105, R106: 100k; R_0402_1005Metric
R101, R102, R103: 10k; R_0402_1005Metric
TP27, TP28: TP; TestPoint_Pad_D1.0mm
U10, U12: TPS22918DBVR; TI_DBV0006A_SOT-23-6_TPS22918; MPN TPS22918DBVR
U23: TPD4E05U06DQAR; USON-10_2.5x1.0mm_P0.5mm; MPN TPD4E05U06DQARG4
U24: TXU0202DCUR; TI_DCU0008A_VSSOP-8_2.3x2mm_P0.5mm_TXU0202; MPN TXU0202DCUR

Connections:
1V8_AUDIO_SW: C124.1, C126.1, C127.1, MK1.7 (VDD), R106.2, U12.5 (QOD), U12.6 (VOUT), U24.7 (VCCB)
1V8_LOGIC: U12.1 (VIN); also elsewhere on the board
3V3_MAIN: C125.1, R104.2, U10.1 (VIN), U24.3 (VCCA); also elsewhere on the board
3V3_SD: C121.1, C122.1, J8.4 (VDD), R101.2, R102.2, R103.2, TP27.1, U10.5 (QOD), U10.6 (VOUT)
AUD_CT: C123.1, U12.4 (CT)
AUD_SW_EN: R105.1, U12.3 (ON); also elsewhere on the board
GND: C120.2, C121.2, C122.2, C123.2, C124.2, C125.2, C126.2, C127.2, J8.6 (VSS), J8.10 (DET_A), J8.SH (SHIELD), MK1.2 (SELECT), MK1.3 (GND), MK1.5 (THSEL), R100.2, R105.2, U10.2 (GND), U12.2 (GND), U23.3 (GND), U23.8 (GND), U24.2 (GND); also elsewhere on the board
PDM_CLK: U24.5 (A1); also elsewhere on the board
PDM_CLK_1V8: MK1.6 (CLK), U24.8 (B1Y)
PDM_DATA: U24.4 (A2Y); also elsewhere on the board
PDM_DATA_1V8: MK1.1 (DATA), U24.1 (B2)
PDM_OE: R106.1, U24.6 (OE)
SD_CD: J8.9 (DET_B), R104.1, TP28.1; also elsewhere on the board
SD_CS: J8.2 (DAT3/CD), R101.1, U23.5 (D2-); also elsewhere on the board
SD_CT: C120.1, U10.4 (CT)
SD_SW_EN: R100.1, U10.3 (ON); also elsewhere on the board
SPI_MISO: J8.7 (DAT0), R103.1, U23.4 (D2+); also elsewhere on the board
SPI_MOSI: J8.3 (CMD), R102.1, U23.2 (D1-); also elsewhere on the board
SPI_SCLK: J8.5 (CLK), U23.1 (D1+); also elsewhere on the board

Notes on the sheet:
10 microSD (DM3AT) on switched 3V3_SD; T5838 PDM mic on 1V8_AUDIO_SW
DIG-02: SPI mode (DAT3 = SD_CS), 10k pull-ups on CMD/DAT0/DAT3 to 3V3_SD (never 3V3_MAIN), no CLK pull-up, card detect 100k to 3V3_MAIN on TCA P00, TPD4E05U06 at the socket.
AUD-01/AUD-02: 1V8_AUDIO_SW = TPS22918 branch from 1V8_LOGIC (AUD_SW_EN, pull-down). TXU0202 A1->B1Y clock, B2->A2Y data, OE 100k to 1V8_AUDIO_SW.
T5838 SELECT=GND (DATA1/right), THSEL=GND and WAKE open (no AAD). 0.8 mm sound hole in the footprint, no paste on the port.

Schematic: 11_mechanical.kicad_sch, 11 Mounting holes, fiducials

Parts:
FID1, FID2, FID3: Fiducial; Fiducial_1mm_Mask2mm
H1, H2, H3: M2.5; MountingHole_2.7mm_M2.5

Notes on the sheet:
11 Mounting holes, fiducials
Three M2.5 mounting holes in the left strip (the 2S holder covers the back for x > 14.7 mm; holder is fixed to the rear shell); three fiducials.

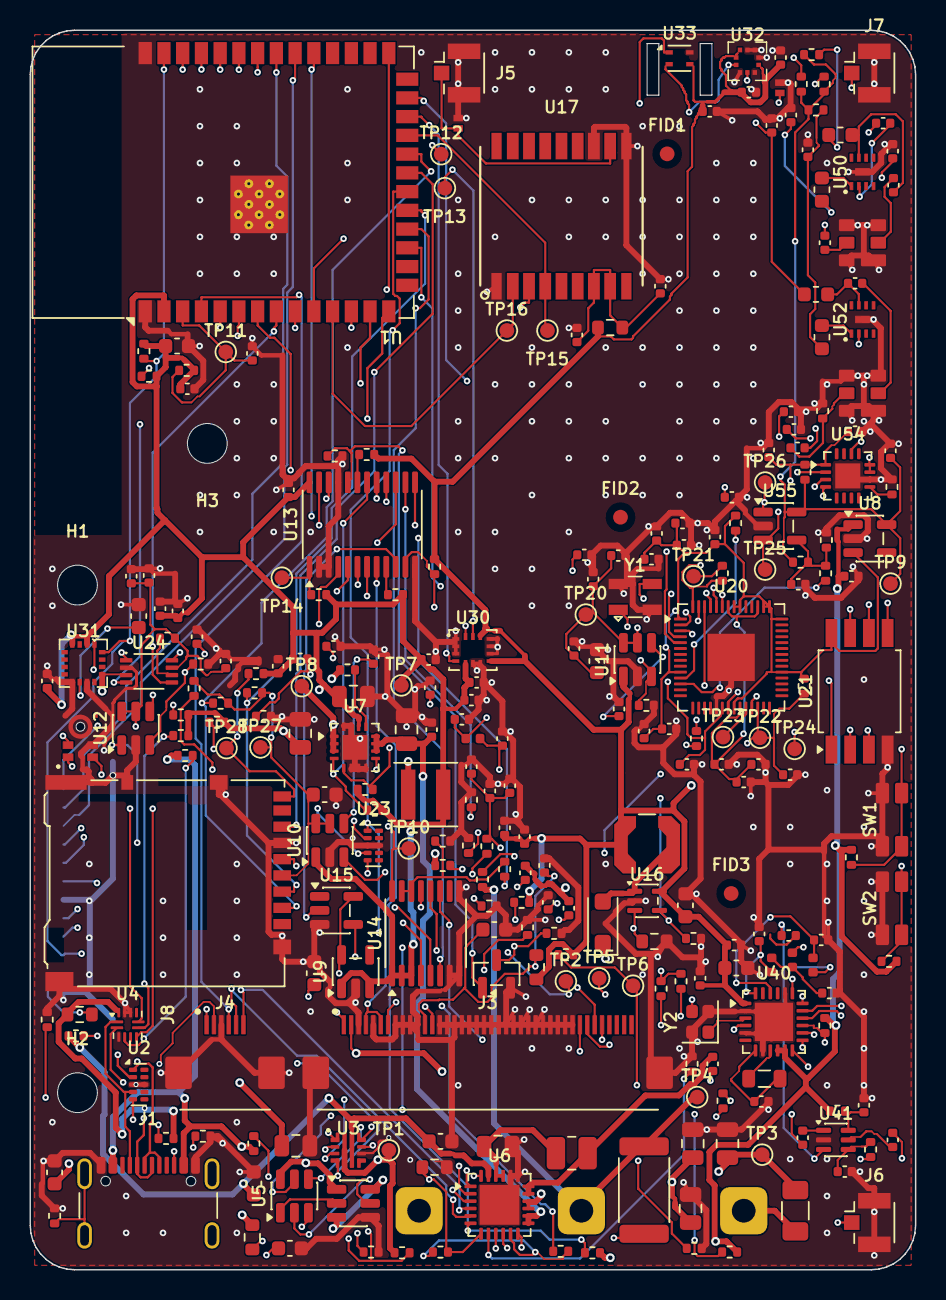
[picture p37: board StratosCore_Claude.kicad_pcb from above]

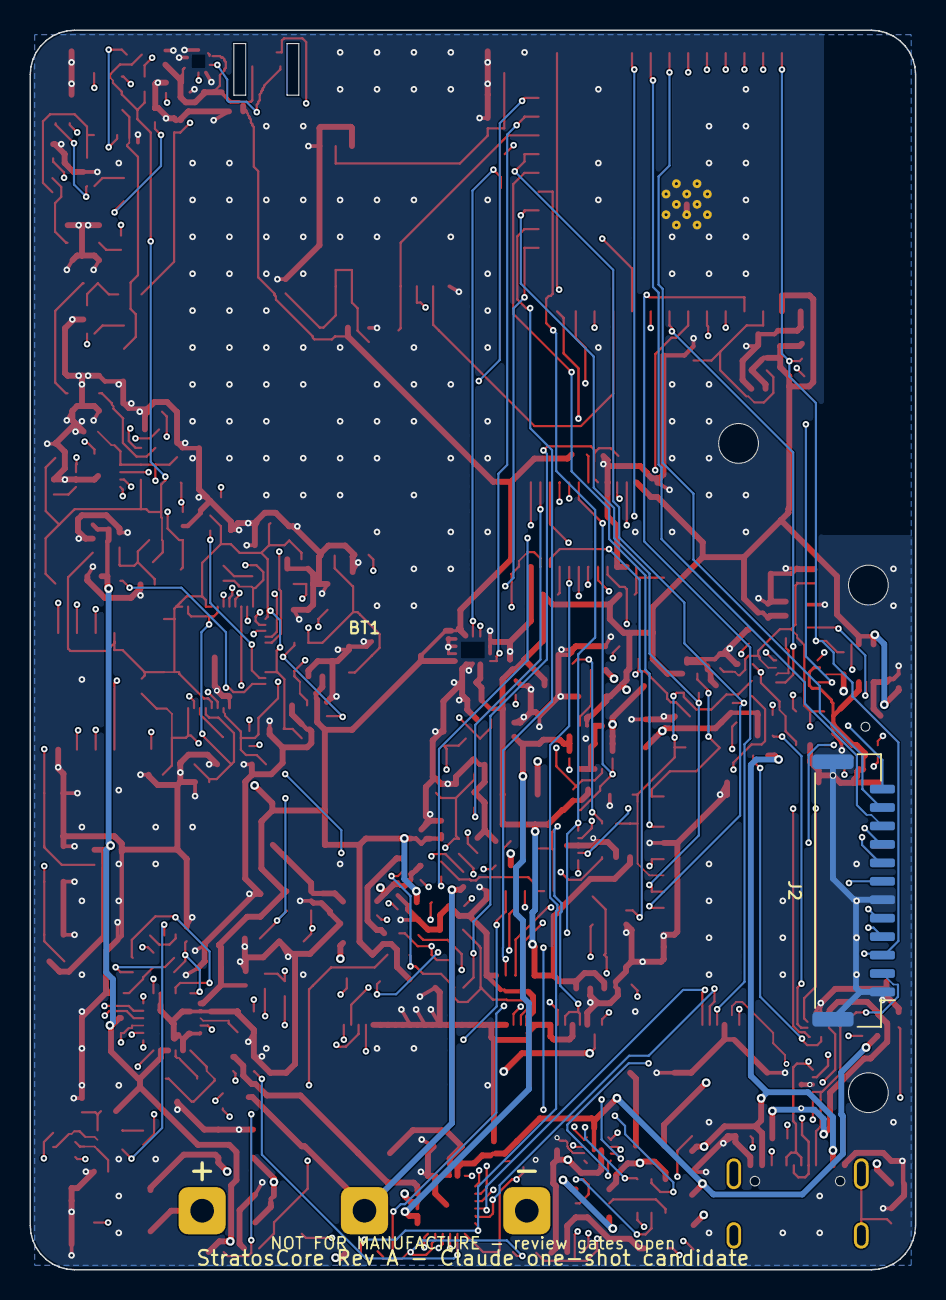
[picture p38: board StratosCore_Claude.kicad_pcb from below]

Board: 4 copper layers, 60.0 x 84.0 mm, 277 parts (2 on the bottom side), 169 nets.

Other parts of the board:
DS1: AFY240320A1-2.8INTH-C1 (envelope); Display_Orient_AFY240320A1-2.8INTH-C1_Envelope

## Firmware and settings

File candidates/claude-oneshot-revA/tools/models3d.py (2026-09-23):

"""STEP models for the parts that have no KiCad library model, plus the display module and a
printed-enclosure concept. Geometry = published envelope dimensions only (no invented detail
beyond simple visual cues). Run with a Python that has CadQuery:

    <venv-with-cadquery>/python tools/models3d.py

Outputs: kicad/libs/SC.3dshapes/*.step (per-footprint models) and mech/*.step (enclosure).
All models are ENVELOPES for fit/collision review, not manufacturer CAD.
"""
from __future__ import annotations

from pathlib import Path

import cadquery as cq

ROOT = Path(__file__).resolve().parent.parent
LIB = ROOT / "kicad" / "libs" / "SC.3dshapes"
MECH = ROOT / "mech"
LIB.mkdir(parents=True, exist_ok=True)
MECH.mkdir(parents=True, exist_ok=True)

# KiCad footprint coordinates are y-down; STEP/3D is y-up. Every model below is authored in
# footprint coordinates with y already negated where it matters.


def save(shape, name, folder=LIB):
    cq.exporters.export(shape, str(folder / f"{name}.step"))
    print("wrote", name)


def box(x0, y0, x1, y1, z0, z1):
    """Box from footprint-coordinate rectangle (y down) to 3D (y up)."""
    return (cq.Workplane("XY").box(x1 - x0, y1 - y0, z1 - z0, centered=False)
            .translate((x0, -y1, z0)))


def display(standoff=5.0):
    """Orient AFY240320A1-2.8INTH-C1: 50.45 x 69.90 x 4.22 mm, active area 43.20 x 57.60 mm
    (rev J spec). Active-area offset inside the outline and FPC tail geometry are TBD from the
    controlled drawing -> active area centred horizontally, 1.6 mm toward the FPC end; tails
    drawn as a flat fold toward the PCB connectors at the bottom edge. Origin = module centre,
    z = 0 at the module underside (the footprint adds the standoff)."""
    W, H, T = 50.45, 69.90, 4.22
    frame = box(-W / 2, -H / 2, W / 2, H / 2, 0, T - 0.7)
    glass = box(-W / 2 + 0.2, -H / 2 + 0.2, W / 2 - 0.2, H / 2 - 0.2, T - 0.7, T)
    aa = box(-21.6, -28.8 - 1.6, 21.6, 28.8 - 1.6, T - 0.05, T + 0.01)
    # FPC tails (40 p: 20.5 wide; 6 p: ~4.7 wide) folding down behind the module bottom edge
    tail40 = box(1.0 - 10.25, H / 2, 1.0 + 10.25, H / 2 + 1.2, -standoff + 0.3, T - 1.0)   # centred on J3 (board x 31)
    tail6 = box(-16.8 - 2.35, H / 2, -16.8 + 2.35, H / 2 + 1.2, -standoff + 0.3, T - 1.0)   # centred on J4 (board x 13.2)
    asm = (cq.Assembly(name="AFY240320A1_envelope")
           .add(frame, name="frame", color=cq.Color(0.75, 0.75, 0.78))
           .add(glass, name="cover_glass", color=cq.Color(0.08, 0.08, 0.1, 0.9))
           .add(aa, name="active_area", color=cq.Color(0.05, 0.25, 0.55))
           .add(tail40, name="fpc40", color=cq.Color(0.85, 0.55, 0.1))
           .add(tail6, name="fpc6", color=cq.Color(0.85, 0.55, 0.1)))
    asm.save(str(LIB / "Display_Orient_AFY240320A1-2.8INTH-C1_Envelope.step"))
    print("wrote display")


def holder_2s():
    """Two 21700 cells in a series holder, envelope 82.2 x 45.1 x 17.3 mm (Keystone 1123 class
    reference). Footprint origin = holder centre; model modelled on the component side (+z),
    KiCad mirrors it to the board bottom when the footprint is flipped."""
    L, Wd, Hh = 82.2, 45.1, 17.27
    base = box(-Wd / 2, -L / 2, Wd / 2, L / 2, 0, 2.0)
    walls = (box(-Wd / 2, -L / 2, Wd / 2, -L / 2 + 3, 0, Hh)
             .union(box(-Wd / 2, L / 2 - 3, Wd / 2, L / 2, 0, Hh)))
    cells = None
    for cx in (-11.0, 11.0):
        c = (cq.Workplane("XZ").center(cx, 2.0 + 10.85).circle(10.85).extrude(70.2 / 2, both=True))
        cells = c if cells is None else cells.union(c)
    asm = (cq.Assembly(name="holder_2S_21700")
           .add(base.union(walls), name="holder", color=cq.Color(0.1, 0.1, 0.1))
           .add(cells, name="cells_M50A_envelope", color=cq.Color(0.15, 0.45, 0.2)))
    asm.save(str(LIB / "BatteryHolder_2S_21700_TBD.step"))
    print("wrote holder")


def xf3m(pins, B, name):
    body = box(-B / 2, -1.0, B / 2, 5.55, 0, 2.0)
    slot = box(-B / 2 + 0.8, 3.8, B / 2 - 0.8, 5.6, 0.6, 1.4)
    lever = box(-B / 2 + 0.4, 4.2, B / 2 - 0.4, 5.55, 1.6, 2.0)
    asm = (cq.Assembly(name=name).add(body.cut(slot), name="housing", color=cq.Color(0.9, 0.9, 0.85))
           .add(lever, name="lock", color=cq.Color(0.2, 0.2, 0.2)))
    asm.save(str(LIB / f"{name}.step"))


def simple(name, x0, y0, x1, y1, h, color=(0.2, 0.2, 0.2), extra=None):
    s = box(x0, y0, x1, y1, 0, h)
    if extra is not None:
        s = s.union(extra)
    asm = cq.Assembly(name=name).add(s, name="body", color=cq.Color(*color))
    asm.save(str(LIB / f"{name}.step"))


def enclosure(board_w=60.0, board_h=84.0, wall=2.0, depth=37.0):
    """Printed two-part enclosure concept (about 64 x 88 x 37 mm, MECHANICAL_RF_FLOORPLAN.md):
    front bezel with display window and back shell with a battery door. Openings: USB-C, microSD,
    two side buttons, JST expansion (rear), three U.FL->SMA bulkhead holes, vent/acoustic holes.
    Board coordinates: origin at the board top-left, y down; enclosure built around it."""
    ox, oy = board_w / 2, board_h / 2
    W, H = board_w + 2 * wall + 0.8, board_h + 2 * wall + 0.8
    front_h, back_h = 11.5, depth - 11.5   # display top = PCB + 5.0 standoff + 4.22 -> 9.2 mm < 11.5 - 2 wall
    # z: PCB top at 0; front shell above, back shell below
    fb = (cq.Workplane("XY").box(W, H, front_h).translate((0, 0, front_h / 2))
          .edges("|Z").fillet(4.0))
    fb = fb.cut(cq.Workplane("XY").box(W - 2 * wall, H - 2 * wall, front_h - wall)
                .translate((0, 0, (front_h - wall) / 2)))
    # display viewing window over the active area (display centred at board y 48.55)
    dy = -(48.55 - oy) + 1.6
    fb = fb.cut(cq.Workplane("XY").box(44.0, 58.4, 3 * wall).translate((0, dy, front_h)))
    bs = (cq.Workplane("XY").box(W, H, back_h).translate((0, 0, -back_h / 2))
          .edges("|Z").fillet(4.0))
    bs = bs.cut(cq.Workplane("XY").box(W - 2 * wall, H - 2 * wall, back_h - wall)
                .translate((0, 0, -(back_h - wall) / 2)))
    # battery door outline (separate part) - cut as a thin groove to show it
    door = cq.Workplane("XY").box(46.0, 83.0, wall).translate((37.35 - ox, 0, -back_h + wall / 2))
    bs = bs.cut(door.faces(">Z").shell(-0.4)) if False else bs

    def at(x, y):
        return x - ox, -(y - oy)
    # USB-C (bottom edge, board x 13.5), 9.5 x 3.6 mm opening centred 1.6 mm above PCB top
    ux, _ = at(8.0, 84)
    bs = bs.cut(cq.Workplane("XY").box(10.0, 3 * wall, 4.0).translate((ux, -H / 2, 1.6)))
    fb = fb.cut(cq.Workplane("XY").box(10.0, 3 * wall, 4.0).translate((ux, -H / 2, 1.6)))
    # microSD slot (left edge, board y 50)
    _, sy = at(0, 50)
    fb = fb.cut(cq.Workplane("XY").box(3 * wall, 12.5, 2.2).translate((-W / 2, sy, 1.0)))
    # side buttons (right edge, board y 52 / 59): plunger holes
    for by in (53.5, 59.5):
        _, py = at(60, by)
        fb = fb.cut(cq.Workplane("YZ").circle(1.4).extrude(3 * wall).translate((W / 2 - 2 * wall, py, 0.8)))
    # SMA bulkheads for GNSS / ADS-B (top edge) and LoRa (bottom edge): 6.5 mm holes in the back shell
    for bx, by, edge in ((29.0, 0, "top"), (57.2, 0, "top"), (57.2, 84, "bottom")):
        x, _ = at(bx, by)
        yy = H / 2 if edge == "top" else -H / 2
        bs = bs.cut(cq.Workplane("XZ").circle(3.25).extrude(3 * wall, both=True)
                    .translate((min(max(x, -W / 2 + 6), W / 2 - 6), yy, -8.0)))
    # vents: static pressure (BMP581) and humidity (SHT40) at the top edge, acoustic port on the back
    for vx, d in ((48.6, 1.5), (44.0, 1.5)):
        x, _ = at(vx, 0)
        fb = fb.cut(cq.Workplane("XZ").circle(d / 2).extrude(3 * wall, both=True).translate((x, H / 2, 1.0)))
    mx, my = at(3.4, 47.2)
    bs = bs.cut(cq.Workplane("XY").circle(0.6).extrude(3 * wall, both=True).translate((mx, my, -back_h)))
    # expansion connector opening (rear, JST GH vertical at board 4.2,16 rotated)
    ex, ey = at(4.2, 58.3)
    bs = bs.cut(cq.Workplane("XY").box(6.0, 20.0, 3 * wall).translate((ex + 1.0, ey, -back_h)))
    save(fb, "Enclosure_Front_Bezel", MECH)
    save(bs, "Enclosure_Back_Shell", MECH)


if __name__ == "__main__":
    display()
    holder_2s()
    xf3m(40, 23.1, "Omron_XF3M-4015-1B_1x40-1MP_P0.5mm_Horizontal")
    xf3m(6, 6.1, "Omron_XF3M-0615-1B_1x06-1MP_P0.5mm_Horizontal")
    plunger = box(-0.8, 1.775, 0.8, 2.45, 0.2, 1.05)
    simple("SW_Alps_SKSCLCE010_SidePush", -1.75, -1.775, 1.75, 1.775, 1.25, (0.75, 0.75, 0.75), plunger)
    simple("TDK_T5838_LGA-7_3.5x2.65mm_BottomPort", -2.5, -1.325, 1.0, 1.325, 0.98, (0.8, 0.8, 0.82))
    simple("TAI-SAW_TA2003A_SMD-6_3.0x3.0mm", -1.5, -1.5, 1.5, 1.5, 1.4, (0.8, 0.8, 0.82))
    simple("BeRex_BLB01_DFN-8-1EP_2x2mm_P0.5mm", -1.0, -1.0, 1.0, 1.0, 0.55, (0.1, 0.1, 0.1))
    # envelope bodies for parts whose footprint has no (existing) 3D model in KiCad 10.0.6
    simple("TI_RPW0010A_VQFN-HR-10_2x2mm_P0.45mm", -1.0, -1.0, 1.0, 1.0, 0.9, (0.12, 0.12, 0.12))
    simple("TI_RWB0012B_X2QFN-12_1.6x1.6mm_TUSB320LAI", -0.8, -0.8, 0.8, 0.8, 0.4, (0.12, 0.12, 0.12))
    simple("Bosch_BMP581_LGA-10_2x2mm_CORRECTED", -1.0, -1.0, 1.0, 1.0, 0.8, (0.78, 0.78, 0.8))
    simple("TI_TPD1E0B04DPYR_X1SON-2_DPY0002A", -0.5, -0.3, 0.5, 0.3, 0.4, (0.12, 0.12, 0.12))
    simple("TDK_ICM-42688-P_LGA-14_3x2.5mm_P0.5mm", -1.5, -1.25, 1.5, 1.25, 0.91, (0.12, 0.12, 0.12))
    simple("MEMSIC_MMC5983MA_LGA-16_3x3mm_P0.5mm_CORRECTED", -1.5, -1.5, 1.5, 1.5, 1.0, (0.12, 0.12, 0.12))
    simple("u-blox_MAX-M10S-00B_LCC-18_10.1x9.7mm", -4.85, -5.05, 4.85, 5.05, 2.5, (0.75, 0.75, 0.78))
    simple("L_Coilcraft_LPS4018_SC", -1.95, -1.95, 1.95, 1.95, 1.8, (0.25, 0.25, 0.25))
    simple("L_Coilcraft_XxL4020_SC", -2.0, -2.0, 2.0, 2.0, 2.1, (0.25, 0.25, 0.25))
    simple("Sensirion_DFN-4_1.5x1.5mm_P0.8mm_SHT4x_NoCentralPad_SC", -0.75, -0.75, 0.75, 0.75, 0.55, (0.3, 0.3, 0.3))
    enclosure()

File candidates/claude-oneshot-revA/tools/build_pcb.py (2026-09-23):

"""Build the candidate PCB from the schematic netlist: 4-layer 60 x 84 mm outline, zoned
placement per docs/MECHANICAL_RF_FLOORPLAN.md, automatic passive placement next to the part
each passive serves, keepouts, net classes, optional Freerouting, zones, DRC and exports.

Run with KiCad's bundled Python (pcbnew):
    "C:/Program Files/KiCad/10.0/bin/python.exe" tools/build_pcb.py [--route]
"""
from __future__ import annotations

import argparse
import json
import math
import os
import subprocess
import sys
import xml.etree.ElementTree as ET
from pathlib import Path

import pcbnew

HERE = Path(__file__).resolve().parent
sys.path.insert(0, str(HERE))
from build_sch import CLI, DISPLAY_STANDOFF, OUT, PROJECT  # noqa: E402

KFP = Path("C:/Program Files/KiCad/10.0/share/kicad/footprints")
mm = pcbnew.FromMM
W, H = 60.0, 84.0
BOARD = OUT / f"{PROJECT}.kicad_pcb"
TOOLS = Path(os.environ.get("STRATOS_TOOLS", "D:/claude_scratch/stratos/tools"))
JAVA = TOOLS / "jdk-25.0.4.1+1-jre" / "bin" / "java.exe"
FREEROUTING = TOOLS / "freerouting-2.4.1.jar"

# --------------------------------------------------------------------------- placement
# (x, y, rotation deg, side) in board mm, origin top-left, y down. "B" = bottom side.
PLACE = {
    # ESP32-S3 rotated so its PCB antenna sits at the LEFT board edge (x 0.3-6.3 mm), clear of
    # the 2S holder (back side, x >= 14.7 mm). Footprint keepout covers x 0-6.3, y 0-34.3 in-board.
    "U1": (13.05, 10.3, 90, "F"),
    # top strip (x 27-60): GNSS feed, vent group, ADS-B input
    "J5": (29.0, 2.9, 0, "F"), "D2": (29.0, 6.3, 90, "F"), "U17": (36.0, 12.6, 0, "F"),
    "U33": (44.0, 1.9, 0, "F"), "U32": (48.6, 2.1, 0, "F"),
    "J7": (57.2, 2.9, 0, "F"), "U50": (56.4, 9.6, 90, "F"), "FL1": (56.4, 14.4, 90, "F"),
    "U52": (56.4, 19.6, 90, "F"), "FL2": (56.4, 24.6, 90, "F"), "U54": (55.4, 30.2, 0, "F"),
    "U55": (50.8, 33.6, 0, "F"), "U20": (47.5, 42.5, 0, "F"), "U21": (56.2, 44.8, 90, "F"),
    "Y1": (41.0, 38.4, 0, "F"),
    # sensors: IMU near the centroid, magnetometer in the upper-left (far from cells/inductors)
    "U30": (30.0, 42.0, 0, "F"), "U31": (3.6, 42.9, 0, "F"), "MK1": (3.4, 47.2, 90, "F"),
    # control
    "U13": (22.5, 33.5, 90, "F"), "SW1": (58.4, 53.5, 90, "F"), "SW2": (58.4, 59.5, 90, "F"),
    # storage: microSD at the left edge (card inserts from the left); expansion on the back-left
    "J8": (9.35, 57.8, 270, "F"), "J2": (4.2, 58.3, 90, "B"),
    # display FPC connectors; FPC tails fold around the display bottom edge (lengths TBD)
    "J3": (31.0, 67.4, 0, "F"), "J4": (13.2, 67.4, 0, "F"), "U14": (26.8, 61.2, 90, "F"),
    "U16": (41.8, 59.0, 0, "F"), "L3": (41.8, 55.2, 0, "F"),
    # LoRa bottom-right corner
    "U40": (50.4, 67.2, 0, "F"), "Y2": (45.4, 67.2, 90, "F"), "U41": (54.6, 75.2, 0, "F"),
    "J6": (57.2, 80.8, 0, "F"),
    # power: USB-C at the bottom edge, charger between the holder tabs, buck in the core
    "J1": (8.0, 80.6, 0, "F"), "U6": (31.8, 79.6, 0, "F"), "U7": (22.0, 48.6, 0, "F"),
    "L2": (26.8, 51.8, 0, "F"),
    # 2S holder on the back, right-aligned; B+/MID/B- tabs grouped at the bottom end (placeholders)
    "BT1": (37.35, 42.0, 180, "B"),
    # mechanical
    "H1": (3.2, 37.6, 0, "F"), "H2": (3.2, 72.0, 0, "F"), "H3": (12.0, 28.0, 0, "F"),
    "FID1": (44.0, 8.6, 0, "F"), "FID2": (40.0, 33.0, 0, "F"), "FID3": (20.6, 82.8, 0, "F"),
}
PASSIVE_PREFIX = ("R", "C", "L", "D", "TP", "FL", "Q", "TH", "F", "Y")
# regions where no auto-placed part may land (board mm): ESP32 antenna copper keepout,
# SHT40 thermal tab, display FPC tail fold zone in front of J3/J4 mouths
KEEPOUT = [(0.0, 0.0, 6.7, 34.6), (41.5, 0.0, 46.5, 4.8), (4.0, 73.3, 43.2, 74.4)]
# ADS-B/LoRa/GNSS RF nets (routed first-choice short; 0.15 mm ~ 50 ohm on L1/L2 per PCB_STACKUP.md)
RF_NETS = ("GNSS_RF", "ADSB_", "LORA_")
POWER_NETS = ("GND", "VBUS", "VBUS_PROT", "PACK_P", "BAT_P", "BAT_N", "BAT_MID", "CHG_PMID", "CHG_SW",
              "CHG_SNS", "BUCK_SW", "3V3_MAIN", "BL_SW", "LED_A", "PROT_DRAIN")


def read_netlist():
    xml = OUT / "reports" / "netlist.xml"
    subprocess.run([CLI, "sch", "export", "netlist", "--format", "kicadxml", "-o", str(xml),
                    str(OUT / f"{PROJECT}.kicad_sch")], capture_output=True, text=True, check=True)
    root = ET.parse(xml).getroot()
    comps = []
    for c in root.iter("comp"):
        sp = c.find("sheetpath")
        fields = {f.get("name"): (f.text or "") for f in c.iter("field")}
        dnp = any(p.get("name") == "dnp" for p in c.iter("property"))
        comps.append({"ref": c.get("ref"), "value": c.findtext("value") or "",
                      "footprint": (c.findtext("footprint") or "").strip(), "fields": fields, "dnp": dnp,
                      "path": (sp.get("tstamps") if sp is not None else "/") + (c.findtext("tstamps") or "").strip()})
    pad_nets = {}
    for n in root.iter("net"):
        name = n.get("name")
        if name.startswith(("unconnected-(", "Net-(")):
            head, body = name.split("(", 1)
            name = f"{head}({body.replace('/', '{slash}')}"
        for node in n.iter("node"):
            pad_nets[(node.get("ref"), node.get("pin"))] = name
    return comps, pad_nets


def fp_lib(nick: str) -> str:
    if nick == "SC":
        return str(OUT / "libs" / "SC.pretty")
    return str(KFP / f"{nick}.pretty")


def bbox_mm(f):
    f.BuildCourtyardCaches()
    layer = pcbnew.B_CrtYd if f.IsFlipped() else pcbnew.F_CrtYd
    bb = f.GetCourtyard(layer).BBox()
    if bb.GetWidth() <= 0:
        boxes = [p.GetBoundingBox() for p in f.Pads()]
        if not boxes:
            p = f.GetPosition()
            return (p.x / 1e6 - 0.5, p.y / 1e6 - 0.5, p.x / 1e6 + 0.5, p.y / 1e6 + 0.5)
        return (min(b.GetLeft() for b in boxes) / 1e6 - 0.25, min(b.GetTop() for b in boxes) / 1e6 - 0.25,
                max(b.GetRight() for b in boxes) / 1e6 + 0.25, max(b.GetBottom() for b in boxes) / 1e6 + 0.25)
    return (bb.GetLeft() / 1e6, bb.GetTop() / 1e6, bb.GetRight() / 1e6, bb.GetBottom() / 1e6)


def overlap(a, b, gap=0.1):
    return not (a[2] + gap <= b[0] or b[2] + gap <= a[0] or a[3] + gap <= b[1] or b[3] + gap <= a[1])


def set_rules(board):
    ds = board.GetDesignSettings()
    ds.SetCopperLayerCount(4)
    board.SetCopperLayerCount(4)
    ds.m_TrackMinWidth = mm(0.1)
    ds.m_MinClearance = mm(0.1)
    ds.m_ViasMinSize = mm(0.35)
    ds.m_MinThroughDrill = mm(0.2)
    ds.m_ViasMinAnnularWidth = mm(0.075)
    ds.m_CopperEdgeClearance = mm(0.25)
    ds.m_HoleClearance = mm(0.15)
    ds.m_HoleToHoleMin = mm(0.25)
    ds.SetBoardThickness(mm(1.6))
    board.SetLayerType(pcbnew.In1_Cu, pcbnew.LT_POWER)
    board.SetLayerName(pcbnew.In1_Cu, "In1.Cu")
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

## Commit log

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2026-09-14 docs: re-derive power budget from exact component datasheets
    - ESP32-S3 row from v2.2 Table 5-9 (modem-sleep 240 MHz) with duty cycles
    - GNSS row from MAX-M10S-00B Table 15 (replaces superseded ATGM allowance)
    - ADS-B row from BLB01/ADL5513/MCP6566/RP2040 T637 exact figures
    - FLIGHT 1.935 -> 1.684 W; two-cell 12 h estimate now 12.31 h (O13 arithmetic)
    - 3V3_MAIN worst simultaneous peak ~974 mA documented for O11
2026-09-14 firmware: add RP2040 UART framing contract with overflow/timestamp/concurrency tests
    - COBS-free length-delimited records: SYNC/VERSION/TYPE/SEQ/TS32/LEN/PAYLOAD/CRC16-CCITT
    - 64-bit timestamp reconstruction across 32-bit sample-clock wrap via WRAP records
    - overflow visibility: dedicated OVERFLOW records plus per-record SEQ gap detection
    - decoder resyncs on garbage, discards CRC-failed records, continues the stream
    - contact-before-WRAP and non-monotonic timestamps flagged as protocol violations
    - 17 host tests pass incl. interleaved producers and 200-contact stress burst
    - PIO/DMA implementation and bench tests remain prototype-gated (O12)
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2026-09-17 docs: bound I2C pull-up window and open the rail load inventory
    Gate 9 / O11 named two uncalculated items: the shared-bus pull-up value
    and the complete per-rail loads. Both are worked here to the limit of the
    evidence available without manufacturer-host access.
    I2C_BUS_BUDGET.md fixes the method (rise time, sink capability and
    leakage/VIH bounds), evaluates the admissible Rp window against total bus
    capacitance at the recorded 400 kHz target, and records two results:
    - The BQ25887EVM-001 10 kOhm pull-up is disqualified as a resistance for
    this board. It supports about 35 pF at 400 kHz, far below a nine-device
    bus plus expansion cable. SLUUC12 Table 3 remains valid evidence for the
    3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
2026-09-17 docs: refine I2C budget with subagent findings - BQ25887 5mA sink, BMP581 1uA leakage, TUSB320LAI 100pF@400kHz device cap is the binding limit
2026-09-17 docs: resolve audit findings - sync gate 9/4 wording, obsolete blocker block, unsourced Ci estimate, BOM stack identifier, add P26 bus proposal
    [preliminary_bom.csv]
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2026-09-17 docs: record the readiness-audit loop state for session continuity
    The audit loop ran four rounds and converged, but its state lived only in
    chat: baseline commit, what each round found, what closed it, and which
    blockers are external. A new session had no way to resume it.
    AUDIT_LOG.md carries that state: the current baseline (4c94263), the four
    rounds with their ranges and dispositions, the five active blockers with
    who each waits on, and the vigil procedure to run next time.
    Two corrections are folded in. The vigil's BOM check is given as the
    structured count (7 MPN=TBD, 6 Status=PROPOSED) because a bare
    grep -c 'TBD\|PROPOSED' over the CSV returns 43 — it also counts the 36
    rows whos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
2026-09-17 docs: close three desk-correctable audit findings (round 5)
    Swept all 12 Astra entry gates instead of the commit delta. Three findings
    were correctable from the desk; the rest of what blocks Astra is not.
    1. I2C_BUS_BUDGET closure criterion 2 was unsatisfiable as written. It
    demanded a transcribed figure in every Ci/IOL/Ii cell, but six devices
    publish no Ci at all — a property of those datasheets, not outstanding
    work — so the criterion could never be met and the item could never
    close. Criterion 2 now accepts an explicit "not stated" backed by a
    named review, and criterion 3 carries the real burden: Cb needs a
    declared substitute for each such device, never an assume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
2026-09-19 docs: record vigil round 7, advance audit baseline to 7136c48
    Hourly check found the delta since 0045b29 was only round 6's own
    log-only baseline-pointer commit (7136c48), no engineering content.
    BOM drift check matches expected (7 TBD, 6 PROPOSED; MAIN_PCB still
    JLC04161H-3313). All five blocker rows (O05, O10, P26, O01, O21-O26)
    verified unchanged. No new blind spot against the minimum categories.
    Converges with no action; baseline advances to 7136c48, already
    merged so no two-step needed this round.
    Claude-Session: https://claude.ai/code/session_0119x5U5VJu1jdsxnVXE5dwm
2026-09-19 docs: record vigil round 8, advance audit baseline to 8302843
    Hourly check found PR #5 (round 7's own log-only entry and baseline
    advance) sitting draft, clean and self-verified; promoted and merged
    it. Independently re-ran the BOM drift check and diffed the PR
    content against the round 7 description before merging - both
    matched. Delta since 7136c48 is only that merge, so this vigil
    converges with no new finding, and the baseline moves to 8302843 per
    the two-step rule.
    Claude-Session: https://claude.ai/code/session_01LuuhDogeVW21KLWXfJy7BA
2026-09-19 docs: record vigil round 10, advance audit baseline to d5ce71d
    Delta since d3f5c83 is PR #8 merging (round 9's own log-only entry
    and baseline-pointer advance). No engineering content, no blocker
    row changed. Re-verified BOM drift (7 6, MAIN_PCB unchanged) and
    blocker rows against current main.
    Claude-Session: https://claude.ai/code/session_0125NnefuSTN778ZunepTf3b
2026-09-20 docs: record vigil round 12, advance audit baseline to 5fc3eda (#12)
    Delta since 3e824c5 is PR #10 merging (squash): round 11's own
    log-only entry and baseline-pointer advance. No engineering content,
    no blocker row changed. Re-verified BOM drift (7 6, MAIN_PCB
    unchanged) and blocker rows against current main.
    Claude-Session: https://claude.ai/code/session_01HKKPNBiCX2c54AcB4MVnLe
2026-09-20 docs: record vigil round 13, advance audit baseline to c8dcd76 (#13)
    Hourly readiness-audit vigil (round 13). Delta since baseline 5fc3eda
    is PR #12 merging (round 12's own log-only entry and baseline-pointer
    advance, docs/AUDIT_LOG.md only, 3/-2 lines). No engineering content;
    BOM drift matches expected 7/6, MAIN_PCB unchanged, all five active
    blocker rows (O05, O10, P26, O01, O21-O26) unchanged. Converged — no
    engineering action.
    Claude-Session: https://claude.ai/code/session_01CzXygjHyhLGbDKhaDo18Su
2026-09-20 docs: record vigil round 14, advance audit baseline to 5ef4a0c (#16)
    Round 14 audited the delta since baseline c8dcd76: PR #13 merging
    (round 13's own log-only entry and baseline advance). BOM drift check
    re-run (7 6, MAIN_PCB unchanged); five active blocker rows unchanged;
    no new blind spot against the minimum categories. Converged, no
    engineering action beyond advancing the baseline per the two-step rule.
    Claude-Session: https://claude.ai/code/session_0168T7ehea6ivG1YhLTYwkg9
2026-09-20 docs: record vigil round 15, advance audit baseline to 28c75fe (#17)
    Hourly readiness-audit vigil. Delta since baseline 5ef4a0c is PR #16
    merging (round 14's own log-only entry and baseline-pointer advance),
    no engineering content. BOM drift check matches expected 7/6, MAIN_PCB
    unchanged. All five blocker rows (O05, O10, P26, O01, O21-O26)
    unchanged. No new blind spot found.
    Converged, no engineering action.
    Claude-Session: https://claude.ai/code/session_01QaKAcGu9LpFFJRS1QkhXAu
2026-09-20 docs: record vigil round 16, advance audit baseline to 7fc0eac (#20)
    Round 16 audited the delta since baseline 28c75fe. Three separate
    scheduled vigil sessions had independently produced identical no-op
    round-15 PRs (#17, #18, #19) without checking for already-open
    duplicates. Merged #17 (squash, 7fc0eac) and closed #18/#19 as
    duplicates with an explanatory comment.
    BOM drift check re-run (7 6, MAIN_PCB unchanged); OPEN_QUESTIONS.md
    and DECISIONS.md untouched in the audited delta; five active blocker
    rows unchanged; no new blind spot against the minimum categories.
    Converged, no engineering action beyond consolidating the duplicate
    PRs and advancing the baseline per the two-step rule.
    Cla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
2026-09-20 docs: record vigil round 18, advance audit baseline to ea892ba (#23)
    Round 18: step 0 found no open PRs to consolidate. Delta is PR #22
    merging (round 17's log entry, baseline advance, step-0 guard, and
    reworded read-only line). BOM drift and the five blocker rows
    independently re-verified unchanged. Converged, no engineering action.
    Claude-Session: https://claude.ai/code/session_011qVLR2UVUrJgpEMq4zrWJz
2026-09-20 docs: record vigil round 20, advance audit baseline to e427136 (#27)
    Step 0: listed open PRs, none found, no duplicate to consolidate.
    Delta 2379a29..e427136 is PR #25 merging (round 19's own log-only
    entry and baseline advance), docs-only. BOM drift re-run: matches
    expected 7 TBD / 6 PROPOSED, MAIN_PCB still JLC04161H-3313. All five
    blocker rows (O05, O10, P26, O01, O21-O26) unchanged. No new blind
    spot found against the minimum categories.
    Converged — no engineering action.
    Claude-Session: https://claude.ai/code/session_01BrhW86SDGeG6XuQiSxuVvR
2026-09-20 docs: record vigil round 21, advance audit baseline to fd4abbd (#29)
    Step 0: listed open PRs, found #28 (stale duplicate round-20 PR
    opened before #27 merged); closed it with an explanatory comment.
    Delta e427136..fd4abbd is PR #27 merging (round 20's own log-only
    Converged — no engineering action beyond closing the duplicate PR.
    Claude-Session: https://claude.ai/code/session_01GL58thMvZhNSEiHydbigNG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
2026-09-20 docs: record vigil round 24, advance audit baseline to 2095d7e (#34)
    Delta ae5658d..2095d7e is PR #33 merging (round 23's own log-only
    entry and baseline advance) - docs-only, BOM drift and blocker rows
    unchanged. Converged, no engineering action.
    Claude-Session: https://claude.ai/code/session_01BnQ5g9aw4KsfBi9ByFCbCn
2026-09-20 docs: record vigil round 25, advance audit baseline to 680524e (#35)
    Delta 2095d7e..680524e is PR #34 merging (round 24's own log-only
    entry and baseline-pointer advance). BOM drift re-checked (7 TBD,
    6 PROPOSED; MAIN_PCB still JLC04161H-3313); all five active blocker
    rows (O05, O10, P26, O01, O21-O26) unchanged. Converged, no
    Claude-Session: https://claude.ai/code/session_01HwZuXZKDj11RARyp2gZXn7
    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
2026-09-20 docs: record vigil round 27, advance audit baseline to 3bf4389 (#37)
    Delta bada418..3bf4389 is PR #36 merging (round 26's own log-only
    entry and baseline advance), docs-only. BOM drift and blocker rows
    re-verified unchanged; no new blind spot. Converged, no engineering
    action.
    Claude-Session: https://claude.ai/code/session_01TNW8kQeroN4qc1AfUZ518D
2026-09-20 docs: record vigil round 32, advance audit baseline to 5b0459d (#45)
    PR #44 (a duplicate "Vigil round 31") was closed without merging
    before this round started, so step 0 had nothing to consolidate.
    Delta is PR #43 merging: round 31's own entry and baseline advance
    to aac2fbb, re-verified docs-only. BOM drift and the five blocker
    rows (O05, O10, P26, O01, O21-O26) unchanged for 32 consecutive
    rounds.
    Claude-Session: https://claude.ai/code/session_01F7LUGbQmoFnJTQ2Wk7YRRB
2026-09-20 docs: record vigil round 34, advance audit baseline to 1c4fdb0 (#50)
    Hourly readiness-audit vigil (round 34). Step 0: no open PRs to
    consolidate. Delta is PR #49 merging (1c4fdb0): round 33's own
    log-only entry and the baseline-pointer advance to 49efb09,
    docs-only (3/-2 lines). BOM drift re-check matches expected 7/6,
    MAIN_PCB still JLC04161H-3313. OPEN_QUESTIONS.md/DECISIONS.md
    untouched; all five blocker rows (O05, O10, P26, O01, O21-O26)
    unchanged for 34 consecutive rounds, all owner-only actions.
    Claude-Session: https://claude.ai/code/session_01467i34VUiuoLNXYrrBDMah
2026-09-20 docs: record vigil round 35, advance audit baseline to 7c7ad0b (#52)
    Hourly readiness-audit vigil (round 35). Step 0 found duplicate PR #51
    ("Vigil round 34") racing already-merged PR #50; closed #51 with an
    explanatory comment. Delta 1c4fdb0..7c7ad0b is PR #50 merging: round
    34's own log-only entry and baseline-pointer advance. Docs-only,
    verified via git diff --stat. BOM drift matches expected 7/6,
    MAIN_PCB unchanged. All five blocker rows (O05, O10, P26, O01,
    O21-O26) unchanged for 35 consecutive rounds. No new blind spot.
    Claude-Session: https://claude.ai/code/session_01KjeoR3aMyUugMFMp3MxRkj
2026-09-20 docs: record vigil round 36, advance audit baseline to 664c4c2 (#53)
    Step 0 found no open pull requests to consolidate. Delta 7c7ad0b..664c4c2
    is PR #52 merging round 35's own log-only entry (docs/AUDIT_LOG.md only).
    BOM drift and MAIN_PCB check unchanged; all five blocker rows (O05, O10,
    P26, O01, O21-O26) unchanged for 36 consecutive rounds.
    Claude-Session: https://claude.ai/code/session_01GV5rKf2uwMaeH86A7Ngf5r
2026-09-20 docs: record vigil round 43, advance audit baseline to 5b4782c (#60)
    Round 43 of the read-only readiness-audit vigil. Delta f718393..5b4782c
    is PR #59 merging (round 42's own log-only entry and baseline advance
    to f718393), docs-only. BOM drift re-run matches expected 7/6; MAIN_PCB
    still JLC04161H-3313. All five blocker rows (O05, O10, P26, O01,
    O21-O26) unchanged, now unchanged for 43 consecutive rounds. No new
    blind spot found. Converged.
    Claude-Session: https://claude.ai/code/session_01YaYqBDo27AC4MTjYguGuSi
2026-09-20 docs: record vigil round 44, advance audit baseline to fb7ba2e (#61)
    Round 44 of the read-only readiness-audit vigil (docs/AUDIT_LOG.md).
    Step 0: listed open pull requests before starting - none open, no
    duplicate to consolidate. Audited delta 5b4782c..fb7ba2e: PR #60
    merging round 43's own log-only entry and baseline-pointer advance to
    5b4782c, docs/AUDIT_LOG.md only. BOM drift re-run: matches expected
    7 6; MAIN_PCB still JLC04161H-3313. OPEN_QUESTIONS.md/DECISIONS.md
    untouched in the audited delta - all five blocker rows unchanged
    (O05, O10, P26, O01, O21-O26), now unchanged for 44 consecutive
    rounds. No new blind spot found. Converged - no engineering action
    beyond advancing the baseline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
2026-09-20 docs: record vigil round 45, advance audit baseline to 9066727 (#62)
    Read-only audit of fb7ba2e..9066727 (PR #61, round 44's own log-only
    entry). BOM drift matches expected 7/6, MAIN_PCB unchanged, all five
    blocker rows (O05, O10, P26, O01, O21-O26) unchanged for 45 consecutive
    rounds. Converged, no engineering action.
    Claude-Session: https://claude.ai/code/session_01UpdB3izLxGoywdD6Tq6RLV
2026-09-20 docs: record vigil round 46, advance audit baseline to 681f66f (#63)
    Read-only audit of 9066727..681f66f (PR #62, round 45's own log-only
    blocker rows (O05, O10, P26, O01, O21-O26) unchanged for 46 consecutive
    Claude-Session: https://claude.ai/code/session_01GhNLERFfTyvVjKzBqPVQNS
    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
2026-09-20 docs: record vigil round 47, advance audit baseline to 3643e40 (#64)
    Read-only audit of 681f66f..3643e40 (PR #63, round 46's own log-only
    blocker rows (O05, O10, P26, O01, O21-O26) unchanged for 47 consecutive
    Claude-Session: https://claude.ai/code/session_01VVmGSkkWJ7mKKM3gexH3zG
    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
2026-09-20 docs: record vigil round 49, advance audit baseline to bdefadb (#66)
    - Vigil round 49: audited delta 9d9db1d..bdefadb (PR #65 merging - round
    48's own log-only entry and baseline-pointer advance to 9d9db1d).
    - Docs-only, docs/AUDIT_LOG.md only, 3/-2 lines.
    - BOM drift check re-run against current main: matches expected 7 6,
    MAIN_PCB still JLC04161H-3313.
    - OPEN_QUESTIONS.md/DECISIONS.md untouched in the audited delta - all
    five blocker rows unchanged (O05, O10, P26, O01, O21-O26), now
    unchanged for 49 consecutive rounds.
    - No new blind spot found against the minimum categories.
    - Verdict: Converged - no engineering action beyond advancing the
    baseline pointer per the two-step rule.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
2026-09-20 docs: record vigil round 51, advance audit baseline to 248e66e (#68)
    Round 51 of the read-only readiness-audit loop. Step 0: no open
    "Vigil round" PRs found. Delta ddbf505..248e66e is PR #67 merging
    (round 50's own log-only entry and baseline advance to ddbf505),
    docs-only, matching git diff ddbf505..248e66e --stat. BOM drift
    re-run: 7 6 (expected). MAIN_PCB still JLC04161H-3313.
    OPEN_QUESTIONS.md/DECISIONS.md untouched; all five blocker rows
    (O05, O10, P26, O01, O21-O26) unchanged for 51 consecutive rounds.
    Verdict: Converged — no engineering action beyond advancing the
    baseline per the two-step rule.
    Claude-Session: https://claude.ai/code/session_01Ng13Jkg2ZPXLMFUvsSX18m
    Co-authored-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
2026-09-20 docs: record vigil round 52, advance audit baseline to 7e104ee (#69)
    Step 0: listed open pull requests - none open, no duplicate to consolidate.
    Audited delta 248e66e..7e104ee: PR #68 merging (round 51's own log-only
    entry and baseline-pointer advance to 248e66e), docs-only, matching
    `git diff 248e66e..7e104ee --stat`.
    BOM drift check re-run against current main: matches expected `7 6`;
    OPEN_QUESTIONS.md/DECISIONS.md untouched in the audited delta - all five
    blocker rows unchanged (O05, O10, P26, O01, O21-O26), now unchanged for
    52 consecutive rounds; all remain owner-only actions with no
    agent-executable next step.
    No new blind spot found against the minimum c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
2026-09-20 docs: record vigil round 53, advance audit baseline to f272ae9 (#70)
    Step 0: listed open pull requests - none open, no duplicate to
    consolidate.
    Audited delta 7e104ee..f272ae9: PR #69 merging (round 52's own
    log-only entry and baseline-pointer advance to 7e104ee), docs-only,
    matching `git diff 7e104ee..f272ae9 --stat`.
    53 consecutive rounds; all remain owner-only actions with no
    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
2026-09-22 integrator: close the PWR-02/DIG-02/DIG-03 status/decisions/BOM gap
    Several draft integrator PRs (#148, #150, #151, #153, #155, #156) opened
    by earlier sessions attempted this same reconciliation against stale
    bases and were never merged, so PWR-02 (#147), DIG-03 (#149 + polarity
    fix #152) and DIG-02 (#154) were only ever reflected in the workboard,
    never in PROJECT_STATUS/OPEN_QUESTIONS/DECISIONS/BOM. This closes that
    gap directly against the current main, restating only already-merged
    evidence:
    PROJECT_STATUS: gate 4 records the DIG-01/DIG-02/DIG-03 closures.
    OPEN_QUESTIONS: O11 notes DIG-03's pull-down/active-high-EN default;
    O20 notes the DIG-01/DIG-02 closures and drops the now-stale R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
    [preliminary_bom.csv]
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2026-09-23 candidates: Claude one-shot Rev A schematic, routed PCB and 3D for Astra comparison
    Owner-requested out-of-baseline candidate in candidates/claude-oneshot-revA/:
    12-sheet KiCad 10 schematic generated netlist-first from the repo docs and
    datasheet pin tables (unverified values kept TBD), 4-layer 60 x 84 mm board
    (Freerouting + A* clean-up router, GND stitching), display/2S-cell/enclosure
    3D models and a full assembly STEP. ERC 1 reviewed error, DRC 1 reviewed
    error, schematic parity 0, 11 connections left for manual finish.
    The issue list records baseline defects for independent review: MMC5983MA
    and BMP581 pad centres, TXU0202 and TPS259474L package mismatches,
    BM12B-GHS-TBT orientation and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
    [01_usb_input.kicad_sch, 02_battery_charger.kicad_sch, 03_rails.kicad_sch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]
2026-09-23 docs: show one-shot candidate renders and schematic in README, fix 3D models
    Root README gains a status table for the Claude one-shot candidate, 3D and
    enclosure renders, PCB copper view, all 12 schematic sheets as images and
    step-by-step instructions (folders) to open the KiCad project or the STEP
    files. Candidate README gets the same gallery and KiCad instructions.
    3D: envelope STEP models for parts whose footprint had no model in the
    KiCad 10.0.6 install (MAX-M10S, ICM-42688-P, MMC5983MA, BMP581, TPD1E0B04,
    TPS259474L RPW, TUSB320LAI, Coilcraft inductors, SHT40), so the board STEP
    and the Alt+3 view are complete. Routing unchanged; DRC 1 reviewed error,
    11 unconnected, parity 0.
    Co-Auth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
    [03_rails.kicad_sch, 05_display.kicad_sch, 06_sensors.kicad_sch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]
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2026-09-23 fix: correct sensor and DCU lands against manufacturer drawings
    [preliminary_bom.csv]
2026-09-23 candidates: evidence-backed refinement of the Claude one-shot KiCad candidate
    Reviewed on origin/main e1f75a3 with KiCad 10.0.6; changes stay inside
    candidates/claude-oneshot-revA/ and close no project gate.
    - TXU0202 U24: exact TI DCU0008A land (SCES942A pp.32-34) replaces the
    generic KiCad DCU footprint; schematic/symbol footprint fields updated.
    - TPS259474L U3 RPW: copper verified against the TI 4225183/A vectors;
    paste now follows the TI stencil example, fab body 2.0 mm.
    - ICM-42688-P pin 9 tied to GND (TDK DS-000347 v1.9 Table 10).
    - U1/J5 body-courtyard overlap fixed, duplicate vias removed, BMP581
    under-body SCL route removed, SHT40 SDA and 3V3 fragments connected,
    three GND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
    [06_sensors.kicad_sch, 10_storage_audio.kicad_sch, StratosCore_Claude.kicad_pcb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]
2026-09-24 candidates: close floating grounds, swap TPS62130A to RGT0016C, add review notes
    Integrates the parallel review work on the Claude one-shot candidate
    (candidates/ only; no baseline, locked decision or gate changed):
    - GND of U2 (USB ESD), U3 pad 8 (eFuse) and U24 pad 2 connected by local
    re-layout; U7 exposed pad now has 4 vias; GND is one copper group.
    - U7 swapped to the TI RGT0016C land (SLVSAG7F p.41) and schematic field
    updated; J1 +0.3 mm move tried and reverted (collides in USB corner).
    - Review notes: ESP32/USB-C/buttons audit (all 41 module pads verified),
    TPS62130A footprint, SX1262 E449 native values (topology redraw needed),
    GPIO A5-A8 options (owner decision), assembler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
    [03_rails.kicad_sch, StratosCore_Claude.kicad_pcb, bom_candidate.csv]
2026-09-24 candidate: stitch floating GND pads U2/U3/U24 to In1 plane
    - U24.2 (TXU0202): 0.2mm track staircase + 0.45/0.2 via into In1 plane
    - U2.3 (TPD4E05U06): direct 0.127mm track + 0.35/0.2 via (0.330mm d_min)
    - U3.8 (TPS259474L): 0.127mm staircase via 0.35/0.2 landing on In1
    - In2.In1 landing verified by PointInside on anchored GND fill outline
    - via clearances: 0.15 full-class / 0.127 JLC-class with geometric proof
    DRC after (KiCad 10.0.6): unconnected 5 -> 2 (only intended LORA_RFO/RFI_P
    TBD stubs), 0 new clearance/short/hole-to-hole items, schematic parity 0.
    Remaining violations pre-exist: 199 solder_mask_bridge (assembler gate),
    117 silk (cosmetic), 1 track_dangling (LoRa TBD).
    [StratosCore_Claude.kicad_pcb]
2026-09-24 candidate: merge artifact removed — clean GND stitch board + U7 RGT0016C
    Replaces the text-merge artifact (4 shorts / 10 clearances from mixing two
    copper generations) with the verified board: v19 GND stitches (U2 via
    0.35/0.2, U24 via 0.45/0.2, U3 staircase+via) + U7 footprint block swapped
    to RGT0016C (SLVSAG7F p.41) via s-expression surgery, no copper merge.
    DRC (KiCad 10.0.6): unconnected 2 (LORA_RFO/RFI_P TBD only), 0 shorts,
    0 hole violations, parity 0. Residual: 10 clearance items at U3 east
    rail-stair chords + TP1 island (cause analyzed; fix queued: orthogonal
    re-route with 0.55mm TP1 keepout, goal via 0.4/0.2).
    [StratosCore_Claude.kicad_pcb]
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
